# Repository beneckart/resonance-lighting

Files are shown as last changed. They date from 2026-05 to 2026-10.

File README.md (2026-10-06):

# Resonance Lighting

Power and lighting workstream for the **Resonance Tree** -- a bamboo art installation for Burning Man 2026 + 2027. This repo covers the roughly 130 solar/battery-powered, mesh-networked lighting fixtures in and around the tree -- four classes: hanging downlights, perimeter lights, trunk lights, and the central chandelier (canonical counts: the fleet table in `docs/block-diagram/SYSTEM.md`; current allocation: ADR 0032).

Sister tracks (not in this repo): bamboo structure (Bamboo Pure, Bali), structural engineering (Ed), parametric lighting design (Vishnu), project management (Elliot + Co-Work agent).

## Post-event storage and 2027 planning

Start with the [2026 postmortem and future-work index](docs/postmortem/README.md)
for the container-storage outcome, Oakland inventory, PROTECT investigation and
2027 hardware/tooling brainstorming. The
[storage and wake guide](docs/howto/FIXTURE_STORAGE_AND_WAKE.md) documents the
implemented USB/solar-wake ship mode, RESET-wake sleep, date picker and exact
retained firmware. These records supersede pre-event status where noted; the
2027 concepts remain discussion drafts.

## Who's working here

- **Ben Eckart** -- power systems, firmware, mesh networking. Owns `/firmware/` and `/hardware/`.
- **Steve Eckart** -- enclosure design, 3D printing, mechanical fit. Owns `/enclosure/`.

Both work with AI pair-programmers. Coordinate via `LOG.md`, `TODO.md`, and ADRs.
Firmware builders additionally use
[`docs/howto/FIRMWARE_ARTIFACT_HANDOFF.md`](docs/howto/FIRMWARE_ARTIFACT_HANDOFF.md)
so separate benches do not reuse revisions or silently flash each other's targets.

## What is the deliverable

Nominally 130 modular lighting fixtures in four classes -- 72 hanging downlights
in three rings of 24, 24 all-HEX perimeter lights on shepherd hooks, about 16 trunk
lights trending RGBW, and 18 mixed HEX/RGBW chandelier lights. The team intends to
build this full layout; fewer fixtures are a contingency for an unforeseen issue.
The archetype (hanging downlight) is:

- A bamboo lantern body, fabricated by Bamboo Pure in Bali.
- A solar "hat" enclosure that sits partially inside, partially over the bamboo top.
- A solar panel, rechargeable battery, controller board, LED module, sensors
  (accelerometer + downward ToF), and a 3D-printed patterned aperture / gobo.
- Firmware that supports autonomous ambient lighting, ESP-NOW state exchange, standard OTA maintenance updates, telemetry, and graceful low-power behavior.

The other classes are variants on the same electronics: perimeter lights use HEX and
face the ToF outward; trunk lights drop the gobo and are moving toward all RGBW while
a smaller lensed 3 W RGB module is tested for extra throw; chandelier lights live in
a carpenter-built box, likely on 6 Ah cells with USB-C top-ups. All share one firmware
image.

Steve's NeoHex Magic Wand is a separate one-off fleet peer, not a fifth
production class. Its PowerFeather identity is permanently `F40344` /
`68:EE:8F:F4:03:44`, its registry role is `magic_wand`, and batch OTA tooling
requires a dedicated single-target acknowledgement before it will touch that
MAC (ADR 0050). See `docs/projects/NeoHex-Magic-Wand/README.md`.

## Current architecture direction

**PowerFeather V2 (ESP32-S3) is the confirmed reference** for the controller / solar-and-battery manager / telemetry, after 5-board feasibility testing (ADR 0021): ESP-NOW mesh at scale, battery-only no-touch OTA + A/B rollback, and the solar charge path are all validated on hardware. Chemistry is **LiFePO4** (ADR 0002); batteries are two-tier since 2026-07-24 (ADR 0025): 33140 15 Ah in the large hats (downlights; qualification pending) and the fullbattery 32700 6 Ah, qualified n=2, in the small hats.

**The production path is decided: COTS PowerFeather V2, with a nominal 130-fixture
deployment (ADRs 0024 and 0032).**
158 boards are bought (68 received + 90 ordered 2026-07-09; ledger: `ops/PROCUREMENT.md`).
The custom PowerFeather-derived PCBA (ESP32-S3-WROOM module, BQ25628E-class charger,
MAX17260-class gauge, buck-boost 3.3 V rail, switchable rails, keyed connectors) is
the 2027 option, carrying the ADR 0028 bus-integrity rules.

The **LED axis is a mixed fleet by optical role** (ADR 0022): SK6812 "HEX"
direct-GPIO for close-range animation / ambient glow, and a 4 W RGBW point source for
long-throw crisp gobo projection. Both are driven **direct-GPIO off a free pin**, both
fed from the switchable 3V3 rail -- decided by instrumented A/B through
production-realistic cabling (ADR 0029 + 2026-07-11 amendment); the 4.2 V boost is
measured and shelved. The type mix by class is in the
SYSTEM.md fleet table (tentative until installation). The earlier Adafruit
IS31FL3741 13x9 STEMMA-QT matrix was **ruled out** (ADR 0018) -- it browns out the
board on battery under WiFi (shared charger/gauge I2C bus). The earlier COTS bake-off
candidates (FeatherS2 Neo, Atom Matrix, NeoHEX, DFR0559) served their purpose;
PowerFeather V2 won.

**Sensors and class identity** (ADRs 0027, 0034, 0041, 0067): every downlight
carries an MSA311 accelerometer + downward TMF8820-mini multizone ToF; perimeter
lights carry an outward VL53L5CX; trunk/uplights normally carry only MSA311;
chandelier lights carry no class sensors. Auto-classification is ordered ToF then
MSA311 at `0x62`, with a sensorless uplight fallback for the already-installed
2026 fleet. Remembered downlight/perimeter classes survive a missing ToF. Future
chandelier PowerFeathers are rostered by exact MAC and persist `class_ovr=4`
before installation. BMP581 is non-classifying environmental telemetry on the
outer 24 downlights. Fused IMUs were rejected (per-device calibration does not
scale to the fleet). The **noisemaker**
is decided (ADR 0030/0071): a solenoid mallet physically strikes an installed
finger cymbal on each canopy bamboo assembly -- daytime
solar-surplus percussion; the speaker-synth path was abandoned once the strikes
proved out.

**Production show timing is scheduled** (ADR 0031): four purchased SAM-M8Q modules
are the initial GPS/GNSS soft anchors for absolute UTC, and four purchased Adafruit
DS3231 modules are the initial battery-backed RTC holdover anchors. ESP-NOW distributes
time quality to the rest of the fleet, so all roughly 130 fixtures do not need RTCs.
Panel/lux dusk inference remains useful bench telemetry but is not the production show
clock.

**Performance audio has a dedicated optional publisher** (ADR 0035): a received
PUCA DSP Original Edition in its Eurorack expansion, paired with a RODE VideoMic
NTG, will analyze one clean audio source and publish directed show frames over
ESP-NOW. The already-proven CoreS3 + Module Audio path remains the independent
fallback. PUCA hardware is on hand; its development firmware now passes the
powered-Pod20 codec/stereo/control/radio/full-census baseline with locked
standalone HEARTBEAT startup. The performer's exact waveform, visible fixture
fidelity/fallback, and field validation remain pending. See
`hardware/puca-audio-bridge/README.md`.

**The camp network is pinned to the mesh channel** (ADR 0036). The ESP32-S3 has
one 2.4 GHz radio, so WiFi STA and ESP-NOW must share a channel, and in STA mode
the access point picks it. Every bridge so far dodges this by staying
unassociated; any device that wants the mesh and the internet at once cannot.
The camp AP (Starlink in bypass mode -> GL.iNet Beryl AX) therefore serves a
dedicated 2.4 GHz SSID fixed to channel 11, and any device that associates while
using ESP-NOW must verify the channel and drop WiFi rather than lose the mesh.
Router ordered, not yet configured; runbook in `docs/howto/CAMP_NETWORK_SETUP.md`.
Fixture maintenance images may carry two gitignored site credential profiles
and select the strongest visible known AP (ADR 0066). Ordinary fixture COMMS
never associates with either network, and no credential value enters git.
The first simultaneous mesh-plus-internet consumer is now **Resonance Bridge OS**
on the LilyGO T-Deck Plus. Hardware is on hand and M0-M4 plus the first M5 apps
are implemented and hardware-verified (ADRs 0047 and 0048). The channel guard
and WiFi/mesh coexistence passed on the house channel-11 network; Beryl field
configuration and validation remain open. The current app order is in
`firmware/tdeck_bridge/APP_ROADMAP.md`; CA Studio remains Greenberg-Hastings,
while the separate Contagion app owns Color Virus and Epidemic (ADR 0055).

The old custom-board target of ESP32-C3-MINI-1 + CN3058 + AP2112K + direct-from-battery WS2812B has been superseded by later ADRs.

## Goals

- **Fungible:** any unit replaces any other with no per-device configuration.
- **Fully wireless:** no data lines, no power lines, no fixed topology. ESP-NOW is for lightweight state/control packets, not firmware-image transfer.
- **Standard OTA only:** OTA updates use normal ESP32 OTA mechanisms in a deliberate maintenance mode. No custom mesh-gossiped firmware images.
- **Durable infrastructure:** fixtures are reused in 2026 and 2027.
- **Low per-fixture operations:** no skilled repetitive work at fleet scale. Small, deliberate soldering such as a solar pigtail can be acceptable; hand-soldering rows of headers or hand-crimping harnesses is not.
- **Telemetry:** power, solar, battery, temperature, and failure data should inform BM 2027 design decisions.
- **Beautiful:** default center-source gobo projection plus optional multi-LED chromatic/animation modes.

## Repo layout

```
.
|-- README.md
|-- LOG.md
|-- TODO.md
|-- BACKGROUND.md
|-- ROADMAP.md
|-- AGENTS.md
|-- hardware/
|   |-- atopile/
|   |-- led-adapter/       NeoHEX passive adapter Rev A (KiCad + PCBWay packet)
|   |-- puca-audio-bridge/ Received performance-audio source + bring-up record
|   `-- references/
|-- enclosure/             README only so far; CAD lives with Steve
|-- firmware/
|   |-- ARCHITECTURE.md    target production architecture
|   |-- README.md          index of the working bench sketches
|   |-- POWERFEATHER_NOTES.md
|   |-- powerfeather_solar_guard.h
|   `-- <app>/             bench sketches (net_bench, power_bench, led_studio, ...)
|-- docs/
|   |-- block-diagram/     SYSTEM.md -- canonical architecture + fleet table
|   |-- decisions/         ADRs 0001-0040
|   |-- howto/             task-oriented bench and operations guides
|   |-- research/
|   `-- tests/
`-- ops/
    |-- bom.md             fleet BOM + spares math
    |-- PROCUREMENT.md     orders ledger + timeline
    `-- bench/             bench tooling + JSONL data
```

## Read order for agents and humans

1. `README.md`
2. `LOG.md`
3. `TODO.md`
4. `BACKGROUND.md`
5. `docs/decisions/` -- especially ADRs 0010 onward
6. `docs/research/COTS_SURVEY_2026-05-10.md`
7. `docs/research/POWERFEATHER_V1_V2_SCHEMATIC_NOTES_2026-05-10.md`
8. `docs/tests/COTS_BENCH_TEST_PLAN_2026-05-10.md`

## How-to guides

- [`docs/howto/BRIDGE_OS_FIELD_MANUAL.md`](docs/howto/BRIDGE_OS_FIELD_MANUAL.md) --
  friendly illustrated field/IT manual for T-Deck Bridge OS, the CoreS3
  dashboard and audio modes, and the still-pending PUCA performance bridge.
- [`docs/howto/FIRMWARE_ARTIFACT_HANDOFF.md`](docs/howto/FIRMWARE_ARTIFACT_HANDOFF.md) --
  collision-proof firmware revision/manifest rules, explicit target handoff,
  fresh-evidence OTA completion, and USB boot-salute semantics for shared benches.
- [`docs/howto/CORES3_AUDIO_REACTIVE.md`](docs/howto/CORES3_AUDIO_REACTIVE.md) --
  connect and tune the Rode VideoMic NTG, read the CoreS3 envelope/FFT
  spectrogram and band modes, run the sound-reactive bench, and troubleshoot the
  safe fallback path.
- [`docs/howto/CAMP_NETWORK_SETUP.md`](docs/howto/CAMP_NETWORK_SETUP.md) --
  stand up Starlink + the Beryl AX travel router with the 2.4 GHz radio pinned to
  channel 11 so infrastructure WiFi and the ESP-NOW fleet can coexist on one
  radio. Home rehearsal, field checklist, and troubleshooting (ADR 0036).
## Fleet dashboard

CoreS3 Bridge OS now has a standalone touch Listener with a paged fleet-health
grid and fixture detail, so basic observation no longer needs a laptop. For the
complete host dashboard and telemetry logger, attach the same CoreS3 over USB.
The only Python dependency is `pyserial`; list the attached ports, then replace
`COM40` with the observed bridge port:

```sh
python -m pip install pyserial
python -m serial.tools.list_ports
python ops/bench/net_bench_dashboard.py --port COM40
```

The landing view is a compact grid of every ESP-NOW light. Battery fill and color,
charger-input activity, class-inferred source glyph, panel-suspect state, adaptive heartbeat freshness, and the
actual reported light output are readable without opening a table. The top bar is
the rendered LED color, independent from battery status. Callsigns from
`ops/fleet/callsigns.csv` lead in selected/detail and peer-list surfaces while
the exact short MAC remains visible and authoritative for state-changing work.
Reported fixture class
(normally from the Stemma probe, with an override available) sets the battery
glyph shape: circle for canopy/downlight, hexagon for
perimeter, triangle for trunk/uplight, and diamond for chandelier. Dense overview
tiles still use two MAC digits unless a collision needs `-1`, `-2`, and so on;
full callsigns would crowd that view. Select any light for exact
values; bench controls and the full historical telemetry console are preserved in
the collapsed `Detailed diagnostics` section. With `All` selected, `Strike all`
queues one addressed D7 pulse per fresh fixture after confirmation; disarmed boards
ignore it and the fixture's local power/mechanism gates remain authoritative. See
[`firmware/cores3_bridge/README.md`](firmware/cores3_bridge/README.md) for the
glyph contract and source-classification caveat.

Resonance Bridge OS embeds the same table in its Fleet and Health apps. Its
Claude tool surface accepts a callsign or six-hex short ID, resolves locally to
the MAC-derived target, and returns both in tool results. Fixture firmware and
the ESP-NOW packet contract do not carry callsigns.

For an explicit multi-fixture OTA, `ops/bench/fleet_dashboard_ota.py` accepts a
comma-separated short-MAC target list plus one already-built immutable binary.
It loads a job-scoped T-Deck roster, spans one selected sleep cadence, discovers
and identity-checks maintenance endpoints, positively freezes all gather traffic,
uploads in bounded parallel jobs, and requires fresh exact-revision evidence
beyond the A/B pending-verify gate. One exclusive-created ledger records every
target as verified, deferred, or failed. `--allow-partial-discovery` permits a
named sleeper cohort to proceed without missing targets; it never permits unnamed
discovery results or unsafe low-VBAT targets. See ADR 0062 and
`docs/howto/FLEET_OTA_10_MINUTE_RUNBOOK.md`.

## Status

As of 2026-08-06: **production is locked on COTS PowerFeather V2 with a current
130-fixture Nevada City layout in four classes (ADRs 0024 and 0032), and the buy is
essentially complete** -- boards, two battery
tiers, panels, LEDs, sensors, cabling, USB-C rescue ports, solarnoid hardware, and 172
Polycase enclosures are ordered or received (about $25.2k committed; ledger in
`ops/PROCUREMENT.md`). The qualified 32700 6 Ah cell remains the small-hat/chandelier
battery while 130 newly bought 33140 15 Ah cells are pending qualification for large
hats (ADR 0025). Panels are selected and outdoor-measured (ADR 0026); sensors are
allocated by class (ADR 0027); both LED roles are on the switchable 3V3 rail after
instrumented A/B (ADR 0029); the solarnoid is the selected noisemaker for large-hat
downlights (ADR 0030); and deterministic scheduled shows from sparse GPS/RTC anchors
are the production timing direction (ADR 0031).

Remaining gates during Nevada City assembly: the bottom-up nightly energy budget by
role, 33140 qualification and thresholds, trunk-light LED/power/mounting integration
(including the lensed 3 W RGB trial), hat thermal/RF proof on the Polycase boxes, the ADR 0023 state
machine in production firmware, solarnoid part/mounting details, and qualification of
the four SAM-M8Q GPS plus four DS3231 RTC timing anchors including invalid-time
behavior. Treat LFP SOC as advisory until the gauge learns; use coulomb counting and
voltage/current guardrails. See `LOG.md` and `TODO.md` for the live state.

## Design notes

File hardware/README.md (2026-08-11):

# Hardware

Electronics for the Resonance Lighting downlight fixture. Current strategy is
**PowerFeather V2 first, COTS deployable, custom-PCBA optional**, not custom-PCBA-only.

## Current Hardware Tracks

### Track A - COTS Production / Fallback

Use off-the-shelf boards, factory-soldered connector options, pre-crimped cables, screws,
standoffs, and adapter boards to validate and possibly deploy the system without waiting
on a custom PCB.

Current leading stack:

```
Solar panel -> PowerFeather V2 VDC
LiFePO4 cell -> PowerFeather battery JST
PowerFeather GPIO10/A0 -> direct-GPIO LED module
PowerFeather switchable rail / adapter -> LED power
```

Live LED modules, per ADR 0022:

- **SK6812 HEX array:** close-range animation / ambient glow role.
- **4 W RGBW point source:** long-throw crisp gobo role.

Ruled out for the V2 battery build:

- **Adafruit IS31FL3741 13x9 matrix on STEMMA-QT:** shared-bus brownout under WiFi
  (ADR 0018). Keep it only as historical bench context unless a future isolated-bus
  experiment explicitly revives it.

Small adapter-board workstream:

```
PowerFeather GPIO + switchable/boosted LED rail
        |
        v
NeoHEX passive / future boosted adapter PCB
        |
        v
HEX / NeoHEX / RGBW LED module connector
```

See `hardware/led-adapter/neohex-passive-rev-a/`.

### Track B - Custom PCBA / Assembly Optimization

If COTS supply, connector labor, cost, or packaging does not pencil out at 100+ units,
derive a custom board or custom assembly from the validated PowerFeather V2 architecture.

Current reference architecture:

```
[Solar panel / VDC connector]
        |
[Input protection + bright-sun qualification guard]
        |
[BQ25628E-class charger + power path]
        |
[LiFePO4 cell + thermistor]
        |
[MAX17260-class fuel gauge / current sense]
        |
[TPS631013-class 3.3 V buck-boost]
        |
[ESP32-S3-WROOM-class module, PCB antenna]
        |
[Switchable/default-off LED rail]
        |
[Direct-GPIO LED module connector(s)]
```

## Superseded Earlier Target

The older target architecture was:

```
CN3058 charger -> AP2112K LDO -> ESP32-C3-MINI-1 -> WS2812B direct from Vbat
```

That approach is superseded by later ADRs and the PowerFeather V2 findings. CN3058 remains
historical/fallback context only; it is not the leading production direction.

## Why PowerFeather V2 Matters

PowerFeather V2 combines several features the project otherwise would have to design and
validate separately:

- ESP32-S3-WROOM-1 module with onboard PCB antenna.
- BQ25628E charger/power-path with LiFePO4 support.
- MAX17260 fuel gauge with LiFePO4 profile support and current sensing.
- TPS631013 buck-boost 3.3 V regulator.
- Switchable `3V3` header rail and `VSQT` rail.
- Solar/DC input.
- Power telemetry useful for BM 2026 -> BM 2027 learning.

ADR 0021 validates the risky axes: ESP-NOW scale/range, battery-only OTA + rollback, and
the solar charge path. The remaining hardware work is sizing, productionization, thermal,
RF-in-hat, and connector/assembly choices.

## Interfaces

### Direct-GPIO LED

- Current production-facing LED interface.
- Bench default: GPIO10 / A0.
- Requires a switchable/default-off LED rail and local decoupling.
- Supports HEX and RGBW point-source roles with one firmware abstraction.

### STEMMA-QT / Qwiic

- 4-pin JST-SH connector carrying I2C: GND, V+, SDA, SCL.
- Useful for env sensors, ToF, IMU, INA monitors, and other low-power peripherals.
- Do not put the IS31FL3741 matrix back on the PowerFeather V2 shared charger/gauge bus.

### Grove / HY2.0

- Physical connector used by M5Stack modules.
- Can carry I2C, UART, GPIO, analog, or custom signals depending on the device.
- M5Stack NeoHEX uses HY2.0 physically but is a WS2812/GPIO LED device, not I2C.

### USB / Pogo Recovery

USB-C is available on COTS PowerFeather. Any custom board or assembly must preserve a
boring wired recovery path via USB or pogo pads even though OTA is validated.

## Custom PCB Constraints

If a custom board proceeds (2027 option -- ADR 0024):

- Use a pre-certified WROOM-class module with onboard PCB antenna by default.
- Do not use u.FL/external antenna unless final hat RF testing fails.
- **Dedicated power-management I2C bus** for charger + gauge only, run at 100 kHz;
  user peripherals on a separate bus. No power-management I2C from core-0-pinned
  tasks under WiFi. This rule closed the two-month reboot epidemic (ADR 0028).
- **Any VBAT-fed LED branch taps downstream of the gauge current-sense shunt**, with
  fat conductors and a default-off kill (the 3V3-rail shutoff no longer covers it);
  HEX rides the switchable 3V3 rail; the RGBW feed decision (rail vs VBAT) is open
  in ADR 0029.
- Include USB/pogo flashing/recovery pads regardless of factory flashing.
- Use a switchable/default-off LED/module rail.
- Include charger/fuel-gauge telemetry.
- Include battery thermistor or another explicit temperature strategy.
- Add keyed solar and battery connectors or production-safe pigtails.
- Avoid direct unstrained panel wires soldered to production board pads.
- Keep LED module/daughterboard separate until optics and placement are frozen.
- Use 4-layer PCB and external schematic/layout review for switching charger,
  buck-boost, current sensing, and RF keep-out.

## Immediate Hardware Tests

Top priorities (updated 2026-08-06):

- [x] Voltaic P105/P126 harvest tests with the OVP/HIZ guard (2026-06-29, ADR 0026;
  hungrier-cell P105 re-run still queued).
- [x] HEX 4.2 V boost test -- concluded SKIP; the production-cabling A/B selected
  the switchable 3V3 rail for RGBW (ADR 0029 amendment).
- Close bottom-up power budget by LED role.
- Compare the 4 W RGBW and lensed 3 W RGB trunk-light variants, then lock the
  about-16-fixture power, optic, and mounting path (ADR 0032).
- RF test inside a mock hat with panel/battery/wiring installed.
- Thermal test sealed hat in sun/heat with charger and LEDs operating.
- Time-trial a production-like COTS assembly with keyed connectors and strain relief.
- Integrate the already-selected USB-C panel-mount port + gasket for every class,
  plus the ToF aperture (downward on downlights, outward window on perimeter hats).

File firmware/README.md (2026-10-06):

# Firmware

ESP32 firmware for the Resonance fixtures and controllers. The deployed peer
firmware is [fixture](fixture/README.md); [tdeck_bridge](tdeck_bridge/README.md)
is the handheld controller. `net_bench` remains a bench/bridge tool. The older
layered target in `ARCHITECTURE.md` is historical context; see the fixture
README for the implemented architecture.

The [storage and wake guide](../docs/howto/FIXTURE_STORAGE_AND_WAKE.md) documents
the September 12 USB/solar-wake storage firmware, exact retained fixture and
T-Deck artifacts, rollout evidence and remaining qualification. Post-event
analysis and 2027 ideas are indexed [here](../docs/postmortem/README.md).

> **Building a new app on the PowerFeather V2 bench boards?** Read
> [`POWERFEATHER_NOTES.md`](POWERFEATHER_NOTES.md) first -- the switchable 3V3 rail
> (GPIO4), the V2 SDK board flag, native-USB reset/IP recovery, and other gotchas
> that have each cost real bench time. Working sketches: `power_bench/`,
> `led_studio/` (merged HEX + RGBW + RGB aesthetic tool),
> `net_bench/` (ESP-NOW networking feasibility bench), `smoke_test/`,
> `cores3_bridge/` (dedicated M5Stack CoreS3 fleet bridge),
> `atom_clicker/` (one-target reduced-access proof), `atom_conductor/` (Ben-only
> bounded Wake/gather plus centrally replayed canopy waves),
> `magic_wand_conductor/` (Steve's two-sensor lift-controlled fleet conductor),
> `powerfeather_demo_port/`, `presence_bench/` (I2C multi-sensor bench),
> `sway_demo/` (MSA311 tilt/sway -> RGBW color, with a web verifier),
> `speaker_demo/` (STEMMA speaker #3885 percussion synth, noisemaker candidate A).

Solar/charging baseline: any Resonance sketch that enables PowerFeather charging must
use `powerfeather_solar_guard.h` to force the BQ25628E wide input-OVP bit and to kick
input re-qualification if the panel is present but the charger is latched not-good.

Performance-audio note: the received PUCA DSP/Eurorack hardware is documented in
`../hardware/puca-audio-bridge/README.md` and selected by ADR 0035.
`puca_bridge/` now contains a native-tested development target whose powered-
Pod20 codec/stereo/control/radio/full-census baseline has run on the received
hardware. Exact waveform/light fidelity, receiver fallback, and field geometry
remain acceptance-gated. The proven CoreS3 audio-reactive implementation is
still the field fallback, not a PUCA-compatible binary.

## Planned production structure (NOT yet built -- see ARCHITECTURE.md)

```
firmware/
|-- core/             Platform-independent C++. Compiles native, has unit tests.
|   |-- ca/           Cellular automata engine.
|   |-- packet/       Mesh packet codec.
|   |-- pattern/      LED animation generators (port of TalismanPatterns).
|   `-- state/        Per-fixture state representation.
|
|-- esp32/            ESP32-specific glue. Builds against ESP-IDF or Arduino-ESP32.
|   |-- tasks/        FreeRTOS task definitions.
|   |-- drivers/      NeoPixelBus, ESP-NOW, charger/gauge, rail control.
|   `-- boards/       Pin mappings per board (powerfeather_v2, resonance_custom).
|
`-- tests/            Native unit tests. Run on host, not target.
```

## Architecture (intent -- see `BACKGROUND.md` for full reasoning)

FreeRTOS tasks, not bag-of-timers in `loop()`:

- **`led_render_task`** -- 60 Hz, high priority. Renders local state to NeoPixelBus.
- **`ca_tick_task`** -- 10 Hz. Reads neighbor states from queue, computes next local state, publishes to mesh.
- **`mesh_rx`** -- ESP-NOW callback enqueues packets.
- **`mesh_tx_task`** -- periodic state broadcasts and wand-presence handling.
- **`housekeeping_task`** -- battery check, OTA poll, sleep manager. Low priority.

## Reusable from `beneckart/future-robotics`

- `Talisman/arduino-sketches/talisman_v2rev2/TalismanPatterns.cpp` -- templated NeoPixelBus animation engine. Drop into `core/pattern/`.
- The 11-byte structured-payload packet pattern from `sendPkt()`. ESP-NOW handles framing so we drop the sentinels.
- Marquee Python OPC clients -- useful as host-side test harness once we want to stream test patterns to a single bench fixture.
- Marquee C++ effect engine (`particle_trail.cpp`, `rings.cpp`, etc.) -- reference for spatial-aware effects.

## Validated on hardware (superseding the old TTGO bench plan)

The COTS campaign ran on PowerFeather V2, not the TTGO modules. Record of record:

1. Solar charge path end-to-end incl. the bright-sun OVP/HIZ guard (ADR 0021/0026;
   `powerfeather_solar_guard.h`).
2. Direct-GPIO LED drive measured per role; boost shelved (ADR 0029; `led_studio`).
3. ESP-NOW at 5 nodes with a 100-node projection, range through house+yard+oak
   (ADR 0021; `net_bench`).
4. Battery-only standard OTA + A/B rollback + watchdog recovery; low-VBAT OTA
   brackets (ADR 0021; `net_bench`, `docs/tests/OTA_FLASH_BENCHMARKS_2026-05-15.md`).
5. Low-battery day/night lifecycle (field-cycle) with measured thresholds
   (ADR 0023); bus-integrity rules (ADR 0028; `POWERFEATHER_NOTES.md`).
6. Sensor chain: MSA311 + multizone ToF fusion on real geometry (ADR 0027;
   `sway_demo`, `presence_bench`).

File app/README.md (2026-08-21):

# Resonance Tree — Mirror Twin (`app/`) · v1.0 “Emergence”

A real-time, hardware-true 3D **digital twin + control/show system** for the Resonance
Tree: the actual bamboo tree rendered with its lanterns glowing, driven by music, playable
by a DJ/VJ, scriptable by an LLM, and ready to bridge to Ben's solar-mesh fixtures.
Built offline-first (PWA), control-plane only (params, never pixels).

## Run (fresh clone → live twin in ~2 min)
```bash
git clone --branch Lighting-Controller https://github.com/beneckart/resonance-lighting.git
cd resonance-lighting/app
npm ci             # Node 18+ required
npm run dev        # http://localhost:5173 (+ a Network URL for other devices)
```
Everything needed is in the repo — the 3-D tree geometry (`tree-context.glb`), the real
lantern + chandelier bodies, `fixtures.json` (118 fixtures from the Blender export),
gobos, photometry (`downlight.ies`), MIDI scores and test audio — so a clone runs the
exact same system and controls — including the sampled grand piano, whose soundfont is
vendored in the repo (`public/soundfont/`), so it all runs fully offline. One footnote:
layouts/cues/themes persist per-browser (localStorage), so each operator starts from
clean defaults. Other scripts: `npm run build` · `npm test`
(Vitest) · `npm run e2e` (Playwright) · `npm run check` (build + test + e2e).

## The four operator modes (pick first, top of the panel)
- 🌱 **Interactive** — the tree is reactive; you only set the rules. Tap the tree =
  a presence sensor fires; the Game of Life trickles the disturbance outward.
  Rules editor (colour/brightness/time-on/spread + never-same-as-last, ranges),
  colour THEMES (⚡ Energize · 🕯 Intimate · 💗 Love · 🌊 Ocean …), and the
  Game-of-Light lifecycle: arm → first-visitor ignition → visitors drop living
  nodes by quadrant → a chain all the way around = 🌈 Unity (organic only).
- 🎬 **Light Show** — scope first (whole tree · custom groups · single lights),
  sliders + patterns, three authored shows, the piano playing real scores.
  Groups can each run their OWN mode simultaneously (canopy interactive while
  the chandelier follows sound) — pick a group chip, assign it a mode.
- 🎵 **Sound** — beat-tracked audio engine, DJ decks (only visible here), AI-VJ.
- 🔧 **Calibrate** — commissioning (MAC↔slot) + AUTO-CALIBRATION: all lights off,
  each light solo-steps group-by-group with confirm-or-timeout against its own
  reported heartbeat (catches dead/wrong fixtures), ToF self-location histogram,
  JSON report = the photogrammetry frame-sync log.

## Play with it from another computer / iPad (LAN — no deploy)
The dev server listens on the whole network (`server.host: true`). From the machine
running it, find its address, then open that from any device on the same WiFi:
```bash
npm run dev              # prints  ➜ Network: http://192.168.x.x:5173
```
Open `http://<that-ip>:5173` on Ben's laptop / an iPad. Full-screen on iPad: share →
"Add to Home Screen" (it's a PWA; it launches chromeless and keeps working offline).

### 60-second tour (for Ben)
- **Tap the tree** (in 🌱 Interactivity with a CA rule active) — fires a simulated
  presence sensor at the nearest downlight; the disturbance propagates via each
  fixture's pre-baked k-nearest-neighbour list (your flash neighbour table).
- **🎇 Game of Light**: `Arm` → tap → ignition (off → flourish → off) → live: dark at
  rest, each visitor-tap drops a persistent node in its quadrant colour. Ring the
  whole tree with outer nodes → 🌈 Unity (rainbow + fanfare). Rules editor sets what
  a sensor firing does (colour/brightness/time-on/spread).
- **🎬 Light Shows**: three authored ~5-min timed shows + the piano (real scores).
- **🎛 Controls**: patterns, sequencer, colour, speed; **DJ** panel: crossfade/EQ/strobe;
  **AI-VJ**: audio-reactive auto-looks (mic or built-in track).
- Everything renders the fixtures' *reported* state — the mirror-twin contract; the
  ESP-NOW seam is `protocol.ts` (control params only, never pixels).

## What it is
- **Real tree**: loads `public/fixtures.json` (78 real canopy lights exported from the
  Blender model) + `public/tree-context.glb` (decimated bamboo) — renders as the tree.
- **Mirror / truth loop**: the render shows each fixture's *reported* state (a mock
  heartbeat transport stands in for ESP-NOW; swap it later, nothing else changes).
- **Visuals**: bloom + HDR-gain lanterns, volumetric beams (per fixture, beam-angle
  sized), gobo mandala projected on the ground, ACES tonemapping, hero camera, 3
  visualizers (lanterns / orbs / wire).
- **Patterns**: solid · breathe · chase · ripple · sparkle · sequence (7 modes) ·
  spectrum · tricolor, + element modes (wind / ember / rain / beacon).
- **Audio (the spine)**: mic / song / built-in test track → FFT, spectral-flux onset,
  interval BPM, asymmetric envelope followers, AGC, drop detection. BPM→sequencer tempo,
  onset→flash, drop→burst. (BeatTracker unit-tested at 124 & 90 BPM.)
- **DJ**: crossfader (A↔B look blend), 3-band EQ→tree-zone, master intensity, strobe.
- **Auto-VJ**: shuffle-bag look switching on the phrase. **Cues**: save/recall/delete looks.
- **Command console / LLM surface**: type or paste a command script (one per line). See
  `../docs/research/13-LLM-CONTROL-GRAMMAR.md` for the grammar.
- **Control plane**: ESP-NOW channel + Protocol-v1 param encoder (`protocol.ts`) — the
  seam to the real mesh (control params, not pixels).

## Command grammar (quick ref)
```
pattern <id> | hue 0.5 | bri 0.8 | speed 1.5
<target> color <#hex|name> | <target> on | <target> off
  target = all | zone low|mid|high | range a-b | every n | fixture <id|seq>
on | off | clear
```

## Expand it — where things live
The codebase is deliberately hackable; each concept is one file:
- **Add a pattern**: `src/patterns.ts` — add a `case` to `litFor` (per-fixture, pure:
  position/time in → RGB out) + register the id in `src/store.ts` `PATTERN_IDS`.
- **Add a CA rule**: `src/field.ts` — the decentralised engines (Game of Life,
  excitable media, reaction-diffusion, firefly sync) evolve per-fixture state over
  each light's `neighbors` list; export an `updateX()` + output buffer, tick it in
  `src/TreeLights.tsx`, add the id to `CA_RULES`.
- **Add a colour theme**: `src/themes.ts` — one object: hue anchors + saturation.
- **Add a light show**: `src/shows.ts` — timed cues driving base + group layers.
- **Trigger rules** (what a touch does): `src/store.ts` `TriggerRule`/`triggerAt`.
- **The mesh seam**: `src/protocol.ts` — Protocol-v1 param encoder (control-plane
  only, never pixels); `src/calibration.ts` + `src/autocal.ts` — commissioning &
  the auto-calibration sweep. Sensors story: `docs/research/` + Ben's
  `PRESENCE_SENSING_INTERACTIVITY_2026-06-12.md`.
- **Tests**: `src/*.test.ts` (Vitest) — `npm test`; the Game-of-Life invariants
  live in `src/field.test.ts`.

## Re-export the model (optional)
`scripts/blender/export_tree.py` (fixtures) + `export_context.py` (geometry) run via
headless Blender against the source `.blend`. Commit only the small `.glb` + `fixtures.json`.

## Stack
Vite · React 18 · TypeScript · React Three Fiber + drei · @react-three/postprocessing ·
zustand · Web Audio · vite-plugin-pwa. Tests: Vitest + Playwright.

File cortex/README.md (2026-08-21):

# cortex/ — Jetson hub services

Python services on the Jetson Orin Nano (trunk base): twin-server, occupancy, env, voice,
camp bridge, db (SQLite + sqlite-vec). The **PowerFeather master is the ESP-NOW radio-modem**
over framed USB serial — the cortex has no ESP-NOW radio of its own.

**Principle:** the mesh is a self-sufficient brainstem; the cortex wakes at dusk and dies
invisibly. Day / cortex-dead = master SoftAP + lite page.

**Status:** scaffold placeholder. See `../docs/research/PRD-lighting-environment.md` §4–6 and
`../docs/research/01-MASTER-DESIGN-REPORT-v1.0.md` PART 5 (Central Brain).

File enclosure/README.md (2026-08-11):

# Enclosure

Solar "hat" enclosure for the Resonance fixtures. Steve's workstream.

**STRATEGY UPDATE 2026-07-13: the enclosure bodies are BOUGHT, not printed.**
172x COTS sealed enclosures + screws ordered ~07-12/13 ($5,306.50 total; vendor/
part details TBC in `ops/PROCUREMENT.md`), split 22 to TN / 150 to CA:

- **LARGE (111):** 72 hanging downlight hats, leaving 39 units of gross inventory
  headroom (including the transparent-lid demo unit).
- **SMALL (61):** 24 perimeter-light hats plus candidate enclosures for about 16
  trunk lights. Final trunk mounting and power geometry are being settled during
  Nevada City integration.
- **Chandelier:** no hat -- a team carpenter builds a box housing the 18 lights
  (coordinate venting, access, and USB-charging reach).

Steve's workstream shifts from print-the-hat to **integrate-the-hat**: panel
mounting, bamboo clamp/set-screw attachment, gasketed USB-C rescue-port cutout
(all variants), ToF windows (downward on downlights, outward + cover on
perimeter), LED/gobo positioning, strain relief, and thermal/RF proof on the
real boxes. 3D printing remains for the gobo/filter program and custom internal
fittings. The original printed-hat architecture below is kept for reference --
its constraints (antenna keep-out, set-screw clamping, panel-over-bamboo
geometry) still apply to the bought boxes.

## Architecture

A sealed cap that mounts on top of the bamboo lantern:

- **Outer disc / ring** -- overhangs the bamboo top to host the solar panel (panel needs more area than the 76 mm bamboo cylinder affords).
- **Inner cylinder** -- extends down into the bamboo neck (~5.5 cm interior diameter, per Bamboo Pure spec). This is the "stem" of the mushroom.
- **Set screws** -- through the inner cylinder, clamping outward against the bamboo wall to absorb dimensional variability of natural bamboo lanterns. Plan: 3 set screws at 120 deg .
- **Internal cavity** -- houses the carrier PCB, LiFePO4 cell, and downward-facing LEDs. Sealed for dust ingress.
- **Hanging point** -- TBD whether on the hat (preferred) or on the bamboo. See `BACKGROUND.md` for the trade-off discussion.

## Print pipeline

(2026-07-13: the hat BODIES are now bought COTS boxes -- this pipeline serves the
gobo/filter program and custom internal fittings, not hat production.)

- **Prototyping:** Bambu Labs printer (Steve's workshop). Iterate fit and look.
- **Batch parts if needed:** MJF nylon at JLC3DP, PCBWay, or Xometry. ~$3-10 per part.

## Filter / gobo (separate consumable component)

A thin 3D-printed disc with patterned cutouts that sits at the bamboo node notch, ~15 cm down from the top. Casts mandala shadows on the ground when the LED above shines through. Friction-fit at the node -- replaceable, swappable per fixture.

A more recent iteration extrudes the 2D pattern into a translucent cone via projective geometry -- looks like a glowing cone-shaped bulb from above, casts undistorted mandala below.

MVP direction (Ben + Steve, 2026-07-08): for time and robustness, production gobos
are likely FLAT DISCS -- the cone extrusion adds print complexity and makes the
"bulb" more brittle, so cones may be reserved for a few designs (or none),
depending on the pattern.

Pattern program update (2026-07-08): community submissions were pulled for time;
the plan is in-house designs plus generative-AI-modulated bamboo-leaf patterns per
bamboo species (see `BACKGROUND.md`).

## Trunk-light variant (supersedes the uplight-boot allocation)

The Nevada City layout now targets about 16 trunk lights with no gobo (ADR 0032).
They are moving toward all 4 W RGBW, while a smaller lensed 3 W RGB module is being
tested for extra throw. Candidate hardware includes the small Polycase, standard
6 Ah cell, gasketed panel-mount USB-C charge/flash port, and available P105 panels,
but the final power arrangement, optic protection, and attachment to the trunk are
open until the comparison is complete. The previous 24-uplight hinged-solar-wing
concept is a superseded July plan, not the production baseline. The 18 chandelier
lights use the carpenter-built box instead.

## Reference

- `references/DOWN LIGHTS DRAWINGS.pdf` -- Vishnu's bamboo lantern shop drawing,
  2026-04-22. (Not committed to the repo yet -- lives with Steve/Drive; TODO to
  commit or re-point.)

## Open mechanical decisions

- Rope attachment point (hat / bamboo / hybrid). See `BACKGROUND.md`.
- Vent gap vs sealed (thermal vs IP rating trade-off).
- Set screw count and placement (currently planned 3 at 120 deg , may revise based on prototype fit).
- Trunk light: attachment to the tree, battery/panel arrangement, USB-C gasketing,
  optic protection, and 4 W RGBW vs lensed 3 W RGB mounting.
- USB-C rescue port is now UNIVERSAL (150 panel-mount extension cables bought
  2026-07-10): every hat variant needs a gasketed panel-mount USB-C cutout wired
  to the PowerFeather -- rescue/charging without opening the enclosure.
- ToF apertures: downward beside the gobo (downlights), outward window with
  protective cover (perimeter).

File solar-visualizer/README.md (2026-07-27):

# Solar Visualizer — Resonance Tree solar-light study (v5, Ben-bench-calibrated)

**v5 (2026-07-17): the model is now calibrated against YOUR bench data, Ben** —
ADR 0026 panel-side INA measurements (P105 "5W" → 3.85 W real full sun, ×0.90
charger, ≈3.2 W battery-side peak) and the July field-cycle ledger (×0.63 daily
input→cell chain). Panel roles per ADR 0026 (P105 on downlights + wings). LED
draw = your measured 1.364 W battery-side full RGBW. **The planning number is
now `wh_day_batt` (Wh into each light's own cell)**: canopy median 10.5 Wh/day
→ ≈7.7 h full-brightness vs the ~10 h dark window (dim profile covers the
night) — which independently agrees with your field-cycle margin conclusion.

Solar access study for the tree's **94 solar-powered lights** — 16 ground/trunk
panels + **78 hanging canopy lights** — measured against the real woven geometry
at Black Rock City, Aug 30 – Sep 8 2026. From Elliot / blender-architect for
lighting + charging design (Ben: built for you to revise your calcs against).

## What's here

| File | What it is |
|---|---|
| `Resonance_Solar_3D.html` | **Open this first.** Self-contained interactive 3D viewer — the tree with all 94 panels colored by live measured output, clock slider (10-min steps) + play, sun riding its path, **"canopy lights" layer toggle**, click any light for its numbers (ring, bearing, hang height, drop, recommended height). Needs internet once (three.js CDN). |
| `solar_phase2_data.json` | The full dataset: per light — position (m, tree-centered, Z-up), aimed unit normal, sky-view factor, 84 × 10-min arrays (real W, no-loss ideal W, % face lit, shading-loss %, orientation-loss %), daily Wh real+ideal. Plus per-slot sun vectors and per-lantern metadata (ring, bearing, drop, 7-ft clearance, recommended hang height). |
| `Resonance_Solar_Access_Study.xlsx` | Same data as a spreadsheet: ground tab, canopy tab (ring/bearing/drop/7ft/rec-height), per-slot output + face-lit + shading-loss + orientation-loss grids, assumptions. |
| `Resonance_Solar_Report_Phase2.pdf` | 2-page written report: method, both phases, hang-height findings + the 7-ft rule, recommendations. |
| `src/` | **The full codebase.** The SketchUp raytracer that measures sun access + the HTML viewer/report that applies the v5 power chain. See `src/README.md` — built so you can re-run the model and revise the constants against your bench. |

## ⚡ Wiring reality (v4): every light is an ISLAND
Each light = its own panel + battery + LED. **Nothing is wired together** — no pooling,
no remote panels. Per-light runtime is the governing metric:
`runtime = daily Wh × 0.85 battery round-trip ÷ draw` (4 W RGBW full / 1 W dim).
Canopy median ≈ **4.3 h of full-brightness light per night** (all night dimmed);
16 lanterns < 3 h; the six inner-south lights get 6–30 min — they must MOVE
(relocating a light relocates its power plant) or stay decorative.

## Power model v3 — physics-only, no generic trim

- **Shading (most conservative):** beam × (fraction of face lit)² × a further **0.75
  series-string mismatch penalty whenever the face is partially shaded**. Full-sun
  faces take no penalty; shaded faces still collect sky diffuse.
- **Heat (calculated per 10-min slot):** cell temp = ambient (17→35 °C daily curve)
  + irradiance self-heating; −0.4 %/°C above 25 °C.
- **Dust:** ×0.95 (occasional wipe-downs).
- Rated 5 W appears only in brief best-case windows (cool, clean, dead-on sun); practical peak **≈4.0 W**.
- `w_ideal` / "ideal" columns = pure clear-sky nameplate math, zero losses (upper bound).
- Not modeled: wiring/charge-controller losses, battery acceptance, shade sails, vehicles.

## Headlines (real Wh/day per 5 W panel)

- **System ≈ 1,733 Wh/day** — canopy 1,424 + ground 309.
- Canopy rings: outer 17.8–25.9 (median 21.5) · middle 13.3–24.8 (median 20.8) ·
  inner 0.4–23.6 (median 13.1).
- Ground: roots 18–27.5 (RT-SSW best), S/SW trunk-ring arc 18–26, N side 9–13.
- **Six inner-south low lights are effectively solar-dead** (CL-I11/12/14/16/17/18,
  0.4–2.5 Wh ⇒ 6–30 min of light) and also hang below the 7-ft head-clearance floor.
  Remote panels are NOT possible (standalone lights) — relocate them or accept them dark.
- 24 lights gain 5–20 % by lengthening cords (per-light rec heights in the sheet),
  min hang = 7 ft to panel bottom.

## Provenance

~500k rays vs the Rhino-derived woven model in SketchUp (`Resonance_Solar_Study.skp`,
SUNEAST/Resonance_BM_Ops/3D_Models). Canopy positions = lighting `fixtures.json`.
Sun verified vs almanac (solar noon 12:57 PDT, alt 56.9°, noon shadow due north).
Scripts: resonance-os-v2 `apps/tree-blender/scripts/sketchup/`. Questions → Elliot.

## Run it offline (Ben — no live site needed)

Everything runs locally with no internet: `cd solar-visualizer && ./run.sh`, then open
`http://127.0.0.1:8777/Resonance_Solar_3D.html`. three.js + Draco are vendored under
`vendor/`. Full build + how-to-modify notes in **BUILD.md**; source + geometry in `src/`.

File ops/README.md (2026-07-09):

# Ops

Logistics, vendors, BOM management, procurement. Non-engineering operational work.

## Contents

- `bom.md` -- fleet bill of materials: shared core + per-class tables, fleet totals
  vs bought, spares math, open BOM inputs. Counts mirror the canonical fleet table
  in `docs/block-diagram/SYSTEM.md`.
- `PROCUREMENT.md` -- orders ledger (dates, costs, statuses), small/sample orders,
  to-buy queue, lead-time risks backward from Aug 20, procurement timeline, vendor
  directory. Absorbs the previously planned `vendors.md` / `shipping.md` /
  `timeline.md`.
- `bench/` -- bench tooling (Python loggers, sweep/analysis scripts, dashboards) and
  measurement data under `bench/data/` (site-partitioned JSONL; see
  `bench/data/README.md`).

Container/bamboo shipping (Bali -> US) is Elliot's track with Michelle Satkin /
Mainfreight -- coordinate through Ben, not from this repo.

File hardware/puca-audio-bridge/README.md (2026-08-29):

# PUCA performance audio bridge

This is the hardware and bring-up record for the dedicated performance-audio
source for Resonance Tree. The manufacturer's name is styled with an accented
`u`; this repo uses the ASCII spelling **PUCA** so Windows shells, searches, and
agent handoffs remain reliable.

**Status (2026-08-29): the standalone powered-Pod20 `0.4.1-dev` baseline,
credentialed `0.5.0-dev` safe OTA path, `0.5.2-dev` onboard-mic four-mode proof,
`0.5.3-dev` clockwise carrier-control normalization, and `0.5.5-dev` capacitive
paw/held-boot arming pass on the received
PUCA.** The installed behavior boots SAFE-IDLE and
emits no lighting frames unless the capacitive paw arms it during the five-
second boot opportunity; an armed boot starts in DJ mode + line input. Exact
hardware now proves `bootarmed=1` and `active=1` after a held-paw Pod20 power
cycle. PUCA advertises its exact `A4EB10`
identity to Bridge OS and accepts only exact-target shared-WiFi maintenance,
never a fleet-wide request or factory-style softAP. Laptop line input through
J5/J6 is proven; real RODE gain, exact waveform/light fidelity, timed post-arm
setup gestures, stale fallback, rollback,
multi-hour stability, and intended-placement RF/PDR remain open.

The illustrated
[`Bridge field manual`](../../docs/howto/BRIDGE_OS_FIELD_MANUAL.md) explains
when to use the proven CoreS3 fallback, how PUCA fits beside Bridge OS, and the
operator-facing bring-up boundary. This file remains the detailed hardware
record and qualification checklist.

The DG1022Z ceremony-waveform path has its own no-human bench procedure and
explicit isolation boundary in
[`DG1022Z -> PUCA heartbeat input`](../../docs/howto/DG1022Z_PUCA_HEARTBEAT.md).

## What "PUCA" means in this project

PUCA means the Ohmic Limited **PUCA DSP Original Edition** mounted on its 6 HP
Eurorack expansion. It is a small original-ESP32 audio/DSP board with:

- ESP32-PICO-D4, 4 MB flash, and 8 MB PSRAM (Original Edition);
- WM8978 stereo audio codec;
- stereo 3.5 mm line input and line/headphone output on the PUCA board;
- two onboard Knowles MEMS microphones;
- USB-C programming/power and optional LiPo support;
- 8-48 kHz codec sample-rate support.

The bare-board line input is AC-coupled, 1 Mohm, and specified for no more than
3.3 V peak-to-peak before clipping. The Eurorack carrier exposes dual-mono or
stereo audio I/O plus protected control inputs. Do not confuse an AUDIO jack
with the nearby CV or TRIG jacks.

Official references:

- <https://github.com/ohmic-net/puca_dsp>
- <https://github.com/ohmic-net/puca_dsp/tree/main/puca-eurorack>
- <https://www.ohmic.net/puca-dsp>

## Hardware on hand

- PUCA DSP **Original Edition** on the Ohmic Eurorack expansion (the R110
  Original bundle).
- 4ms **Pod20 Powered** 20 HP Eurorack case.
- 4ms **45 W Power Brick**, AC mains lead, and the Eurorack ribbon supplied with
  the PUCA bundle.
- 10 HP + 4 HP blank panels around the 6 HP PUCA module.
- RODE **VideoMic NTG** directional microphone and **WS11** furry windshield.
- Multiple M5Stack CoreS3 + Module Audio stacks as an independently implemented
  fallback; see `firmware/cores3_bridge/README.md`.

The Eurorack carrier's controls are useful rather than decorative:

| Control | Hardware mapping | Current Resonance use |
|---|---|---|
| Top knob | CV2 / GPIO33 ADC | input sensitivity, 0.25x-4x; clockwise increases, counterclockwise decreases |
| Bottom knob | CV3 / GPIO34 ADC | brightness ceiling, clockwise toward maximum; clockwise hue wheel only in HUE mode |
| No paw hold at boot | capacitive TOUCH input | SAFE-IDLE: identity/maintenance only, no lighting frames |
| Paw held 1.2 s at boot | capacitive TOUCH input | arms DJ + line and opens setup; short touch cycles four live modes, long hold locks |
| Paw after locked boot | capacitive TOUCH input | status display only; cannot arm/change/stop the performance |
| CV1-3 | protected control-voltage inputs | future performer/controller input |
| TRIG1-2 | protected trigger inputs | future footswitch or beat trigger |

Normal no-laptop startup is SAFE-IDLE + line input + LOCKED. Hold the paw during
boot to arm line input + DJ and open setup. The bottom carrier
LED reports one/two long pulses for line/mic followed by one to four short
pulses for DJ/HEARTBEAT/EMBER/HUE. OFF is deliberately absent from the paw
cycle.

## Power-source boundary

USB-C or a LiPo can keep the PUCA main PCB's ESP32, codec/onboard-audio path,
radio, and recovery interface alive. It does not replace the Pod20's Eurorack
rails for the installed carrier's complete analog audio, CV, trigger, and panel
path. The Pod20 is therefore the normal operational supply; USB is the rescue
and serial path.

The optional main-board LiPo could provide a brief PUCA-only control-plane ride-
through, but it cannot keep the externally powered tree or full Eurorack signal
chain operating after their power is lost. The current installation therefore
does not require soldering the optional JST battery header. Revisit only if a
measured requirement emerges for PUCA telemetry/OTA ride-through independent of
the Pod20.

## Intended signal and control path

```text
RODE VideoMic NTG --analog audio--> PUCA audio input
                                      |
                                      v
                              WM8978 -> I2S DMA
                                      |
                                      v
                         ESP32 envelope / FFT / onset
                                      |
                                      v
                          ESP-NOW, fixed channel 11
                                      |
                                      v
                      fleet direct frames -> light output
```

The PUCA onboard microphones are the no-extra-cable fallback. The RODE is the
normal source for bowls, violin, singing, and other non-DJ performances because
its directionality and active variable output make gain staging repeatable.

For a DJ or mixer, use a documented record/booth output and keep the PUCA input
below its 3.3 Vpp clipping limit. Add isolation and attenuation when the source
can produce professional line-level peaks. Never feed a speaker output into the
PUCA.

The exact 2026-08-28 laptop/RODE candidate cable chain is electrically the
intended unbalanced stereo breakout:

- JSAUX ASIN `B07D8M5DML`: 3.5 mm TRS stereo male to red/white RCA male,
  passive and bidirectional.
- Two Bolvek ASIN `B09K3DHL82` adapters: one RCA female to 3.5 mm TS mono male
  per channel.
- Red and white TS plugs go separately to faceplate J5/J6 AUDIO IN, never J8/J9
  AUDIO OUT. The topology does not join left and right or short either signal to
  ground. The initial silent run mistakenly used J8/J9. Correct J5/J6 placement
  raised RMS from 6-12 to 37-41 at 10 percent laptop output with zero clipping
  or capture/transport errors, proving the complete line-to-fleet route.

The first implementation should **not transmit raw audio**. It should reuse the
proven `NB_DIRECT_FRAME` path at about 10 Hz and retain the fixture's existing
three-second stale-frame return to autonomous behavior. A compact, reusable
audio-feature packet (RMS, broad bands, onset, tempo/confidence) may be useful
later, but it is a separate packet-contract decision and is not required for
first light.

## RODE starting configuration

This is a bring-up baseline, not a measured final preset:

1. Charge the mic and turn it on manually. Do not assume the PUCA input provides
   the plug-in power needed for the RODE's automatic power behavior.
2. Install the WS11 outdoors.
3. Start flat: high-pass off, high-frequency boost off, pad off, and safety
   channel off.
4. Start the RODE output gain conservatively, exercise the loudest expected
   source, and raise it until peaks retain roughly 12-18 dB of digital headroom.
5. Keep codec gain fixed and automatic gain control off for the first bridge.
   Avoid two independent gain loops.
6. Once measured, mark or tape the RODE dial and record both RODE and codec gain
   here. For bowls, preserve the low end unless wind/handling proves otherwise.

The included RODE shock mount has a 3/8 inch socket. Use the folding boom stand,
strain-relieve the audio cable, weight the stand outdoors, and mark the legs so
they are visible at night.

## Software constraints and implementation notes

- This is an original dual-core ESP32, **not** an ESP32-S3. Use a distinct board
  profile and do not assume the CoreS3 pin map, USB behavior, or libraries.
- Original Edition and Strawberry Edition binaries are not interchangeable.
  This received Eurorack unit is the Original/PSRAM edition.
- The factory Eurorack image creates a `PUCA DSP` WiFi access point for firmware
  upload. Resonance runtime never creates that AP. COMMS remains unassociated on
  channel 11; only exact-target `A4EB10` maintenance may stop publishing, leave
  ESP-NOW, and join the shared maintenance WiFi for standard A/B OTA.
- Reuse platform-independent feature extraction from
  `firmware/cores3_bridge/audio_reactive.h` where practical, but keep codec,
  I2S, control-panel, and board initialization in a PUCA-specific layer.
- Reuse the canonical fleet packet definitions from
  `firmware/fixture/src/core/packet.h`; do not fork a lookalike packet struct.
- Chunk `NB_DIRECT_FRAME` output across the full sorted live census. One packet
  carries only 18 fixtures; silently limiting a publisher to that first packet
  is not a fleet implementation.
- Treat the metal Pod case and its orientation as part of the RF system. The
  first field test must include range/PDR with the module installed in the case.
- Preserve a no-audio or no-radio safe state. Silence, clipping, cable removal,
  reboot, or bridge loss must not latch the fleet in a directed show.

## Bring-up checklist

- [ ] Photograph and record the installed ribbon orientation before first power;
  the red stripe belongs at `-12 V` on the Eurorack bus.
- [x] Confirm the board label/flash size identifies the received unit as Original
  Edition and record its USB identity and WiFi/ESP-NOW MAC. DONE 2026-08-26;
  details are below.
- [ ] Run the upstream trigger/CV hardware tests and verify both knobs and the paw.
- [ ] Identify and label the exact front-panel AUDIO input/cable used by the RODE;
  record whether it reaches WM8978 LINE or AUX and the required gain.
- [ ] Log unclipped RODE input levels for bowls, violin, and singing, plus the
  onboard-microphone fallback.
- [x] Create `firmware/puca_bridge/` with a named build profile and native
  audio/control tests. The development build reports binary SHA-256; promotion
  under ADR 0040 remains gated on hardware acceptance.
- [x] Prove powered-Pod20 stereo capture, locked-paw behavior, channel-11
  census, and more-than-18-fixture sender chunking without reported errors.
  DONE 2026-08-26 with `0.4.1-dev`; receiver-side light proof remains separate.
- [x] USB-bootstrap credentialed `0.5.0-dev` and prove no-hold SAFE-IDLE,
  `A4EB10` heartbeat in Bridge OS, exact-target maintenance, shared-WiFi OTA,
  post-OTA dark reboot, and pending-verify survival. DONE 2026-08-27; exact
  evidence is below.
- [x] Service-start the onboard MEMS path, exercise DJ, HEARTBEAT, EMBER, and HUE
  across the fresh fleet with clean capture/transport counters, and visibly
  confirm audio-reactive fixture behavior. DONE 2026-08-28 on exact-target OTA-
  installed `0.5.2-dev`; the same pass hardware-proved elapsed-time calibration
  at about two seconds. Per-mode color distinction remains a separate visual
  acceptance check.
- [x] Prove paw-held DJ-first arming. DONE 2026-08-29 on `0.5.5-dev` with raw
  capacitance evidence, fresh power-on rejoin, and local `bootarmed=1` /
  `active=1` telemetry.
- [ ] Prove the remaining ADR 0063 gates: timed setup short/long gestures,
  `/resume`/10-minute timeout, fleet-wide-maintenance rejection on
  hardware, no softAP, and forced-self-test A/B rollback.
- [ ] Prove one fixture receives direct frames on channel 11 and returns to
  autonomous output within three seconds after PUCA transmission stops.
- [ ] Repeat on a mixed HEX/RGBW group, then measure packet rate, PDR, CPU load,
  audio overruns, and multi-hour stability.
- [ ] Range-test the PUCA in the closed Pod20 at the intended tree/Shiftpod
  placement and orientation.
- [ ] Record the final RODE gain, codec gain, knob functions, startup sequence,
  and known-good firmware artifact in this file.

## Powered-Pod20 acceptance (2026-08-26)

- Power: the PUCA ribbon red stripe was aligned to the PCB `-12 V` marking;
  Pod20 `+12 V`, `-12 V`, and `+5 V` LEDs were steady. USB and Eurorack power
  were present together for programming/telemetry and faceplate-rail operation.
- Target identity: Silicon Labs CP2102N
  `USB\\VID_10C4&PID_EA60\\0EC45B486617EC1183509E9D47486EB0`; ESP32-PICO-D4
  revision 1.0, 4 MB embedded flash, MAC `4C:75:25:A4:EB:10`, short ID `A4EB10`.
  Do not confuse it with the ESP32-S3 currently enumerating separately as
  `COM152`.
- Recovery image before the first Resonance flash:
  `firmware/puca_bridge/build/puca-bridge-20260826-standalone-heartbeat-v040-c1/preflash-backup/puca-com154-pre-v040-full-4mb.bin`,
  exactly 4,194,304 bytes, SHA-256
  `c4f67d01dc1c001e1e6342f7b3b604f77b5f6f701ee4962b3bb94dd5e3d0bfcf`.
- Installed development candidate:
  `firmware/puca_bridge/build/puca-bridge-20260826-standalone-heartbeat-v041-c2/puca_bridge.ino.bin`,
  964,752 bytes, SHA-256
  `e8ec74680564f96f10c2f6e87b37eb807b9d9ba3b355ccf41c72f8301c4984b6`.
  Flash writes and read-back hashes verified. This is a known recovery identity,
  not a promoted show artifact.
- Runtime: booted HEARTBEAT, line input, controls LOCKED, codec and I2S ready,
  ESP-NOW channel 11. A normal paw touch printed `paw=status only` and left the
  mode unchanged. The powered knobs produced stable nonzero readings.
- Radio soak: over 207 s the live census grew to 70+ eligible fixtures and the
  sender reached 8,318 successful callbacks with `sendfail=0`, `readfail=0`,
  `rxdrop=0`, `i2cerr=0`, and zero clipped blocks. This proves local full-census
  packet production; visible receiver application and field-distance PDR are
  still separate acceptance gates.
- Cleanup: USB service key `A` sent the final eight black chunks, changed status
  to `active=0`, and left the send counters stable. The bridge is paused for the
  bench handoff; the next power cycle restores active HEARTBEAT + line input.

## Safe-boot and OTA acceptance (2026-08-27)

- Built credentialed `0.5.0-dev` with the explicit ESP32-PICO-D4 default dual-
  app partition layout. Application identity:
  `firmware/puca_bridge/build/puca-bridge-20260827-ota-safe-v050-bootstrap-r3/puca_bridge.ino.bin`,
  1,024,128 bytes, SHA-256
  `1e90f6f1731a622b11274fa91abbc6eeebb17c35abe90bd86337c915cb99e8da`.
- The received CP2102N automatic reset did not enter the ROM downloader. There
  is no exposed BOOT button: the visible onboard button is GPIO36. With stable
  Pod20 and USB power, the proven rescue was a normal jumper from `RST` to `GND`,
  DTR/download asserted, release `RST`, then esptool `--before no_reset`. All
  four flash regions completed esptool hash verification. Never use a meter in
  ammeter mode as the jumper and never short `VIN` or `VDD`.
- Fourteen consecutive no-hold status samples reported DJ selected but
  `active=0`, `bootarmed=0`, controls locked, codec ready, and `frames=0`.
  Heartbeat callbacks alone increased, as intended.
- Primary Bridge OS `8EB508` received fresh channel-11 heartbeats for publisher
  `A4EB10`, revision `puca-bridge-0.5.0-dev`.
- The host sent only `UA4EB10`. PUCA joined shared WiFi, exposed identity-
  matching `/telemetry`, and accepted the retained 1,024,128-byte application.
  The upload was recorded in
  `ops/bench/data/ca/2026-08-27-ota-results.jsonl`.
- After OTA, the dashboard observed a fresh expected-revision heartbeat with a
  software reset and reset uptime/sequence after the 25 s survival gate. A
  separate USB status request caused another ordinary reset and again reported
  SAFE-IDLE, locked controls, healthy codec, and zero direct frames.

This accepts the routine enclosed-update path. The internal USB connector can
remain behind the faceplate, but must remain physically accessible for rescue.

## Four-mode mic proof and fault isolation (2026-08-28)

- Installed exact-target diagnostic candidate
  `firmware/puca_bridge/build/puca-bridge-20260828-paw-telemetry-v052-r1/puca_bridge.ino.bin`,
  1,024,608 bytes, SHA-256
  `3e3e8d9fa0ce3c8d60950abc027840eb345c95cf1f9438d1f0ff44cbac5a20e8`.
  The standard shared-WiFi OTA path identity-matched `A4EB10`, uploaded once,
  and verified fresh `puca-bridge-0.5.2-dev` rejoin.
- The onboard MEMS path produced RMS about 1,300-5,500 and peaks through 14,685.
  Ben visibly observed audio-reactive fixtures while serial cycled DJ,
  HEARTBEAT, EMBER, and HUE over about 75-92 fresh fixture IDs. Send, I2S-read,
  I2C, and receive-queue errors remained zero.
- Time-based calibration was false at 1,500 ms and true at 2,505 ms before DJ
  frames began. This replaces the accidental roughly five-second legacy frame-
  count behavior at PUCA's approximately 10 Hz capture cadence.
- Windows successfully played a 96 kHz, about -8 dBFS test through the exact
  `Realtek HD Audio 2nd output` endpoint. Initial 10 and 25 percent runs stayed
  at the noise floor because both TS plugs were in J8/J9 AUDIO OUT; Windows was
  restored to 10 percent. After moving the plugs to J5/J6 AUDIO IN, the same
  waveform raised RMS from 6-12 to 37-41 and rendered level to about 0.13-0.15
  with zero clipping or capture/transport errors. The cable, faceplate line
  path, WM8978 route, and line-to-fleet firmware path are proven.
- The vendor example's GPIO15 digital read was the fault, not the paw hardware
  or the earlier J8/J9 audio-output mistake. Released ESP32 touch capacitance is
  867-870; a held paw falls through 216. `0.5.5-dev` uses hysteretic capacitance
  detection and rejects near-zero/shorted readings. A real held-paw Pod20 power
  cycle produced `bootarmed=1`, `active=1`, DJ + line, and zero error counters.

## What PUCA is not

- It is not one of the roughly 130 solar fixture controllers.
- It is not the CoreS3 desk bridge, though both can publish to the same fleet.
- It is not a required coordinator: fixtures remain autonomous when it is absent.
- It is not yet production-validated merely because the hardware has arrived.

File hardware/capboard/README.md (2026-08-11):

# Solarnoid cap-bank board — v2.0

> **CRITICAL -- fabricated v2.0 receiver supply is unsafe (2026-08-09).** Do
> not populate RECVR or plug in another RX480E. U1 is a Holtek HT7550-1, whose
> SOT-89 pins are 1=GND, 2=VIN, 3=VOUT, but the ordered board assigns pin 2 to
> P5V and pin 3 to the approximately 12 V VBOOST rail. This reverse-powers the
> regulator and can expose the nominal receiver `+V` pin to approximately boost
> voltage; `+V`-to-`G` measured 11.76 V on the first board. Two receivers
> emitted smoke during first bring-up. Keep RECVR empty
> until a measured ECO is qualified; the PowerFeather USER button and ESP-NOW
> command remain the safe trigger paths.

## Deployed rev-1 boards with the external boost cable

The 24 BMP-equipped outer-ring downlights use fabricated **rev-1 capboards**, not
the unsafe rev-2 receiver circuit described above. Their retrofit cable splices
an external approximately 12 V boost into the capboard input `VDC`/`GND`, so the
rev-1 bank, driver feed, and regulator input see the boosted voltage.

Rev 1 uses an AMS1117-5.0 with the correct SOT-223 mapping: pin 1 GND, pin 2/tab
5 V output, pin 3 boosted input. It is a linear regulator, not a buck converter;
at the RX480E's small load it drops approximately 12 V to 5 V and dissipates the
voltage difference as heat. Ben reports the populated rev-1 433 MHz receiver
paths operating normally on the boosted assemblies. This is consistent with the
rev-1 circuit and does not clear rev 2: rev 2 changed to an HT7550-1 with a
different pinout but retained the old net assignment, reverse-powering U1 and
putting 11.76 V on the nominal receiver rail. Before lid closure, spot-measure a
representative rev-1 receiver rail near 5 V and confirm U1 stays cool during an
extended powered test.

Strike-drive board for the bamboo-lantern noisemakers. Sits between the solar
panel and the Adafruit 5648 MOSFET driver: takes raw panel voltage in, **boosts
it to ~12 V**, buffers it in a 3 × 22,000 µF bank, and hands that to the
solenoid driver. Force on a reluctance actuator goes as V²/R, so the boost is
worth roughly **4× the strike energy** of the original 6 V design.

100 × 40 mm, 2 layer. **Ordered 2026-08-03: 10 panels of 6×2 = 120 boards.**

## Signal chain

```
panel ──> PANEL ──> MT3608 boost (~12.07 V) ──> 3× 22,000 µF ──> DRIVER ──> 5648 ──> solenoid
                                                     │
PowerFeather D7 ────────── (passes straight through) ┘
```

- **PANEL** and **DRIVER** are *not* the same net. PANEL carries raw panel
  volts (4.6–5.9 V); DRIVER carries the boosted rail. Swapping them is not
  destructive but gives weak knocks.
- **D7** is the ESP32 gate line; it passes through untouched on the back layer.

## Ports (bottom edge, left to right)

| Ref | Connector | Pinout |
|---|---|---|
| PANEL | JST XH 4p right-angle SMT | D7 · VDC · GND · GND |
| RECVR | 1×7 0.1" SMD socket | RX480E dock — G·5V·D0·D1·D2·D3·VT (**unpopulated**, see below) |
| TELE | JST XH 2p vertical THT | VSNS → A4 · BOOST_EN → A5 |
| DRIVER | JST XH 4p right-angle SMT | D7 · VBOOST · GND · GND |

Pin 4 on PANEL/DRIVER is a **second ground** — on DRIVER that splits the ~3 A
strike return across two contacts, which matters since XH is a 3 A series.

The 2-pin TELE is physically incompatible with the 4-pin power ports, so the
two cannot be cross-plugged. Reversing the TELE cable is harmless (both lines
are ADC-capable; firmware can tell them apart).

## Subsystems

- **Boost** — MT3608, 22 µH/2.4 A shielded inductor, SS34. Feedback 130 k/6.8 k
  → 0.6 × (1 + 130/6.8) ≈ **12.07 V**. R12 (THT, DNP) parallels the lower leg to
  trim *upward*; watch the 16 V caps if you push far. **JP1** (DNP) bypasses the
  boost entirely — close it and the board reverts to v1.0 behaviour.
- **EN** — 47 k/47 k divider off VDCIN holds EN at ~VIN/2, so the boost
  **self-enables with nothing plugged in**, and a GPIO on TELE pin 2 can pull it
  low. The GPIO never sees more than ~3.0 V.
- **One-shot button (SW1)** — VDC→SW1→470R→10 µF→D7, zener-clamped. One ~40 ms
  pulse per press; the series cap blocks DC, so a stuck button *cannot* park the
  coil energised (a lit panel would otherwise sustain 2.5–4 W into the coil).
  C1B (THT, DNP) parallels C1 to lengthen the pulse. Fixture firmware
  `2026-08-09.2` and later detects the released-to-HIGH edge and takes over D7
  for its independently bounded 40 ms pulse; the hardware one-shot remains the
  initiator and DC/stuck-input bound.
- **Receiver rail (U1) -- AS-FAB UNSAFE:** the intended HT7550-1 5 V rail has
  VIN and VOUT reversed on fabricated v2.0; see the critical warning above.
  Replacing the AMS1117 was intended to remove its 5-10 mA idle draw, but the
  pinout changed with the part and was not carried into the footprint nets.
- **Telemetry** — VSNS = VBOOST × 6.8/53.8 → A4; 47 k/6.8 k with 1 nF gives
  ~27 kHz of bandwidth, enough to actually capture the 25 ms droop transient.

## Fab package (upload these three)

| File | |
|---|---|
| `build/capbank_gerbers_v2.0_4pin.zip` | gerbers + drills |
| `capbank_cpl_4pin.csv` | 23 SMT parts |
| `capbank_bom_smt_4pin.csv` | every line carries an LCSC part number |

Settings: 2-layer FR-4, 100 × 40 mm, green/white, HASL leaded, 1.6 mm, 1 oz,
tented vias, remove mark, **SMT top side only**.

**RECVR is deliberately unpopulated** — no SMD female header has stock anywhere.
The RX dock is optional per node (production triggering is the ESP-NOW clicker),
so its pads stay bare and a socket can be hand-fitted on whichever boards ever
get a 433 MHz receiver.

No verified 12 V receiver has the RX480E 1x7 drop-in footprint. If local RF is
still wanted on fabricated v2.0, use a compact wide-input 433 MHz receiver with
an isolated dry-contact output on a short five-wire harness. The leading bench
candidate is QIACHIP
[KR1201MINI2-V05B](https://qiachip.com/products/kr1201mini2-v05b-mini-relay-remote-control-dc3v-5v-9v-12v-24v-all-compatible-dry-contact-2a-load-current-rf-433mhz-remote-control-switch)
(3.7-24 V input, 31 x 14 x 7 mm,
momentary/toggle/latching modes). Wire receiver power `+` to true VBOOST and `-`
to GND at DRIVER; wire relay COM to raw VDCIN at PANEL and relay NO to the
RECVR D0/BTNP pad so the contact exactly imitates SW1 upstream of R7 and the
one-shot. Leave NC unused. Do not power it from the damaged RECVR `5V` pad,
despite the 11.76 V unloaded reading, and never route 12 V directly into D0 or
D7. Qualify current draw, remote compatibility, momentary setup, strike-rail
droop, and sleep energy before fleet use.

**Hand-soldered in Nevada City — 8 joints/board:** the 3 electrolytics and the
2-pin TELE. C1B, R12, JP1 are DNP options.

Cap voltage ratings are deliberate and annotated in the BOM: C1/C7/C8 never see
more than ~6 V so 16 V is ample, **C9 is the only part on the 12 V rail and must
stay 25 V.** Letting the picker default to 50 V parts cost $131 on the first quote.

## Workflow — placement is Ben's, routing is scripted

Positions and silkscreen are hand-placed in KiCad and are **authoritative**.
`route_capboard.py` / `route_4pin.py` load the placement file and add *only*
tracks, vias and the ground pour, so routing is reproducible after any
re-arrangement and never fights the layout.

```bash
python3 route_4pin.py                                    # 4-pin (production)
kicad-cli pcb drc --refill-zones --save-board --severity-error \
    --exit-code-violations -o build/drc.rpt build/capbank_4pin.kicad_pcb
```

**Edit `capbank_placement_4pin.kicad_pcb`, never `build/capbank_4pin.kicad_pcb`** —
the latter is regenerated and your changes would be lost. If you do edit the
build output by accident, its positions can be synced back into the placement
file (that is how the v2.0 PANEL/TELE nudges were recovered).

| File | Role |
|---|---|
| `capbank_placement_4pin.kicad_pcb` | **source of truth** — placement + silkscreen |
| `route_4pin.py` | adds copper; regenerates `build/capbank_4pin.kicad_pcb` |
| `capbank_4pin_ben.kicad_pcb` | snapshot of the hand-edited board, for reference |
| `capbank_placement_ben.kicad_pcb` + `route_capboard.py` | 3-pin variant (S3B is out of stock; kept as fallback) |
| `generate_capboard_v10.py.bak` | the v1.0 generator, the board that was actually fabbed first |

## CAD for the plate

`cad/` holds v2.0 STEP/DXF/VRML exports — see `cad/README.md`. Mounting holes
are unchanged from v1.0 at **(3.2, 3.2), (84.8, 3.2), (84.8, 36.8), (3.2, 36.8)**,
so existing plates fit; the board simply overhangs 15 mm past the right pair.
3.2 mm holes take M2.5 or M3.

## Before the next order

- Correct U1 to HT7550-1 pins 1=GND, 2=VBOOST/VIN, 3=P5V/VOUT and create a new
  board revision; do not silently regenerate this as v2.0. Before release,
  measure the receiver rail unloaded and with a current-limited dummy load.
- Verify the RX480E module pin order against physical parts if RECVR is ever
  populated (assumed GND · +V · D0 · D1 · D2 · D3 · VT).
- Cables are crimped from raw leads: press them **straight, never mirrored** —
  a mirrored cable swaps D7 and GND and puts the bank across the gate line.

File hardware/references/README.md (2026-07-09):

# References

Reference schematics, datasheets, and reference designs for the current hardware path.
Download/cite exact PDFs in design files when a custom board or adapter actually uses them.

## Current Reference Architecture

### PowerFeather V2

Primary COTS/reference design for 2026:

- ESP32-S3-WROOM-1 module with PCB antenna.
- BQ25628E charger / power path.
- MAX17260 fuel gauge.
- TPS631013 buck-boost 3.3 V regulator.
- Switchable `3V3` and `VSQT` rails.
- USB-C and VDC solar input.

Use the official PowerFeather docs, SDK, and any licensed KiCad/Gerber files if the creator
shares them. Do not blindly copy switching-regulator or RF layout without review.

### BQ25628E - Charger / Power Path

Current charger reference because it is validated on PowerFeather V2.

Design notes:

- Set `VBUS_OVP=1` for standard 6 V-class panels whose open-circuit voltage can exceed the
  default low input-OVP threshold.
- Add a supply-present-but-not-good HIZ requalification kick so bright-sun connect does not
  leave a fixture silently not charging.
- Verify LiFePO4 charge voltage/current and battery temperature behavior in firmware.

### MAX17260 - Fuel Gauge

Current gauge reference because it is validated on PowerFeather V2.

Design notes:

- Set battery capacity/profile deliberately and avoid changing it in the field.
- Treat LiFePO4 percentage SOC as advisory until the gauge learns a real cycle.
- Use voltage/current and corrected coulomb counting for production guardrails.

### TPS631013 - 3.3 V Buck-Boost

Current 3.3 V rail reference because it is validated on PowerFeather V2.

Design notes:

- LFP terminal voltage can sit near buck/boost crossover at light loads.
- Measure real efficiency at production loads; do not rely on nominal curves.

### ESP32-S3-WROOM-Class Module

Current MCU/RF reference. Use a pre-certified module with PCB antenna and generous
keep-out. Avoid custom RF and avoid u.FL unless mock-hat RF tests require it.

## LED References

### SK6812 / WS2812-Protocol LEDs

Current direct-GPIO LED family for both live roles:

- HEX SK6812 array for close-range animation / glow.
- 4 W RGBW point source for crisp gobo projection.

Design notes:

- LED rail must be switchable/default-off.
- Send explicit all-off before sleep/rail shutdown.
- Add current caps for lit-count x brightness.
- Use 4.2 V, not 5 V, for the HEX boost experiment unless a data level shifter is added.

### IS31FL3741 - Historical / Ruled Out For V2 Battery Build

The IS31FL3741 matrix was useful early bench hardware but is ruled out for the PowerFeather
V2 battery architecture because it browns out the board on the shared charger/gauge I2C bus
under WiFi. Keep references only for historical tests or a future isolated-bus experiment.

## Historical / Superseded References

### CN3058 - Historical LiFePO4 Charger Candidate

CN3058 was the early custom-board charger pick. It is now superseded by the
PowerFeather/BQ25628E reference architecture and should be treated as fallback history.

### AP2112K-3.3 - Historical LDO Candidate

AP2112K was part of the original ESP32-C3 first pass. The current reference uses a
buck-boost 3.3 V rail.

### ESP32-C3-MINI-1 - Historical MCU Candidate

ESP32-C3-MINI-1 was the original production MCU pick. Later ADRs moved the default bias to
ESP32-S3-WROOM-class modules for RF/headroom margin.

## Mechanical Reference

- Bamboo lantern: `enclosure/references/DOWN LIGHTS DRAWINGS.pdf` - Vishnu's shop drawing,
  2026-04-22. (Not committed to the repo yet -- lives with Steve/Drive; TODO to commit
  or re-point.)
- Hat dimensional constraints: see `BACKGROUND.md` and `enclosure/README.md`.

## Existing Dev Boards We Lifted Ideas From

- **TTGO T-Beam** - Ben's prior Talisman v2 platform; useful historical reference.
- **TTGO T-Ice** - discontinued ESP32 + WS2812B driver board from the Marquee workstream.
- **DFRobot DFR0559** - LiPo fallback solar manager, not the leading LFP architecture.
- **Adafruit Feather ESP32-S3** - modular ESP32-S3 reference.

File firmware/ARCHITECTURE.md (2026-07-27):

# Firmware Architecture

**Status (2026-07-08):** this is the TARGET production architecture. Current code is
standalone bench sketches under `firmware/<app>/` (see `firmware/README.md`);
`net_bench` is the closest ancestor of production firmware. Constraints learned on
the bench that bind this design: ADR 0028 (power-management bus integrity), ADR 0029
(LED drive per role), ADR 0023 (low-battery thresholds), ADR 0027 (sensors).
The non-binding candidate behavior/timing layer is explored in
`docs/research/AUTONOMOUS_DISTRIBUTED_CHOREOGRAPHY_CONCEPT_2026-07-13.md`; it broadens
CA into a generic autonomous/bridge-optional choreography runtime but is not yet an
adopted architecture decision.

Firmware runs across COTS prototypes and the eventual production target. The architecture must support multiple board definitions, standard OTA maintenance updates, ESP-NOW state exchange, LED rail fail-safes, and telemetry logging.

## Layered structure

```
firmware/
|-- core/             Platform-independent C++. Compiles native. Unit-tested.
|   |-- ca/           Cellular automata engine.
|   |-- packet/       ESP-NOW packet codec.
|   |-- pattern/      LED animation generators.
|   |-- state/        Fixture state representation.
|   `-- tests/        Native tests.
|
|-- esp32/            ESP32-specific glue.
|   |-- boards/       Board definitions: powerfeather_v2, resonance_custom.
|   |-- drivers/      ESP-NOW, OTA, LED drivers, charger/fuel gauge, rail control.
|   |-- tasks/        FreeRTOS tasks.
|   `-- main.cpp
|
`-- tools/            Host-side smoke test, log parser, telemetry tools.
```

## Board abstraction

Each board definition should specify:

- MCU type / build flags.
- LED driver type: WS2812/SK6812 via NeoPixelBus, 4 W RGBW point source, or no LED
  (direct-GPIO only -- I2C LED controllers are ruled out, ADR 0018/0028).
- LED/module rail control: `VSQT`, onboard LDO enable, external load switch, or always-on fallback.
- Charger/fuel-gauge devices available.
- Battery chemistry support.
- Standard OTA support.
- ESP-NOW radio settings.
- Sleep capabilities.

Board targets:

- `powerfeather_v2` -- ESP32-S3-WROOM, BQ25628E, MAX17260, TPS631013, switchable
  VSQT. The 2026 production board (ADR 0024).
- `resonance_custom` -- possible 2027 PowerFeather-derived custom board (dedicated
  power-management I2C bus per ADR 0028).

(The COTS bake-off boards `feathers2_neo` / `atom_matrix` are retired -- ADR 0016
annotation.)

## OTA policy

OTA must remain boring and standard.

- Use normal ESP32 OTA partition/rollback mechanisms.
- Enter OTA in a deliberate maintenance mode: an ESP-NOW metadata packet sends the
  fixture(s) onto shared WiFi (portable router), where each serves `/update`; the
  host uploads in parallel (`ops/bench/net_bench_ota.py`). This is the fleet
  default; the self-hosted-AP fallback is deprecated (AGENTS.md bench gotchas).
- USB/pogo flashing remains the recovery path.
- ESP-NOW may advertise firmware version or maintenance availability.
- ESP-NOW must **not** carry firmware image chunks.
- No mesh-gossiped OTA image distribution.

## ESP-NOW policy

ESP-NOW is for lightweight fixture state and control only:

- heartbeat / boot announcement,
- fixture state,
- battery summary,
- neighbor RSSI / last-heard,
- global mode hints,
- wand/proximity events,
- optional maintenance-mode announcement.

Implementation notes:

- Add jitter to periodic sends.
- Use sequence numbers.
- Keep packets small and fixed-format where practical.
- Treat RSSI as approximate topology signal, not exact distance.
- Keep lighting functional even with partial packet loss.

## Task decomposition

```
led_task
  - render current local state to selected LED driver
  - enforce brightness/current caps
  - never block on network or file IO

ca_tick_task
  - drain mesh_rx_queue
  - update neighbor table
  - compute local state
  - enqueue state updates

mesh_rx_callback
  - enqueue received packets only

mesh_tx_task
  - heartbeat/state broadcasts
  - wand/control events
  - low-rate telemetry summary if enabled

power_task
  - read battery/charger/fuel gauge
  - manage LED/module rails
  - low-battery state machine (ADR 0023 tiers: dim/off/sleep, hysteresis,
    coulomb-primary voltage-backstop)
  - sleep/shipping mode transitions
  - NEVER pinned to core 0 while WiFi is active, and the shared charger/gauge
    bus stays at 100 kHz (ADR 0028)

sensor_task
  - MSA311 sway/tilt + multizone ToF presence (per class -- ADR 0027)
  - short per-frame reads sized to the 100 kHz bus budget
  - feeds choreography state into ca_tick_task

telemetry_task
  - log power/solar/battery/RF/reset data
  - expose smoke-test status
  - throttle flash writes

ota_task
  - only runs in maintenance mode
  - standard OTA update / rollback
```

## LED drivers

### IS31FL3741 matrix -- RULED OUT

Rejected for the battery build (ADR 0018): it disturbs the shared charger/gauge I2C
bus and browns out the board under WiFi. Nothing optional rides the power-management
bus (ADR 0028). Kept here only so nobody re-adds it.

### WS2812 / SK6812 via NeoPixelBus (HEX role)

- SK6812 HEX on the switchable 3V3 rail (the rail is its kill switch -- ADR 0029).
- Use DMA-capable driver where supported.
- Include brightness/current caps.
- Include data-line safe state + explicit all-off before powering rails off.

### 4 W RGBW point source (gobo role)

- Fed from the switchable 3V3 rail (V+/GND/A0 via right-angle JST-XH) -- DECIDED
  by the 2026-07-11 instrumented A/B (rail beats VBAT through production-realistic
  cabling, +2.5 % mean; ADR 0029 amendment). Same feed, harness, and pinout as the
  HEX; the rail is the hard LED kill.
- Single-emitter PWM drive; supports the swept/single-pixel gobo modes.

## Power / telemetry subsystem

Power telemetry is now a core firmware feature.

For PowerFeather V2/custom PowerFeather-like boards, log:

- battery voltage,
- battery current,
- SOC / remaining capacity,
- battery temperature,
- charger state,
- solar/VDC input behavior,
- charge current,
- fault flags,
- estimated time-to-empty/full,
- LED rail state,
- reset reason / brownout count.

For simpler fallback boards, log whatever is available and measure externally during bench tests.

## LED rail fail-safe

The firmware must assume LEDs can be left on by a bad state if not actively managed.

Required behavior:

- External LED/module rails default off at boot if hardware allows.
- Firmware enables LEDs only after boot sanity checks.
- Low battery turns LED rails off before brownout loop.
- Watchdog reset reinitializes LED rails safely.
- Shipping mode turns external LED rails off.
- LED rail off-state leakage is measured for each COTS stack.

## Sleep policy

Active-show mode may use light sleep or low-duty loops. Daytime/idle/shipping modes should use deeper sleep when possible.

For each board, measure actual current rather than trusting nominal specs:

- MCU-only sleep,
- sleep with LED module attached and rail off,
- sleep with charger/fuel gauge active,
- sleep with solar input present,
- wake latency and state restoration.

## Smoke-test boot announcement

Every fixture should report at boot:

- MAC-derived fixture ID,
- board type,
- firmware version,
- reset reason,
- battery voltage/SOC if available,
- charger/fault state if available,
- LED module detected,
- LED rail state,
- mesh peer count after a short delay.

This supports production QA and field debugging.

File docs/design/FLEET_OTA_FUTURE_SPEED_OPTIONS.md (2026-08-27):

# Fleet OTA future speed options

These are deliberately deferred. ADR 0062 first makes the proven shared-WiFi
unicast path predictable. Revisit these only if a measured full-fleet pass still
justifies the additional recovery and protocol complexity.

## Multicast or mesh-distributed image

Send the approximately 1.2 MB image once, with chunk identity, integrity,
forward-error recovery, per-fixture missing-chunk repair, and final SHA-256
verification. This removes the current `image size x fixture count` AP traffic
and could make the roughly 120-second wake rendezvous the dominant cost.

The difficult parts are loss recovery, bounded memory, A/B rollback integration,
mixed-version compatibility, and proving that one damaged transfer cannot
strand a fixture. ADR 0010's shared-WiFi OTA remains the production choice.

## Pre-stage, then activate

Distribute and hash-verify the next image opportunistically before the show-time
deployment window. A later job-scoped activation changes boot partitions and
reboots the prepared cohort together. The visible deployment could approach one
reboot plus the 25-second validation gate.

This needs durable staged-image identity, expiry, power-loss behavior, an exact
activation roster, rollback semantics, and a safe rule for fixtures that did not
finish staging. It is the strongest long-term speed option because distribution
leaves the critical path rather than merely becoming faster.

## Decision trigger

Keep phase timings in the ADR 0062 job ledger. Consider a radical transport only
after several clean 130-fixture passes show that unicast upload remains an
operational problem after bridge scheduling, freeze, reconciliation, and cleanup
are fixed.

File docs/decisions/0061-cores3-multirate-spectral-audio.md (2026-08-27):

# 0061 -- CoreS3 multirate spectral audio stays inside the Audio app

**Date:** 2026-08-26

**Status:** Accepted for hardware experiment

**Owner:** Ben

## Context

CoreS3 Bridge OS already has one Audio app that owns microphone selection,
noise-floor calibration, the RAM-only program-lease handoff, direct-frame
publishing, and safe pause/exit behavior. Its first looks use only one broadband
RMS envelope. Ben wants to explore short-window frequency analysis, a fast local
spectrogram, and looks driven by bass, mid, and treble bands.

A second spectral app would duplicate the same audio-device and fleet-ownership
lifecycle. It would also create a new transition where two app surfaces could
appear to own one I2S input. The fixture fleet does not need raw audio or an FFT
wire format: it already consumes final RGBW values in `NB_DIRECT_FRAME`.

The existing implementation ties sampling, output, and screen feedback to the
fixture render cap of 10 Hz. That rate is appropriate for the fleet but too slow
for a useful spectrogram.

## Decision

1. Spectral analysis is an additional engine and view inside the existing Audio
   app, not a third Bridge OS app.
2. Capture and analysis use a 512-sample Hann-windowed radix-2 FFT at a nominal
   25 Hz. The built-in microphones are analyzed at 16 kHz. Module Audio retains
   its 44.1 kHz codec setting and its interleaved stereo input is collapsed to
   mono before analysis.
3. The screen keeps about three seconds of 24-row log-frequency history and
   refreshes at the analysis cadence while Audio is active. Bass, mid, and high
   meters remain visible beside the scrolling spectrogram.
4. Fleet `NB_DIRECT_FRAME` output remains capped at the proven 10 Hz. No audio,
   FFT bins, band values, new packet type, fixture OTA, or fixture NVS change is
   introduced.
5. The initial common bands are 60-250 Hz, 250-2000 Hz, and 2000-8000 Hz. Each
   band has an independent adaptive floor, peak memory, attack, and release.
6. Existing CLASSIC, EMBER, HUECYCLE, and PULSE looks remain. The experiment adds:
   - BANDS RGB: bass, mid, and treble drive shared red, green, and blue;
   - BANDS SPLIT: stable fixture-ID thirds follow bass, mid, or treble;
   - TIMBRE HUE: spectral centroid selects hue while energy selects brightness.
7. Start, pause, app exit, input handoff, lease release, target selection, and
   three-second fixture fallback retain their existing contracts.

## Consequences

- One Audio surface can compare envelope and FFT looks without stopping capture
  or recalibrating between modes.
- The local interface can be fluid without increasing fleet airtime.
- Frequency resolution is about 31 Hz on the built-in 16 kHz path and about
  86 Hz on the 44.1 kHz Aux path. This is sufficient for broad musical bands,
  not pitch transcription.
- A 512-point FFT, fixed work buffers, and spectrogram history add several
  kilobytes of static RAM but no heap churn in the real-time loop.
- More advanced onset, tempo, section, or drop analysis can build on the same
  spectral engine later without changing the fixture wire contract.

## Validation required

1. Confirm Ambient and Aux both show plausible quiet-room and spoken/music
   spectra without a false high-frequency rail from stereo interleaving.
2. Measure achieved analysis/display cadence and confirm the radio receive queue,
   watchdog, touch controls, and 10 Hz fleet output remain healthy.
3. Feed or play bass-, mid-, and treble-dominant material and confirm all three
   new looks separate the intended bands on a named awake cohort.
4. Confirm mode changes do not recalibrate or interrupt publishing, while Input
   changes still send black, pause capture, and recalibrate the new source.
5. Pause and leave Audio, then confirm the roughly three-second autonomous
   fallback and no persistent fixture mutation.

## References

- `firmware/cores3_bridge/audio_reactive.h`
- `firmware/cores3_bridge/cores3_bridge.ino`
- `docs/decisions/0054-cores3-wireless-two-app-bridge-os.md`
- `docs/decisions/0057-cores3-runtime-audio-input-selection.md`
- `docs/decisions/0058-cores3-audio-releases-prior-program-lease.md`

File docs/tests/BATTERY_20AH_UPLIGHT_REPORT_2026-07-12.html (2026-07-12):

Resonance Lighting · Bench Report · 2026-07-10 → 07-12

# The 20 Ah that was

One week after catching a 7.2 Ah label hiding a 5.6 Ah cell, the same rig put batteryspace’s 20 Ah cylindrical through a 27-hour discharge. This one is honest — and its knee is so tight that 95% of the label is product-usable. It gates a ~40-cell buy for the solar-free uplights.

DUT batteryspace 20 Ah LFP cylindrical ("34184"), sample 1 of 2 load HEX37 val224, ~0.75–0.8 A truth INA219 @ 10 mΩ, battery lead (ch 0x45) leads alligator clips, R = 0.263 Ω measured — cell_v compensated board 9E5AF0

Delivered

19,412 mAh

97.1% of label · 27.2 h to cell-side 2.5 V

Usable above 3.0 V

19,055 mAh

95.3% of label clears the product floor

Knee width (3.0→2.5 V)

360 mAh

1.8% — the low-IR big-cell signature

Burn-week duty

6 h × 7

RGBW uplight at ~450 mA avg, no mid-week charge

## Label honesty, three cells in

Same rig, same load class, same coulomb methodology. What a label is worth depends on who printed it.

### Claimed vs product-usable (above the 3.0 V floor)

Label claim (outline) vs INA-measured delivery above cell-side 3.0 V.

## The discharge

### Cell voltage vs energy delivered

Solid: cell-side voltage (board reading + I×0.263 Ω lead compensation). Dashed: what the board saw through the alligator clips. Hover for values.

cell (compensated)board-side

### Discharge current over 27 hours

Flat ~0.78 A for 23 hours, gentle fade, then the brownout rattle far below the product floor (181 resets; run ends when the board can no longer restart). Zero resets before the knee — the secured clips never blinked.

## The charge (a story in three throttles)

### Charge current into the cell

USB hub’s 500 mA BC1.2 cap → wall brick (~820 mA) → CV taper, throttled the whole way by the 0.26 Ω clip leads (the charger regulates 3.6 V board-side, so the cell fills through the resistance). 6.03 Ah net in from a 3.25 V resting start — the cell arrived ~⅔ full.

## Results

Metric | 20 Ah (this test) | F — 32700 6 Ah | P — "7.2 Ah"
Delivered to 2.5 V (cell-side) | 19,412 mAh (97.1%) | 5,752 (95.9%) | 5,643 (78.4%)
Above 3.0 V floor | 19,055 mAh (95.3% of label) | 5,139 (85.7%) | 4,342 (60.3%)
Knee width (3.0→2.5 V) | 360 mAh (1.8%) | 613 (10.7%) | 1,301 (23.1%)
Run duration / load | 27.2 h @ ~0.78 A | 7.1 h @ ~0.81 A | 6.4 h @ ~0.88 A
Resets before knee | 0 | 0 | 0
Gauge/INA bias | ×1.071 | ×1.093 | ×1.081

Knee-width %s are relative to each cell’s label. The 32700s’ knee mAh differ slightly from the 07-06 report because these use lead-compensated cell-side voltage for the 20 Ah and board-side for the 32700s (whose short leads made the distinction negligible).

### Verdict & what it means for the uplights

The label is honest and the cell is excellent — 97% delivered, and a knee so tight that essentially everything above the firmware floor is usable. For the 24 uplights + 16 chandelier fixtures (solar-free), one cell supports 6 h/night × 7 nights at ~450 mA average battery draw — showable RGBW brightness — with margin, no mid-week charging. White-die-heavy palettes (~150 mA) make the week trivial; saturated color is what to budget. Requirements: daytime sleep must verifiably engage (ADR 0023 watchdog rule) and night radio duty-cycle budgeted (~40 mA average ≈ 1.7 Ah/week).

Caveats, honestly: n=1 (second sample on hand — qualify it before the ~40-cell order); warm-room data (~80 °F; playa nights are cooler — a few % derate); capacity measured through compensated 0.263 Ω clip leads (R verified against a DMM at the cell caps; drift over 27 h is the main residual uncertainty, biasing the usable-above-floor split slightly, not the total). Production fixtures need a real connection method for these end-cap protrusions — alligator clips survived 27 h only because they were taped down and nobody breathed on them.

## Method notes beyond the 07-06 report

- On-board charging as instrumentation: the cell doesn't fit any charger on hand, so the BQ25628E charged it through the same INA — giving a charge-side coulomb count (6.03 Ah in), a free polarity check, and the input-limit staircase in the chart above.
- Lead compensation: path R measured live (DMM at cell caps vs board reading at known current): 0.263 Ω. All cell-side numbers use cell_v = board_v + I(t)×0.263 with I logged continuously. Cutoff was set at 2.40 V board-side to land ≈2.5 V cell-side at tail currents.
- SDK gotcha found: the PowerFeather SDK's MAX17260 driver caps DesignCap at 16,383 mAh (20 mΩ sense assumption) — Board.init(20000) fails silently into retry purgatory. Gauge configured at 16,000; SOC advisory as always, current unaffected.
- Gauge cold-POR gotcha reconfirmed twice more (post-rattle boots at ~2.4–2.8 V cell) — looks like no-cell, self-heals on precharge. POWERFEATHER_NOTES.

## Appendix — instrument plot

20Ah cycle 1: gauge vs INA coulomb plots from afk_analyze

20 Ah cycle 1. afk_analyze gauge-vs-INA view: 1,634.9 min, 19,414 mAh INA / 20,809 mAh gauge (bias ×1.071, 9th consecutive replication of the +8±1% family), n=5,525 samples.

Data: ops/bench/data/ca/2026-07-11-discharge-20ah-cycle1.jsonl · charge stream 2026-07-10-ina-20ah.log.gz · prior report BATTERY_32700_SHOOTOUT_REPORT_2026-07-06.html

Ben Eckart with Claude (Fable 5) · report generated 2026-07-12

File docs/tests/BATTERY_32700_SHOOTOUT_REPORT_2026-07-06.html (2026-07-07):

Resonance Lighting · Bench Report · 2026-07-06

# The 7,200 mAh that wasn’t

Two 32700 LFP cells, one lantern load, coulomb-counted to the knee. The $5.10 cell that claims 6 Ah delivers 96% of its label. The pricier Amazon cell that claims 7.2 Ah delivers 78% — and loses where it actually matters.

DUTs fullbattery.com 6Ah (“F”) · Palowextra 7.2Ah (“P”), both virgin load HEX37 SK6812 white val224 truth INA219 @ 10mΩ, battery lead cutoff 2.50V under load ambient 79.9°F boards PowerFeather V2 9E5B0C / 9E5AF0

F delivered

5,752 mAh

96% of label · reproduces June’s 5,726 (+0.5%)

P delivered

5,643 mAh

✕ 78% of label · 1,557 mAh short of claim

Usable above 3.0 V

−15.5%

P vs F over the lantern’s operating floor

Cost per usable Ah

$0.99 vs $1.40

F wins by 41% — and P costs ~$1 more per cell

## The money shot: where the knee sits

To a 2.5 V lab cutoff the two cells nearly tie. But the lantern firmware floors live at 2.9–3.18 V — and P’s 2.3× internal resistance drags its knee through that band 1.4 hours earlier. Everything below the shaded band is capacity the product never sees.

### Battery voltage under load vs energy delivered

Gauge battery_v (V, under ~0.8–1.0 A load) against the INA coulomb integral (mAh). Hover for values.

F — fullbattery 6 AhP — Palowextra “7.2 Ah”

### Claimed vs delivered

Label claim (outline) against INA-measured delivery to the 2.5 V cutoff and above the 3.0 V product floor.

### Battery current over the run

P’s rig drew harder throughout (constant-power load on a saggier cell) and it still died 39 minutes sooner. The end-of-run spikes are both boards brownout-cycling below ~2.6 V — far under the product floor.

FP

## Results

Metric | F — fullbattery | P — Palowextra
Label / price | 6,000 mAh · $5.10 | 7,200 mAh · ~$6.10
Delivered to 2.5 V (INA) | 5,752 mAh (95.9%) | 5,643 mAh (78.4%)
Delivered above 3.0 V floor | 5,139 mAh | 4,342 mAh
Fell through 3.0 V at | 6.19 h | 4.83 h
Run duration to cutoff | 7.09 h | 6.43 h
Internal resistance (UMS4) | 60 mΩ | 136 mΩ
Weight | 138 g | 136 g
Rested full voltage | 3.575 V | 3.581 V
Brownout resets (all below ~2.6 V) | 31 | 35
Gauge/INA current bias | +9.3% | +8.1%
$ / Ah to 2.5 V | $0.89 | $1.08
$ / usable Ah (≥3.0 V) | $0.99 | $1.40

## How P lost

The label was never plausible. At 136 g, P weighs the same as a genuine 6 Ah cell — a genuine 7.2 Ah in this format would need ~20% more energy per gram than a cell that already measures at 95% of its rating, which is not a thing LFP does. The busted label was corroborated three independent ways before the discharge even finished: weight parity, 2.3× internal resistance on the charger’s IR readout, and Off-Grid Garage’s cycler test of the same cell (5,450 mAh — within 3.4% of our 5,643 despite a completely different load profile).

The subtler finding is where it loses. Down to a 2.5 V lab cutoff, P delivers a near-tie (−1.9%). But capacity below ~2.9 V is fictional for this product — the lantern firmware floors at 2.9–3.18 V to protect the cell and the rail. P’s high internal resistance pulls its voltage-under-load through the 3.0 V floor at 4.83 h against F’s 6.19 h, surrendering 15.5% of product-usable capacity. High IR converts label mAh into heat and an early knee.

### Verdict

Buy the fullbattery 6 Ah. Skip the Palowextra. P delivers 15.5% less usable capacity at ~$1 more per cell — $1.40 per usable Ah against F’s $0.99. There is no price at parity that rescues a worse cell with a fake label from an unaccountable supplier.

The planned cycle-2 rig swap is deliberately skipped: the rig confound is worth at most ~8% on load current, the observed usable-capacity gap is 15.5% in the other cell’s favor, and three independent corroborations point the same direction. Remaining caveats, stated honestly: n=1 per cell, single temperature (79.9 °F), and P ran on the slightly hungrier rig. None of them is anywhere near large enough to flip the decision.

## What we got for free

- The production cell is now qualified at n=2. This F delivered 5,752 mAh against June 11’s 5,726 from a different cell, board, and day — a +0.5% reproduction. The 75-unit purchase stands validated at $0.89/delivered-Ah.
- The fuel-gauge current bias is a chip trait, not a board quirk. The MAX17260 read +9.3% and +8.1% high on two different boards tonight — the 7th and 8th consecutive replications of the +8±1% bias. Treat /1.08 as a universal correction.
- Both cells end in a brownout rattle below ~2.6 V (31 and 35 resets) — a state-difference artifact we initially misread as a P-only failure mode. It lives far below the product floor and is informational only.
- Gauge SOC swept 98→0% on both cells while the plateau kept it useless in between — one more confirmation that LFP state-of-charge must come from coulomb counting, not voltage.

## Method, briefly

Both boards ran identical firmware (power_bench, NeoHEX 37px white val224, charging disabled, battery floor lowered to 2.3 V) and were charged only on a Nitecore UMS4 LFP profile — no USB touched either board mid-run, the confound that invalidated a previous soak integral. Ground truth is a 4-channel INA219 monitor (10 mΩ shunts) on a standalone KB2040, one channel high-side in each battery lead and each LED line; a serial-tee (ina_logger.py) let both afk_discharge.py instances share the monitor. Runs sampled every 10 s, integrating INA current (truth) and gauge current (cross-check) to a 2.5 V under-load cutoff, two consecutive samples required.

Before the runs, a green-pulse diagnostic (ina_mapcheck.py) verified every INA channel’s rig assignment and shunt polarity against two references — it caught three reversed shunts and one crossed rig-label in the rat’s nest before they could touch the data. Re-integration by afk_analyze.py matches the live integrals within ~2 mAh; corrupt-but-parseable INA samples (the June failure mode) were filtered at ingest. One known artifact: INA bus_v reads ~0.16 V low with battery-only rigs (floating ground reference through the QT chain); all voltage decisions used the gauge’s reading.

## Appendix — instrument plots

F cycle 1: gauge vs INA power and coulomb plots from afk_analyze

F — fullbattery 6 Ah, cycle 1. afk_analyze gauge-vs-INA view: 425.5 min, 5,752 mAh INA / 6,271 mAh gauge (bias +9.3%), SOC 98→0%.

P cycle 1: gauge vs INA power and coulomb plots from afk_analyze

P — Palowextra “7.2 Ah”, cycle 1. afk_analyze gauge-vs-INA view: 385.9 min, 5,643 mAh INA / 6,084 mAh gauge (bias +8.1%), SOC 98→0%.

Data: ops/bench/data/ca/2026-07-06-discharge-{F,P}-cycle1.jsonl · raw INA stream 2026-07-06-ina.log.gz · commits 3668554 (tooling), 3932434 (data)

Protocol & running log: docs/tests/BATTERY_32700_SHOOTOUT_PLAN_2026-07.md · Ben Eckart with Claude (Fable 5) · report generated 2026-07-06

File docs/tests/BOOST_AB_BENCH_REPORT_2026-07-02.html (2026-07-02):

# Does a 4.2 V boost converter earn its place in the lantern? Bench report: LED supply-voltage A/B campaign, 2026-07-02

Ben Eckart + Claude (pair bench session), Oakland desk rig. 52 logged runs across 32 data files (ops/bench/data/boost_ab/). Figures regenerate via ops/bench/report_figs_boost_ab.py. Written for readers who did not sit through the session: terms are spelled out, and every claim carries an evidence grade (see "How to read this report").

## TL;DR

- For the 37-pixel HEX board in its gobo role (one white pixel): the boost is not worth it. It adds 60% more electrical power for a light increase we could not distinguish from zero (≤2%, inside measurement noise). Verified by four back-and-forth hardware swaps.
- For the 4 W RGBW point source, the boost genuinely works -- it roughly 2.3x's the clean white output (448→1016 lux) -- but it costs roughly a quarter to a third of the light-per-watt, and the un-boosted module was already judged bright enough by eye. Decision: ship without the boost; the option is fully characterized if the field test at height ever demands more white.
- The biggest practical discovery wasn't the boost at all: it's the wiring. Feeding the RGBW straight from the battery over decent-gauge wire beat the board's 3.3 V regulated output by +33% on full white (1746 vs 1310 lux) -- for free. Every "collapse" we chased all day traced to power delivery (a regulator limit, damaged connectors, thin wires), never to the LEDs or the boost itself.
- Two instrument gotchas were caught, diagnosed, and fenced off: a firmware gamma setting that silently re-enables itself after a reboot (contaminated exactly 2 of 32 files, verified exhaustively), and current readings that are untrustworthy at partial brightness (light readings stayed trustworthy throughout).

## 0. How to read this report

Every substantive claim is graded. The day itself demonstrated why this matters: two confident mid-session explanations (a "loose sensor cable", a "+27% boost improvement") were later overturned by our own data. Grades used:

Grade | Meaning
REPLICATED | Measured multiple times, across hardware swaps or independent runs, with agreement. As close to fact as this bench gets.
MEASURED ONCE | A clean, direct measurement, but from a single run or mount. Could shift with repetition.
STRONG EVIDENCE | Multiple independent observations point the same way, but at least one alternative explanation is not fully excluded.
HYPOTHESIS | A plausible mechanism consistent with the data; could be disproven by a test we have not run.
OPEN | Unknown; a defined test exists but has not been run.

Mini-glossary. Lux: light intensity as the human eye weighs it, measured here by a photopic sensor at a fixed position -- absolute values are specific to this rig; ratios are the portable result. Boost converter: a small circuit that raises voltage (here a TPS63802 module set to 4.2 V). VBAT: the battery's own terminal, ~3.2-3.3 V for our LiFePO4 cells. 3.3 V rail: the PowerFeather's regulated output (a buck-boost converter fed from the battery); it also powers the ESP32 processor. Starvation / dropout: addressable LEDs contain per-color constant-current drivers; if the supply voltage is too low for a color's forward voltage plus driver headroom, that color runs below its regulated current and dims -- blue and white suffer first, red last (this is the "goldening" seen in June). Brightness (0-255): the commanded dimming level; light should scale linearly with it.

## 1. The question

We can buy TPS63802 boost modules pre-jumpered to 4.2 V. 4.2 V is the sweet spot because the LEDs' data-input threshold is 0.7 x supply: at 4.2 V a 3.3 V logic signal still clears it (2.94 V threshold); at 5 V it would not (3.5 V threshold) REPLICATED -- every boosted configuration ran all day with direct 3.3 V data.

"Worth it" was defined three ways before testing: (A) worth the per-fixture installation effort, (B) a visually noticeable gain in brightness or color accuracy, (C) better efficiency in light per watt.

## 2. The rig

Desk harness: an upside-down 3D-printed lantern prototype forms a cylindrical tube; the LED under test sits beneath it, and a VEML7700 photopic light sensor is taped at the tube exit ~6 inches away. LEDs are driven by a PowerFeather V2 running the led_studio firmware (web UI at http://ledstudio.local/, battery-only). Power was measured by two INA219-based wattmeters read by a KB2040 microcontroller streaming over USB; light and power land in one timestamped log. Capture tools: boost_ab_log.py / boost_ab_suite.sh (HEX), rgbw_boost_ramp.py (RGBW brightness ladders with automatic supply-collapse aborts).

Repeatability of the rig itself REPLICATED: across careful hardware swaps, electrical readings reproduced to ~1 mA and the HEX optical readings to 1-2%. The one caveat: the RGBW point source has (at least) two quasi-stable seating positions roughly 27% apart in measured lux STRONG EVIDENCE -- absolute lux numbers carry that uncertainty across re-mountings; within-mount comparisons do not.

## 3. Part one: the HEX board (37-pixel RGB, close-range glow + gobo)

Product constraint that frames everything: more than one full-white pixel washes out the gobo projection, so the production operating point is a single white pixel (or color-separated single pixels carrying the same total load).

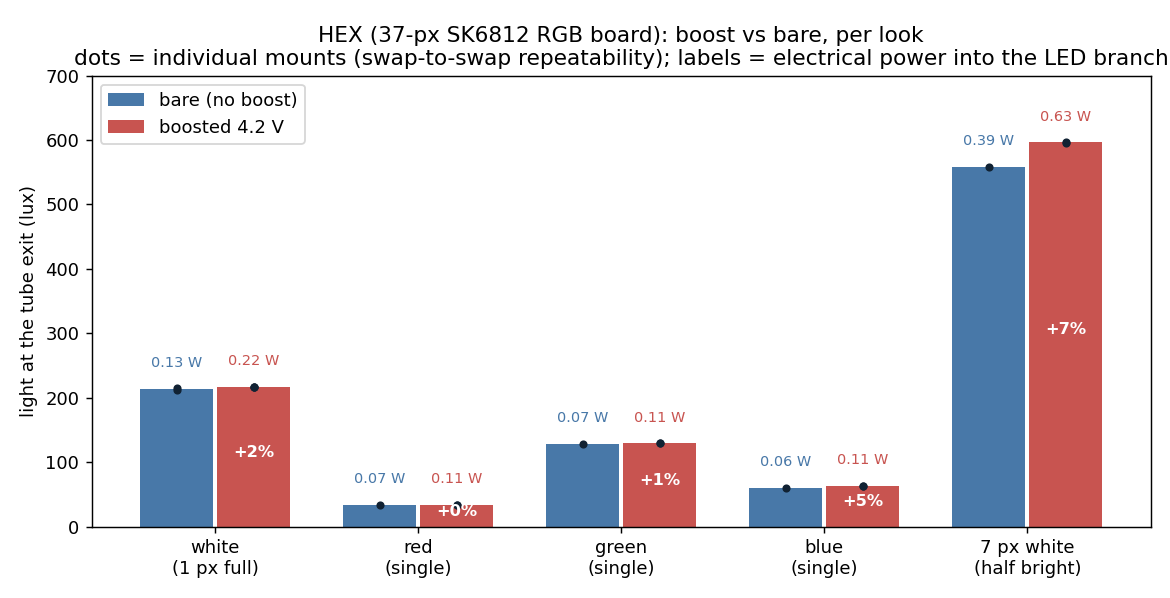
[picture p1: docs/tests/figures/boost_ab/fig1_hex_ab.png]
HEX bare vs boosted by look


Figure 1. HEX light output, bare vs boosted, per look. Dots are individual mounts from the bare/boosted/bare/boosted swap series; the red/green single-color looks act as built-in null controls (physics predicts no gain there, and none was seen -- which validates the harness). Power labels are watts into the LED branch at the measurement plane described in section 5.

Findings:

- Single white pixel: +60% electrical power, ≤2% more light (inside the ±2% seating noise), so light-per-watt is ~40% worse boosted. REPLICATED (4 mounts, null controls).
- The boost's gain grows with load: +5% on the blue single (highest forward voltage, first to starve), +7% on 7 pixels at half brightness -- both above the noise floor. REPLICATED. This is the dropout physics announcing itself: the effect is real, the production look just doesn't operate where it pays.
- Why a single pixel doesn't benefit: at a healthy battery the LED supply sits around 3.2 V and the pixel's internal current regulators are already at (or near) full current; extra voltage headroom becomes heat inside the pixel's driver transistors, not photons. STRONG EVIDENCE (the current/power/light accounting closes; not instrumented inside the pixel).
- June's "goldening" (warm, blue-starved white under heavy loads) is consistent with this: the June discharge data shows the LED supply really did sit at ~2.97 V at ~290 mA show loads -- measured at the LED, both battery and LED nodes were recorded. MEASURED ONCE (one recorded discharge).

HEX verdict: skip the boost. (A) not justified; (B) no visible difference at the production look; (C) clearly worse. One caveat keeps a small door open: all HEX tests ran at healthy charge. Because the LED feed is regulated, low state of charge should change nothing until deep discharge STRONG EVIDENCE, but a ten-minute spot check on a run-down battery OPEN would close it.

## 4. Part two: the RGBW 4 W point source (long-throw crisp gobo)

A single high-power addressable LED with four separate emitters: red, green, blue, and a phosphor white ("W"). Two white looks exist: W-only (clean, no color fringing) and R+G+B all on (much brighter, but the three colored emitters sit millimeters apart so their beams fringe at the edges of a projection).

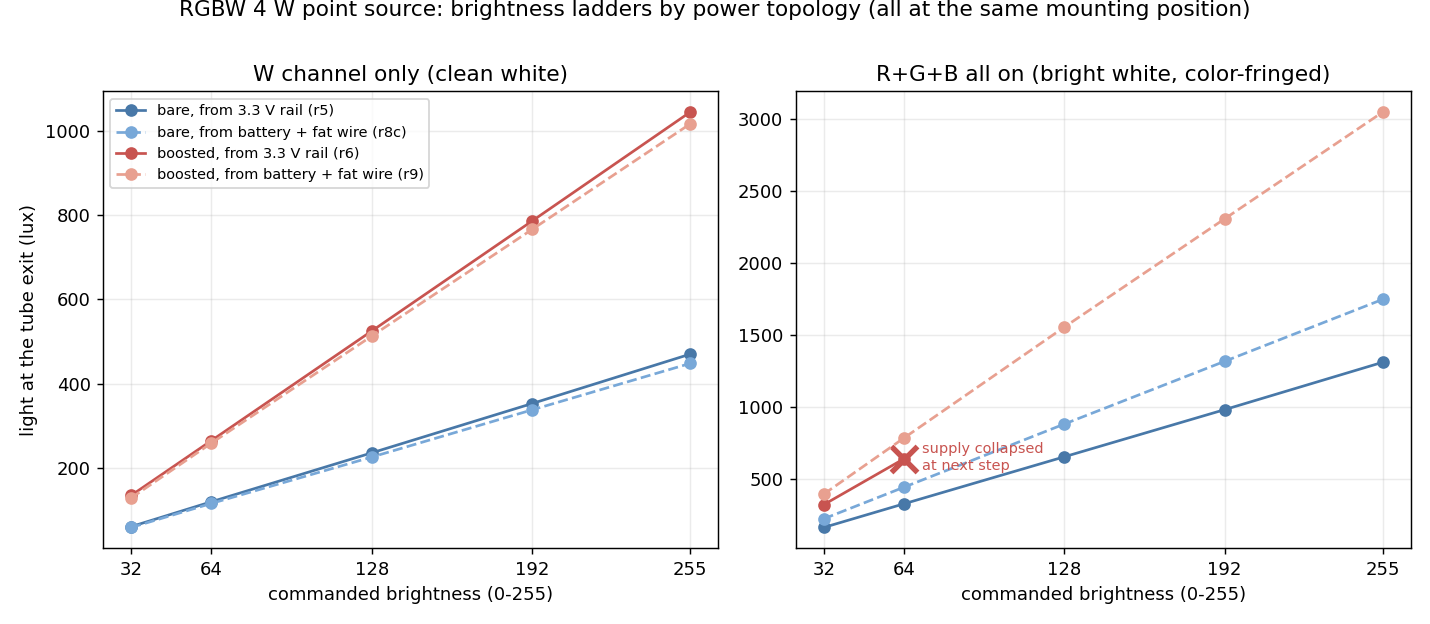
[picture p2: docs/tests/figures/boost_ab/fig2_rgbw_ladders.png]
RGBW brightness ladders


Figure 2. Light vs commanded brightness for four power topologies, all at the same mounting position. Left: the W (clean white) channel. Right: R+G+B. All ladders are linear -- dimming behaves -- and the boost roughly doubles the W channel everywhere. The X marks where the rail-fed boosted configuration collapsed its supply.

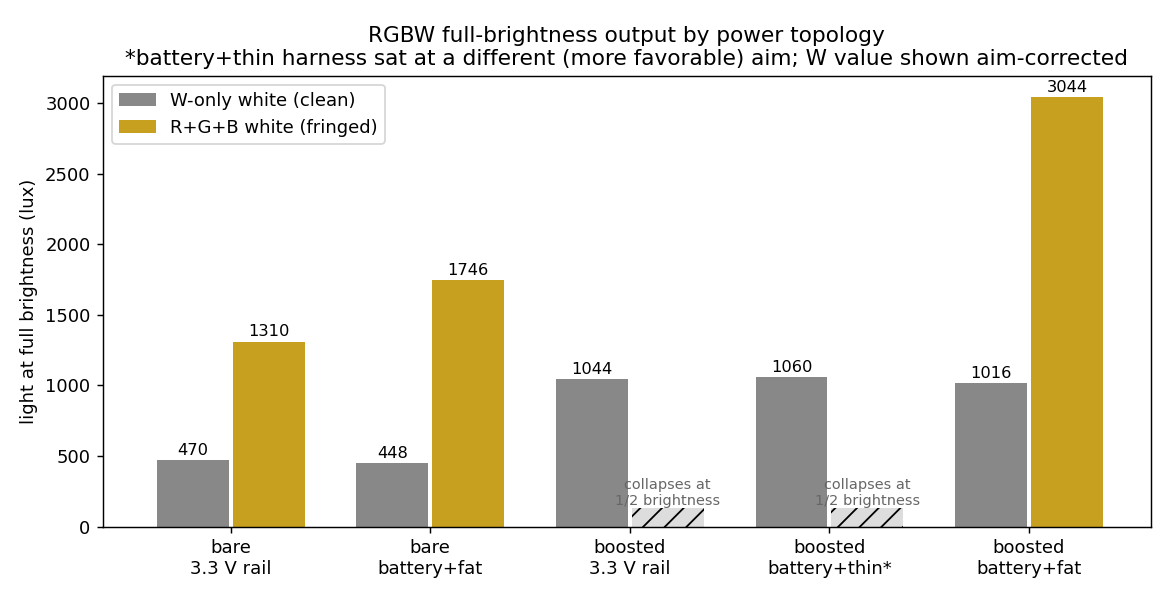
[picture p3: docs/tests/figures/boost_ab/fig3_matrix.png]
RGBW full brightness matrix


Figure 3. The completed topology matrix at full brightness. "Fat" = larger-gauge JST-XH wiring; "thin" = the original instrumented harness with small jumper wires.

Findings, in the order they matter:

- The W emitter is severely current-starved at ~3.3 V. Un-boosted it passes roughly a quarter of its boosted current; the boost takes clean white from 448-470 to 1016-1060 lux (~2.3x). REPLICATED (four un-boosted and three boosted measurements across mounts and both feed topologies, agreeing within a few percent once the known aim outlier is corrected).
- Feeding the LED straight from the battery beats the 3.3 V rail by +33% on R+G+B white (1746 vs 1310 lux at the same seating) -- the rail droops under load, the battery doesn't. W-only is unchanged (equally starved either way). MEASURED ONCE, but anchored: the W channel matched across the two runs, pinning the seating.
- Every supply collapse was a delivery problem, not an architecture problem. Rail-fed boosted R+G+B collapsed at half brightness three separate times REPLICATED (the rail is roughly 1 A limited); battery-fed boosted through the thin instrumented harness collapsed the same way (~0.3 ohm of loop resistance, measured from load-dependent sag MEASURED ONCE); battery-fed over proper wire ran everything to full with ~100 mV of battery sag at an estimated 1.3-1.4 A REPLICATED (bare and boosted runs).
- Boosted + battery + proper wire delivers the module's full capability: 3044 lux of R+G+B white, 1.74x the un-boosted maximum -- and this landed inside the prediction band written down before the run. MEASURED ONCE.
- The processor is immune to LED-side trouble when the LED feeds from the battery: during an intentional LED-branch collapse the board's own supply current never moved (a dead-constant 116-118 mA) and it kept serving its web interface. STRONG EVIDENCE (one clean collapse event, unambiguous). This retires an old worry that radio bursts plus LED load could brown out the controller -- for this topology.

RGBW verdict: ship un-boosted, feed the LED from the battery, use decent wire. The eye test judged un-boosted R+G+B white "plenty bright" (1746 lux at the bench). The boost is shelved with a complete option file: if the field test at real projection distance ever demands ~2.3x the clean white, the production shape is a battery-fed single-conversion boost on the adapter board with a proper enable pin.

## 5. Efficiency (light per watt)

One accounting subtlety, learned mid-session: watts were measured at two different places. "Rail plane" = into the LED branch after the board's 3.3 V converter (its ~10% loss not included); "battery plane" = true battery draw. Comparing across planes without correcting is how one of the day's predictions initially looked wrong.

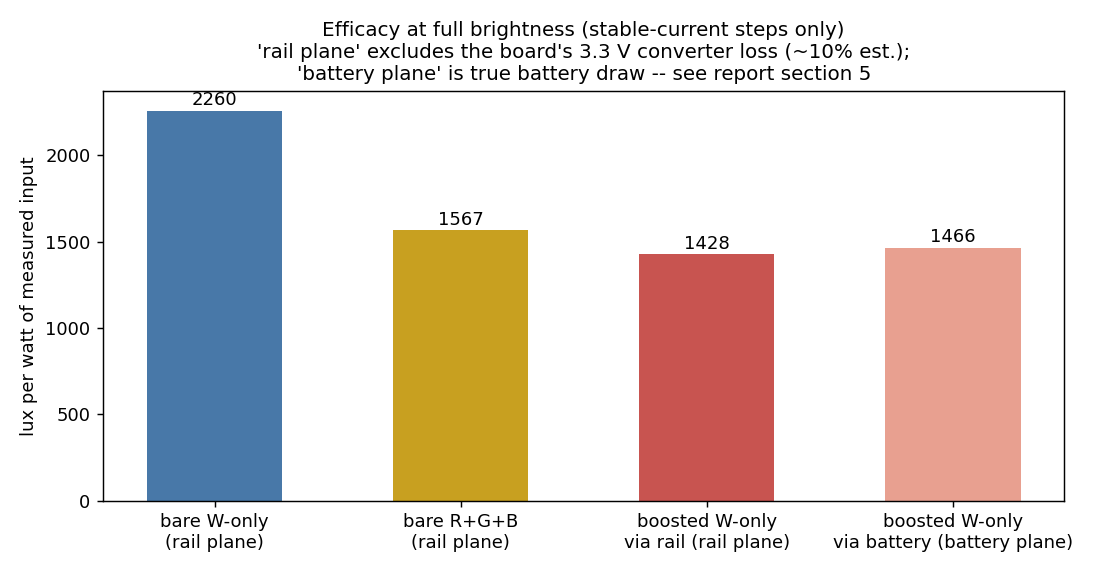
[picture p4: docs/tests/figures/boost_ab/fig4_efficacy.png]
Efficacy comparison


Figure 4. Light per watt at full brightness -- only from steps with stable current readings (see section 6). The boost consistently trades efficiency for output ceiling.

- Boost efficiency cost on clean white: ~37% via the rail (double conversion), and roughly 25-30% when fed from the battery (single conversion, ~11% battery-side saving vs the rail-fed path at matched output). MEASURED ONCE each, consistent with converter physics.
- W-only vs R+G+B white efficacy, un-boosted at full: ~2260 vs ~1570 lux/W (about 1.4x in W's favor). MEASURED ONCE. Correction to a mid-session claim: an earlier "phosphor white is 3x more efficient than RGB white" figure was computed from current readings later shown unreliable; the defensible number is the 1.4x above, and the boosted R+G+B efficacy was never cleanly measured (its only stable steps were behind the collapse).
- ESP32 + radio overhead while driving the bench: 116-118 mA, measured cleanly as the isolated board branch. MEASURED ONCE (but dead flat across ten steps).
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

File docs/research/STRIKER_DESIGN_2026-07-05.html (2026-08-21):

Lantern tree · daytime sound element

# An external mallet striker for the bamboo lanterns

Design notes on the solenoid-driven bell-crank percussion mechanism — geometry, dynamics, materials, and the reasoning behind each choice.

Ben → Dad · compiled 15 July 2026 · rev A · companion hardware: JF-0530B/0730B-class solenoid, Adafruit 5648 driver, ESP32-S3 PowerFeather

## 1 · What this thing is

The lantern tree carries roughly 150 nodes. Each node is a small solar panel sitting on top of a COTS enclosure (the “hat”), which in turn caps a length of bamboo tube about 2.5″ in outside diameter and 6″ long. At night the node is a projector: a 4 W RGBW LED shines down the tube through a 2.35″ gobo at the tube’s end, casting patterns on the playa. By day the LED show is invisible, so the day-mode identity of the tree is sound: each node becomes a percussion voice in a distributed “cricket chorus,” coordinated over an ESP-NOW mesh. The mechanism described here is that voice — a solenoid-driven
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

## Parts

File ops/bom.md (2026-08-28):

# BOM -- Fleet Bill of Materials vs Real Orders

**Status:** Updated 2026-08-08 against the Nevada City production layout. Fixture counts MIRROR the
canonical fleet table in `docs/block-diagram/SYSTEM.md` -- when counts change, update
SYSTEM.md first, then this file. Order dates, costs, and statuses live in
`ops/PROCUREMENT.md`. Current allocation: ADR 0032.

## Shared core (every fixture class)

| Item | Per fixture | Source / status | Notes |
|---|---|---|---|
| PowerFeather V2 (ESP32-S3) | 1 | Elecrow, 68 at Steve's + 90 ordered 07-09 (in transit) | ADR 0024. The controller, charger (BQ25628E), gauge (MAX17260), buck-boost, telemetry, USB-C. |
| Battery cell -- LARGE-enclosure fixtures (downlights) | 1 | **33140 LiFePO4 15 Ah, batteryhookup.com, 130 bought 07-24** (10 TN + 120 CA) | ADR 0025 annotation: new fleet standard for the large hats; QUALIFICATION PENDING (capacity/IR run + ADR 0023 threshold re-map on the new cell). |
| Battery cell -- SMALL-enclosure classes + chandelier | 1 | 32700 LiFePO4 6 Ah, fullbattery.com, 175 bought | ADR 0025. The only cell that fits the small enclosure; qualified n=2. |
| Battery lead / retention | 1 | XH cabling BOUGHT ~07-12/13 (abundance, multiple lengths) | Keyed, vibration-tolerant; no per-unit crimping (ADR 0009). Final lengths chosen at integration from the on-hand variety. |
| LED harness | 1 | XH cabling BOUGHT ~07-12/13 (same abundance; incl. 160x 5-pin Y-splitters) | RGBW feed DECIDED rail-fed (ADR 0029 amendment 2026-07-11): one harness + one pinout for both LED roles. |
| Waterproof USB-C panel-mount rescue port | 1 | Adafruit, 150 bought 07-10 | Extension cable from the PowerFeather USB-C to a gasketed panel-mount port on EVERY hat -- USB rescue/charging without opening the enclosure; solar-free classes charge through it. |
| Hat enclosure + fasteners | 1 | **BOUGHT 07-13: 172x Polycase enclosures + screws** (111 large + 61 small, incl. 2 transparent-lid demo units) | Large = **Polycase ML-70F\*15** (10x7x4 in) -> 72 downlight hats; small = **Polycase HN-57-03** (NEMA 4x, 6.7x5x3 in) -> 24 perimeter hats and candidate trunk-light enclosures. Panel flush with the lid (raised a few mm for the DC-cable bump); light + ToF flush with the bottom. Steve owns mechanical integration. Chandelier lights get a carpenter-built box (team-side). |
| Firmware | one image | this repo | Runtime/NVS config only; no per-unit builds (ADR 0009). |

## Per-class additions

### Hanging downlight x72 (7-10 ft, gobo projection)

| Item | Per fixture | Source / status |
|---|---|---|
| 4 W RGBW warm white (point source) | 1 | from the 150-RGBW pool |
| Gobo / patterned filter | 1 | Steve print program (in-house + generative bamboo-leaf patterns) |
| Voltaic P105-class 5 W panel + 3.5x11 mm pigtail | 1 + 1 | Voltaic, 110 panels + 160 pigtails bought |
| TMF8820-mini ToF, facing downward | 1 | SparkFun, 100 bought (bench-validated on same-family TMF8821) |
| MSA311 accel + STEMMA cable | 1 + 1-2 | Adafruit, 150 accels + 250 cables bought |
| BMP581 temp + barometric pressure | 1 on outermost ring; 0 on other rings | Adafruit, 30 bought 07-16: 24 outer-ring installs + 6 spares (ADR 0034) |

### Perimeter x24 (5 ft shepherd hooks; all HEX)

| Item | Per fixture | Source / status |
|---|---|---|
| SK6812 HEX | 1 | M5Stack, 90 bought (70+20; plus 20 NeoHEX fallback units) |
| Gobo / patterned filter ("dancing gobo") | 1 | Steve print program -- stepping the single lit HEX pixel around the board shifts the apparent pattern on the ground (corrected 07-27: perimeter DOES carry a gobo) |
| Grove/HY2.0 breakout (HEX connector adaptation) | 1 | 125 bought: 70x RobotShop 06-18 (at Steve's) + 55x Electromaker 07-10 |
| Voltaic P126-class 2 W panel + pigtail | 1 + 1 | Voltaic, 50 panels bought |
| VL53L5CX ToF, facing outward + protective cover | 1 + 1 | Mouser 48 + Gilisymo 60 covers bought |
| MSA311 accel + STEMMA cable (likely) | 1 + 1 | from the 150-accel pool |
| Shepherd hook | 1 | project-side sourcing, outside this electronics BOM |

### Trunk light x20 manufactured (about 16 target installed; no gobo)

| Item | Per fixture | Source / status |
|---|---|---|
| LED | 1 | Production direction is 4 W RGBW from the 150-unit pool; a smaller lensed 3 W RGB variant is under test for extra throw (ADR 0032). |
| Power source | 1 | Final trunk arrangement is being integrated in Nevada City. The 32700 6 Ah cell, small enclosures, P105 panels, and USB-C ports are available; lock the combination after the LED/throw test. |
| Gasketed panel-mount USB-C port | 1 | from the 150-port pool (bought 07-10; now a shared-core item) |
| Enclosure + mount | 1 | Candidate small Polycase from the 61-unit pool; final trunk mounting and optic protection are open. |

### Chandelier x18 (central cluster; scope still loose)

| Item | Per fixture | Source / status |
|---|---|---|
| HEX or RGBW (mix TBD) | 1 | from the HEX/RGBW pools (RGBW spares cover any mix) |
| Power source | 1 | likely 6 Ah + USB-C top-ups, low-brightness budget (20 Ah option closed 07-15) |
| Housing | shared | carpenter-built box for the 18-light cluster (team carpenter; not this BOM) |
| Sensors | none (tentative) | |

## Fleet totals + spares math (needed at nominally 130 vs bought)

| Part | Needed | Bought | Margin | Flag |
|---|---|---|---|---|
| PowerFeather V2 | 130 | 158 (68 + 90 ordered 07-09) (+~8 bench: 5 Ben, 3 Steve) | +28 production | healthy -- contingency and field spares |
| 32700 6 Ah | about 58 (perimeter + trunk + chandelier, if all use it) | 175 | about +117 | huge margin -- downlights moved to the 33140 |
| 33140 15 Ah | 72 downlights | 130 | +58 | qualification pending: capacity/IR + ADR 0023 threshold re-map |
| 4 W RGBW | 88-106 (72 downlights + up to 16 trunk + 0-18 chandelier) | 150 (100 + 50 ordered 07-10) | +44..+62 | healthy; the 3 W trunk trial may reduce need further |
| SK6812 HEX | 24-42 (24 perimeter + 0-18 chandelier) | 90 (+20 NeoHEX fallback) | +48..+66 | healthy |
| P105 5 W panel | 72-88 (72 downlights + up to 16 trunk, pending integration) | 110 | +22..+38 | healthy; trunk power choice open |
| P126 2 W panel | 24 | 50 | +26 | healthy |
| DC pigtails | 96-112 deployed panels (depending on trunk power) | 160 | +48..+64 | healthy |
| MSA311 | 96-112 (downlight + perimeter; trunk allocation TBD) | 150 | +38..+54 | healthy |
| TMF8820-mini | 72 | 100 | +28 | healthy |
| VL53L5CX | 24 | 48 | +24 | healthy |
| ToF protective covers | 24 | 60 | +36 | healthy |
| STEMMA cables | ~150-250 uses | 250 | ok | |
| USB-C panel-mount rescue ports | 130 (one per fixture) | 150 ordered 07-10 | +20 | universal rescue/charge port |
| Grove/HY2.0 breakouts | 24-42 (HEX fixtures incl. chandelier share) | 125 (70 + 55) | +83..+101 | healthy |
| Pre-crimped XH cables | ~2-4 per fixture | ~2,100+ pieces + 160 Y-splitters across lengths/colors | abundant | deliberate lead-time hedge; lengths chosen at integration |
| Enclosure, LARGE | 72 downlights | 111 (incl. 1 transparent-lid demo) | +39 | healthy |
| Enclosure, SMALL | about 40 (24 perimeter + about 16 trunk, if all trunk lights use it) | 61 (incl. 1 transparent-lid demo) | about +21 | healthy; final trunk enclosure choice open |
| ~~20 Ah LFP~~ | 0 | 2 samples (verified honest: 19,412 mAh) | -- | CANCELLED 07-15 on sourcing/timeline; Alibaba ~$4.50/cell = 2027 lead |
| MOSFET drivers (solarnoid) | downlights only, <=110 (large hats -- the solarnoid needs the space; scope settled ~07-24) | 160 (110 + 50) | +50 and likely more at 72 planned | surplus acknowledged |
| Solenoids (push-pull) | downlights only, <=110 | 150 in transit (75x 3 V + 75x 5 V) -- MAY BE RETURNED | -- | bake-off trending STRONGER (0730B 6 V/1 A primary); "solarnoid" design finalized ~07-24, mallet and all |
| Solarnoid mallets | <=110 (downlights) | craft store, bulk, very cheap (order details TBC) | -- | part of the finalized solarnoid design |
| GPS (SAM-M8Q) / RTC (DS3231) timing modules | experiment | 4 + 4 bought 07-20 | -- | dusk/dawn + sleep scheduling experiments; GPS doubles as a position anchor candidate |
| Strike caps (22,000 uF 16 V) | 1 per noisemaker fixture | 210 ordered 07-16 | abundant | VDC-tap strike storage; 22k uF = headroom for stronger solenoids; transients benign (VDC droop, reads like a passing cloud) |
| ~~Other noisemaker parts~~ | -- | 1x #3885 (damaged pot) + bench relays | -- | DECIDED 2026-07-15 (ADR 0030): solenoid bamboo-strike wins; speaker path abandoned (spares cancelled); relays/beeps not pursued |
| BMP581 env sensor | 24 outer-ring downlights | 30 ordered 07-16 | +6 | complete outer hanging ring + field spares (ADR 0034) |

Depth-sensor bookkeeping: the current allocation is 24x VL53L5CX + 72x
TMF8820-mini = 96 deployed sensors against production orders of 48 + 100. Bench
and sample units are additional.

## To-buy (summary -- live queue in ops/PROCUREMENT.md)

Remaining: trunk-light LED/optic, power, enclosure, and mounting hardware after
the lensed 3 W RGB comparison; solenoid driver control cables + mallet mounting
(strike caps ORDERED 07-16: 210x
22,000 uF 16 V; 5-pin XH Y-splitters already on hand for the VDC tap). CANCELLED 07-15:
the 20 Ah cells + end-caps (sourcing/timeline) and the spare #3885 speakers
(speaker path abandoned -- ADR 0030). DONE
since 07-08: 90 PowerFeathers (07-09), 100 MOSFET drivers + 150 solenoids
(07-10), 150 USB-C rescue ports + 50 RGBW (07-10), 125 Grove breakouts (06-18 +
07-10), XH cabling abundance + 172 Polycase enclosures (07-13).

## Open BOM inputs

- Trunk-light integration: compare 4 W RGBW with the smaller lensed 3 W RGB module,
  then lock power, mounting, enclosure, brightness, and sensor allocation.
- Small-enclosure allocation: 24 perimeter + about 16 trunk lights fits comfortably
  within the 61-unit pool if all trunk lights use the small box.
- Chandelier HEX/RGBW mix (RGBW spares now cover any split).
- Sensor allocation confirmation per class (ADR 0027 marks it tentative).
- USB-C port gasket/cutout approach per hat variant (part selected + bought 07-10;
  mechanical integration is Steve's).
- ~~RGBW feed decision~~ -- DECIDED rail-fed 2026-07-11 (ADR 0029 amendment); one
  harness + one pinout for both LED roles; the rail is the fail-safe kill.
- Harness/connector part numbers (JST-XH family).
- Solenoid strike-power source (VDC-tap + storage cap vs battery/VS pin) and
  noisemaker (solenoid, ADR 0030) scope per class -- drives the residual wiring buy.
- Spares policy for inventory beyond the nominal 130 deployed fixtures: build
  recovery, field replacement, and optional off-tree/camp use.
- Enclosure vendor/part details to record in the ledger (TBC); mechanical
  integration design (Steve): panel mount, bamboo clamp, USB-C gasket, ToF windows.
- Chandelier carpenter box: specs to coordinate (venting, access, USB charging
  reach for 18 fixtures).
- Shepherd-hook sourcing (project-side).

## Superseded

The 2026-06-17 "working procurement skeleton" version of this file (pre-purchase
Track A/B tables, costing guidance) is preserved in git history. Its two tracks
resolved to COTS production (ADR 0024); its open procurement inputs are either
executed (see `ops/PROCUREMENT.md`) or carried in the lists above. The still-useful
costing rule survives here:

```
total_cost = parts + shipping + spares + assembly labor + QA/rework allowance
ops_risk = solder joints + crimps + one-off configs + fragile connectors + field access
```

The winning BOM is the one that closes energy and reliability while keeping fleet
assembly boring.

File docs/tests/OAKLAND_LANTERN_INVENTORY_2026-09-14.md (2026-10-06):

# Oakland lantern inventory follow-up, 2026-09-14

Ben found a separate bin, physically far from the shipping container, and
brought it to Oakland: five canopy lanterns and one batteryless uplight with
its panel connected. Two older prototypes are also in the backyard; Ben thinks
the perimeter prototype is disconnected or batteryless. This gives eight
physical units, but enclosure-to-MAC mapping is not complete.

## Comparison with September 12

None of the five reported identities was in the 106 OTA/storage targets.
Kairi and Wooper were two of the eight unobserved members of the September 1
114-ID comparison roster. They are now accounted for by the Oakland sighting.
Groot, Kiki and prototype 9F26F8 were outside that 114-ID baseline.
Their present radio activity is not evidence that September 12 ship mode failed.
The other physical lanterns have not been identified, so they may overlap the
stored 106. The Nevada City radio census did not establish container location.

The six still-unlocated IDs from the September 12 missing list are Gambit
F2BCF4, Gengar F2BDD4, Magmar F2BDFC, Donkey F2BE10, Milotic F2BE94 and Skitty
F3FD28. This updates present whereabouts; it does not rewrite the original
106 receipts or the eight-ID historical absence record.

## Passive controller snapshot

Exact connected USB identity was TSwift 979604 / 44:1B:F6:97:96:04 on COM157.
A 22-second serial read at approximately 09:18 PDT sent no commands and closed
the port afterwards. No dashboard, logger or maintenance campaign was left
running. TSwift reports channel 11 and tdeck-dev-local, matching its older
controller lineage. The September 12 storage4 flash was on primary 8EB508,
not TSwift; do not assume the new Store/calendar UI is on this handheld.

| Callsign | ID | Last reported battery | Report age at snapshot | Reported firmware |
|---|---|---:|---:|---|
| Groot | 9F2724 | 2.880 V | 11.1 min | fx-260829-b0ff5db-b |
| Kairi | 9F26B4 | 3.303 V | 1.6 min | fx-260829-af1d4ec-p |
| Kiki | F2BF5C | 3.277 V | 13.6 min | fx-260828-658b7d2-p |
| Wooper | 9F0E30 | 3.321 V | 18 s | fx-260830-7ae6502-p |
| P105 prototype | 9F26F8 | 2.992 V | 10.0 min | net-bench-2026-07-14.1 |

These are retained last-listen reports, not five simultaneous fresh heartbeats
or cell-terminal measurements. All ages are shorter than the current TSwift
uptime. Groot, Kairi and Kiki report FIELD/PROTECT with a last 900-second sleep;
Wooper reports FIELD/NORMAL and 120 seconds. All four fixture LED rails report
off. Prototype 9F26F8 uses the older net-bench field-cycle schema.
Groot's low voltage despite a 99% SOC report reinforces that SOC is not a
standalone remaining-capacity diagnosis. Current hardware/cell condition and
charging paths have not been physically checked in this session.

The July outdoor bench record identifies 9F26F8 as the P105/4 W RGBW prototype,
and 9F2690 as the replacement P126/HEX prototype. 9F2690 is a historical lead
for the other backyard unit, not a confirmed present physical identity.

Evidence: `ops/bench/data/ca/20260914-091805-oakland-passive/`, including raw
serial records, snapshot, reconciliation and SHA-256 manifest. No firmware,
sleep, ship, reboot, NVS or charging-setting changes were made.

## Next service items

- Map the six newly found lantern enclosures and both prototypes to exact IDs.
- Check Groot's actual cell and charge path first given its 2.880 V report;
  inspect the old P105 prototype's 2.992 V report and present power setup.
- Treat Kairi/Wooper's older maintenance-discovery issues as service history,
  not evidence of dead cells; both now have radio reports above 3.3 V.
- Ben plans to leave these units out; no deliberate storage is requested.
  For any later firmware work, prepare exact targets and artifact identity.
  Batteryless solar-only uplight power is not a proven OTA/reboot supply.

## Operating intent and post-mortem plan, September 14 follow-up

Ben plans to keep the Oakland lanterns out and does not want deliberate sleep
or ship mode for this group. Leave the existing automatic power behavior in
place; this is not an instruction to force a continuously awake radio hold.
He may bring selected units inside for post-mortem analysis. No new device
command or firmware change was made for this discussion.

The approximately 3.3 V readings are consistent with preserved capacity but
cannot establish remaining Ah. LFP has a broad, flat voltage plateau; the
project's measured load/voltage dependence is in ADR 0023, and the chemistry's
SOC/OCV shape is illustrated in TI's LiFePO4 Design Considerations, section 2:
https://www.ti.com/lit/pdf/sluaar1 (checked 2026-09-14).

Kairi and Kiki report PROTECT, rails off and roughly 9-second boots between
900-second sleeps. With the measured-range planning assumption of 130 mA
awake, the radio component is 130 * 9 / (900 + 9) * 168 = 216.2 mAh/week.
That is 3.6% of a nominal 6 Ah cell or 1.44% of a nominal 15 Ah cell, before
sleep leakage and any other loads. Wooper's present 12/120-second cadence
would instead cost about 1,985.5 mAh/week in radio duty alone. Neither snapshot
reconstructs the full dark interval. Starting capacity, prior load history,
actual cell capacity and any sunlight since removal remain unknown. Do not
call 3.3 V 'full' or infer measured storage drain from this calculation.

Recommended first comparison: Groot (2.880 V) versus Kairi or Kiki (above
3.27 V but still PROTECT). Wooper is also useful for the old shared-WiFi
maintenance-discovery failure. The old 9F26F8 prototype should be analyzed
separately because its harness/firmware differ from production fixtures.

Before changing firmware, resetting guards or swapping batteries, retain
available revision, configuration, reset/sleep audit and charger/gauge state;
identify the actual cell/enclosure and measure terminal voltage. Then compare
loaded/relaxed voltage, actual sleep/listen current and charge-path behavior.
Preserve a flash/NVS backup where practical. Existing passive evidence already
captures the present radio-visible baseline; do not delay needed servicing
merely to obtain an untouched long-duration trace. Determine whether PROTECT
persisted appropriately without qualifying charging or whether an old firmware
path stranded capacity. A high rebound reading alone does not prove a bad latch.

## Twelve-hour radio sleep versus PROTECT; morning-sun correction

Ben clarified that it was about 09:23 and doubted meaningful solar recovery.
No retained measurement establishes meaningful post-storage solar charging.
Do not use morning sunlight as the explanation for the high-voltage units.
In the available listen samples, Kairi/Kiki/Wooper report negative battery
current and supply-good false; those instants do not reconstruct prior input.

Code trace: the existing T-Deck Rest deep-sleep choice invokes meshSleepAll
with 43200 seconds, emits NB_SLEEP_FOR, and the fixture calls
enterTimedDeepSleep with SLEEP_CAUSE_RADIO_ALL. It records the command, cuts
loads/rails and starts the timer. It does not write STAGE_PROTECT. An ordinary
ESP_RST_DEEPSLEEP wake is expected by boot_guard and preserves the existing
stage. This existing 12-hour UI is distinct from the multi-day transport packet
and the September 12 untimed USB-storage operation. A prior PROTECT latch
survives timed sleep; the command does not clear it either.

PROTECT is durable event history rather than a label recomputed from current
voltage. Default voltage entry is below 3.05 V after load compensation; reset
escalation and persistence fail-safe paths can also park a healthy-voltage
unit. The ordinary release requires 60 continuous seconds of qualified
charging at >=20 mA and compensated voltage >=3.25 V, with good supply and
enabled/no-fault charger state. The newer full/taper alternative uses >=3.45 V
plus additional evidence. Neither is a simple 'voltage now exceeds 3.25' rule.
Known older release-timing bugs also belong in the post-mortem, not a blanket
assumption that every retained latch is erroneous.

Concrete September 14 evidence:

- Wooper: 12-hour radio sleep retained from TSwift 979604, sequence 1759;
  now NORMAL at 3.321 V. No valid PROTECT-entry record was reported.
- Kairi: low-VBAT origin 1, entry reading 2.993 V, predecessor FULL,
  no load armed and no reset-origin event at that entry. Now PROTECT at
  3.303 V. No operator sleep command is present in its retained command slot.
- Kiki: PROTECT-entry reading 2.978 V, now PROTECT at 3.277 V; the older
  heartbeat lacks the detailed origin. It also retains a distinct 8-hour
  operator sleep from TSwift, sequence 40. This does not establish causality.
- Groot: low-VBAT origin 1, entry 2.976 V from DIM with load armed;
  now PROTECT at 2.880 V.

These records establish what firmware observed. They do not independently
prove the cell-terminal voltage or the cause of the dip. Voltage relaxation,
a load/transient/connection problem, or a faulty reading remain mechanisms to
separate; Kairi's unarmed entry does not support asserting an LED-load sag.
Capture exact state before guard resets and compare cell-terminal and reported
voltage under controlled conditions. No commands were sent for this analysis.

## Fleet recovery investigation

Ben clarified that unexpectedly reduced chiming occurred during the last days
at Burning Man. The broader cohort, source-fix comparison, offline recovery
reproduction and separate inspection-firmware chime veto are documented in
`PROTECT_RECOVERY_INVESTIGATION_2026-09-14.md`. This is the priority bench
follow-up; Oakland devices remain unchanged.

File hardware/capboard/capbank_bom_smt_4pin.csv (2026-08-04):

Comment | Designator | Footprint | JLCPCB Part #
470R 0805 1% | R1 | R0805 | C17710
330k 0805 1% | R2 | R0805 | C17629
10k 0805 1% | R3 | R0805 | C17414
47k 0805 1% | R4,R10,R11 | R0805 | C17713
6.8k 0805 1% | R5,R9 | R0805 | C17772
1k 0805 1% | R7 | R0805 | C17513
130k 0805 1% | R8 | R0805 | C2933305
10uF 16V X7R 1206 | C1,C7 | C1206 | C342827
1nF 50V 0805 | C5 | C0805 | C46653
22uF 16V X7R 1206 | C8 | C1206 | C5252682
10uF 25V X7R 1206 | C9 | C1206 | C6119987
BZX84C3V3 zener | D1 | SOT-23 | C19077467
SS34 schottky | D2 | SMA/DO-214AC | C8678
HT7550-1 LDO | U1 | SOT-89 | C16106
MT3608 boost | U2 | SOT-23-6 | C84817
22uH 2.4A shielded | L1 | SRN6045 6x6mm | C2849539
6x6 SMD tactile 2-pin | SW1 | 1TS009 6x6mm | C319428
JST S4B-XH-SM4-TB right-angle SMT 4p (pin4=GND) | PANEL,DRIVER | JST_XH_SM4_1x04_RA | C161861

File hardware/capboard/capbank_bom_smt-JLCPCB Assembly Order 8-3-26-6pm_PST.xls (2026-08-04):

JLCPCB BOM Tool - BOM Matching
BOM name：capbank_bom_smt-JLCPCB Assembly Order.xlsx |  |  | Download Time：2026-08-04 08:59:11 |  |  |  | * Our matching results are updated in real-time, but stock and prices may change. If it's been over 24 hours, please re-match before placing your order.
PCB Assembled Qty：10 |  |  | Est. Total Price：146.7956
Your BOM |  |  |  |  | Matched Parts |  |  |  |  |  |  | Order Information
Top Designator | Bottom Designator | Comment | Footprint | JLCPCB Part # | Matches | Part # | Manufacturer | Footprint | Description | Category | Warning | JLCPCB Part # | Product link | Lib Type | Qty | Source | Total Price ($)
C1,C7 |  | 10uF16VX7R(16Vample-sees6Vmax;doNOTaccept50V) | C1206 |  | Select by Customer | C3216X7R1C106KT000N | TDK | 1206 | 10uF 16V X7R ±10% 1206 Multilayer Ceramic Capacitors MLCC - SMD/SMT ROHS | Multilayer Ceramic Capacitors MLCC - SMD/SMT |  | C342827 | https://jlcpcb.com/partdetail/TDK-C3216X7R1C106KT000N/C342827 | Extended | 244 | 244 JLCPCB | 44.896
C5 |  | 1nF50V | C0805 |  | Select by System | CL21B102KBCNNNC | Samsung Electro-Mechanics | 0805 | 1nF 50V X7R ±10% 0805 Multilayer Ceramic Capacitors MLCC - SMD/SMT ROHS | Multilayer Ceramic Capacitors MLCC - SMD/SMT |  | C46653 | https://jlcpcb.com/partdetail/47657-CL21B102KBCNNNC/C46653 | Basic | 130 | 130 JLCPCB | 3.432
C8 |  | 22uF16VX7R(16Vample-sees6Vmax;doNOTaccept25V+) | C1206 |  | Select by Customer | CS3216X7R226K160NRI | Samwha Capacitor | 1206 | 16V 22uF X7R ±10% 1206 Multilayer Ceramic Capacitors MLCC - SMD/SMT ROHS | Multilayer Ceramic Capacitors MLCC - SMD/SMT |  | C5252682 | https://jlcpcb.com/partdetail/5970301-CS3216X7R226K160NRI/C5252682 | Extended | 124 | 124 JLCPCB | 21.9356
C9 |  | 10uF25VX7R(KEEP25V-thisonesitsonthe12Vboostrail) | C1206 |  | Select by Customer | CGA1206X7R106K250NT | HRE | 1206 | 10uF 25V X7R ±10% 1206 Multilayer Ceramic Capacitors MLCC - SMD/SMT ROHS | Multilayer Ceramic Capacitors MLCC - SMD/SMT |  | C6119987 | https://jlcpcb.com/partdetail/HRE-CGA1206X7R106K250NT/C6119987 | Extended | 124 | 124 JLCPCB | 11.7676
D1 |  | BZX84C3V3 | SOT-23 |  | Select by System | BZX84C3V3 | hongjiacheng | SOT-23 | -55℃~+150℃ 1 Independent 3.1V~3.5V 3.3V 300mW 5uA@1V 600Ω 95Ω SOT-23 Zener Diodes ROHS | Zener Diodes |  | C19077467 | https://jlcpcb.com/partdetail/hongjiacheng-BZX84C3V3/C19077467 | Extended | 124 | 124 JLCPCB | 1.6492
D2 |  | SS34 | SMA/DO-214AC |  | Select by System | SS34 | MDD(Microdiode Semiconductor) | SMA(DO-214AC) | -55℃~+125℃ 3A 40V 500uA@40V 550mV@3A Independent SMA(DO-214AC) Schottky Diodes ROHS | Schottky Diodes |  | C8678 | https://jlcpcb.com/partdetail/MDD_Microdiode_Semiconductor-SS34/C8678 | Basic | 128 | 128 JLCPCB | 4.4672
L1 |  | 22uH2.4Ashielded | SRN60456x6mm |  | Select by System | PNLS6045-220M 22UH | DMBJ | SMD,6x6mm | 125mΩ 22uH 3A 3A Magnetic Shielded Inductor ±20% SMD,6x6mm Power Inductors ROHS | Power Inductors |  | C2849539 | https://jlcpcb.com/partdetail/DMBJ-PNLS6045_220M22UH/C2849539 | Extended | 121 | 121 JLCPCB | 6.3767
R1 |  | 470R | R0805 |  | Unconfirmed | 0805W8F4700T5E | UNI-ROYAL(Uniroyal Elec) | 0805 | -55℃~+155℃ 125mW 150V 470Ω Thick Film Resistor ±1% ±100ppm/℃ 0805 Chip Resistor - Surface Mount ROHS | Chip Resistor - Surface Mount | 1.The comment (0805W8F4700T5E) of this part does not match the one (470R) provided in your BOM. Please confirm; | C17710 | https://jlcpcb.com/partdetail/18398-0805W8F4700T5E/C17710 | Basic | 130 | 130 JLCPCB | 1.17
R2 |  | 330k | R0805 |  | Unconfirmed | 0805W8F3303T5E | UNI-ROYAL(Uniroyal Elec) | 0805 | -55℃~+155℃ 125mW 150V 330kΩ Thick Film Resistor ±1% ±100ppm/℃ 0805 Chip Resistor - Surface Mount ROHS | Chip Resistor - Surface Mount | 1.The comment (0805W8F3303T5E) of this part does not match the one (330k) provided in your BOM. Please confirm; | C17629 | https://jlcpcb.com/partdetail/18317-0805W8F3303T5E/C17629 | Extended | 130 | 130 JLCPCB | 0.715
R3 |  | 10k | R0805 |  | Unconfirmed | 0805W8F1002T5E | UNI-ROYAL(Uniroyal Elec) | 0805 | -55℃~+155℃ 10kΩ 125mW 150V Thick Film Resistor ±1% ±100ppm/℃ 0805 Chip Resistor - Surface Mount ROHS | Chip Resistor - Surface Mount | 1.The comment (0805W8F1002T5E) of this part does not match the one (10k) provided in your BOM. Please confirm; | C17414 | https://jlcpcb.com/partdetail/18102-0805W8F1002T5E/C17414 | Basic | 130 | 130 JLCPCB | 1.573
R4,R10,R11 |  | 47k | R0805 |  | Unconfirmed | 0805W8F4702T5E | UNI-ROYAL(Uniroyal Elec) | 0805 | -55℃~+155℃ 125mW 150V 47kΩ Thick Film Resistor ±1% ±100ppm/℃ 0805 Chip Resistor - Surface Mount ROHS | Chip Resistor - Surface Mount | 1.The comment (0805W8F4702T5E) of this part does not match the one (47k) provided in your BOM. Please confirm; | C17713 | https://jlcpcb.com/partdetail/18401-0805W8F4702T5E/C17713 | Basic | 370 | 370 JLCPCB | 4.847
R5 |  | 6.8k | R0805 |  | Unconfirmed | 0805W8F6801T5E | UNI-ROYAL(Uniroyal Elec) | 0805 | -55℃~+155℃ 125mW 150V 6.8kΩ Thick Film Resistor ±1% ±100ppm/℃ 0805 Chip Resistor - Surface Mount ROHS | Chip Resistor - Surface Mount | 1.The comment (0805W8F6801T5E) of this part does not match the one (6.8k) provided in your BOM. Please confirm; | C17772 | https://jlcpcb.com/partdetail/18460-0805W8F6801T5E/C17772 | Basic | 250 | 250 JLCPCB | 3.55
R9 |  | 6.8k | R0805 |  | Unconfirmed | 0805W8F6801T5E | UNI-ROYAL(Uniroyal Elec) | 0805 | -55℃~+155℃ 125mW 150V 6.8kΩ Thick Film Resistor ±1% ±100ppm/℃ 0805 Chip Resistor - Surface Mount ROHS | Chip Resistor - Surface Mount | 1.The comment (0805W8F6801T5E) of this part does not match the one (6.8k) provided in your BOM. Please confirm; | C17772 | https://jlcpcb.com/partdetail/18460-0805W8F6801T5E/C17772 | Basic | 250 | 250 JLCPCB | 3.55
R7 |  | 1k | R0805 |  | Unconfirmed | 0805W8F1001T5E | UNI-ROYAL(Uniroyal Elec) | 0805 | -55℃~+155℃ 125mW 150V 1kΩ Thick Film Resistor ±1% ±100ppm/℃ 0805 Chip Resistor - Surface Mount ROHS | Chip Resistor - Surface Mount | 1.The comment (0805W8F1001T5E) of this part does not match the one (1k) provided in your BOM. Please confirm; | C17513 | https://jlcpcb.com/partdetail/18201-0805W8F1001T5E/C17513 | Basic | 130 | 130 JLCPCB | 2.119
R8 |  | 130k | R0805 |  | Unconfirmed | FRC0805F1303TS | FOJAN | 0805 | -55℃~+155℃ 125mW 130kΩ 150V Thick Film Resistor ±1% ±100ppm/℃ 0805 Chip Resistor - Surface Mount ROHS | Chip Resistor - Surface Mount | 1.The comment (FRC0805F1303TS) of this part does not match the one (130k) provided in your BOM. Please confirm; | C2933305 | https://jlcpcb.com/partdetail/FOJAN-FRC0805F1303TS/C2933305 | Extended | 130 | 130 JLCPCB | 0.455
SW1 |  | 6x6SMDtactile2-pin | 1TS0096x6mm |  | Select by System | 1TS009C-2700-5000-CT | HYP (Hongyuan Precision) | SMD,6x6mm | -40℃~+90℃ 100,000 cycles 12V 2.7N 50mA 5mm 6mm 6mm Black No Round Button SMD(SMT) Tab SPST Surface Mount,Vertical Without Bracket SMD,6x6mm Tactile Switches ROHS | Tactile Switches |  | C319428 | https://jlcpcb.com/partdetail/300427-1TS009C_2700_5000CT/C319428 | Extended | 121 | 121 JLCPCB | 8.7483
U1 |  | HT7550-1 | SOT-89 |  | Select by System | HT7550-1 | Holtek Semicon | SOT-89-3 | -40℃~+85℃@(Ta) 1 150mA 2.5uA 25mV@(1mA) 30V 5V Fixed Positive SOT-89-3 Voltage Regulators - Linear, Low Drop Out (LDO) Regulators ROHS | Voltage Regulators - Linear, Low Drop Out (LDO) Regulators |  | C16106 | https://jlcpcb.com/partdetail/HoltekSemicon-HT75501/C16106 | Extended | 122 | 122 JLCPCB | 13.3956
U2 |  | MT3608 | SOT-23-6 |  | Select by System | MT3608 | XI'AN Aerosemi Tech | SOT-23-6 | -40℃~+85℃ 1 1.2MHz 100uA、1.6mA 2A 2V~24V Adjustable Boost Boost Built-in No SOT-23-6 DC-DC Converters ROHS | DC-DC Converters |  | C84817 | https://jlcpcb.com/partdetail/XI_AN_AerosemiTech-MT3608/C84817 | Extended | 121 | 121 JLCPCB | 12.1484
PANEL,DRIVER |  | JSTS3B-XH-SM4-TB(right-angleSMTXH3p-verifyJLCstock) | JST_XH_SM4_1x03_RA |  | No matches | No Part Selected
RECVR |  | 1x072.54mmSMDfemalesocket(RXdock-verifyJLCstock) | PinSocket_1x07_SMD |  | No matches | No Part Selected

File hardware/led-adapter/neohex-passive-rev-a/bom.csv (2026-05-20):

Ref | Qty | Value | Package | Description | Assembly Notes
J1 | 1 |  | M5Stack A118 HY2.0-4P SMD candidate | HEX/NeoHEX output connector | Verify local footprint and cable pin order before ordering
J2 | 1 |  | JST_PH_S2B-PH-SM4-TB_1x02-1MP_P2.00mm_Horizontal | External LED power input | SMT JST-PH candidate; verify against chosen pre-crimped leads
J3 | 1 |  | JST_SH_BM04B-SRSS-TB_1x04-1MP_P1.00mm_Vertical | STEMMA/QT data input | Optional for STEMMA data variant
J4 | 1 |  | JST_SH_BM03B-SRSS-TB_1x03-1MP_P1.00mm_Vertical | Generic GPIO data input | Optional for generic GPIO variant
J5 | 1 |  | JST_SH_BM04B-SRSS-TB_1x04-1MP_P1.00mm_Vertical | HEX/NeoHEX fallback output | For Adafruit 4528-style Grove-to-STEMMA-QT cable; J5.4 is DATA
R1 | 1 | 330 ohm | R_0805_2012Metric | LED data series resistor | Place near J1
C1 | 1 | 0.1 uF | C_0805_2012Metric | VLED decoupling | Place near J1 VLED/GND
C2 | 1 | 100-470 uF >=6.3 V | CP_Elec_6.3x5.4 | Optional VLED bulk capacitor | DNP if module/power path already has adequate bulk capacitance
SJ1 | 1 |  | 2-pad solder jumper | Select STEMMA SDA as data | Close one of SJ1/SJ2/SJ3 only
SJ2 | 1 |  | 2-pad solder jumper | Select STEMMA SCL as data | Close one of SJ1/SJ2/SJ3 only
SJ3 | 1 |  | 2-pad solder jumper | Select generic GPIO as data | Close one of SJ1/SJ2/SJ3 only
SJ4 | 1 |  | 2-pad solder jumper | Optional STEMMA V+ to VLED | Default open; silkscreen NO NEOHEX
TP1 | 1 | VLED | 1.5mm test pad | VLED test point
TP2 | 1 | GND | 1.5mm test pad | GND test point
TP3 | 1 | DATA_RAW | 1.5mm test pad | Pre-resistor data test point
TP4 | 1 | DATA_OUT | 1.5mm test pad | Post-resistor data test point
TP5 | 1 | NC | 1.5mm test pad | Grove white/NC test point

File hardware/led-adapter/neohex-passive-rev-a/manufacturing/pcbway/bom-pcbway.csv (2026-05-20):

Designator | Quantity | Value | Footprint | Manufacturer | Manufacturer Part Number | Supplier Part Number | Populate | Notes
J2 | 1 | JST-PH-2 SMT | Connector_JST JST_PH_S2B-PH-SM4-TB_1x02-1MP_P2.00mm_Horizontal | JST | S2B-PH-SM4-TB(LF)(SN) |  | Yes | External VLED power input
J3 | 1 | JST-SH-4 SMT | Connector_JST JST_SH_BM04B-SRSS-TB_1x04-1MP_P1.00mm_Vertical | JST | BM04B-SRSS-TB(LF)(SN) |  | Yes | STEMMA/QT data input
J4 | 1 | JST-SH-3 SMT | Connector_JST JST_SH_BM03B-SRSS-TB_1x03-1MP_P1.00mm_Vertical | JST | BM03B-SRSS-TB(LF)(SN) |  | Yes | Generic GPIO data input
J5 | 1 | JST-SH-4 SMT | Connector_JST JST_SH_BM04B-SRSS-TB_1x04-1MP_P1.00mm_Vertical | JST | BM04B-SRSS-TB(LF)(SN) |  | Yes | Fallback output for Adafruit 4528-style Grove-to-STEMMA-QT cable; J5.4 is DATA
R1 | 1 | 330 ohm | Resistor_SMD R_0805_2012Metric | Yageo | RC0805FR-07330RL |  | Yes | LED data series resistor
C1 | 1 | 0.1 uF 50 V X7R | Capacitor_SMD C_0805_2012Metric | Murata | GRM21BR71H104KA01L |  | Yes | VLED local decoupling

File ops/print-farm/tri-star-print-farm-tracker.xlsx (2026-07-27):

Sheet: Print Tracker
Priority | Part Name | Part Qty | Material Type | Material Color | Material Qty (mg) | Print Time Est (Hr) | Total Print Time Estimate | Name of person printing | Qty Printed | Time Left | Complete
High | Hat enclosure top | 12 | PETG | Black | 78000 | 5.5 | 66.0 | Steve | 2 | 55.0 | No
High | Battery cradle | 12 | PETG | Black | 24000 | 1.8 | 21.6 | Jimmy | 0 | 21.6 | No
Medium | Gobo test disc | 20 | PLA | Matte White | 9500 | 0.8 | 15.0 | Adam | 6 | 10.5 | No
Low | Cable strain relief | 30 | TPU | Black | 4200 | 0.4 | 12.0 | Steve | 30 | 0.0 | Yes

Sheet: Summary
Tri Star Print Farm | Tri Star Print Farm | Tri Star Print Farm | Tri Star Print Farm | Tri Star Print Farm | Tri Star Print Farm
Metric | Value |  | Printer | Assigned Qty | Hours Left
Total part quantity | 74 |  | Steve | 42 | 55.0
Total qty printed | 38 |  | Jimmy | 12 | 21.6
Remaining quantity | 36 |  | Adam | 20 | 10.5
Total print hours | 114.6 |  | Unassigned | 0 | 0.0
Hours left | 87.1
Completion % | 51.4%
Material Type | Total mg | Total g | Total kg |  | Material Color | Total mg | Total g
PLA | 9500 | 9.5 | 0.009 |  | Black | 106200 | 106.2
PETG | 102000 | 102.0 | 0.102 |  | White | 0 | 0.0
ABS | 0 | 0.0 | 0.000 |  | Matte White | 9500 | 9.5
ASA | 0 | 0.0 | 0.000 |  | Natural | 0 | 0.0
TPU | 4200 | 4.2 | 0.004 |  | Clear | 0 | 0.0
Nylon | 0 | 0.0 | 0.000 |  | Red | 0 | 0.0
Other | 0 | 0.0 | 0.000 |  | Blue | 0 | 0.0
 |  |  |  |  | Other | 0 | 0.0
Grand total | 115700 | 115.7 | 0.116 |  | Grand total | 115700 | 115.7

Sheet: Lists
Material Type | Priority | Printer
PLA | High | Steve
PETG | Medium | Jimmy
ABS | Low | Adam
ASA
TPU
Nylon
Other

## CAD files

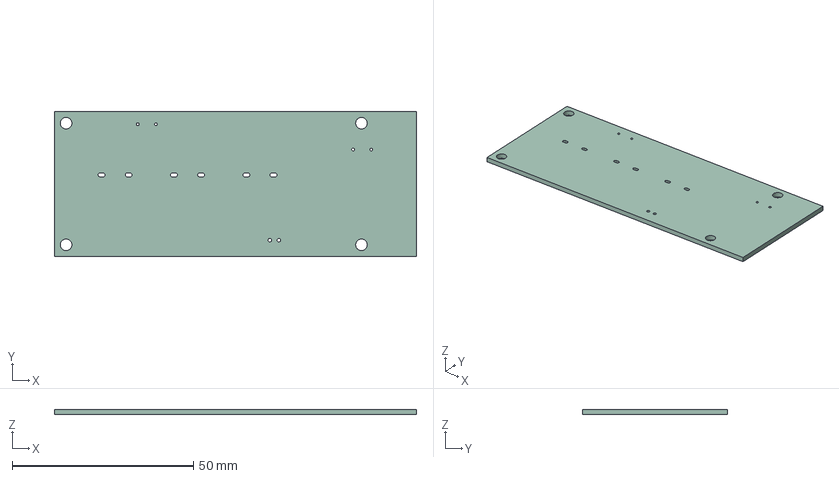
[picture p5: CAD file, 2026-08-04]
hardware/capboard/cad/capbank-v2.0-board-only.step
100.0 x 40.0 x 1.51 mm

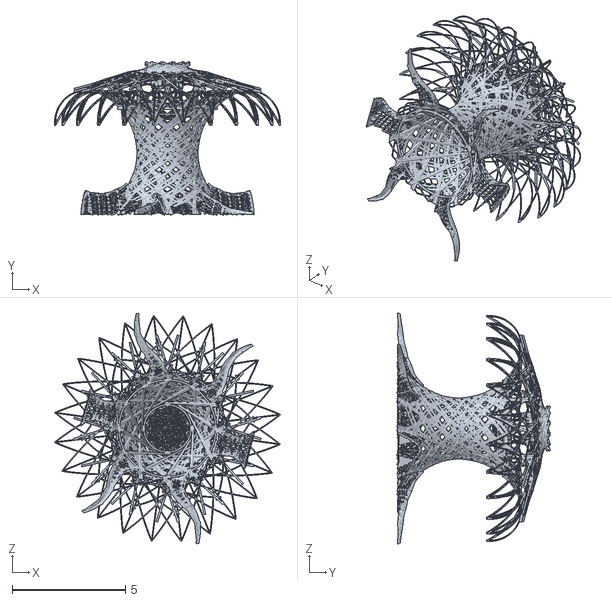
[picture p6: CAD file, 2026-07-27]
ops/solarsim/data/tree_mesh.ply
9.97 x 6.78 x 10.2

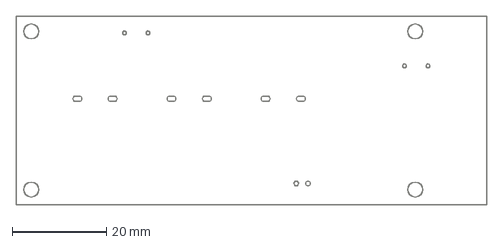
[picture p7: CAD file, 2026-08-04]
hardware/capboard/cad/capbank_4pin-Edge_Cuts.dxf
100.0 x 40.0 mm

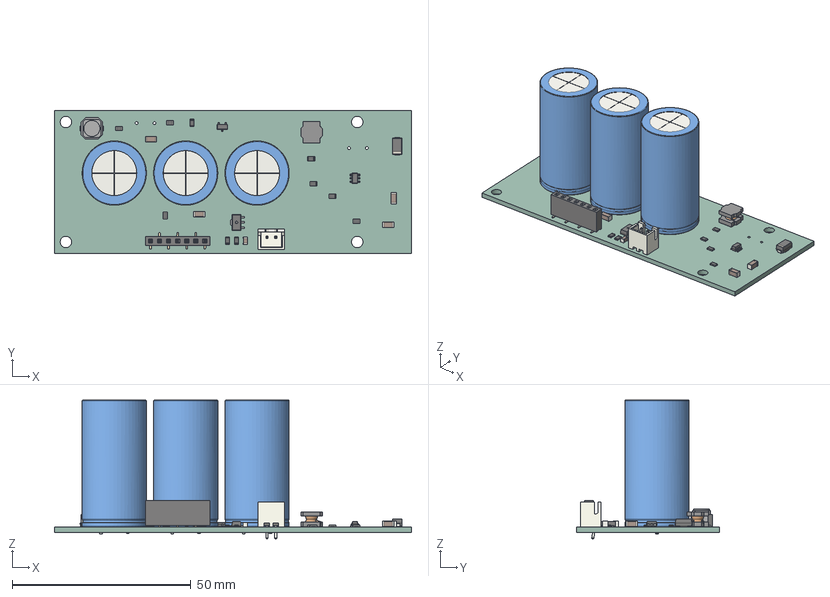
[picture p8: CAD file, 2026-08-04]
hardware/capboard/cad/capbank-v2.0.step
100.0 x 40.0 x 38.9 mm
C_1206_3216Metric x 4
R_0805_2012Metric x 10
D_SMA
JST_B2B_XH_A
SOT-23
adbeea57-9c39-11ed-93f0-dde97e994e83_part
adbeea58-9c39-11ed-93f0-dde97e994e83_part
adbeea59-9c39-11ed-93f0-dde97e994e83_part
C_Radial_D180mm_H355mm_P750mm x 3
C_0805_2012Metric
SOT-23-6
PinSocket_1x07_P2.54mm_Vertical_SMD_Pin1Left
L_Bourns_SRN6045TA
pin_1
pin_2
capbank_4pin_PCB

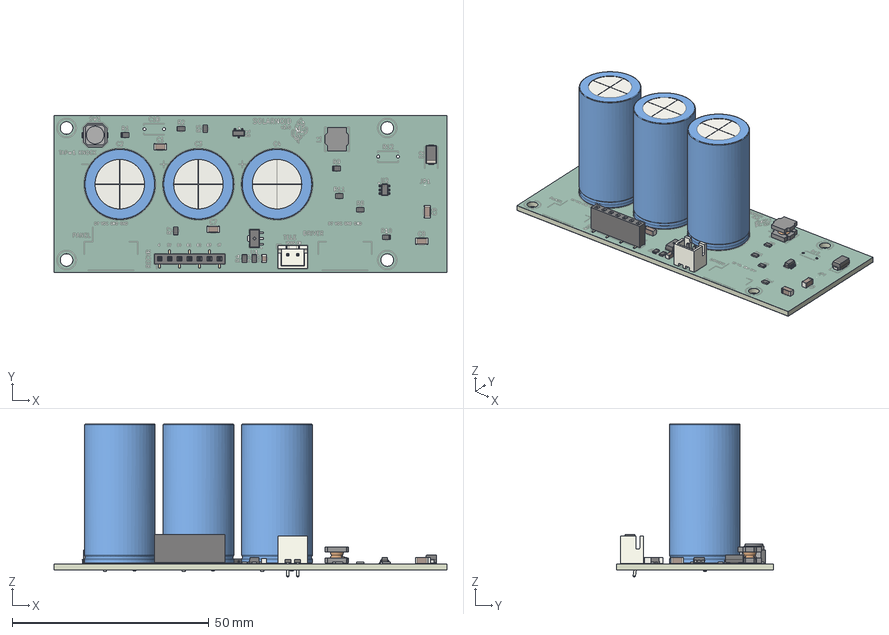
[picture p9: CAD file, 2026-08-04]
hardware/capboard/cad/capbank-v2.0-silkscreen.step
100.0 x 40.0 x 38.9 mm
C_1206_3216Metric x 4
R_0805_2012Metric x 10
D_SMA
JST_B2B_XH_A
SOT-23
adbeea57-9c39-11ed-93f0-dde97e994e83_part
adbeea58-9c39-11ed-93f0-dde97e994e83_part
adbeea59-9c39-11ed-93f0-dde97e994e83_part
C_Radial_D180mm_H355mm_P750mm x 3
C_0805_2012Metric
SOT-23-6
PinSocket_1x07_P2.54mm_Vertical_SMD_Pin1Left
L_Bourns_SRN6045TA
pin_1
pin_2
capbank_4pin_silkscreen x 2
capbank_4pin_soldermask x 2
capbank_4pin_PCB

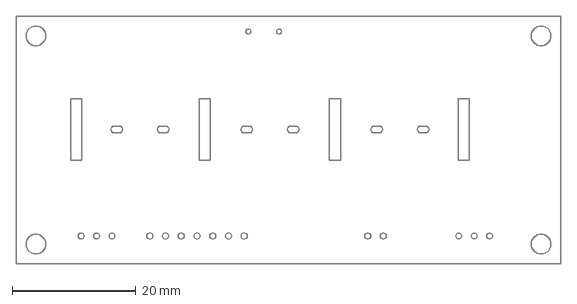
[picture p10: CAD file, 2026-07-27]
hardware/capboard/cad/capbank-Edge_Cuts.dxf
88.0 x 40.0 mm

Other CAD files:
solar-visualizer/src/model/Resonance_Solar_Study.skp

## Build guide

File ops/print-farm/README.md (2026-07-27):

# Tri Star Print Farm Tracker

This directory preserves Steve's local Resonance print-farm work product.

- `tri-star-print-farm-tracker.xlsx` is the local workbook snapshot created before the
  tracker was imported into Google Sheets.
- `previews/` contains rendered views of the workbook tabs.
- `archive/build_tristar_print_farm_initial.mjs` is the original generator retained for
  provenance. It represents the initial workbook, not the later edits made in the live
  Google Sheet.

The live Google Sheet is the operational tracker. Later changes described in `LOG.md`,
including the Part File rollup and revised material units, may not be present in this local
snapshot.

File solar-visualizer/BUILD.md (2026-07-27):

# How this was built + how to run and modify it locally

Everything here runs **fully offline** — no internet, no live site, no build step.
three.js and the Draco decoder are vendored under `vendor/`, and the tree geometry
is embedded in the viewer. This is the complete, self-contained package: open it,
read it, change it, re-run it.

---

## Run it locally (30 seconds)

The viewer is an ES-module page, so browsers won't load it over `file://` (module
CORS). Serve the folder over a trivial local server instead:

```bash
cd solar-visualizer
./run.sh                 # = python3 -m http.server 8777
# then open http://127.0.0.1:8777/Resonance_Solar_3D.html
```

Any static server works (`python3 -m http.server`, `npx serve`, VS Code Live
Server). No network needed once the folder is on disk. Verified offline with the
vendored deps — the sun animates, panels color by live watts, the tree renders.

The spreadsheet (`Resonance_Solar_Access_Study.xlsx`) and the PDF report open
directly with no server.

---

## What each file is

```
solar-visualizer/
├─ Resonance_Solar_3D.html        the interactive viewer (geometry + data inline; vendored three.js)
├─ Resonance_Solar_Access_Study.xlsx   full dataset as a spreadsheet
├─ Resonance_Solar_Report_Phase2.pdf   2-page written report
├─ solar_phase2_data.json         THE dataset: 94 panels × 84 slots, real+ideal W, losses, Wh/day
├─ run.sh                         one-line local server
├─ vendor/                        three.js 0.160 + addons + Draco 1.5.7 decoder (offline deps)
└─ src/                           the source that generates everything
   ├─ solar_lights_setup.rb       SketchUp: places the movable fixtures on the tree
   ├─ solar_access_analysis.rb    SketchUp: the raytracer — measures sun access → data
   ├─ solar_3d_template.html      viewer template (DATA is injected here at bake time)
   ├─ Resonance_Solar_Report.html HTML report source
   ├─ model/Resonance_Solar_Study.skp   the geometry the raytracer runs against (1.3 MB)
   └─ README.md                   pipeline + the v5 power-chain formula + gotchas
```

---

## How it was created (provenance)

**1 · Geometry.** The tree + build-site geometry originates in Blender
(`tree_split.blend`, the master woven model — available from Elliot; not in git
because it's a large binary). It was scaled **0.0985 m/unit** and brought into
SketchUp as `src/model/Resonance_Solar_Study.skp` — that `.skp` is the exact
geometry the raytracer sees, so it's included in full. Canopy lantern positions
come from the lighting `fixtures.json` in this repo. The tree shown in the 3D
viewer is a Draco-compressed GLB of that same model, embedded in the HTML.

**2 · Measurement (the raytracer).** `src/solar_access_analysis.rb` runs inside
SketchUp against that model. It geolocates the sun to Black Rock City, steps it in
10-minute slots Aug 30 – Sep 8 2026, and `raytest`s each panel against the real
woven strut geometry (gaps and all). Output per panel per slot: fraction of the
panel face lit + full-sun minutes. Fixtures are live component instances — drag
one and re-run, the numbers update. Sun-timezone and raytest gotchas are documented
in the script header and `src/README.md` (they will bite you otherwise).

**3 · Power model (v5, calibrated on Ben's bench).** The raytested access is turned
into watts and Wh/day by the chain that lives in the viewer/report JS:

```
panel_DC   = POA × 5W_nameplate × 0.77 tolerance/controller
                 × playa_excess_heat(/0.93 ref, capped 1) × 0.95 dust
wh_day_batt = Σ(panel_DC over day) × 0.63     # ADR-0026 + July field-cycle chain, energy into the cell
runtime_h   = wh_day_batt ÷ 1.364             # measured full-RGBW battery-side draw
```

Constants are Ben's bench (ADR 0026 panel-side INA + `SOLAR_FIELD_CYCLE_P105_P126_2026-07`).

---

## How to modify it

- **Change a power assumption** (panel nameplate, dust, the ×0.63 chain, LED draw):
  edit the constants block in `Resonance_Solar_3D.html` (and `src/solar_3d_template.html`
  / `src/Resonance_Solar_Report.html` to keep source + report in sync). The viewer
  re-derives every panel's watts on reload. One place, whole model updates.
- **Move a light / change the tree:** open `src/model/Resonance_Solar_Study.skp` in
  SketchUp, drag fixtures or edit geometry, re-run `src/solar_access_analysis.rb`.
  It writes a fresh access dataset.
- **Rebuild the viewer from new data:** drop the new dataset into
  `src/solar_3d_template.html`'s `DATA` blob (replace the `__DATA__` token) and save
  as `Resonance_Solar_3D.html`.

Questions → Elliot.

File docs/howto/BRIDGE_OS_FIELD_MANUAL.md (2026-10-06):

# Resonance Bridge Field Manual

## Bridge OS, CoreS3, and PUCA without the archaeology

**Living document:** 2026-08-27

**Audience:** field operators, lighting crew, IT support, and developers on call
**Scope:** the LilyGO T-Deck Plus Bridge OS, the M5Stack CoreS3 bridge, and the
PUCA performance-audio bridge

This is the friendly manual. It explains what to pick up, what the screens mean,
which button to press, what can go wrong, and when to stop and call Ben. It is not
the wire protocol, build record, or architecture decision log. Those remain linked
at the end.

The most important idea is simple:

> The lights are autonomous. A bridge can observe them or temporarily direct them,
> but no bridge is the brain of the tree. Local battery, lifecycle, and actuator
> safety always win.

T-Deck, CoreS3, and PUCA roles

*Figure 1. The three bridge roles. PUCA's powered-Pod20 development baseline
passes, but show acceptance remains open. Run one artistic frame publisher at
a time.*

## Read this first

These six rules prevent most field mistakes:

1. **The fleet is on ESP-NOW channel 11.** A T-Deck may use WiFi and the mesh at
   the same time only when the 2.4 GHz access point is also on channel 11.
2. **A callsign is friendly; the six-hex short MAC is identity.** Say and record
   both for any state-changing work: `Ponyta [F2B7DC]`, for example.
3. **Check the live count before a fleet action.** A sleeping or silent fixture
   cannot hear a best-effort broadcast. `seen` is history; `live` is reachable
   now.
4. **Dark and sleep are different.** Dark keeps the radio awake and draws much
   more power. Sleep turns off the rails and radio and cannot be cancelled over
   the air until the timer wakes the fixture.
5. **Leaving LEDs or Patterns does not stop the look.** Use the app's **Stop**
   button. A lost direct stream falls back to autonomous output in about three
   seconds.
6. **Use one live artistic publisher at a time.** T-Deck LEDs, T-Deck Patterns,
   CoreS3 audio, and PUCA audio all use directed frames. Two publishers
   can visibly fight because artistic control is intentionally last-writer-wins.

> **Security note:** fleet commands are not yet authenticated on the radio. Keep
> the T-Deck in trusted hands. Physical possession is an operating mitigation,
> not a cryptographic security property.

For OTA, USB flashing, reboot, profile/channel persistence, or any other NVS
mutation, use one declared operator across all bridges and laptops. Follow
[Firmware artifact identity and shared-bench handoff](FIRMWARE_ARTIFACT_HANDOFF.md).

## Which bridge should I use?

| Need | Use | Why |
|---|---|---|
| Walk the site, check health, identify a light, or set a temporary look | **T-Deck Bridge OS** | Handheld, mesh-native, works without a laptop; Claude is optional |
| Check nearby fleet health without a laptop | **CoreS3 Listener** | Touch-first, paged wireless health view with fixture detail |
| See the complete host dashboard or record serial telemetry | **CoreS3 Bridge OS + laptop** | The same image retains the proven USB dashboard and logger protocol |
| Run audio-reactive lights today | **CoreS3 + Module Audio + RODE** | Broadband response is hardware-validated; FFT/band modes are the current experiment |
| Use Cambium's binary serial transport | **CoreS3 Cambium build** | Separate firmware mode; not compatible with the text dashboard |
| Run the dedicated performance audio box | **PUCA, after show acceptance** | `0.5` safe boot/exact-target OTA passes; exact waveform, visible fixture response/fallback, rollback, and field geometry remain open |
| Run the ordinary autonomous show | **No bridge required** | The fixture fleet is designed to keep working without infrastructure |
| Update fixture firmware | **Laptop + shared-WiFi OTA tools** | A bridge can request exact-target maintenance, but it is not the OTA uploader |

## Status at a glance

The words below are deliberately conservative:

- **Working** means hardware evidence exists for the main path.
- **Canary** means the feature is in the flashed image, but its explicit field
  acceptance matrix is still open.
- **Planned** means do not expect a working feature.

| Device or feature | Status on 2026-08-27 | Practical meaning |
|---|---|---|
| T-Deck mesh, launcher, touch, trackball, keyboard, GPS, channel guard | Working | Hardware-probed on T-Deck `8EB508` |
| T-Deck Claude, Fleet, LED Studio, Blackout / Sleep, single Knock, CA Studio | Working with limits | Broad hardware or field smoke tests passed; read the app notes below |
| Contagion | Source-built, not field accepted | Color Virus/Epidemic; keep knock output off until named-canary qualification |
| T-Deck Health and Schedule | Canary | Broad physical smoke passed; full color/off-air/override matrices remain open |
| T-Deck callsigns, Patterns v1, RF Diagnostics, full-fleet Knock roll | Canary | Current image is flashed; deliberate named-canary checks remain open |
| T-Deck Default selector and RGB white mapping | Source-built | Native and embedded builds pass; not flashed or hardware-validated |
| T-Deck Locate, detailed sensor samples, microphone Patterns, voice | Planned | Locate is a visible placeholder; the others have no finished operator path |
| CoreS3 Listener + Audio Bridge OS | Working baseline; spectral canary | Standalone speech/envelope response is fleet-proven; 25 Hz spectrogram and band modes need hardware acceptance |
| PUCA Resonance bridge | `0.5` safe boot/OTA passed; show acceptance pending | Codec/stereo capture, radio census, no-hold safe boot, Bridge identity, and exact-target OTA are proven; armed controls, waveform/light, rollback, and field gates remain open |

The primary T-Deck is short ID `8EB508`, full MAC
`44:1B:F6:8E:B5:08`. The second unit is physically labelled `TSwift`, short ID
`979604`, full MAC `44:1B:F6:97:96:04`. The callsign-aware primary binary
recorded on 2026-08-24 is
1,550,224 bytes with SHA-256
`3026593615bd58304c2a6b8893bf4f92cd8f9f92211f9222a5a28517fedf6e32`.
A COM port is an observation, not identity; `COM152` was observed for the
primary and `COM157` for TSwift, not assigned as permanent names.

# Part I: T-Deck Bridge OS

## The one-minute startup

1. Power the T-Deck and wait for the launcher.
2. Read the top line. Confirm `ch11`, confirm the mesh live/seen count is
   plausible, and note whether the center ticker says `WiFi`, `mesh-only`,
   `WiFi joining`, or `GUARD`.
3. Open **Health**. A mostly grey screen immediately after boot can be normal;
   give sleeping fixtures time to report.
4. If you will command a fixture, name the intended callsign and short ID before
   touching the control.
5. If you need Claude, confirm WiFi is online. Every mesh app still works if
   internet is down.

If the launcher says `GUARD`, do not change the fleet channel. Fix the 2.4 GHz
access point so it is on channel 11, then use serial `wifi retry`.

## Screen and controls

The T-Deck has three useful input methods:

- **Touch:** fastest with bare hands.
- **Trackball:** the reliable playa choice with gloves, dust, or a fussy touch
  screen. Left/right changes focus, up/down uses the current screen's navigation,
  and click opens or activates the focused item.
- **Keyboard:** primarily for Claude chat. Enter submits.

On the launcher, left/right moves one tile and up/down jumps one four-tile row.
The blue tile is focused. Most app screens put **Back** at the bottom.

The top 26-pixel shell bar is always present: the current app has a blue accent
at left and normal app/network status uses the main ticker color in the center.
The clock is cyan. While a local color stream or program lease
is active, the center becomes a colored scrolling ribbon. A permanent stream
says `LOCAL`, its mode and target count, and `until STOP`. A separate clock cell
counts up for permanent streams or down for expiring leases, without restarting
the scrolling ribbon. A fixed `STOP` button appears at the right and ends
the local stream plus the tracked program without leaving the current app.
Fresh commands from another T-Deck, PUCA, CoreS3, or unknown publisher appear
as a blue informational ribbon with no Stop. Red means local and foreign
control activity overlap. App content starts below the bar, so none of these
states cover controls.

Bridge OS launcher map

*Figure 2. Source-derived launcher map at three times the device's 320 x 240
resolution. It is a faithful screen guide, not a camera photograph.*

In direct sun, remove the shipped protective film and tilt the screen so sunlight
does not hit it square-on. The panel was judged fairly clear that way. Use the
trackball if touch becomes unreliable. T-Deck battery runtime with the census and
screen active is still unmeasured, so begin critical work charged and carry USB-C
power.

## Reading the top status line

When no control activity is present, the shell compresses four facts into its
center cell:

```text
network      mesh channel   live/seen fixtures   T-Deck battery
WiFi             ch11              74/86               83%
```

| Display | Meaning | What to do |
|---|---|---|
| `WiFi` | WiFi is associated on the correct channel; mesh and internet can coexist | Claude should work after time sync |
| `mesh-only` | No infrastructure WiFi, but ESP-NOW is active | Normal for field control without Claude |
| `WiFi joining` | WiFi association is in progress while ESP-NOW stays active | Wait up to about 15 seconds; the bridge returns to mesh-only on timeout |
| `GUARD` | The AP channel does not match the stored mesh channel | Fix the AP to channel 11, then retry WiFi |
| `ch11` | The stored mesh channel | This is the production value |
| `74/86` | 74 live now, 86 seen since boot | Only the 74 live fixtures are plausible immediate recipients |

## Safe control hierarchy

When two instructions disagree, the fixture follows this order:

```text
local safety and battery veto
  -> transport-dark or active dark lease
    -> active direct color or program lease
      -> temporary Wake Fleet / Night Show baseline
        -> UTC civil-twilight schedule
          -> panel-current fallback
```

This explains several apparently surprising results:

- **Night Show** cannot defeat low-battery shutdown.
- **LED Studio** can deliberately light a healthy fixture during scheduled day.
- **Blackout** can suppress a scheduled night show.
- A deliberate operator strike request is attempted without time, solar, or
  battery-tier qualification, but can still produce no motion when the fixture
  is asleep, disarmed, in maintenance, inside rest time, lacks hardware, or the
  hard mechanism gate refuses it.

## Health: start here

Use **Health** for the fastest whole-fleet triage. It fits the production-health
registry on one screen and appends unexpected live IDs. The bottom mode button
switches the stable tiles between raw battery-voltage (`VBAT`) and charger-phase
(`CHG`) colors.

| Tile | Meaning |
|---|---|
| Green | fresh raw VBAT is above 3.20 V |
| Yellow | fresh raw VBAT is above 3.10 V and at or below 3.20 V |
| Red | fresh raw VBAT is at or below 3.10 V |
| Grey | rostered fixture is not fresh/on-air |
| Blue | fixture is live, but its battery value is not plausible |
| Cyan border | live ID is outside the normal production-health roster |

In CHG mode, green means `CHARGING_CC`, cyan `CHARGING_CV`, purple `TOP-OFF`,
amber `DONE/OFF`, red `FAULT`, blue
unknown, and grey off air. These phases come from the BQ25628E status/fault
registers. They are not guesses from a small signed-current number.

These colors are triage bands, not the fixture's complete ADR 0023 power-state
machine. Do not force a red fixture to perform merely because it still answers.

Tap or focus-and-click a square to see callsign and short ID, VBAT, validated
signed IBAT, human charger phase, input voltage/current, age, RSSI/PDR, advisory
SOC, class, program, lifecycle, tier, sensor signature, firmware, registry
status, battery capacity, and role.

Grey means **not fresh**, not automatically broken. After bridge boot, wait at
least one normal sleep cadence before calling a field fixture missing. Older or
PROTECT firmware can require a 16-minute census before absence becomes strong
evidence.

## Fleet: filter, sort, inspect, and identify fixtures

**Fleet** is the detailed scrollable roster. It shows:

- a chip of the fixture's reported rendered color;
- callsign when known, otherwise short ID;
- class letter: `D` downlight, `P` perimeter, `U` uplight, `C` chandelier;
- age, raw battery voltage, signed battery current (`+` charge, `-` draw), and
  active program.

Signed current is shown only when the fixture explicitly certifies a settled
post-guard MAX17260 sample. `-` or `-- (unverified)` means the value cannot be
trusted, which is expected for old firmware and the first heartbeat after wake.

`inf` means this bridge has never observed the registry fixture. `idle` is a
real reported program; `?` means program state has not been observed. Sparse
full-heartbeat program state is retained across short heartbeats and discarded
on peer reboot until the new boot supplies fresh full-heartbeat state. Detail
keeps RSSI/PDR and advisory SOC, and spells out state names such as
`DAY_CHARGE`, `DIRECT`, `PROTECT`, and `CHARGING_CC` instead of showing only
numeric codes.

Open a row for details and **Identify**, which requests a ten-second green blink.
The default view includes the complete production registry plus unexpected live
peers and sorts by callsign. Registry fixtures keep grey off-air rows, so ordinary
two-second refreshes do not move the list underneath a scroll. The selected
fixture and scroll context survive refresh and a visit to detail.

Press **View** to combine:

- `roster + live`, `seen since boot`, or `live now` rows;
- all light types, downlights, perimeter, uplights, chandelier, or unknown;
- all battery states, good, near low, low, off air, or no valid VBAT;
- all programs or one of IDLE, CA, BRIDGE, DIRECT, DARK, VIRUS, and unknown;
- all/known/unknown firmware, an exact observed reference revision, or the
  complementary non-match/unknown cohort for OTA rollout audits; and
- stable callsign, stable short ID, voltage low/high, most recent, or strongest
  signal sorting.

The raw-voltage bands match Health: good is above 3.20 V, near low is above
3.10 V through 3.20 V, and low is at or below 3.10 V. `off air` is separate
from `no valid VBAT`; silence is not displayed as a zero-voltage battery.
Bridge OS defaults to full-brightness `DAY` mode for sunlight. Fleet uses light
cells with dark text in that mode. Press the top-right `DAY`/`NITE` button to
switch immediately; night mode restores the saved lower backlight and explicit
dark-table colors. The same persistent switch is available in Settings.

Press **Blink** to identify every **fresh** fixture in the current filtered view.
The device first confirms the exact count with cancel focused, then walks that
captured cohort with paced exact-target 30-second green blinks. Hidden and
off-air fixtures are not targeted or claimed as reached. **Power** opens
Blackout / Sleep; End Blackout remains available there.

These Fleet view controls are flashed on primary T-Deck `8EB508` as of
2026-08-27. Esptool write verification, an exact full application-region
readback, and post-reset channel-11 mesh/peripheral checks passed. Physical
screen layout, dropdown, stable-scroll, detail/back, 192-row memory, and named
filtered-identify canary acceptance remain open in `TODO.md`.

The compact signed-current row, IDLE-versus-unknown fix, readable detail states,
and program/firmware rollout filters documented above are now in the combined
image flashed on exact `8EB508`. Its 1,581,168-byte `tdeck-dev-local` binary has
SHA-256
`c87b2805feb8bd95c0d6c9ae3022baaa40079483bca652de6c33f738c0e69e7e`.
Upload and an independent whole-application `verify-flash` digest comparison
passed; physical layout/filter acceptance remains open in `TODO.md`.

The ADR 0064 power-truth UI is now flashed on the same exact T-Deck as a
1,583,344-byte `tdeck-dev-local` binary, SHA-256
`3bc13ca8a8bfeb60aaa31d349721b3760522dc1600f3913dd145400fe1ef905c`.
It adds validated-IBAT rendering, human charger phases, the Health VBAT/CHG
toggle, and the Wake/Blackout/Deep-sleep names. Esptool verified every written
region and post-reset serial reported live `8EB508` channel-11 traffic. Fixture
canary validation remains open.

Callsigns are display and command-entry aliases. Short MAC remains authoritative
for flashing, OTA, manifests, persistence, and incident records. Unknown peers
fall back to short ID. The special Magic Wand appears as `Thor [F40344]`; its
firmware is protected from ordinary fleet OTA by ADR 0050.

## LEDs: simple colors and blinking

Use **LEDs** to run LED Studio:

1. Select `all`, `downlights`, `perimeter`, `uplights`, or `chandelier`.
2. Touch a labeled swatch: red, amber, green, cyan, blue, purple, white, or pink.
3. Set **dim**.
4. Choose **solid** or **blink 1Hz**.
5. Watch the line saying how many fresh fixtures are receiving the stream.
6. Use **Stop** when finished.

Changing a swatch starts or updates the stream immediately. Class data arrives
in full heartbeats and can take about 60 seconds to fill after bridge boot. If a
class filter finds unexpectedly few fixtures, wait and check Fleet/Health before
assuming those lights are missing.

The **white** swatch means visible white, not blindly writing the fourth RGBW
byte. Known downlights use their dedicated white die. Perimeter, uplight, and
chandelier classes receive full red + green + blue with the white byte clear,
so three-channel RGB modules work and mixed chandelier hardware remains safe.
This mapping is source-built as of 2026-08-25 and still needs a named RGB/RGBW
physical recheck before show use.

The stream continues when you press **Back**. It stops only when you press
**Stop**, start a competing stream such as Patterns, or start a Blackout/Sleep
action.
If the stream disappears, fixtures return to autonomous behavior in about three
seconds.

## Patterns: deterministic handheld shows

Use **Patterns** for a manual, microphone-independent look:

- modes: Wash, Chase, Wave, Twinkle;
- palettes: Ember, Forest, Ocean, Aurora, Moon;
- filters: fixture class and stable cohort A-D;
- controls: speed 1-8 and intensity 8-255.

Set the controls, press **Start**, and confirm the target count. **Back** leaves
the pattern running; **Stop** ends it. Starting Patterns replaces LED Studio, and
starting LED Studio replaces Patterns. They are two faces of one stream owner.

Patterns v1 is in the current T-Deck image and its model is heavily native-tested,
but the named HEX/RGBW physical acceptance matrix remains open. Use explicit
canaries before an important show. Microphone reactivity is not part of T-Deck
Patterns yet.

## Blackout / Sleep: know the difference

For indefinite storage or a calendar wake, use **Home -> Rest -> Store** on
`tdeck-0.3.0-storage4`. The [storage and wake guide](FIXTURE_STORAGE_AND_WAKE.md)
documents the exact firmware, reviewed roster/confirmation, and remaining
physical qualification. USB-wake ship also wakes from good solar input or QON;
RESET/BOOT cannot wake its unpowered ESP. These modes differ from the timed
radio sleep described below.

The screen defaults to **Blackout** for **10 minutes**, the reversible choice.
Read the selection before applying it; deep sleep still cannot be cancelled.

| Action | LEDs | Radio | Can cancel remotely? | Best use |
|---|---|---|---|---|
| Blackout | rail off | awake | Yes, with End Blackout or lease expiry | Short reversible blackout and diagnostics |
| Deep sleep | rails off | off | No; timer wake or physical reset/power cycle | Overnight energy saving |

Available durations are 10 minutes and every whole hour from 1 through 12.
Both actions show live/seen counts and require an on-device confirmation with
cancel focused by default.

Before RF, Bridge OS durably records the action, duration, exact mesh sequence,
bridge uptime, and fresh GPS UTC when available. The newest four actions survive
a T-Deck reboot and appear under serial `show`; the newest also appears in the
host dashboard's Master panel. If that write fails, Deep sleep or Blackout is
not sent.

For Blackout, use **End Blackout** to return reachable fixtures to autonomous
behavior. That button cannot wake a sleeping fixture. For Deep sleep, watch the
live count fall after the command; only fixtures that were awake to hear it can
leave the census. At timer wake they resume normal behavior automatically.

Blackout-but-awake draw has measured roughly 126-144 mA per fixture. Rails-off
sleep is sub-mA. Blackout is not a power-saving substitute for an overnight
sleep.

## Wake: Auto, Wake Fleet, and Night Show

The **Wake** app shows the T-Deck GPS summary and whether a valid UTC fix is
available. It offers three field baselines:

- **Auto:** use UTC civil twilight at Black Rock City, with the fixture's
  bounded solar/power fallback if trustworthy time expires.
- **Wake Fleet:** repeat for six minutes so sleeping fixtures receive it on
  timer wake. On the emergency inspection image, this preserves Auto/static
  fallback and opens a bounded LED/audio direct-control session. Campaign
  copies refresh the ten-minute arm during the six-minute gather, leaving about
  ten minutes of control for eligible fixtures afterward (about sixteen minutes maximum
  from the button press). Older images use the dark daytime baseline.
- **Night Show:** temporarily force the nighttime baseline.

The choice is RAM-only and clears on fixture reboot. In the inspection image,
only direct colors are admitted during the armed window; show/program modes
remain disabled. Direct frames do not extend the deadline, static inspection
white returns within three seconds after a stream stops, and battery safety
remains above all control. Wake Fleet is not an energy-saving command: its
purpose is to make the fleet reachable. Use Blackout for an already-awake
reversible blackout and Deep sleep for deliberate radio-off energy saving.

PROTECT exception: Wake Fleet and Performance Hold do not override the power
policy's sleep decision or clear its durable latch. A protected fixture normally
listens for about 8-9 seconds between 900-second sleeps; receiving Wake refreshes
ordinary lifecycle/control state, but not the independent PROTECT sleep grace.
The six-minute Wake campaign cannot guarantee catching a 15-minute PROTECT
cycle. Performance Hold repeats long enough to catch that cycle, but does not
keep a still-protected fixture continuously reachable. Qualified recovery or
OTA/maintenance can separately change its awake behavior. Continuous radio
claims apply only while the fixture's power policy permits them.

Schedule is a production-direction feature with native coverage and first-canary
firmware evidence, but the full multi-fixture sleep-cycle acceptance matrix is
still open. Verify on named canaries before relying on it fleet-wide.

## Knock: request a bamboo strike

The target list contains one row per fresh fixture plus
`ROLL ALL (targeted)`. Set a pulse from 5 to 300 ms; 40 ms is the ordinary
starting point.

- A single target sends one addressed request.
- Roll All sorts every fresh ID and sends one addressed request every 80 ms.
- Roll All is **not synchronized**. The display reports sent requests, not
  guaranteed mechanical impacts.

Updated fixtures accept the Knocker broadcast event; older images ignore it.
Under ADR 0065, received Knocker targeted and multicast requests bypass night,
solar, and battery-tier qualification. Arm, rest, maintenance, pulse, durable
load-marker, deadline, and mechanism gates remain, so the UI reports attempts
rather than guaranteed impacts. The current full-fleet roll fixes an older
32-fixture limit but still awaits its explicit hardware recheck. Use a named
single fixture before using the roll.

## CA: cellular-automaton studio

**CA Studio** leases the Greenberg-Hastings wildfire to the fleet. Choose the
output that the CA excitation drives:

| UI name | Meaning |
|---|---|
| lights | excitation renders the existing light wildfire |
| knocks | excitation requests one sound-only solarnoid strike |

For CA, the sliders mean:

- `K neighbors`: excitation threshold;
- `spark /256`: spontaneous activation probability;
- `refractory`: refractory ticks;
- `tick (ds)`: tick period in tenths of a second;
- `light hue`: base hue, 0-255; ignored by knock output; and
- `ToF seed`: optionally let a detected visitor excite local CA.

Choose a 120 s, 300 s, 600 s, or 1 h lease and press **Apply**. Fleet-wide apply
requires confirmation. **Release** returns to autonomous behavior.

Knock mode keeps the LED rail off. Every excitation edge requests one 40 ms
mallet pulse, but each fixture still enforces daytime, solar-surplus, battery,
arm, rest, maintenance, and mechanism safety. A fixture without a solarnoid
still relays CA state and simply cannot make a physical knock.

With **ToF seed** off, the wildfire is seeded by spontaneous sparks and excited
neighbors. With it on, sensor-equipped downlights can also originate it from a
hardened local presence edge; non-sensor fixtures still participate through
neighbor state. The detector first learns about 25-30 seconds of per-zone
background, then requires one confident zone to move at least 300 mm closer for
three reports. Four clear reports re-arm it. This is intentionally less eager
than the old direct bench reactions. Set `spark /256` to zero if the test should
wait for presence or an already-excited neighbor.

The separate ToF color-wipe interaction remains suppressed during the CA lease,
so a visitor does not launch two propagation systems. Direct sun, close ground,
and neighboring ToF emitters can still make optical evidence unavailable or
noisy; ToF-off remains the reliable fallback for daytime knock wildfire.
Same-program knob changes apply without the old release/re-lease light blip.

## Contagion: color infection and epidemic

**Contagion** is deliberately separate from CA Studio. Choose **Color Virus**
for a hue that spreads and persists, or **Epidemic** for infected -> immune ->
susceptible cycles. Choose lights, knocks, or lights + knocks; slow, medium, or
fast; and a fixed or random seed color.

Press **Start** to place all awake updated fixtures into a susceptible 10-minute
lease. Fixtures are alphabetical by callsign. Touch **find name / ID** and type
part of a callsign or short ID on the physical keyboard to narrow the synced
dropdown, then select one fresh fixture and press **Seed** to begin. **Stop**
returns the fleet to its autonomous behavior. Old fixture images reject program
5, so a mixed-version fleet produces gaps rather than silently approximating
the effect.

In Color Virus, a successfully infected fixture keeps its hue until a new
strain arrives. After the palm gate clears and re-arms, another hover on an
infected source launches a newer strain across the already-infected graph.
Random mode guarantees a visibly different hue at the source; fixed palette
choices deliberately keep their selected color. One updated fixture among
old-image neighbors will change color but cannot visibly spread until at least
one neighbor also understands program 5.

Knock and both modes request one 40 ms strike when a downlight becomes infected.
Perimeter fixtures remain silent sensor/relay nodes, so a visitor-facing palm
seed can spread into nearby mallet downlights. A strike request can be refused
locally without suppressing the infection state. Do not begin physical
validation fleet-wide: first use one named, explicitly armed daylight canary
and retain the normal power/mechanism safety checks.

For the current pre-program-5 fleet, choose **legacy fleet roll** instead of
native knocks. Select the exact sensor source (for example Magmar `F2BDFC`) and
confirm the 10-minute adapter. The source's first infected edge starts the same
40 ms exact-target roll already used by Knocker, filtered to fresh downlights;
repeated state frames do not repeat it. Stop disables both the lease and the
adapter. This mode requires the T-Deck to remain awake and listening. Do not use
it after those downlights run native Contagion, because native and compatibility
paths represent the same artistic strike intent.

The off-by-default **ToF** option uses the established learned approach gate on
downlights and a deliberate palm easter egg on perimeter fixtures. Hover a flat
palm about 5-10 cm above the perimeter sensor; touching it can be too close to
range. The first named canary separated clear 0/16 zones from a sustained
15-16/16-zone palm in cloudy daylight. The gate requires two broad near reports
and four clear reports to re-arm. Treat this as provisional until direct-sun
and final-geometry checks pass. The legacy listener color wipe remains
downlight-only.

## Default: commissioned no-command behavior

The **Default** app changes what an updated fixture does in commission profile
when no direct stream or program lease is active:

| Choice | No-command behavior |
|---|---|
| ready beacon | Existing class-aware commission listener; the normal default |
| wildfire CA | Autonomous light-only GH wildfire; no bridge must remain on |
| rails dark | Strict electrically dark diagnostic fallback |

Select one named short ID or `ALL: targeted fresh`, then choose **until reboot**
or **persist after reboot**. The all action is not an anonymous broadcast: the
T-Deck sorts the fresh census and sends one exact-target command per fixture.
Persistence is an NVS mutation, so declare the T-Deck as the sole operator and
do not run another profile/configuration writer at the same time.

The setting is ignored in field profile. Active LED Studio, Patterns, Dark, or
CA leases still win; changing the default during a lease changes where the
fixture returns after release or expiry. Wildfire here is always light-only --
daytime knock CA remains an explicit bounded CA Studio lease. This feature is
in the current combined `8EB508` image but has not yet been hardware-validated.

## RF: read-only radio diagnostics

**RF Diagnostics** does not send a mesh command. Its links page shows:

- live, seen, stale, roster-unobserved, and foreign-live counts;
- observation coverage;
- strongest and weakest fresh peers by RSSI/PDR/age;
- mesh RX, invalid, and ring-drop counts;
- TX success/failure counts; and
- mesh channel, WiFi state, AP channel, and channel-guard state.

Use the **frames** button for the newest-first valid-frame tail. `PDR -` is an
honest unavailable value, especially during the first minute; it is not zero.
The app is safe for passive diagnosis while another operator owns show control.
Its physical two-page acceptance check remains open in the current image.

## Claude: ask the bridge in plain language

Claude needs WiFi, valid time, and a provisioned API key. Mesh functions do not.
When the WAN is down, a typed message queues in RAM and the app shows that state
instead of pretending the mesh failed.

Useful requests include:

```text
Which fixtures have been quiet for more than five minutes?
Show me the status of Ponyta.
Identify Ponyta in green for ten seconds.
What are the last ten mesh frames?
Lease CA to the whole fleet for five minutes.
```

The tool surface is intentionally limited to:

- mesh census;
- one-node status;
- identify;
- one-fixture strike;
- temporary program lease; and
- recent frame tail.

Claude cannot represent OTA, reboot, profile changes, lifecycle sleep, battery
capacity, or other persistent maintenance operations. A fleet-wide program
lease opens the same physical confirmation rail used by local apps. If it times
out or is denied, the command is not sent.

Claude's census examines all 192 tracked slots and returns explicit 24-row
pages. A partial response includes `truncated: true` and `next_offset`; Claude
can pass that value back as `offset` to continue. Use Health or the host
dashboard when one-screen fleet accounting is preferable.

## Settings, SunTest, and Locate

### Settings

Settings selects persistent day or night display mode, changes the saved night
backlight, and changes the stored mesh channel. Day mode always runs the
backlight at 255 for sunlight; night mode restores the saved level. Production
is channel 11. A channel change persists, and reboot applies it cleanly. Do not
change it in the field without an explicit migration or lab plan.

WiFi credentials, API key, and model are displayed only as provisioning status;
secrets are entered over USB serial. The current `show` command prints an API-key
prefix, so do not run it on a projected or public terminal.

### SunTest

SunTest forces full backlight and displays contrast bars, text, and color patches.
Use it to check readability, stuck display areas, or a questionable backlight.
Back returns to the active display mode: full brightness for day or the saved
night level for night.

### Locate

Locate is a placeholder. Active RSSI survey packets exist elsewhere in the
system, but Bridge OS does not yet retain and model neighbor reports for this UI.
Do not expect a map or survey workflow from this tile.

# Part II: T-Deck IT and troubleshooting

## Network layout

The T-Deck has one 2.4 GHz radio. WiFi and ESP-NOW can coexist only on one
channel. The correct field layout is:

```text
Starlink in bypass mode
        |
        v
Beryl AX travel router
  2.4 GHz: fixed channel 11, HT20, WPA2-PSK -> T-Deck + ESP-NOW coexistence
  5 GHz: separate SSID                         -> laptops and phones
        |
        v
Internet / Claude

Fixture fleet ---------------------------------> ESP-NOW channel 11
```

Do not use the router configuration page as proof of channel. Verify over the
air. The complete procedure is
[Camp network setup](CAMP_NETWORK_SETUP.md).

## Serial provisioning

Connect USB serial at 115200 baud. The stored settings live in NVS; no secret is
compiled into or committed with Bridge OS.

```text
set wifi <ssid> <psk>
set key <anthropic-key>
set model claude-sonnet-5
set channel 11
set display day
set bl 200                 # saves the night level; day remains at 255
wifi retry
show
```

> **Current limitation:** the serial parser requires the SSID and password to be
> one token each. It does not support quotes or spaces. Do not type
> `set wifi Party In The Woods ...`; it would parse the wrong fields. Use an
> approved one-token bridge SSID for now, or stop and have the firmware corrected.
> The fixture maintenance SSID and the T-Deck's simultaneous mesh/internet SSID
> do not have to be the same network.

Useful read-only service commands:

```text
probe       # onboard peripheral report
mem         # heap and PSRAM current/minimum values
peers       # serial census table
t           # one-line JSON bridge telemetry
show        # settings and network state; API-key prefix is visible
emit on     # 1 Hz nb-master/nb-peer lines for host tools
emit off
```

Expected hardware probe evidence on the current T-Deck is 8 MB PSRAM, keyboard,
touch, ES7210 at `0x40`, and GPS NMEA at 38400 baud.

The serial CLI also has state-changing quick commands. Prefer the physical UI
for ordinary operation. If IT work requires serial control, name the exact short
ID and follow the same operator discipline:

```text
iF2B7DC:10   # identify one fixture
I            # identify all for 8 s
KF2B7DC:40   # one addressed 40 ms strike request
UF2B7DC      # exact-target maintenance request for 35 s; no broadcast form
FF2B7DC:1:1  # exact-target field profile, persisted; first F is the command
B600         # fleet dark lease for 600 s
b            # release the fleet dark lease
```

`U<ID>` only asks the named fixture to enter shared-WiFi maintenance. A laptop
must still discover, identity-check, upload, and verify the immutable OTA artifact.
Full-fleet work uses `ops/bench/fleet_dashboard_ota.py`, not a hand-entered list
of `U<ID>` commands. Its job-scoped `uB/uA/uF/uS` protocol keeps the complete
roster active and proves FREEZE before uploading; see
`docs/howto/FLEET_OTA_10_MINUTE_RUNBOOK.md`.

`F<ID>:<0|1>:<0|1>` is an NVS mutation. The first value is commission/field and
the second is the persist bit. It refuses `000000`; use it only after an exact
post-OTA profile audit and under the same single-writer declaration as OTA.

## T-Deck symptom guide

| Symptom | First check | Likely action |
|---|---|---|
| Launcher says `GUARD` | AP channel versus `ch11` | Pin the AP's 2.4 GHz radio to channel 11, verify by scan, then `wifi retry` |
| WiFi join times out | SSID, password, range, WPA2 | Mesh should recover automatically; fix WiFi without changing the mesh channel |
| Claude queues or stays unavailable | `ONLINE`, SNTP/time, API key | Run `show`; restore internet/time/key. Continue with local mesh apps |
| Mesh live count is zero | channel, RF screen, fixture sleep state | Confirm ch11; wait for a full sleep cadence; move closer; do not assume all fixtures failed |
| Health is mostly grey after boot | observation time | Wait at least 5 minutes; use 16 minutes for older/PROTECT field firmware |
| A Health tile is red | raw VBAT at or below 3.10 V | Treat it as a low-power lead; inspect details and charging before asking it to perform |
| LED Studio says targets, but lights do not change | lifecycle, class data, another publisher | Check Fleet program/output, wait for class heartbeats, stop CoreS3 audio or other frame sources |
| Look stops when another app starts | stream ownership | LEDs and Patterns replace one another by design; start the desired one again |
| Look continues after Back | app semantics | Return to LEDs/Patterns and press Stop |
| Sleeping fixtures ignore End Blackout | radio is off | Wait for timer wake or physically reset/power-cycle an explicitly identified fixture |
| Knock request produces no sound | asleep/missed packet, empty cap, absent hardware, or hard mechanism gate | Check freshness, exact target, solenoid arm, maintenance/rest state, capboard, and mechanism; operator knocks do not prefilter day/surplus/tier |
| Touch is unreliable | dust, gloves, glare | Use the trackball; remove protective film and tilt the display |
| Wrong mesh channel was saved | Settings or serial configuration | Restore 11 and reboot cleanly; coordinate before touching any lab channel |
| UI behaves strangely after long use | memory/peripheral state | Record `mem` and `probe`, then reboot the T-Deck; do not mutate fixtures during diagnosis |

## When a light is missing

Use this order so a sleeping fixture is not misdiagnosed as dead:

1. **Health:** is its registry tile grey, or is it completely absent/unexpected?
2. **Fleet:** was it seen, and how old is the last frame?
3. **RF:** is the mesh up, and are other fixtures arriving normally?
4. **Wait:** at least one 300-second field cadence; up to 16 minutes for legacy
   or PROTECT behavior.
5. **Check provenance on current firmware:** the selected dashboard detail names
   the last timer-sleep cause, retained operator-sleep source/sequence, and last
   PROTECT-entry voltage. Compare a command receipt with the Master panel's last
   retained action. A bridge action is an attempted send; fixture receipts prove
   which peers actually heard it.
6. **Compare peers:** if nearby fixtures are also absent, suspect bridge position,
   antenna obstruction, channel, or a local power event.
7. **Physical inspection:** panel, cable, enclosure, charge state, and antenna
   keep-out.
8. **USB rescue:** only after exact identity and the recovery procedure are ready.

Do not infer that `online=true` from an old dashboard entry proves a fresh rejoin.

# Part III: CoreS3 desk bridge

## What it is

The CoreS3 is a standalone two-app bridge and the current audio-reactive
fallback. It stays unassociated from infrastructure WiFi, pins ESP-NOW to
channel 11, tracks up to 192 peers, and keeps sending the serial lines understood
by the host dashboard and JSONL logger when USB is attached.

The ordinary image boots to a launcher:

| App | Purpose | Laptop required? |
|---|---|---|
| Listener | 24-fixture-per-page health grid plus exact fixture detail | No |
| Audio | built-in mic or Module Audio/RODE envelope/FFT publisher | No |

Cambium remains a separate binary COBS/CRC artifact; never run the text dashboard
against it. Module Audio is a hardware build variant of the ordinary two-app
image, not a separate operator mode.

## Listener quick start

1. Power the CoreS3 from its battery or USB-C.
2. Confirm the launcher says `WIRELESS ch11 radio UP`.
3. Tap **Listener**. The grid is sorted by short MAC and shows 24 observed
   fixtures per page.
4. Read the shape as fixture class, the body color as raw-VBAT health, the thin
   top bar as reported rendered color, and a grey body as off-air.
5. Tap a tile for exact age, RSSI/PDR, battery/input, class/profile/program,
   sensor/recovery, LED-output, and firmware values.

The local Listener is read-only. USB remains optional unless the complete host
dashboard, logging, or serial controls are needed.

## Complete host dashboard quick start

1. Connect the CoreS3 by its own USB-C port.
2. Confirm the screen shows the Bridge OS launcher, not the Cambium screen.
3. Confirm the boot identity reports channel 11 and Bridge OS mode.
4. On the laptop, identify the actual port; never assume yesterday's COM number.
5. Launch:

```sh
python ops/bench/net_bench_dashboard.py --port COM40
```

Replace `COM40` with the observed port. The hardware-validated Bridge OS CoreS3
is full MAC `80:45:6B:4D:5D:B0`, short ID `4D5DB0`. The second historical
Nevada City CoreS3 is full MAC `44:1B:F6:E3:9F:1C`, short ID `E39F1C`. Those
identities are more authoritative than their port numbers.

The dashboard's overview glyph combines:

- center shape: fixture class;
- center fill: battery health;
- top sun/plug: inferred source convention plus charger-input evidence;
- thin top bar: actual reported light color;
- fading tile: late or silent heartbeat;
- persistent checkbox: renewable green location tag.

Source icons are an honest inference, not universal panel-versus-USB detection.
Use selected/detail values for exact electrical evidence.

## CoreS3 audio quick start

Use the full
[CoreS3 audio-reactive how-to](CORES3_AUDIO_REACTIVE.md) for RODE button details
and tuning. The short version is:

1. Power the entire stack off.
2. Set Module Audio's physical A/B I2S switch to **B**.
3. Connect the RODE analog cable to **LINE/MIC**, not the TRRS headset jack.
4. Start the RODE around gain 10, 75 Hz high-pass, boost off, pad off, safety
   channel off.
5. Power on, tap **Audio**, and confirm `AUX INPUT PUBLISHING`. Tap **Input** if
   the app is currently using `AMBIENT MIC`. Starting Audio releases any active
   fleet program lease in RAM, so an earlier CA or Contagion session cannot
   block the direct stream. This does not flash fixtures or change saved state.
6. Leave two seconds of ordinary ambient sound after entering Audio for calibration.
7. Confirm intended fixtures appear live, then play the source.
8. Read the fast spectrogram with bass at the bottom and high frequencies at the
   top. Use **Mode** to cycle Classic, Ember, Huecycle, Pulse, Bands RGB, Bands
   Split, and Timbre Hue. Use **Input** to cycle Ambient Mic <-> Aux Input and
   **Pause/Start** to control the stream; USB `M`, `N`, and `A` remain optional
   aliases.
9. Pause or leave Audio before starting T-Deck LEDs or Patterns.

The bridge analyzes and refreshes the Audio display at a nominal 25 Hz but still
sends only about 10 direct frames per second. If the bridge pauses, unplugs, or
fails, fixtures return to autonomous output after about three seconds. The
accepted baseline covers standalone speech/envelope response; deliberate
bass/mid/high separation and display-cadence checks remain open.

## CoreS3 troubleshooting

| Symptom | Likely cause | Fix |
|---|---|---|
| Dashboard prints garbage or cannot parse | Cambium binary image is installed | Stop the text dashboard and flash/use the ordinary Bridge OS artifact |
| CoreS3 lacks the Listener/Audio launcher | old normal/audio artifact is installed | Install one inspected Bridge OS artifact; do not guess from COM number |
| Display says `MODULE TRS`, but RMS is exactly 0 | Module Audio selector is A | Power the stack fully off, move the selector to B, restart |
| Display says `AMBIENT MIC` when Aux is wanted | Ambient is selected or Module Audio was late at boot | Tap Input once; if Aux remains unavailable, fully power-cycle, reseat the stack, confirm selector B, and confirm the Module Audio artifact |
| RMS moves, level is weak | low mic output, wrong jack, distance, pad | Charge/power RODE, use LINE/MIC, raise gain gradually, aim and move closer |
| Level stays near 100% or RODE peak LED is red | analog overload | Lower gain, move back, then use the -20 dB pad if required |
| Bridge reacts, fixtures stay in CA | old CoreS3 image did not release the explicit lease or omitted current `fx-*` fixture identities from Audio frames | In CA Studio tap Release, then restart Audio; install `cores3-os-0.1.2-dev` or later on the CoreS3 for automatic takeover and current-fleet selection |
| Bridge reacts, fixtures do not | fixtures not live, channel mismatch, lifecycle, old fixture firmware | Check live IDs, channel 11, direct-frame support, and authorized daylight override |
| Unwanted rumble drives the lights | wind, handling, generator, solarnoid | Use directionality and windshield first; then 75 Hz or 150 Hz filtering |
| Spectrogram has a permanent bright top rail | old image treated Module Audio stereo as one mono timeline | Install `cores3-os-0.2.0-dev` or later; it collapses complete L/R frames before FFT analysis |
| CoreS3 screen flickers or stays black | wrong/old image or display initialization issue | Confirm the current PSRAM-framebuffer artifact and boot serial; preserve logs before reflash |

For daylight audio tests, an authorized technician may temporarily set each
named fixture to forced night in RAM with its own serial `N1`, then must restore
automatic lifecycle with `N2`. This is a bench procedure, not a casual field
shortcut.

# Part IV: PUCA performance-audio bridge

## Honest status

PUCA is the intended primary performance-audio instrument. Its powered-Pod20
codec/stereo/radio/full-census baseline passes on the received board. Installed
`0.5.5-dev` boots SAFE-IDLE: it advertises identity and can hear maintenance,
but emits no lighting frames unless the paw is held for 1.2 s during boot. A
no-hold USB boot, exact `A4EB10` Bridge OS heartbeat, exact-target shared-WiFi
OTA, post-OTA dark rejoin, and pending-verify survival passed on 2026-08-27.
Exact-unit raw-capacitance handling and the paw-held DJ-first power-on gesture
passed on 2026-08-29 with `bootarmed=1` and `active=1`. Laptop line input and a
visible paired HEARTBEAT look also pass. Timed setup gestures, forced rollback,
the real RODE/performer waveform, named-fixture fallback, final field geometry,
and a multi-hour run remain acceptance gates. The factory Eurorack
oscillator/effect image is not tree
firmware, and a CoreS3 binary is not PUCA-compatible.

The hardware on hand is:

- PUCA DSP Original Edition with 8 MB PSRAM;
- 6 HP Eurorack expansion;
- 4ms Pod20 Powered case and 45 W brick;
- two knobs, capacitive paw, protected CV and trigger inputs;
- onboard microphones plus WM8978 stereo line input; and
- RODE VideoMic NTG with WS11 windshield.

The intended path is:

```text
RODE or mixer -> PUCA audio input -> WM8978 -> local envelope/FFT/onset
              -> ESP-NOW channel 11 -> directed fixture frames
              -> automatic fixture fallback if the stream stops
```

PUCA will be an optional publisher, not a required coordinator.

## PUCA startup and OTA

- Ordinary power or an OTA/software reboot -> SAFE-IDLE. This must not seize or
  darken the tree.
- To perform: hold the paw continuously while powering/rebooting until the
  1.2 s arm gesture completes. The first mode is DJ; short setup touches then
  cycle DJ, HEARTBEAT, EMBER, and HUE.
- For maintenance: select live peer `A4EB10` in Health and request exact-target
  maintenance, or send serial `UA4EB10`. PUCA ignores all-zero/fleet-wide
  maintenance commands.
- Bridge OS requests maintenance; the laptop still discovers the identity-
  matching shared-WiFi endpoint and uploads the PUCA Original Edition image.
  Use the `firmware/puca_bridge/README.md` command so the 35 s command tail is
  gone before reboot and the 25 s pending-verify gate is observed.
- Maintenance and `/resume` always return to dark COMMS. A later deliberate
  paw-held boot is required to publish. USB remains emergency recovery.

The installed module normally needs Pod20 power for its complete Eurorack panel
audio/CV/trigger path. USB-C or an optional main-board LiPo can keep the PUCA
PCB, codec/onboard audio, radio, and recovery path alive, but neither replaces
the rack rails or powers the tree. There is currently no operational reason to
add the optional JST battery header unless PUCA-only telemetry/OTA ride-through
becomes a measured requirement.

The received unit has no exposed BOOT button; the visible onboard button is
GPIO36. If automatic USB flashing fails with normal boot mode `0x13`, follow the
exact RST/DTR rescue procedure in `firmware/puca_bridge/README.md`. Use a normal
jumper between `RST` and `GND`, never a meter in ammeter mode, and never short
`VIN` or `VDD`. This should be emergency access only; ordinary updates use OTA.

## Safe hardware handling now

Before first Eurorack power:

1. Photograph the ribbon orientation.
2. Confirm the red stripe is at `-12 V` on the Eurorack bus.
3. Confirm the board is the Original Edition, not Strawberry Edition.
4. Label the exact AUDIO input. Do not confuse it with CV or TRIG.
5. Never feed a speaker output into PUCA.
6. Keep bare-board input below 3.3 V peak-to-peak; attenuate and isolate a hot
   professional line source.

For the RODE, power it manually; PUCA's line input does not provide the plug-in
power that the microphone may use for automatic power sensing. Start flat and
conservative, exercise the loudest expected source, and preserve roughly 12-18 dB
of digital headroom. Do not run two independent automatic gain loops.

## What must pass before field use

- Original-edition identity, USB ID, and MAC recorded;
- ribbon, knobs, paw, CV, and trigger hardware checked;
- exact RODE jack and codec route identified;
- unclipped levels recorded for bowls, violin, singing, and onboard microphones;
- [x] a native-tested, SHA-reporting `firmware/puca_bridge/` development build
  created (promotion still requires the remaining acceptance evidence);
- [x] no-hold SAFE-IDLE, exact Bridge identity/maintenance, retained-binary OTA,
  post-OTA dark rejoin, and pending-verify survival on `A4EB10`;
- one-fixture direct-frame and three-second fallback proof;
- mixed HEX/RGBW proof;
- packet rate, PDR, CPU load, audio overrun, reset, and multi-hour soak evidence;
- RF/range test in the closed metal Pod20 at intended placement; and
- final RODE/codec gain plus knob/paw functions marked on the field unit.

Until those boxes close, use the CoreS3 audio path.

## Future PUCA troubleshooting map

This is a bring-up map for the development firmware, not a claim of field
acceptance:

| Symptom | Check first |
|---|---|
| Unit does not power in Pod20 | ribbon orientation, `-12 V` stripe, case power |
| Factory WiFi AP appears | still running upstream firmware; Resonance runtime must remove the AP |
| `A4EB10` never appears in Health | PUCA `0.5.0-dev` not installed, channel mismatch, or heartbeat/radio failure |
| Exact-target maintenance refuses | USB bootstrap lacked gitignored shared-WiFi credentials; rebuild once with `--wifi-source` |
| OTA reboot is dark | expected SAFE-IDLE; validate the new revision, then paw-hold a later deliberate boot to perform |
| Knobs/paw do nothing | upstream hardware tests and the final documented firmware assignments |
| RODE is silent | manual mic power, battery, exact AUDIO input, cable, codec LINE/AUX route |
| Audio clips | RODE output, codec gain, input attenuation, 3.3 Vpp limit |
| Audio works but mesh does not | Resonance firmware, unassociated radio, fixed channel 11, canonical packet header |
| Mesh works outside the case but not installed | Pod20 RF shadowing, orientation, placement |
| Lights remain directed after PUCA stops | stop the test and fix stale-frame/failure behavior before any field use |

The detailed bring-up record is
[PUCA performance audio bridge](../../hardware/puca-audio-bridge/README.md).

# Part V: Common field recipes

## Make the whole reachable fleet dark now

Use T-Deck **Rest -> blackout (LED off, radio on)**, select a duration, compare
live/seen, and confirm. This is reversible with **End Blackout**, but it is not
low power.

If energy saving matters more than immediate reachability, use Deep sleep
instead and accept that it cannot be cancelled over the radio.

## Save power overnight

Use T-Deck **Rest -> deep sleep (radio off)**, choose the intended duration, read the
confirmation carefully, and record the pre-command live/seen count. Watch live
fixtures disappear. Record any already-silent units separately; the command did
not prove they slept.

## Find one physical lantern

Open Fleet, select the callsign/ID, and use **Identify**. If the row is absent,
use Health and wait through the sleep cadence before walking to the fixture.

## Check whether the network or one fixture is bad

Open RF. If mesh RX and many peers advance, investigate the one fixture. If the
whole fleet stops at the same time, check T-Deck channel, guard state, bridge
position, and the AP before touching fixtures.

## Start a simple handheld look

Open LEDs, select a class or all, choose color and dim, and confirm the target
count. Stop CoreS3 audio first. Use Stop when finished.

## Start audio-reactive lights

Use the CoreS3 Module Audio recipe. Confirm the T-Deck is not streaming LEDs or
Patterns. Confirm the correct CoreS3 artifact, selector B, `MODULE TRS ON`, live
fixture IDs, and a sane level before program audio begins.

## Ask Claude which lights need attention

From the T-Deck Claude app:

```text
List fixtures quiet for more than 300 seconds, with callsign, short ID,
battery, and last RSSI. Say clearly if the result is truncated.
```

Then verify the result in Health. Claude is a convenient interface to the same
bounded local census, not a separate source of truth.

## Prepare an exact-target OTA

1. Declare the operator, source commit, immutable artifact revision/SHA, exact
   target short MAC, and operation.
2. Ensure the fixture has its production LFP or another proven stable supply for
   reboot ride-through.
3. Use an exact-target maintenance request, never a fleet broadcast by habit.
4. Let the host tool identity-check and upload the already-built binary.
5. Require a fresh post-job heartbeat, exact revision, survival past the
   20-second pending-verify window, and another fresh heartbeat.

An upload acknowledgement is not completion. A cached online flag is not rejoin
proof. Never select an artifact by newest timestamp or `latest`.

# Part VI: Shift cards

## Field operator handoff

- [ ] T-Deck charged; USB-C power available
- [ ] T-Deck identity `8EB508` confirmed
- [ ] launcher shows channel 11
- [ ] live/seen count recorded
- [ ] Health red/yellow/grey exceptions recorded by callsign and short ID
- [ ] active artistic publisher named: none / T-Deck LEDs / T-Deck Patterns / CoreS3 audio
- [ ] any active Dark, Sleep, Schedule, CA, or program lease recorded with expiry
- [ ] no unplanned fixture remains in forced-night bench state
- [ ] T-Deck returned to trusted storage after shift

## IT handoff

- [ ] 2.4 GHz AP verified over the air on channel 11, HT20, WPA2-PSK
- [ ] laptops/phones moved to the separate 5 GHz SSID
- [ ] Starlink/Beryl power and WAN state recorded
- [ ] T-Deck `show`, `probe`, and `mem` captured if diagnosing
- [ ] bridge and fixture identities recorded by MAC, not COM port or IP
- [ ] one operator declared for OTA/USB/NVS work
- [ ] exact artifact revision and SHA recorded before any flash
- [ ] fresh post-pending-verify evidence recorded after OTA
- [ ] logs written to a new path, or intentionally appended to the same logical run

## Audio handoff

- [ ] active audio bridge: CoreS3 / PUCA test bench
- [ ] Bridge OS image and active Audio app confirmed from screen/boot banner
- [ ] RODE charged, gain/filter/pad recorded
- [ ] Module Audio selector B confirmed with power off
- [ ] input says `MODULE TRS ON`; RMS and level are sane
- [ ] one artistic publisher only
- [ ] test fixtures restored to automatic lifecycle
- [ ] stream paused/stopped and three-second fallback observed at end

# Glossary

| Term | Plain-language meaning |
|---|---|
| Bridge | A device that observes or temporarily directs the fleet |
| Callsign | Friendly permanent name used in displays and command entry |
| Short MAC / short ID | Last three MAC bytes, shown as six hex digits; machine identity |
| Census | What the bridge has heard since boot, with freshness and radio evidence |
| Live | Fresh enough to be a plausible immediate command recipient |
| Seen | Heard at some point since bridge boot; may now be asleep or gone |
| ESP-NOW | The local 2.4 GHz fleet radio link |
| Lease | Temporary command that expires without a persistent configuration write |
| Direct frame | Per-fixture RGBW instruction refreshed several times per second |
| Stale fallback | Return to autonomous output about three seconds after direct frames stop |
| Dark | LED rail off while radio remains awake |
| Sleep | Rails and radio off until timer wake |
| Guard | T-Deck protection that drops wrong-channel WiFi and preserves the mesh |
| PDR | Packet delivery ratio; meaningful only with enough observation history |
| NVS | Persistent settings stored on the device |
| Canary | An explicitly named test fixture used before a broader action |

# Maintaining this manual

Update this manual when an app label, safety boundary, field workflow, device
status, or troubleshooting conclusion changes. Keep historical build hashes in
the log rather than turning this guide into another artifact ledger.

The two SVG figures are intentionally repo-native, diffable screen/role maps.
Replace or supplement the launcher map with real device photographs when a clean
camera capture is available. A useful photo set is: launcher, Health with mixed
bands, Fleet detail with callsign/ID, LED Studio, Sleep confirmation, Schedule
GPS status, RF links, RF frames, CoreS3 launcher, Listener, Audio, and
the labeled PUCA front/ribbon/audio connections.

## Sources of truth

- [Bridge OS README](../../firmware/tdeck_bridge/README.md)
- [Bridge OS app roadmap](../../firmware/tdeck_bridge/APP_ROADMAP.md)
- [Bridge OS platform decision](../decisions/0047-bridge-os-tdeck-app-platform.md)
- [LED Studio and Sleep / Dark decision](../decisions/0048-tdeck-led-studio-and-night-rest.md)
- [UTC and schedule decision](../decisions/0049-utc-consensus-civil-twilight-and-operator-overrides.md)
- [CoreS3 bridge README](../../firmware/cores3_bridge/README.md)
- [CoreS3 audio-reactive how-to](CORES3_AUDIO_REACTIVE.md)
- [PUCA hardware and bring-up record](../../hardware/puca-audio-bridge/README.md)
- [Camp network setup](CAMP_NETWORK_SETUP.md)
- [Firmware artifact handoff](FIRMWARE_ARTIFACT_HANDOFF.md)
- [Canonical fixture callsigns](../../ops/fleet/callsigns.csv)
- [Project log](../../LOG.md)
- [Open work](../../TODO.md)

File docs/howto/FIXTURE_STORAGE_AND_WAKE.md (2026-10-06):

# Fixture storage and wake

Updated: 2026-10-06. This is the operator summary for the implemented September
12 storage firmware. It does not authorize a new device operation.

## Choose the wake contract

| T-Deck Rest -> Store option | What happens | How it wakes |
|---|---|---|
| Until USB power (ship) | Untimed BQ25628E ship mode; ESP and output rails off; fuel gauge stays enabled. | Good USB **or solar** input, or QON. RESET/BOOT alone cannot wake an unpowered ESP. |
| Until physical RESET | Untimed ESP deep sleep, output rails off, no timer/GPIO wake. | Physical RESET. USB alone is not its wake trigger. |
| Wake on date | Timed transport sleep to a selected Pacific date/time, 30 minutes to seven days ahead. | ESP timer; radio resumes with outputs latched dark. Requires fresh handheld GPS time; clock drift limits accuracy. |

The date picker rejects ambiguous/repeated or nonexistent DST times. Neither
indefinite mode can be recalled over ESP-NOW. The controller, laptop and Wi-Fi
are unnecessary after storage entry. "USB wake" is the UI shorthand, not a
promise to ignore a connected solar panel.

Storage and PROTECT are separate. Storage does not set or clear the durable
PROTECT latch. RESET, ordinary OTA and ship wake do not themselves clear it;
normal recovery policy still applies. A 12-hour radio sleep is also not a
command to enter PROTECT. See the
[recovery investigation](../tests/PROTECT_RECOVERY_INVESTIGATION_2026-09-14.md).

## Review and operate

1. Obtain a fresh census over a complete 15-minute PROTECT cadence. Name the
   exact intended fixtures; silence does not establish their battery state.
2. Verify compatible fixture firmware/capability and stable power for any
   needed OTA. Installing firmware alone never requests storage. Follow the
   [artifact handoff contract](FIRMWARE_ARTIFACT_HANDOFF.md).
3. On the T-Deck, open Home -> Rest -> Store, select the wake method and exact
   target(s), then review and explicitly confirm. Review freezes the roster,
   method and date; Cancel is initially focused. Keep the handheld and screen
   active through the bounded 16-minute catch-up campaign.
4. Review receipts and failures. Stop/Back prevents further sends but does not
   recall fixtures already asleep. Restarting the handheld never resumes a job.

The fixture refuses storage during maintenance, with good external supply,
without a working battery/power manager, or before OTA verification completes.
It verifies output rails are off and persists the request before acknowledging
PREPARED and attempting entry. PREPARED plus subsequent silence is useful
command evidence, not a measurement of electrical shutdown. Never silently
substitute another wake method after a refusal/failure.

For an explicitly authorized laptop campaign, storage4 also exposes the bounded
USB host flow in the [T-Deck guide](../../firmware/tdeck_bridge/README.md#explicit-usb-host-storage-adr-0081)
and [ADR 0081](../decisions/0081-explicit-host-usb-storage.md).
`ops/bench/fleet_storage_usb.py` requires explicit confirmation, the expected
bridge/revision/channel, exact targets and a new exclusive ledger. It matches
receipt source and sequence, checks late failures and stops the job. A queued
USB write is not proof of fixture storage. Do not replay historical job plans
as a current roster.

## Retained firmware and completed rollout

These are the exact historical artifacts, not a claim that a rebuild of current
main has identical bytes. Preserve their revision, recipe and binary identity.

| Target | Revision | Application bytes | Source commit | Manifest |
|---|---|---:|---|---|
| Fixture | `fx-260912-f951ae9-b` | 1,218,752 | `fcc5ef07ccf65f0f1d034bfe523e9f1d7f68bf10` | [Fixture manifest](../../firmware/fixture/build/fx-260912-f951ae9-b/manifest.json) |
| T-Deck Plus | `tdeck-0.3.0-storage4` | 1,578,224 | `556c2f6cdbefd152a1f79437b9e7f859b7b7fd44` | [Controller manifest](../../firmware/tdeck_bridge/build/storage-host-20260912-r4/manifest.json) |

Fixture application SHA-256:
`ec03b074c6feae7ffc3f6bb2e178ec213ea5d241b56b3e24c95bfbb24d315001`.
T-Deck application SHA-256:
`11b98b33ca46babf21ad27cb1f2edd7cccdf6319a5e130df3e5442fd6260c1b1`.

The fixture image uses FIELD, channel 11, LFP, 300 mA precharge, a basic
listener, 120-second ordinary day sleep and 12-second listening grace. Its
existing `b` suffix is preserved: Ben explicitly approved this exact artifact
for the September storage operation; this is not a general new fleet release.
The controller was flashed to `8EB508` / `44:1B:F6:8E:B5:08`. The September
14 Oakland snapshot found the other controller, `979604`, on older firmware.

On September 12, all 106 observed fixtures passed fresh exact-revision OTA
verification beyond the pending window, then returned matching storage receipts
and durable audits. The final live check recorded at least 38m37s of quiet,
continuous capture and stopped jobs. Eight unobserved baseline fixtures were
not commanded; Kairi and Wooper were later heard in Oakland, leaving six
unlocated as of September 14. Radio reach did not prove container location.
See the [census and rollout](../tests/CONTAINER_STORAGE_CENSUS_2026-09-12.md)
and [retained evidence](../../ops/bench/data/ca/20260912-155847-container/README.md).

## Qualification still open

At service, measure assembled gauge-enabled ship and timerless deep-sleep
current, physically test USB/solar/QON and RESET wake, and inspect the T-Deck
storage/calendar screens. The shipped command path has evidence; these
electrical and physical checks do not yet. Do not apply the vendor's
gauge-disabled 1 uA ship number to this gauge-enabled implementation.

Most modeled savings come from removing recurring radio windows; choosing
ship over uninterrupted deep sleep buys the practical external-power wake.
Cell-terminal measurements are needed to interpret historical very-low
telemetry. Remove external power before battery swaps. Preserve reset,
protection, charger and sleep history before changing a diagnostic specimen.

Implementation contracts: [ADR 0080](../decisions/0080-explicit-container-storage.md)
and [ADR 0081](../decisions/0081-explicit-host-usb-storage.md).

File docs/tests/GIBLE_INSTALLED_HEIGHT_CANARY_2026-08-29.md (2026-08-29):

# Gible installed-height canopy canary -- 2026-08-29

## Purpose

Close ADR 0070's remaining named installed-height range gate on exact hanging
downlight Gible `9E5B34`. Sakura proved the new sensor-to-latch-to-white path
while physically in a bin; this test must prove useful person range on a real
hanging canopy fixture.

## Ownership and scope

- Owner: Ben/Codex laptop bench.
- Bridge: exact T-Deck `8EB508`, channel 11.
- OTA target: Gible `9E5B34` only.
- Artifact class: normal fleetable `p`, immutable ADR 0040 identity.
- Source behavior: ADR 0069 plus ADR 0070 through `ab71b89`, with this test
  contract as the unique clean artifact commit.
- No profile, channel, capacity, class override, NVS, or unrelated fixture
  mutation is authorized.

## Pre-update evidence

At 2026-08-29 03:31 PDT, the fresh dashboard identified Gible as a field-profile
downlight on `fx-260828-658b7d2-p`, automatic class 1, TMF sensor bit `1`, no
class mismatch, NIGHT_SHOW, FULL tier, GH CA, 3.302 V battery, and normal
low-white output. Ben used Fleet Identify and confirmed Gible is hanging in the
installed canopy rather than sitting in a bin.

## OTA acceptance

1. Use one declared OTA writer and exact target `9E5B34`.
2. Require a fresh identity-matching maintenance endpoint and fresh safe power
   evidence before upload.
3. Upload the exact retained binary once; never retry an acknowledged or
   ambiguous upload automatically.
4. Require a heartbeat newer than the job start, the exact expected revision,
   survival through the pending-verify window, field profile, downlight class,
   healthy TMF, recovery state 0, and later fresh presence.

## Installed-height interaction acceptance

With ordinary autonomous CA visible and no direct bridge lease:

1. Record a quiet empty scene first. It must not hold full white continuously.
2. Have one person walk and then stand directly beneath Gible.
3. Require a confident ordinary-height TMF return or debounced presence evidence
   and a visible full dedicated-white response.
4. After the person leaves, require clean release back to ordinary CA.
5. Watch a second empty interval for spontaneous full-white triggers while
   retaining healthy TMF read/error/recovery telemetry.

Wind-driven scanning may cause intermittent or multi-fixture discovery and is
artistically acceptable. The gate is useful named-person range plus clean
release, not continuous lock on a stationary target. If Gible cannot see a
person, do not widen; capture raw range/aim evidence before changing thresholds.

## Artifact and OTA result

The normal canary is immutable revision `fx-260829-7906e6f-p`, 1,212,736
bytes, binary SHA-256
`95df1a6b18f21c0f0643949e70474a4d2af019e85efbb86f21877af350dadb7d`.
Its clean artifact source/test commit is `fe6619f`. Exact one-target OTA job
`A04CDF37` found Gible at `192.168.1.107`, accepted fresh battery evidence,
uploaded once, observed a fresh exact-revision software-reset heartbeat, and
verified the image past the pending-verify gate at 25,122 ms uptime. Gible
reported field profile, downlight class, healthy TMF/MSA sensor bits, no class
mismatch, and recovery state 0.

The first empty and nominal person TMF maintenance censuses both recorded zero
valid depths. Their operator choreography was not controlled tightly enough to
accept or reject the interaction gate, so they are retained as diagnostic
evidence only. Likewise, the first timed four-phase motion trace and the later
condensed trace are not acceptance evidence: the internal-RAM rolling buffer
overwrote part of the timed run, and the condensed choreography forced the
person to move faster than was comfortable.

## Exact-target rolling trace

To remove the stopwatch from the physical experiment, an exact-target-only
trace variant continuously recorded Gible before a human-triggered drain:

- Revision: `fx-260829-1170f20-t`
- Target lock: compile-time short MAC `9E5B34`
- Binary: 1,222,176 bytes
- Binary SHA-256:
  `944abc2ca63ef85e486f6afc12e9672e38a561db265b3ac465903f8c1e5920db`
- Recipe SHA-256:
  `1170f2092de77b59ba93b83a97132e485bbb361045b327e06f177d31666c90ee`

The board has physical PSRAM, but this firmware reported `psram_bytes=0`.
The recorder therefore used its explicit 1,024-sample internal-RAM fallback.
Nominal capacity is about 41 seconds at 25 Hz; cooperative sensor scheduling
made both accepted captures span about 70 seconds of fixture uptime. OTA jobs
`0D400326` and `DA9A38BD` each proved the exact trace revision through the
pending-verify gate. The trace was never widened beyond Gible.

The accepted procedure was deliberately untimed from the person's perspective:
stand or walk naturally, stop when comfortable, then say `capture`. Only then
did the operator start exact-target maintenance and drain the already-recorded
rolling window. This preserves the preceding interaction instead of asking the
person to race a capture deadline.

## Triggered results

The two diagnostic 1,024-sample windows were:

| Condition | Retained span | Positive depth frames | Depth range | Person-range frames | Presence active/rising | Full dedicated W=255 |
| --- | ---: | ---: | ---: | ---: | ---: | ---: |
| Standing beneath Gible | 70.045 s | 48 | 168-363 mm | 0 | 0 / 0 | 0 |
| Natural walk, then stop and capture | 69.366 s | 23 | 166-362 mm | 0 | 0 / 0 | 0 |

Every positive return remained a fixed near-field obstruction. The standing
capture used zones 4 and 7: 12 returns at 357-363 mm and 36 at 168-172 mm. The
walking capture used the same zones: seven returns at 358-362 mm and 16 at
166-172 mm. Neither capture contained a return near the expected roughly
2,700-3,500 mm person range, a debounced presence edge, a held presence latch,
or the required full dedicated-white response.

Ben visually observed Gible turn warm white repeatedly during the natural
walk. The trace agrees: it contains seven separate `W=25` intervals before the
capture trigger. This is not a missed person response. GH CA intentionally
renders a one-pixel point source's quiescent state as dim dedicated warm white
at 25/255; the ADR 0070 interaction clears the frame and drives dedicated white
at 255/255 while the presence latch is active. The trace therefore provides an
important alignment control: the ordinary warm-white states Ben saw are in the
record, while the required full-white state and its owning presence latch are
absent.

## Foolproof sentinel retest

Ben did not accept the earlier visual distinction or trigger timing as
foolproof, so the final retest used an exact-target diagnostic that left the
production presence detector unchanged and made its state visually binary:

- Revision: `fx-260829-e98247b-t`
- Source commit: `ce785c571cc6adc2ddd03145ded11444cd933297`
- Target lock: compile-time short MAC `9E5B34`
- Binary: 1,222,416 bytes
- Binary SHA-256:
  `f19c8e2f597e0baa3145c0c2c450becf07b83a398685da4a21140a6e118d2bdc`
- Recipe SHA-256:
  `e98247b9ddff406e8e16769073792e839b14a9751200aa55853cfa166c15bbb5`
- Promotion state: target-test-only, never fleetable
- No latch: `R=255,G=0,B=0,W=0`
- Presence latch: `R=255,G=255,B=255,W=0`

The sentinel applies only after ordinary program arbitration and only while the
frame is already visible; identify, smoke, blackout, battery, and rail authority
remain unchanged. Native tests passed, including the complete 558-check
presence suite. The 300 ms trace interval gives the internal 1,024-sample
fallback just over five minutes of retained history. Job `C2DFDDB2` updated
only Gible and verified the exact trace revision through pending verify at
23,972 ms uptime. Ben physically confirmed the red baseline.

The T-Deck's exact Gible Identify action supplied two approximately 10-second
green markers. The first occupied sequences 1031-1060 at 369.415-379.119 s
fixture uptime; the second occupied sequences 1501-1530 at 526.360-536.044 s.
The complete retained window was frozen only after the second marker, so the
person was not racing a host-side capture timer. Exact maintenance campaign
`29CC104A` selected only Gible, froze before the drain, and made no NVS or
profile mutation.

Ben reported that he had to trigger with a split held high. The raw record
between the markers contained 46 positive depth frames above 1 m. It asserted
five separate presence edges:

| Rising sequence | Fixture uptime | Trigger depth | Confidence |
| ---: | ---: | ---: | ---: |
| 1395 | 490.974 s | 4,497 mm | 30 |
| 1415 | 497.614 s | 2,508 mm | 47 |
| 1442 | 506.664 s | 2,860 mm | 38 |
| 1459 | 512.330 s | 3,829 mm | 38 |
| 1472 | 516.689 s | 2,504 mm | 59 |

The maximum retained post-parser individual zone was 4,982 mm at confidence 32
(sequence 1471). The maximum closest-target/frame-summary depth was 4,781 mm at
confidence 32 (sequence 1440). Those values prove that the old 2,500 mm parser
cap is absent and that far TMF reports reach the presence gate. They do not, by
themselves, prove accurate or useful physical ranging at 5 m; the raw retest
below rejects that stronger interpretation.
They did not initiate presence because `PRESENCE_MAX_MM` intentionally limits a
previously empty zone to 4,500 mm, separate from the 5,000 mm sensor/parser
limit. A 4,763 mm sample occurred while an earlier latch was still held; it was
not a rising-edge trigger. Most new assertions began at 2,504-2,860 mm, matching
Ben's visual estimate, while the 3,829 and 4,497 mm edges independently prove
operation beyond the old cap.

The five active runs covered sequences 1395-1404, 1415-1430, 1442-1451,
1459-1465, and 1472-1477: 49 samples total. All 49 active samples rendered exact
full RGB white, no inactive sample rendered white, and no active sample remained
red. After the first green marker ended, the recorder retained 111.855 seconds
of red baseline before the first presence edge. After the last white sample it
returned to red for 8.030 seconds before the second green marker.

This is conclusive end-to-end evidence for the installed Gible sensor, full-
range parser, unchanged production debounce/latch, and visible output
arbitration. It also confirms that the remaining failure is not host capture
timing. It is not a useful-person-range pass: ordinary standing/walking did not
trigger, and the successful interaction required the high-held gesture.

## Raw distant-range height/aim retest

Ben pointed out that Gible is less than 5 m high, yet ordinary people did not
trigger it and the bamboo split had to be held much higher, roughly 2 m from the
sensor. To distinguish a software threshold failure from installed physical
range/aim, a final exact-target diagnostic removed every production
discriminator except validity:

- Revision: `fx-260829-4192016-t`
- Source commit: `d9cb77528e646bfb06bf5882202181f8790bca64`
- Target lock: compile-time short MAC `9E5B34`
- Binary: 1,221,136 bytes
- Binary SHA-256:
  `27b9d412d4fe51c44fc37d4adc75a7c2b0481ab2750c13b08f020482773b7fc2`
- Recipe SHA-256:
  `419201645ff0321b58030837faac989ebb8648e108e5429131e0ad696907f113`
- Promotion state: target-test-only, never fleetable
- Active predicate: any confidence >=20 zone with `1,000 <= mm < 5,000`
- Background learning, hit debounce, and hold hysteresis: disabled
- Mesh presence-wave origin/relay: disabled
- No active range: `R=255,G=0,B=0,W=0`
- Active range: `R=255,G=255,B=255,W=0`

The 1 m lower bound deliberately excludes Gible's already-known 166-363 mm
bamboo/sensor self-splay. All native tests passed, including 565 presence
checks and the build-wrapper isolation contract. The fresh embedded build used
1,220,833 bytes program and 68,788 bytes globals. Exact job `AB8F3FA6` updated
only Gible and verified the image through pending verify at 32,289 ms uptime.

Exact campaign `29D15A90` froze the rolling trace after Ben's test. The drain
retained 860 samples spanning 300.500 seconds with zero overwrite and zero
sequence gap. The scene was red for 123.895 seconds before and 142.250 seconds
after the sole 34.355-second interaction window. Neither empty interval
contained a sampled 1-5 m return or white output. The interaction window
contained 45 white samples across 23 raw rising edges. Every sampled 1-5 m
return was white and every sample without one was not white.

The range distribution contradicts the physical target distance:

| Zone-return band | Returns | Confidence range |
| --- | ---: | ---: |
| Known self-splay, 166-358 mm | 3 | 255 |
| 1-<3 m | 0 | -- |
| 3-<4 m | 8 | 22-79 |
| 4-<5 m | 65 | 20-75 |
| Exactly 5,000 mm, raw but excluded | 1 | 49 |

The distant reports covered zones 0-4. Maximum closest-target/frame summary was
4,988 mm; maximum individual zone was exactly 5,000 mm. Yet Ben estimates that
the bamboo split was roughly 2 m from the sensor when it finally triggered.
These far returns are not independent empty-scene noise: they occur only while
the nearby raised target changes the scene. Plausible causes are sensor aim,
partial aperture/splay occlusion, edge/background ranging, or multipath. The
trace cannot distinguish those optical causes, but it does show that the 4-5 m
numbers are not calibrated evidence of a target physically 4-5 m away.

Most importantly, an ordinary person did not trigger even this raw predicate.
The current installation therefore fails before background learning, delta,
debounce, or hold policy matter. Lower or re-aim Gible and inspect/clear the TMF
aperture and field of view before another software threshold change.

## Astro lower-height control

Astro `9E5B44`, reported by Ben as roughly 12 ft high, provided the lower-hung
control using the identical raw 1-5 m predicate. The only recipe change from
Gible was the compile-time target lock:

- Revision: `fx-260829-066846f-t`
- Source commit: `d9cb77528e646bfb06bf5882202181f8790bca64`
- Target lock: compile-time short MAC `9E5B44`
- Binary: 1,221,136 bytes
- Binary SHA-256:
  `b9dba40884967fd182093d1e9ab370a7d40fd89b74f5ccc3ec6588d967636877`
- Recipe SHA-256:
  `066846f139e79f02aaa1ef6709e8618563d544e28bebada4e7db3ecf2cfeba09`
- Promotion state: target-test-only, never fleetable

Exact OTA job `861C9C57` updated only Astro and verified the diagnostic through
pending verify at 31,899 ms uptime. Dawn then put the field fleet into its
scheduled dark posture. Astro accepted a nonpersistent exact-target commission
profile, but a pre-existing RAM-only fleet dark lease still suppressed its
rail. Releasing that lease left field/day fixtures dark and made Astro alone
render the intended full-red baseline. No persistent profile mutation was
made.

Ben's visual result was unambiguous despite increasing dawn light: ordinary
walking beneath Astro produced at most a split-second flicker; raising a hand
above his head made the response substantially denser and appear to stick.
Astro was estimated near 12 ft and Ben is 6 ft 3 in, leaving about 5 ft 9 in
(1.75 m) from sensor to head before a raised-hand gesture.

The rolling drain retained 913 samples spanning 304.3 seconds with zero
sequence gaps. It recorded 35 white samples across 18 sampled runs and 28 raw
rising indications. Individual sampled runs were 0.3-1.62 seconds; grouping
runs separated by at most two seconds produced two principal eight-second
interaction clusters plus shorter clusters. This diagnostic intentionally had
no debounce or hold, so the denser raised-hand response should not be described
as a continuously held production latch.

Every qualifying zone return was 1,003-1,561 mm at confidence 20-41, distributed
across zones 1, 2, 3, and 5. There were no sampled returns from 1.562 m through
5 m. The trace was red for 49.676 seconds before the first white sample and
212.752 seconds after the last, with no sampled 1-5 m false positive in either
empty interval. Fixed self-splay remained visible separately at roughly
171-315 mm with high confidence and was excluded by the diagnostic lower bound.

Dawn is a real negative confound, not a reason to discard the control. It made
the red/white output harder to judge and may have reduced optical ToF range and
confidence. The accepted returns were only confidence 20-41 against a threshold
of 20, so a modest ambient-light penalty could plausibly turn a marginal
roughly-1.75 m head return into intermittent flicker while preserving the closer
raised-hand response. Do not treat 1.561 m as a hard nighttime range limit.
Conversely, the run provides no basis for expecting darkness to turn this into
reliable 3-5 m ranging. Repeat after dark before locking height, and require
margin for shorter people, clothing, dust, sway, and unit variation.

This lower-height control resolves the central Gible ambiguity. A real nearby
target produces physically plausible 1.0-1.56 m ranges on Astro, whereas
Gible reported a roughly 2 m raised bamboo target as 3.24-5.00 m. Astro also
shows that a 12 ft mounting remains marginal for passive walk-under detection:
Ben's roughly 1.75 m head gap was outside the captured reliable band, while a
raised hand moved into it. If ordinary adult walk-under interaction is a goal,
test a roughly 10 ft mounting or equivalent re-aim next; do not infer fleet
acceptance from the raised-hand response alone.

## Verdict

**FAIL -- current Gible sensor geometry; MARGINAL -- Astro at roughly 12 ft;
PASS -- parser and end-to-end software path.** OTA safety, exact artifact
identity, field posture, sensor health,
full-range report acceptance, production debounce/latch, raw predicate, and
output arbitration all passed. The raw retest shows that empty-scene false
positives are not the immediate problem. Gible fails to detect an ordinary
person even without software discrimination, and it reports a nearby raised
bamboo target at physically implausible 3.24-5.00 m distances. Do not
fleet-promote or threshold-tune around this installation. Lower or re-aim it,
clear/inspect the TMF field of view, then repeat the named-person gate. Astro's
plausible 1.0-1.56 m returns prove that lowering helps, but its walk-under
flicker/raised-hand requirement shows that 12 ft is not yet a passive-person
acceptance height.

## Cleanup

Final exact restore job `105DD74F` replaced the raw distant-range trace image
with the normal `fx-260829-7906e6f-p` binary and verified it through the
pending-verify gate at 26,599 ms uptime. A fresh dashboard heartbeat showed field
profile, NIGHT_SHOW, FULL tier, GH CA, downlight class, sensor bits `9`, no class
mismatch, recovery state 0, ordinary mesh mode, and no active maintenance
campaign. No temporary visible lease or trace image remains on Gible.

Astro final restore job `AFF7F2E7` replaced the target-only trace image with
its exact pre-test `fx-260828-658b7d2-p` binary, SHA-256
`95de59286831bcbb9d8f610f84b09e3ac761be558f106b10b9aee8dfb01bd8cc`.
It passed fresh exact-revision rejoin and pending verify at 32,039 ms uptime with
downlight class, field profile, and recovery state 0. The nonpersistent
commission posture cleared on reboot; Astro did not retain a test profile or
trace image.

Retained evidence is under `ops/bench/data/ca/`:

- `20260829-gible-9E5B34-adr0070-canary-job.jsonl`
- `20260829-gible-9E5B34-empty-tmf-census.jsonl`
- `20260829-gible-9E5B34-person-tmf-census.jsonl`
- `20260829-gible-9E5B34-triggered-trace-ota-job.jsonl`
- `20260829-gible-9E5B34-trigger-under-motion.jsonl`
- `20260829-gible-9E5B34-trigger-walk-motion.jsonl`
- `20260829-gible-9E5B34-triggered-trace-final-restore-job.jsonl`
- `20260829-gible-9E5B34-presence-sentinel-trace-ota-job.jsonl`
- `20260829-121148-C2DFDDB2-fleet-ota-results.jsonl`
- `20260829-gible-9E5B34-presence-sentinel-bracketed-split-high.jsonl`
- `20260829-gible-9E5B34-presence-sentinel-final-restore-job.jsonl`
- `20260829-122316-F02313D7-fleet-ota-results.jsonl`
- `20260829-gible-9E5B34-distant-range-height-trace-ota-job.jsonl`
- `20260829-124637-AB8F3FA6-fleet-ota-results.jsonl`
- `20260829-gible-9E5B34-distant-range-bamboo-split-height.jsonl`
- `20260829-gible-9E5B34-distant-range-final-restore-job.jsonl`
- `20260829-125308-105DD74F-fleet-ota-results.jsonl`
- `20260829-astro-9E5B44-distant-range-height-trace-ota-job.jsonl`
- `20260829-astro-9E5B44-lower-height-walk-flicker-raised-hand-stick.jsonl`
- `20260829-astro-9E5B44-lower-height-final-restore-job.jsonl`

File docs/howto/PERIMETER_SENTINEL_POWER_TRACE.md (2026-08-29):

# Perimeter sentinel radio-off + ToF power trace

Use this runbook before implementing any persistent daytime sentinel. The test
image is a short-lived exact-target instrument for one physically confirmed
perimeter fixture. It is never a fleet artifact.

## What the campaign does

After reboot and the 20-second OTA pending-verify window, the fixture runs this
automatic sequence:

1. 10 minutes: ESP-NOW off, VSQT sensor rail off (baseline A).
2. 30 seconds: ESP-NOW off, perimeter MSA311 + VL53L5CX initialize and settle.
3. 10 minutes: ESP-NOW off, MSA311 + VL53L5CX active at the production cadence.
4. 10 minutes: ESP-NOW off, VSQT sensor rail off (baseline B).
5. The fixture starts maintenance WiFi and serves the retained trace.

One-second records include corrected/raw battery current, battery and supply
voltage/current, advisory SOC, power validity, charging and BQ state, explicit
radio and sensor-rail state, VL53 read count/health/closest/near-zone fields,
and the production palm-cover rising edge. A 4,096-sample PSRAM ring holds the
whole run; a reported 1,024-sample internal-RAM fallback cannot hold all 30.5
minutes and is not acceptable for the primary campaign.

## Safety and identity contract

1. Use Fleet Identify and physically confirm one healthy perimeter fixture.
   Confirm its outward VL53L5CX window is unobstructed and reachable for a palm
   test. Do not infer its physical location from telemetry alone.
2. Record exact short MAC, callsign/location, current firmware revision,
   profile, class, sensor state, battery tier, voltage/current, and the exact
   prior artifact path plus SHA-256.
3. Use one OTA writer. Build with `--sentinel-trace-target <SHORT_MAC>` and an
   immutable `-t` revision. The wrapper refuses another special target mode in
   the same image.
4. Target exactly that MAC. Require a production battery, exact endpoint
   identity, fresh exact-revision reboot, and pending-verify survival.
5. Do not send `/resume` during the campaign. The fixture intentionally leaves
   mesh and returns only as maintenance WiFi after the bounded run.
6. Never select test or restore binaries by newest mtime or `latest`.
7. After capture, OTA the exact prior fleet binary and prove fresh mesh rejoin,
   exact revision, pending-verify survival, field profile, perimeter class,
   power state, and MSA311/VL53L5CX health.

## Build shape

Replace every placeholder with the exact named target and a fresh ADR 0040
artifact directory/revision:

```text
firmware/fixture/build.sh \
  --profile field \
  --channel 11 \
  --day-sleep-s 120 \
  --wake-listen-ms 12000 \
  --sentinel-trace-target ABCDEF \
  --fw-rev fx-260829-1234567-t \
  --artifact-dir firmware/fixture/build/fx-260829-1234567-t
```

Build once, inspect the manifest/build options/revision/SHA, and OTA those exact
binary bytes. Do not let an upload command trigger another compile.

## Physical scene

For the cleanest load delta, first run battery-isolated or with the panel
shaded consistently. Do not change cables, fixture orientation, or battery
during A/B/A.

During `tof-active`, perform at least 20 deliberate palm approaches in direct
daylight:

- start from a clearly released sensor;
- bring one hand within the proven close-cover range;
- hold for about one second;
- fully clear for long enough to re-arm;
- note missed responses and rough latency on the field sheet.

Do not trigger the cymbal or LEDs during the power campaign. Repeat later in
full sun to establish net battery current and sunlight detection reliability;
the A/B/A shape helps reject a changing solar or battery trend but does not
make a rapidly moving cloud field controlled evidence.

## Download

Once the fixture automatically appears on maintenance WiFi, recover the entire
campaign. The tool refuses identity, revision, role, target, phase, radio-off,
sensor-rail, and VL53-progress failures and exclusive-creates its output.

```text
python ops/bench/capture_sentinel_trace.py \
  --host 192.168.1.123 \
  --target ABCDEF \
  --expect-fw fx-260829-1234567-t \
  --label battery-isolated-radio-off-vl53-aba \
  --out "ops/bench/data/Black Rock City/2026-08-29-abcdef-sentinel-power.jsonl"
```

The footer reports per-phase mean/median corrected battery current, mean supply
current, palm edges, and VL53 frame delta. Preserve the raw rows; summary values
alone are not the evidence.

## Analysis and promotion gate

- Compare `tof-active` against the mean of baseline A and B. Plot phase time,
  corrected battery current, supply current, VBAT, and charger phase before
  interpreting a single delta.
- Confirm `radio_on=0` throughout all three measurement phases and
  `sensor_rail_on=1` only during `tof-active`.
- Confirm VL53 reads advance steadily, no reset/fault interrupts the run, and
  the palm test has acceptable misses and latency in full sun.
- Convert the measured incremental current into the intended daily sentinel
  duty cycle and subtract it from the 6 Ah perimeter/night budget. Also check
  the full-sun run remains net positive with realistic panel orientation.
- Do not implement fleet wake propagation until Ben accepts the measured
  energy and interaction result. Any later session must have a non-extendable
  deadline and cooldown so visitor popularity cannot make the fleet perpetual.

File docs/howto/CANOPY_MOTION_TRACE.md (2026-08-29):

# Canopy motion trace field run

Use this runbook to measure a hanging downlight's wind-driven two-axis motion
against TMF presence and visible output. The test image is a short-lived,
exact-target instrument. It is never a fleet artifact.

## What the recorder captures

At the fixture's existing 25 Hz cooperative MSA311 cadence:

- raw X/Y/Z acceleration and the low-pass gravity vector, in mg;
- tilt from boot rest, in centidegrees, and the current sway envelope, in mg;
- TMF report sequence, closest depth/confidence, and all nine zone depths and
  confidences;
- the production presence latch and rising edge;
- lifecycle, program, power tier, and the rendered LED rail/color/pixel count.

The recorder stores 8,192 samples in PSRAM, about 5.5 minutes. If PSRAM
allocation fails, it explicitly reports a 1,024-sample, roughly 41-second
internal-RAM fallback. Recording occurs during ordinary mesh/show behavior.
Maintenance mode is used only afterward to drain the retained history, and it
keeps the LED rail off.

## Safety contract

1. Use Fleet Identify and physically confirm the named fixture is hanging and
   free to swing. Do not infer location from telemetry.
2. Record its exact six-digit short MAC, current firmware revision, profile,
   class, power state, and the exact prior artifact/SHA before any write.
3. Declare one OTA writer. The trace build must use
   `--msa-trace-target <SHORT_MAC>` and an immutable `-t` revision. The firmware
   disables recording if the physical short MAC differs from the compiled one.
4. Target that one MAC only. Require a production battery or another proven
   stable supply, exact endpoint identity, fresh post-reboot heartbeat, exact
   test revision, and survival through pending verify.
5. Never select either test or restore binaries by newest mtime or `latest`.
6. After downloading, restore the exact pre-trace fleet artifact unless Ben
   explicitly promotes a different named fleet artifact. Prove fresh rejoin,
   exact revision, pending-verify survival, profile, class, and sensor health.

## Suggested five-minute scene

After the test image has rebooted and TMF has had at least 30 seconds to learn
the hanging background, call out the wall-clock time at each transition:

1. 60 seconds: wind only; nobody under or near the chosen cone.
2. 60 seconds: one person stands still under the nominal fixture position.
3. 60 seconds: that person walks slowly across and back through the swept cone.
4. 60 seconds: person leaves; observe white hold and release.
5. Up to 60 seconds: a second person or a deliberately started gentle swing,
   only if physically safe and useful.

Keep the scene under five minutes so the PSRAM ring retains the whole run.
Write the transition times into the field note immediately; the trace itself
uses monotonic fixture uptime, while the OTA and capture ledgers provide UTC
bookends.

## Download

Enter exact-target maintenance only after the scene. Discover and freeze the
one target, then download the history with `ops/bench/capture_motion_trace.py`.
The tool requires the maintenance IP, exact short MAC, and exact `-t` revision;
it refuses identity/revision/role/MSA/target mismatches and exclusive-creates
the JSONL output.

Example shape (replace every value with the current named run):

```text
python ops/bench/capture_motion_trace.py \
  --host 192.168.1.123 \
  --target ABCDEF \
  --expect-fw fx-260829-1234567-t \
  --history-s 300 \
  --label wind-still-walk-leave \
  --out "ops/bench/data/Black Rock City/2026-08-29-abcdef-canopy-motion.jsonl"
```

Do not use `--live-s` for the primary artistic trace: behavior is paused in
maintenance, so live samples describe a dark maintenance fixture. It exists
only for sensor/readout diagnostics.

## First analysis questions

- What are the two dominant swing periods and how stable are they?
- Does raw/gravity-vector direction predict which TMF zones see a person?
- How often does empty wind create a 300 mm per-zone approach signature?
- How long is a stationary person visible during each cone sweep?
- Does visible white chatter, or does the current latch bridge adjacent sweeps?
- Can sway drive color/phase without attenuating brightness or vetoing the
  desirable wind-assisted scanner behavior?

Prefer modulation from swing phase, direction, hue, or temporal accents. Do not
make MSA motion a blanket brightness reduction or ToF veto.

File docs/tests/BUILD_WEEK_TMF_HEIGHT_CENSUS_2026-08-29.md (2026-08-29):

# Build-week TMF installed-height census -- 2026-08-29 UTC

## Purpose

Determine whether live canopy TMF8820 sensors could distinguish close fixtures
still in shipping bins from fixtures already installed high in the tree, and
use the field geometry to tune canopy presence.

## Method

- Declared one operator on T-Deck bridge `979604`, mesh channel 11.
- Selected all 61 dashboard peers reporting downlight class plus TMF sensor bit.
- Began exact maintenance campaign `207B660F`; no OTA, reboot, persistence, NVS,
  profile, or firmware write was requested.
- Discovered shared-WiFi endpoints for 150 seconds across `192.168.1.0/24` and
  fallback `192.168.4.0/24`.
- Froze the campaign before sampling.
- Recorded six `/telemetry` reads per discovered fixture and then requested
  `/resume` on every endpoint.
- Confirmed all sampled fixtures later returned to mesh with fresh heartbeats.

The immutable JSONL evidence is
`ops/bench/data/Black Rock City/2026-08-29-tmf-installed-height-census-0218UTC.jsonl`.

## Results

- Selected: 61 exact downlights.
- Discovered and sampled: 46.
- Not discovered in the bounded window: 15; these are unsampled, not sensor
  failures.
- Healthy close-return group: 42 fixtures, raw median depth 145-575 mm. Most
  were highly stable across six reads; Robin and Midna had intermittent empty
  frames.
- Clear/no-return group: Panther `9E5A84`, Gible `9E5B34`, Sakura `F2BE0C`, and
  Leia `F40384`, each with raw depth `0,0,0,0,0,0`, TMF read OK, zero read
  errors, zero recoveries, and zero sensor-domain resets.
- No sampled fixture reported a multi-metre value because deployed firmware
  discarded all returns above 2,500 mm before telemetry.
- The census tool initially printed its retained filtered value even when the
  current raw sample was zero. Evidence analysis used `tof_depth_mm` as the
  validity authority; the tool is corrected for future runs.

## Interpretation

The four all-zero nodes are the strongest installed-height candidates, but the
census alone cannot prove physical location. A zero means no confident target
inside the deployed firmware's accepted 80-2,500 mm range, not a literal zero
distance. At the reported roughly 15 ft mounting height, ground is about
4,570 mm away and a standing head is commonly about 2,700-3,200 mm away. Both
were outside the deployed software window even though the TMF8820 hardware is
specified through 5,000 mm.

ADR 0070 records the resulting role-specific change. Perimeter keeps its close
chest-height distance mapping. Canopy accepts the full 5 m sensor range and uses
learned per-zone background delta plus a persistent presence latch.

## Sakura post-update canary

Clean artifact `fx-260829-8790f6d-p` was exact-OTA canaried only on Sakura
`F2BE0C`. Job `C804CF1F` passed fresh maintenance power, exact endpoint
identity, upload acknowledgement, fresh exact-revision rejoin, and the pending-
verify survival gate. A post-update six-sample read still reported zero raw
depth with healthy TMF status and no errors/recoveries/resets, confirming a
stable empty high scene under the full-range parser.

An exact CA lease made the fixture visibly baseline-white at `W=25`. Eight
minutes of fresh heartbeat monitoring saw no spontaneous `W=255` transition.
The lease was explicitly released and Sakura remained on mesh. A human was not
confirmed beneath the fixture, so this passes empty-scene stability but does
not yet pass installed human detection. The exact OTA, uploader, post-update
TMF, and interaction-watch JSONL ledgers are retained beside the census.

## Windy-night physical follow-up

Ben used Fleet Identify and found Sakura in a bin. This corrects the earlier
physical inference: Sakura's all-zero samples represented an open/clear view
from the bin, not an installed-height ground measurement. When aimed at Ben,
Sakura changed to full white, visually passing the updated artifact's complete
sensor-to-output path. People walking beneath the installed tree also caused
canopy lights to turn white as intended.

The night was windy. Installed lanterns were visibly swinging in a chaotic
two-axis pendulum motion, so their sensor cones swept across the interaction
area. A stationary person could trigger several nearby lights at different
times as those fixtures happened to swing toward them. Future analysis must
model this as a moving sensor encountering a moving or stationary person, not a
fixed sensor tracking only a moving object. The next evidence run should align
TMF per-zone/depth/confidence, MSA311 sway, and rendered white state for empty
wind, stationary-person, walking, and departure periods. No threshold was
changed from this qualitative observation.

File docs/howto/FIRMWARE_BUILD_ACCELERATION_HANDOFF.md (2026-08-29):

# Firmware Build Acceleration — 80/20 Codex Handoff

**Status:** Adoption complete on `codex/build-acceleration-plan` as an opt-in
local path; job-count and one-device hardware follow-ups are deferred. See
`docs/tests/FIRMWARE_BUILD_ACCELERATION_SMOKE_2026-08-22.md`.
**Date:** 2026-08-22  
**Repository:** `beneckart/resonance-lighting`  
**Working branch:** `codex/build-acceleration-plan`  
**Base at handoff:** `main` at `dfb4c95`  
**Primary target:** `firmware/fixture/build.sh` on the Windows + Git Bash PowerFeather bench

**2026-08-29 artifact-path update:** this document preserves the original
cache experiment, including historical `--artifact-dir`/`--fw-rev` commands.
Those manual release options are now disabled. Current immutable builds use
`--artifact-variant` plus an explicit `--wifi-profile-label`; see
`FIRMWARE_ARTIFACT_HANDOFF.md`. The development-cache design is unchanged.

## Objective

Reduce the normal edit → compile → flash iteration time without reintroducing the cache corruption and agent churn that previously occurred when multiple Arduino builds wrote the same cache concurrently.

The 80/20 hypothesis is:

> The largest avoidable cost is not the absence of `-j8`; it is that the normal wrapper intentionally creates and deletes a unique `--build-path` on every run, forcing a cold ESP32/Arduino build each time.

The proposed order of operations is therefore:

1. Prove that retaining one build directory produces a meaningful warm-build speedup, using the current wrapper and no code changes.
2. Only if the speedup is substantial, add one opt-in persistent development cache with exactly one writer.
3. Stress the lock, recipe invalidation, and interrupted-build recovery.
4. Adopt the new local build rule only if both performance and safety gates pass.
5. Keep release and fleet artifacts on the existing fresh, immutable artifact path.

This is deliberately not a build-system migration. Do not start with PlatformIO, ESP-IDF, CMake, Ninja, `ccache`, distributed compilation, or a repo-wide build rewrite.

---

## Repository facts and constraints

The current fixture wrapper does the safe but expensive thing for ordinary builds:

```bash
BUILD_PATH="$(mktemp -d /tmp/fixture-build.XXXXXX)"
trap 'rm -rf "$BUILD_PATH"' EXIT
arduino-cli compile --build-path "$BUILD_PATH" ...
```

When `--artifact-dir` is supplied, the wrapper instead reuses the requested path. That existing option gives us a low-risk way to measure incremental behavior before adding any new cache logic.

`AGENTS.md` records the reason for the present design:

- Concurrent Arduino compiles against the same cache can collide with errors such as `unlinkat ... directory is not empty` and can produce mixed/corrupt artifacts.
- A killed build directory may contain a partial `core/core.a` and later produce misleading linker failures such as `bad reloc symbol index`.
- An uncached PowerFeather/ESP32-S3 build on the Windows bench has historically taken roughly 2–3 minutes.

The artifact-handoff contract must remain intact:

- Shared/fleetable builds have an immutable `fw_rev` and exact binary SHA-256.
- One `fw_rev` maps to one binary.
- Fleet tooling uploads an inspected artifact rather than rebuilding it.
- A killed build directory is never resumed.

## Non-negotiable invariants

Any implementation must preserve all of the following:

1. **One writer per build directory.** Two compiler processes must never write the same build path concurrently.
2. **Interrupted means untrusted.** A development cache active during a hard kill, timeout, or abandoned compiler process is quarantined or deleted before reuse.
3. **Development is not release.** A cached local binary must report an unmistakably non-fleet identity such as `dev-local` and must not be offered to fleet OTA tooling.
4. **Release artifacts stay fresh and immutable.** `--artifact-dir build/<fw_rev> --fw-rev <fw_rev>` remains a separate path.
5. **Current behavior remains the rollback.** A normal invocation without the new option still receives a fresh temporary build path.
6. **No hardware during cache stress.** Concurrency, recipe-change, stale-lock, and interrupted-build tests are compile-only. At most one explicitly selected sacrificial USB fixture is flashed after host-side gates pass.

---

# Phase 0 — Prove the opportunity without changing code

Run this phase on the actual slow Windows/Git Bash bench. The point is to answer one question cheaply:

> Does reusing the existing Arduino build directory save enough time to justify lock and recovery machinery?

## Preconditions

From a clean checkout of the intended source:

```bash
cd firmware/fixture

git status --short
git rev-parse HEAD
arduino-cli version
arduino-cli core list

# Confirm another agent/operator is not compiling firmware.
ps -W | grep -Ei 'arduino-cli|xtensa|esptool' || true

./tests/run_tests.sh
```

Stop if native tests fail or another compiler is active.

Phase 0 is **compile-only**:

- Do not pass `--port`.
- Do not pass `--ota`.
- Do not pass `--fw-rev`.
- Use exactly the same profile, channel, chemistry, precharge setting, and other compile flags in every timed run.
- Only one process may touch `build/cache-proof`.

Avoiding `--fw-rev` matters because the current wrapper force-includes a generated identity header. Changing that header can invalidate a large fraction of translation units and would make the warm-path experiment pessimistic for reasons unrelated to ordinary source iteration.

## Timing helper

```bash
mkdir -p build/build-accel-smoke
rm -f build/build-accel-smoke/times.csv
printf 'label,seconds,rc\n' > build/build-accel-smoke/times.csv

run_timed() {
  local label="$1"
  shift
  local log="build/build-accel-smoke/${label}.log"
  local start=$SECONDS

  set +e
  "$@" 2>&1 | tee "$log"
  local rc=${PIPESTATUS[0]}
  set -e

  local elapsed=$((SECONDS - start))
  printf '%s,%s,%s\n' "$label" "$elapsed" "$rc" \
    | tee -a build/build-accel-smoke/times.csv
  return "$rc"
}
```

If the interactive shell is not already using `set -e`, the helper still records return codes; inspect them before continuing.

## A. Establish the current cold baseline

Run at least two ordinary builds. Each should receive and discard a fresh temporary build path.

```bash
run_timed cold-default-1 \
  ./build.sh --profile commission --channel 11

run_timed cold-default-2 \
  ./build.sh --profile commission --channel 11
```

Three trials are preferable if the machine is noisy.

## B. Measure retained-build behavior using the existing wrapper

```bash
rm -rf build/cache-proof

run_timed retained-cold \
  ./build.sh \
    --artifact-dir build/cache-proof \
    --profile commission \
    --channel 11

sha256sum build/cache-proof/fixture.ino.bin \
  | tee build/build-accel-smoke/sha-retained-cold.txt

run_timed retained-noop-1 \
  ./build.sh \
    --artifact-dir build/cache-proof \
    --profile commission \
    --channel 11

run_timed retained-noop-2 \
  ./build.sh \
    --artifact-dir build/cache-proof \
    --profile commission \
    --channel 11

sha256sum build/cache-proof/fixture.ino.bin \
  | tee build/build-accel-smoke/sha-retained-noop.txt

test -s build/cache-proof/fixture.ino.bin
test -s build/cache-proof/build.options.json
```

Record whether the second and third calls compile anything, relink only, or return almost immediately.

A no-op SHA difference is worth recording, but it is not automatically a cache failure: toolchains are not always reproducible across relinks. The correctness rule is still that a shared immutable revision is built once and never overwritten. This proof directory is not a shared artifact.

## C. Measure a representative leaf-source edit

A timestamp-only touch asks the dependency graph to rebuild one translation unit without changing tracked content:

```bash
touch src/core/choreo/prog_idle.cpp

run_timed retained-leaf-touch \
  ./build.sh \
    --artifact-dir build/cache-proof \
    --profile commission \
    --channel 11

sha256sum build/cache-proof/fixture.ino.bin \
  | tee build/build-accel-smoke/sha-retained-leaf.txt
```

This approximates the common case: edit one `.cpp`, compile the changed unit, then link.

## D. Optional high-fanout probe

This is context, not a success criterion. Touching a common protocol header should trigger a broad rebuild:

```bash
touch src/core/packet.h

run_timed retained-common-header \
  ./build.sh \
    --artifact-dir build/cache-proof \
    --profile commission \
    --channel 11
```

A common-header build near cold speed does not disprove the optimization. Incremental builds cannot avoid recompiling consumers of a changed header.

## E. Summarize the result

```bash
python - <<'PY'
import csv
from pathlib import Path
from statistics import median

rows = list(csv.DictReader(Path('build/build-accel-smoke/times.csv').open()))
values = {r['label']: int(r['seconds']) for r in rows if r['rc'] == '0'}

cold = median([values['cold-default-1'], values['cold-default-2']])
noop = median([values['retained-noop-1'], values['retained-noop-2']])
leaf = values['retained-leaf-touch']

print(f'cold median:       {cold:.1f}s')
print(f'warm no-op median: {noop:.1f}s  ({cold/noop:.2f}x faster; {noop/cold:.1%} of cold)')
print(f'leaf touch:        {leaf:.1f}s  ({cold/leaf:.2f}x faster; {leaf/cold:.1%} of cold)')
PY
```

## Phase 0 go/no-go gate

Proceed to implementation only if all of these are true:

- Every timed build returns zero.
- `fixture.ino.bin` and `build.options.json` exist and are non-empty.
- Warm no-op median is **≤ 50% of cold median** and saves **at least 45 seconds**.
- Leaf-touch time is **≤ 75% of cold median** and saves **at least 30 seconds**.
- Logs contain no `unlinkat`, `directory is not empty`, `bad reloc`, corrupt archive, missing object, or mixed-artifact symptom.
- The retained build’s compile output is consistent with dependency reuse rather than an unexplained skipped build.

If the gate fails, document the numbers and stop. Do not add cache coordination complexity for a marginal gain. The next low-cost investigation would be explicit `--jobs` benchmarking and verbose compile tracing.

After preserving the logs, delete the unsafe proof cache:

```bash
rm -rf build/cache-proof
```

---

# Phase 1 — Minimal implementation, only after Phase 0 passes

Limit the first implementation to `firmware/fixture/build.sh`, a small helper only if needed, one smoke script, and the development identity branch in `src/core/version.h`.

## Proposed command surface

Add:

```text
--dev-cache             use the persistent, locked local development build path
--jobs N                pass N to arduino-cli compile --jobs
--clean-dev-cache       safely remove a healthy, unlocked cache
--recover-dev-cache     quarantine a stale/interrupted cache after process checks
```

Examples:

```bash
# Fast compile-only local iteration
./build.sh --dev-cache --jobs 0 --profile commission --channel 11

# Fast compile + one explicitly selected USB bench fixture
./build.sh --dev-cache --jobs 0 --profile commission --channel 11 --port COM42

# Shared/fleet artifact: unchanged, fresh, named, immutable
./build.sh \
  --artifact-dir build/<fw_rev> \
  --fw-rev <fw_rev> \
  --profile commission \
  --channel 11
```

Hard incompatibilities for the first version:

- Reject `--dev-cache` with `--artifact-dir`.
- Reject `--dev-cache` with `--fw-rev`.
- Reject `--dev-cache` with `--ota`.
- Continue requiring a fresh test-class artifact for targeted safety bypasses.

The initial scope allows `--port` because local USB flashing is explicit and fast. OTA stays outside the development-cache path until the fleet boundary is proven in practice.

## One persistent cache, one lock

Use one ignored local cache:

```text
firmware/fixture/build/dev-cache/
```

Use a sibling lock acquired with atomic directory creation:

```text
firmware/fixture/build/dev-cache.lock.d/
```

The lock directory should contain:

```text
pid
hostname
started_epoch
command.txt
```

Required behavior:

1. Successful `mkdir` means the caller owns the cache.
2. If the lock exists and its same-host PID is alive, print a clear wait message and wait for bounded time rather than starting another compiler.
3. If the lock exists but the PID is dead or cannot be trusted, fail closed with instructions to use `--recover-dev-cache`.
4. `--recover-dev-cache` must first check for lingering `arduino-cli`, Xtensa compiler, linker, `esptool`, and child processes. If process state is uncertain, abort rather than deleting under a live compiler.
5. Recovery renames the cache and lock into a timestamped quarantine rather than resuming them.
6. Normal exits release the lock through a trap.

Emit grep-friendly state lines:

```text
DEV_CACHE_WAIT
DEV_CACHE_ACQUIRED
DEV_CACHE_HIT
DEV_CACHE_RESET
DEV_CACHE_INTERRUPTED
DEV_CACHE_QUARANTINED
DEV_CACHE_RELEASED
```

A single global cache intentionally serializes cached fixture recipes. This is the 80/20 choice: simple, inspectable, and safe. Do not begin with multiple cache shards.

## Interrupted-build marker

Create this immediately before launching Arduino CLI:

```text
build/dev-cache/.build-in-progress
```

The marker should include PID, hostname, start time, and recipe fingerprint.

Behavior:

- Remove it after Arduino CLI returns, including after an ordinary compiler error.
- If the wrapper is hard-killed before Arduino CLI returns, the marker remains.
- A future `--dev-cache` invocation that sees the marker fails closed and requires recovery.
- Recovery quarantines the entire cache; it never resumes a possibly partial `core/core.a`.

A successful cached compile still requires:

- Arduino CLI exit code zero.
- Non-empty `fixture.ino.bin`.
- Non-empty `build.options.json`.
- Printed binary SHA-256.

## Recipe fingerprint

Store a deterministic recipe fingerprint beside the cache. At minimum include:

- Cache schema version.
- Absolute sketch path.
- FQBN.
- Canonicalized compiler flags and selected compile posture.
- Arduino CLI version.
- Installed ESP32 platform version.
- PowerFeather SDK version.
- Firmware-affecting Arduino library versions.

Do **not** include:

- Git commit.
- Source file hashes.
- Source modification times.
- `--jobs`.
- Serial port.
- Log paths.

Source changes are what Arduino dependency files are meant to detect incrementally. Putting the commit or source hash in the cache key would make every commit cold again.

When the recipe fingerprint changes, reset the cache while holding the lock and log the reason. Never reuse objects across different FQBNs, flags, platform versions, or library versions.

## Development firmware identity

Cached local builds must not report the current fallback `fx-*` identity or a supplied immutable revision.

Add a build flag such as:

```text
-DRES_DEV_BUILD=1
```

and make `src/core/version.h` resolve it to:

```text
dev-local
```

Preserve explicit immutable identity precedence. Conceptually:

```cpp
#ifndef RES_FIXTURE_VERSION
  #ifdef RES_DEV_BUILD
    #define RES_FIXTURE_VERSION "dev-local"
  #else
    #define RES_FIXTURE_VERSION "<existing fallback>"
  #endif
#endif
```

This is a safety boundary, not cosmetic labeling. `dev-local` explicitly means that the same reported string can correspond to changing local bytes and therefore cannot be promoted as a fleet artifact.

## Compiler job control

Pass a validated value to Arduino CLI:

```bash
arduino-cli compile --jobs "$JOBS" ...
```

Support `ARDUINO_JOBS` as an environment default and `--jobs` as the command-line override.

Measure rather than assume:

- `--jobs 1`: serial reference.
- `--jobs 4`: conservative parallelism.
- `--jobs 0`: use available CPU cores.

Job parallelism is secondary to cache reuse. Do not launch several outer builds that each request all cores.

---

# Phase 2 — Smoke and adversarial safety checks

Add a host-only script such as:

```text
firmware/fixture/tests/smoke_build_cache.sh
```

It must not flash or OTA by default.

## 1. Static and native checks

```bash
bash -n firmware/fixture/build.sh
firmware/fixture/tests/run_tests.sh

cd firmware/fixture
rm -rf build/dev-cache build/dev-cache.lock.d build/dev-cache.quarantine.*

./build.sh --dev-cache --jobs 2 --profile commission --channel 11
./build.sh --dev-cache --jobs 2 --profile commission --channel 11
```

The second build must announce a matching recipe and warm-cache reuse.

## 2. Same-recipe concurrency simulation

Start two compile-only callers against the same cache. The second must wait; it must never enter Arduino CLI while the first owns the lock.

```bash
cd firmware/fixture
rm -rf build/dev-cache build/dev-cache.lock.d
rm -f /tmp/res-build-a.log /tmp/res-build-b.log \
      /tmp/res-build-a.rc /tmp/res-build-b.rc

(
  ./build.sh --dev-cache --jobs 2 --profile commission --channel 11 \
    > /tmp/res-build-a.log 2>&1
  printf '%s\n' "$?" > /tmp/res-build-a.rc
) &
a_pid=$!

sleep 2

(
  ./build.sh --dev-cache --jobs 2 --profile commission --channel 11 \
    > /tmp/res-build-b.log 2>&1
  printf '%s\n' "$?" > /tmp/res-build-b.rc
) &
b_pid=$!

wait "$a_pid"
wait "$b_pid"

cat /tmp/res-build-a.rc /tmp/res-build-b.rc
grep -H -E 'DEV_CACHE_(WAIT|ACQUIRED|HIT|RELEASED)' \
  /tmp/res-build-a.log /tmp/res-build-b.log

grep -H -Ei 'unlinkat|directory is not empty|bad reloc|corrupt|core\.a' \
  /tmp/res-build-a.log /tmp/res-build-b.log && exit 1 || true

test -s build/dev-cache/fixture.ino.bin
test -s build/dev-cache/build.options.json
```

Pass conditions:

- Both invocations return zero.
- Only one process owns the cache at a time.
- Caller B logs `DEV_CACHE_WAIT`, or acquires only after A logs release.
- B completes as a warm/no-op build rather than starting a second cold compiler.
- No corruption signature appears.

Repeat this pair **five times** before adoption.

## 3. Different-recipe serialization and invalidation

Launch commission and field recipes nearly together:

```bash
(
  ./build.sh --dev-cache --jobs 2 --profile commission --channel 11 \
    > /tmp/res-recipe-a.log 2>&1
) &
a_pid=$!

sleep 2

(
  ./build.sh --dev-cache --jobs 2 --profile field --channel 11 \
    > /tmp/res-recipe-b.log 2>&1
) &
b_pid=$!

wait "$a_pid"
wait "$b_pid"

grep -H -E 'DEV_CACHE_(WAIT|ACQUIRED|RESET|RELEASED)' \
  /tmp/res-recipe-a.log /tmp/res-recipe-b.log
```

Pass conditions:

- The recipes serialize.
- The second caller detects a recipe mismatch after acquiring the lock.
- It resets the cache before compiling.
- Both builds succeed without mixed objects.

## 4. Hard-interruption and recovery simulation

Do not kill a real compiler merely to test recovery. Add a test-only hook that pauses after acquiring the lock and writing `.build-in-progress`, but before spawning Arduino CLI:

```text
RES_BUILD_TEST_PAUSE_AFTER_MARKER=<seconds>
```

The hook must be inert unless explicitly set.

Test:

```bash
rm -rf build/dev-cache build/dev-cache.lock.d build/dev-cache.quarantine.*

RES_BUILD_TEST_PAUSE_AFTER_MARKER=30 \
  ./build.sh --dev-cache --jobs 1 --profile commission --channel 11 \
  > /tmp/res-interrupt.log 2>&1 &
interrupted_pid=$!

sleep 3
kill -9 "$interrupted_pid"
wait "$interrupted_pid" || true

# Ordinary reuse must fail closed.
if ./build.sh --dev-cache --jobs 1 --profile commission --channel 11 \
     > /tmp/res-after-kill.log 2>&1; then
  echo 'ERROR: interrupted cache was reused' >&2
  exit 1
fi

grep -E 'DEV_CACHE_INTERRUPTED|recover-dev-cache' /tmp/res-after-kill.log

# Explicit recovery quarantines it after process checks.
./build.sh --recover-dev-cache

./build.sh --dev-cache --jobs 1 --profile commission --channel 11 \
  > /tmp/res-recovered.log 2>&1

grep -E 'DEV_CACHE_(QUARANTINED|ACQUIRED|RELEASED)' \
  /tmp/res-recovered.log build/dev-cache.quarantine.*/recovery.log 2>/dev/null || true

test -s build/dev-cache/fixture.ino.bin
```

Pass condition: the interrupted directory is never resumed; recovery produces a new cold build.

## 5. Stale-lock simulation

Create a fake same-host dead-PID lock:

```bash
rm -rf build/dev-cache.lock.d
mkdir -p build/dev-cache.lock.d
printf '99999999\n' > build/dev-cache.lock.d/pid
hostname > build/dev-cache.lock.d/hostname
printf '0\n' > build/dev-cache.lock.d/started_epoch

if ./build.sh --dev-cache --jobs 1 --profile commission --channel 11 \
     > /tmp/res-stale-lock.log 2>&1; then
  echo 'ERROR: stale lock was silently bypassed' >&2
  exit 1
fi

grep -E 'stale|recover-dev-cache|DEV_CACHE_INTERRUPTED' \
  /tmp/res-stale-lock.log
```

Pass condition: the wrapper fails closed and requires explicit recovery. It must not infer that a dead wrapper implies a trustworthy cache.

## 6. Ordinary compiler-error behavior

Introduce a temporary, unmistakable syntax error in a leaf source, run the cached build, then restore the file with Git. Do this only in a disposable worktree.

Expected behavior:

- Compiler returns nonzero.
- The wrapper releases the lock.
- `.build-in-progress` is removed because Arduino CLI returned normally.
- The next corrected build may reuse valid prior objects.
- A compile error must not be confused with a hard interruption.

## 7. Development identity and fleet boundary

Before touching hardware:

- Confirm cached build options contain `RES_DEV_BUILD=1`.
- Confirm a normal fresh build does not contain it.
- Confirm these combinations fail before compilation/upload:

```bash
./build.sh --dev-cache --ota 10.0.0.200
./build.sh --dev-cache --artifact-dir build/nope
./build.sh --dev-cache --fw-rev fx-260822-0000000-t
```

After every host-only gate passes, flash at most one explicitly selected USB bench fixture:

```bash
./build.sh \
  --dev-cache \
  --jobs 0 \
  --profile commission \
  --channel 11 \
  --port <ONE_EXPLICIT_PORT>
```

Verify fresh serial/heartbeat evidence reports exactly:

```text
dev-local
```

Do not use the dev cache binary with fleet USB bring-up or OTA tooling.

## 8. Fresh/release-path regression

Verify the existing path still works unchanged:

```bash
./build.sh --profile commission --channel 11
```

It should announce a new temporary build path and remove it afterward.

Separately, if a release-path test is warranted, create a brand-new test-class revision according to `docs/howto/FIRMWARE_ARTIFACT_HANDOFF.md`. Never reuse an existing `fw_rev`. Verify its directory, identity header, options, binary, and SHA are independent of `build/dev-cache`.

---

# Phase 3 — Before/after performance report

Use the same machine, source, recipe, and idle conditions as Phase 0.

Collect at least:

- 3 fresh builds using the normal temporary path.
- 3 warm no-op `--dev-cache` builds.
- 3 leaf-touch `--dev-cache` builds, touching the same leaf `.cpp` before each run.
- 1 common-header touch for context.
- Cold builds with `--jobs 1`, `--jobs 4`, and `--jobs 0`; repeat any close comparison.
- Five same-recipe concurrency pairs.

Write the evidence to:

```text
docs/tests/FIRMWARE_BUILD_ACCELERATION_SMOKE_2026-08-22.md
```

Include:

- Git commit and dirty state.
- Machine/CPU/RAM summary.
- Arduino CLI, ESP32 platform, PowerFeather SDK, and library versions.
- Exact commands.
- Raw elapsed times and medians.
- Relevant compiler output.
- Cache-state transitions.
- Binary SHA observations.
- Concurrency, interruption, stale-lock, and recipe-change results.
- Any quarantine directories created.

Use this table:

| Case | Trials | Median seconds | % of fresh median | Speedup | Gate |
|---|---:|---:|---:|---:|---|
| Fresh current path | 3 |  | 100% | 1.00× | reference |
| Dev cache no-op | 3 |  |  |  |  |
| Dev cache leaf touch | 3 |  |  |  |  |
| Dev cache common header | 1 |  |  |  | context |
| Fresh `jobs=1` | 2+ |  |  |  | context |
| Fresh `jobs=4` | 2+ |  |  |  | context |
| Fresh `jobs=0` | 2+ |  |  |  | context |

---

# Adoption gates

Adopt the new local rule only when **every safety gate** and **both performance gates** pass.

## Performance gates

- Warm no-op median is **≤ 40% of fresh median** and saves **at least 45 seconds**.
- Leaf-touch median is **≤ 65% of fresh median** and saves **at least 30 seconds**.
- The recommended job count is based on measured repeatable improvement and does not cause memory pressure or machine-wide oversubscription.

Cache reuse may be adopted even if `--jobs 0` adds little. Avoiding work is the primary win.

## Safety gates

- Five same-recipe concurrent pairs pass with one writer at a time.
- Different recipes serialize and invalidate incompatible state.
- A hard-interrupted cache is refused and quarantined before reuse.
- A stale lock fails closed.
- An ordinary compiler error releases the lock correctly.
- Native fixture tests pass.
- A normal fresh build still works unchanged.
- The immutable artifact path remains independent.
- Cached binaries report `dev-local`.
- `--dev-cache` cannot use OTA, `--fw-rev`, or `--artifact-dir`.
- No cache-corruption signature appears.

## No-go conditions

Do not adopt if any of these occurs:

- Warm no-op improvement is less than 2× or saves less than 45 seconds.
- Two ordinary shell invocations can both enter the cache.
- Recipe changes reuse incompatible objects.
- An interrupted cache can be resumed.
- A cached binary can be mistaken for a fleetable `fx-*` artifact.
- Release/fleet safety has to be weakened to make local caching work.

---

# Adoption action

If the gates pass:

1. Keep `--dev-cache` as the documented/recommended command for interactive local compile and one-device USB iteration.
2. Keep ordinary fresh builds available and keep all named fleet artifacts separate.
3. Update `AGENTS.md` to state:
   - use `--dev-cache` for iterative fixture work;
   - rely on its lock rather than starting another compile;
   - never point direct parallel Arduino CLI calls at the cache;
   - interrupted caches require explicit recovery;
   - shared/fleet artifacts remain fresh and immutable.
4. Update `firmware/fixture/README.md` with local-development versus release commands and the meaning of `dev-local`.
5. Commit the smoke script and dated evidence report.
6. Add a dated `LOG.md` entry with the measured before/after result and safety evidence.
7. Merge the implementation only with the evidence report and rollback path in the same branch.

Adoption does **not** mean promoting the development directory. A release is still a fresh named build from reviewed source.

# Rollback

Operational rollback is immediate:

```bash
cd firmware/fixture
./build.sh --clean-dev-cache || true
./build.sh --profile commission --channel 11
```

If the cache is interrupted:

```bash
./build.sh --recover-dev-cache
./build.sh --profile commission --channel 11
```

Code rollback removes the `--dev-cache`/lock/recovery plumbing and the `RES_DEV_BUILD` version branch. The current temporary-build behavior remains the known-safe fallback throughout the experiment.

---

# Codex execution checklist

- [x] Base `codex/build-acceleration-plan` on the latest intended `main` before implementation.
- [x] Read `AGENTS.md`, ADR 0040, and `docs/howto/FIRMWARE_ARTIFACT_HANDOFF.md`.
- [x] Run Phase 0 with the unmodified wrapper and record raw results.
- [x] Confirm the Phase 0 performance gate passes before continuing.
- [x] Implement only the narrow Phase 1 surface.
- [x] Add the host-only smoke script.
- [x] Run static and native tests.
- [x] Run five same-recipe concurrency pairs.
- [x] Run different-recipe, hard-interruption, stale-lock, and ordinary-error tests.
- [x] Verify development identity and fleet boundaries.
- [ ] Flash only one explicitly named USB bench fixture (optional follow-up; not required for host adoption).
- [x] Run the Phase 3 before/after comparison.
- [x] Write `docs/tests/FIRMWARE_BUILD_ACCELERATION_SMOKE_2026-08-22.md`.
- [x] Update build rules and documentation after adoption gates passed.
- [x] Keep implementation, evidence, and rollback together on this branch; merge remains a review action.

# Deferred follow-up

Only after the fixture cache is measured and stable, consider the next low-risk bottleneck: `firmware/fixture/tests/run_tests.sh` currently recompiles all core `.cpp` files for each `test_*.cpp` executable. Compiling core objects once and linking each test against them could materially shorten native tests.

Keep that as a separate change. Also defer `ccache`, other sketch wrappers, multiple cache shards, and build-system migration until measurements show they are worth the complexity.

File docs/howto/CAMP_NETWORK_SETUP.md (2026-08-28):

# Camp network setup: Starlink + Beryl AX on channel 11

Runbook for standing up the camp/art-site network so it can coexist with the
ESP-NOW fleet. Decision and rationale: `docs/decisions/0036-camp-network-channel-11-ap.md`.

**Do the home rehearsal (section 2) before the event.** The Starlink bypass-mode
switch is not field-improvisable: leaving bypass mode requires a factory reset.

---

## 1. Why the channel matters

The ESP32-S3 has one 2.4 GHz radio. WiFi STA and ESP-NOW share it, and in STA
mode **the access point picks the channel**. The fleet is pinned to channel 11.

An AP on automatic channel selection lands on 1 or 6 most of the time. Any
device that associates to it drags its radio off 11 and goes deaf to the entire
fleet -- silently. No error, no log line, the mesh just stops arriving.

This affects any device that is on the mesh and the network at the same time:
a Claude handheld (ADR 0037), or a laptop-plus-bridge session while the fleet is
live. It does **not** affect fixtures doing normal shows (no infrastructure
needed at all) or fixtures in OTA maintenance mode (they have already left
ESP-NOW by design).

---

## 2. Home rehearsal (do this before the playa)

### 2.1 Starlink generation -- resolved

The project has **Gen 3 and Gen 4** dishes (possibly all Gen 4), confirmed
2026-08-15. Ethernet is built in on both, so **no Starlink Ethernet Adapter is
needed**. Nothing to order.

Still do two things by hand: confirm the Ethernet port physically on the specific
unit that travels, and confirm bypass mode is present in that unit's app
settings before relying on it.

(For reference, if a Gen 2 dish ever turns up in the pile: it needs the Starlink
Ethernet Adapter, there is no substitute, and there is no field workaround.)

### 2.2 Rehearse bypass mode

Bypass mode turns off the Starlink router's own WiFi and DHCP so the Beryl is the
only router on the link.

1. Starlink app -> Settings -> **Bypass Mode** -> enable.
2. Confirm the Starlink SSID disappears.
3. Confirm the Beryl gets a WAN address and reaches the internet.
4. **Rehearse the undo**: leaving bypass mode requires a factory reset of the
   Starlink router. Do it once at home so the recovery is known, not discovered.

Record which physical cable goes where. In dust, at night, this matters more
than it sounds.

### 2.3 Configure the Beryl AX (GL-MT3000)

Web UI, typically `http://192.168.8.1`.

| Setting | Value | Why |
|---|---|---|
| 2.4 GHz channel | **11 (fixed)** | Must match the fleet. Never "auto". |
| 2.4 GHz width | **20 MHz (HT20)** | Narrow and robust; avoids 40 MHz bonding onto adjacent channels |
| 2.4 GHz security | WPA2-PSK | WPA3/mixed mode has caused ESP32 association trouble |
| 2.4 GHz SSID | dedicated, e.g. `Resonance24` | Must be separate from the 5 GHz SSID |
| 5 GHz SSID | separate name | Where laptops and phones belong |
| Power | USB-C, about 5 W | Budget against camp batteries |

**Do not** give the two bands the same SSID. Band steering will hand a client
5 GHz and the fleet-facing device will never see channel 11.

Push every laptop and phone onto the 5 GHz SSID. About 130 fixtures share
channel 11; ESP-NOW frames are short and duty cycle is low, but there is no
reason to put video calls in the same 20 MHz.

### 2.4 Verify the channel

Do not trust the config page alone -- verify over the air:

- Phone WiFi analyzer, or
- The bridge's own scan path (`NB_SCANAP` / `--scan-report`), which reports
  `bssid`, `ap_rssi`, `ch`, `enc`, and `ssid` per AP.

Expect `ch=11`. If it reports anything else, fix it before going further.

### 2.5 Coexistence test

With a fixture beaconing on the bench:

1. Associate one device to the pinned 2.4 GHz SSID.
2. Confirm ESP-NOW RX continues, both directions, for at least an hour.
3. Deliberately set the AP to channel 1. Confirm the channel guard fires: WiFi
   dropped, mesh retained, mismatch surfaced.
4. Set it back to 11.

### 2.6 OTA over the camp router

Run one parallel shared-WiFi OTA over the Beryl, not just the house network:

```bash
python ops/bench/net_bench_ota.py --help
```

Follow the normal fleet OTA path (targeted `U<id>` maintenance, then
`field_cycle_ota.py` or `net_bench_ota.py --reboot comms`). Do **not** use or
build the deprecated per-board maintenance-AP path.

Maintenance-mode fixtures may associate on any channel -- the guard does not
apply to them, because they have already left ESP-NOW. This step is about
proving the camp router serves the OTA path at all, not about channel behavior.

### 2.7 Power

Measure the Beryl's actual draw powered the way it will actually be powered
(USB-C off the camp battery, not a wall wart). Record it against the camp energy
budget. Nominal is about 5 W; confirm rather than assume.

---

## 3. Field bring-up checklist

- [ ] Starlink sited, powered, dish clear
- [ ] Ethernet adapter installed (Gen 2 only)
- [ ] Starlink in bypass mode; Starlink SSID gone
- [ ] Beryl powered from camp battery, WAN address acquired
- [ ] 2.4 GHz on channel 11, HT20, WPA2-PSK, dedicated SSID -- **verified by scan**
- [ ] 5 GHz SSID up and separate; laptops and phones on it
- [ ] One device associated + mesh RX confirmed simultaneously
- [ ] Fleet still running autonomous shows with the router off (it must)

---
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

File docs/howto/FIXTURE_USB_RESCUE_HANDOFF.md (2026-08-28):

# Fixture USB bootstrap and PROTECT rescue handoff

Use this runbook when USB-flashing production PowerFeather V2 fixtures that may
be either factory-fresh or parked by the earlier durable-PROTECT bug. This is the
handoff for Elliot's bench. It deliberately installs the simple supervised
basic-listener image, not the `Lighting-Controller` boot-salute/presence image.
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

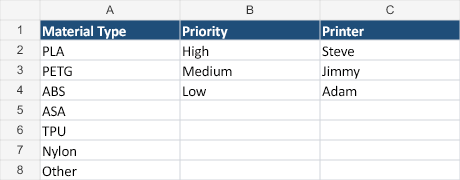
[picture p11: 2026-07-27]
ops/print-farm/previews/lists.png

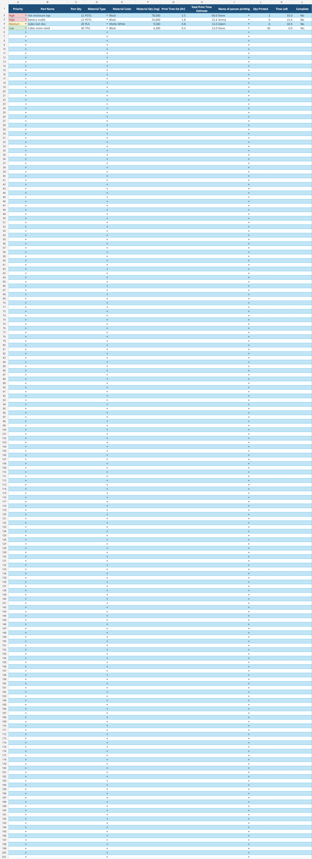
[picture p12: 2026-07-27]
ops/print-farm/previews/print-tracker.png

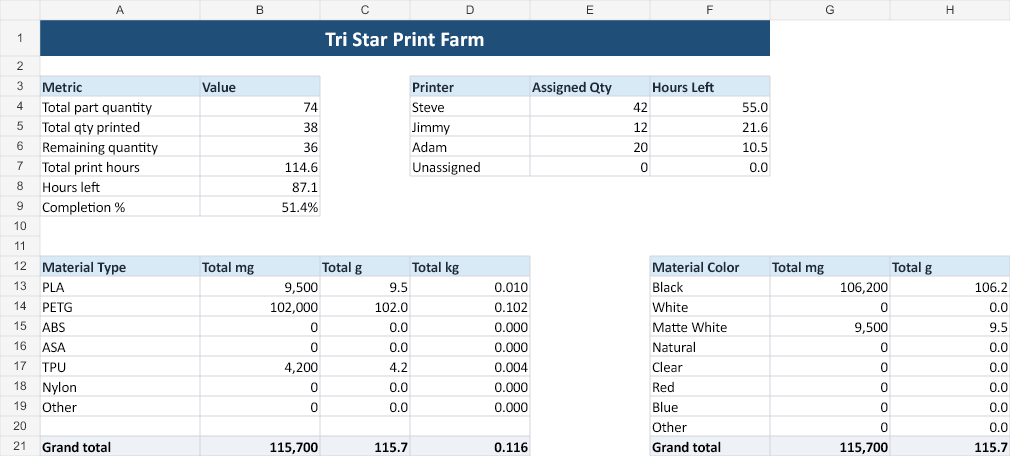
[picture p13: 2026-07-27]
ops/print-farm/previews/summary.png

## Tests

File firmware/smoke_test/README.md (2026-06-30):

# COTS Smoke Test

Minimal Arduino smoke firmware for first-arrival COTS boards.

Targets:

- Adafruit Feather ESP32-C6 + Adafruit IS31FL3741 13x9 matrix over STEMMA-QT.
- UnexpectedMaker FeatherS2 Neo built-in 5x5 LED matrix.
- M5Stack Atom Matrix built-in 5x5 LED matrix.
- M5Stack Atom Matrix + M5Stack Unit NeoHEX 37-LED board over Grove.

The sketch prints a boot report over serial, scans I2C, enters a conservative
LED measurement mode, and can start either a home-WiFi or temporary AP-hosted
web OTA updater from the serial console.

## WiFi Secrets

For station-mode OTA, create `wifi_secrets.h` next to the sketch. That file is
ignored by git.

```cpp
#pragma once

#define RES_WIFI_SSID "your-network"
#define RES_WIFI_PASSWORD "your-password"
#define RES_WIFI_AUTO_CONNECT 0
```

Set `RES_WIFI_AUTO_CONNECT` to `1` only for bench sessions where every boot
should enter WiFi OTA maintenance mode automatically.

## Build

Use Arduino CLI with the ESP32 core.

```sh
arduino-cli compile --fqbn esp32:esp32:adafruit_feather_esp32c6:CDCOnBoot=cdc,PartitionScheme=min_spiffs firmware/smoke_test
arduino-cli compile --fqbn esp32:esp32:um_feathers2neo:PartitionScheme=min_spiffs firmware/smoke_test
arduino-cli compile --fqbn esp32:esp32:m5stack_atom:PartitionScheme=min_spiffs firmware/smoke_test
arduino-cli compile --fqbn esp32:esp32:m5stack_atom:PartitionScheme=min_spiffs --build-property compiler.cpp.extra_flags=-DRES_ATOM_GROVE_NEOHEX=1 firmware/smoke_test
```

## Flash

Current bench serial mapping:

```sh
arduino-cli upload -p /dev/ttyACM1 --fqbn esp32:esp32:adafruit_feather_esp32c6:CDCOnBoot=cdc,PartitionScheme=min_spiffs firmware/smoke_test
arduino-cli upload -p /dev/ttyACM0 --fqbn esp32:esp32:um_feathers2neo:PartitionScheme=min_spiffs firmware/smoke_test
arduino-cli upload -p /dev/ttyUSB0 --fqbn esp32:esp32:m5stack_atom:PartitionScheme=min_spiffs firmware/smoke_test
```

For Atom + NeoHEX, build with `RES_ATOM_GROVE_NEOHEX=1`. This drives the
Grove yellow LED signal on GPIO26, uses 37 pixels, and leaves GPIO32 unused.

## Serial Commands

- `h` or `?` -- print help.
- `r` -- print boot/status report again.
- `i` -- run I2C scan.
- `l` -- run conservative LED test.
- `c` or `0` -- clear LEDs, keeping the current WiFi/OTA state.
- `q` -- quiet current baseline: stop OTA/WiFi and clear LEDs.
- `1` -- center max-white LED.
- `2` -- 3-pixel RGB/fringing pattern.
- `3` -- center 3x3 dim warm-white crop.
- `4` -- full-array very-low white.
- `5` -- full-array capped white, brief measurements only.
- `w` -- connect to configured WiFi and start web OTA updater.
- `o` -- start temporary AP web OTA updater.

When AP OTA mode is started, connect to the printed `resonance-smoke-*` WiFi AP
and open `http://192.168.4.1/` in a browser. When station OTA mode is started,
open the printed `http://<board-ip>/` URL.

While the OTA web server is active, LED measurement modes can also be selected
from the status page or by HTTP:

```sh
curl 'http://<board-ip>/mode?m=1'
curl 'http://<board-ip>/mode?m=4'
```

If an Atom + NeoHEX OTA upload fails over marginal WiFi, retry with a throttled
multipart upload:

```sh
curl -H 'Expect:' --limit-rate 40k -F 'firmware=@/tmp/res-atom-neohex/smoke_test.ino.bin' 'http://<board-ip>/update'
```

Mode `q` turns WiFi off after replying, so use serial to continue controlling
the board after entering quiet mode.

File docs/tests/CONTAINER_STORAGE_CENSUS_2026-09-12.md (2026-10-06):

# Nevada City container census and USB storage, 2026-09-12

Ben requested a census after roughly a week in a dark shipping container and
storage until physical service. At 17:08 PDT he explicitly authorized fleet
USB-wake storage, then direct laptop operation without a T-Deck tap. His later
dinner plan put the expected return at roughly 18:30-19:00 PDT.

## Completed operation, 19:18 PDT

- 106 of the 114 previously installed fixtures were heard. All 106 passed
  exact-revision OTA verification beyond the pending-verification window on
  `fx-260912-f951ae9-b`; no failed, deferred or commission target remained.
- All 106 acknowledged untimed USB-wake storage, with matching source/sequence
  receipts and durable cause-8, zero-duration audits. No refusal, entry failure
  or later radio rejoin was observed.
- The final five acknowledged by 18:39:20 PDT. The last job stopped sending at
  18:39:37. The full 960-second quiet interval elapsed at 18:55:20; the final
  live check at 19:17:57 established 38 minutes 37 seconds of quiet after the
  last receipt, uninterrupted capture, and no controller restart.
- A fresh controller status confirmed job 3718EB1B inactive, 17/17 prepared,
  zero refused. Dashboard/logger processes were stopped at 19:18 and the
  temporary Windows awake hold was released. Laptop, T-Deck and network are
  ready to pack; none is needed to maintain storage.
- Eight installed fixtures never responded and were not commanded. Their
  condition remains unknown; exact names and IDs appear below.

Ponyta F2B7DC and Chunli 9F2714 both acknowledged storage. Ponyta's last report
at storage entry was 2.562 V; an earlier 2.547 V sample was late in a protected
listening window. These readings do not diagnose a ruined cell.

Final evidence is `storage-final.json` and CSV, `pack-up-controller-status.json`,
all eight storage job ledgers, and the SHA-256 evidence manifest under
`ops/bench/data/ca/20260912-155847-container/`. The read-only reconciler required
all 106 receipts, durable audits, stopped jobs, at least 960 seconds of quiet,
live capture and no bridge restart. Its final capture contained 48,755 rows;
maximum controller-report gap was 10.024 seconds. Radio evidence is not an
assembled-current measurement or a physical USB-wake test; both remain open.
The compact evidence and storage branch history are now integrated in this
repository. Large raw captures and private device backups remain local.
See the [storage and wake guide](../howto/FIXTURE_STORAGE_AND_WAKE.md) for the
operator summary and canonical artifact links.

## Wake and controller handoff

The selected mode is untimed USB-wake ship mode. Good USB or solar input wakes
it; QON is an alternative. RESET/BOOT alone cannot wake an unpowered ESP32.
The laptop, network and T-Deck are not needed to maintain this storage state.

T-Deck Home -> Rest -> Store now offers USB storage, RESET-wake deep sleep,
and a Pacific date/time wake picker using fresh GPS time. The timer option is
limited to 30 minutes through seven days. Pure-core calendar/campaign/receipt
and parser tests, the full native suite and the embedded build passed. Actual
LCD layout, physical wake behavior and assembled storage current still need
service-time qualification.

Retained T-Deck artifact: `tdeck-0.3.0-storage4`, 1,578,224 bytes, SHA-256
`11b98b33ca46babf21ad27cb1f2edd7cccdf6319a5e130df3e5442fd6260c1b1`.
Firmware source: `556c2f6cdbefd152a1f79437b9e7f859b7b7fd44`; artifact commit
`a53181a`, now integrated with the storage branch history. Exact application,
bootloader, partitions, build options and manifest are retained in
[`firmware/tdeck_bridge/build/storage-host-20260912-r4/`](../../firmware/tdeck_bridge/build/storage-host-20260912-r4/).
The private pre-flash NVS/apps backup is retained locally and is not committed.
The storage3 build was not flashed; no firmware source changed during the
storage4 build. Its post-build test-only CRLF comparison fix passed the suite.

## Census

Read-only capture through T-Deck `8EB508`, channel 11, COM152, while the laptop
was on the known Party In The Woods network. Compare against the 114 installed
fixtures in the 2026-09-01 rollout report, not the larger inventory registry.

The first host capture stopped after 399 seconds without an error. The same
logical run was resumed with a recorded segment boundary; capture gaps are not
counted as continuous observation. The second segment completed 1,020 seconds
uninterrupted, ending about 16:27:57 PDT. The whole run spans 15:58:47 through
16:27:57 PDT with the gap explicitly retained.

Final result: **106 of 114 heard**, all FIELD profile. No latest report between
0 and 0.6 V. Lowest latest readings are Ponyta `F2B7DC`, **2.582 V**, and Chunli
`9F2714`, **2.618 V**. Median is 3.244 V; maximum 3.323 V. These are radio/gauge observations, not cell-terminal
measurements or a determination that a battery is ruined. Their current
firmware reports PROTECT, 900-second sleeps and LED rails off. All 106 latest
retained LED reports are off and all supply-good reports are false. Latest
tiers: 74 PROTECT, 5 DIM, 27 NORMAL. Last sleep records: 75 at 900 seconds and
31 at 120 seconds; sleep history and current tier are not necessarily sampled
at the same moment.

Revisions: 69 `fx-260831-f121868-b`, 23 `fx-260831-dc82da7-b`, and 14
`fx-260831-b3e2738-b`. Ten fixtures report below 3.05 V: Ralts `9E5AE0`,
Torchic `9E5B04`, Tauros `9F26AC`, Chunli `9F2714`, Ponyta `F2B7DC`, Toad
`F2BEE4`, Spock `F3FD60`, Pacman `F40174`, Raven `F402B8`, and Guile `F40350`.

The full 12,484-row JSONL, final summary JSON, CSV with field ages, and exact
observed/missing rosters are retained under
`ops/bench/data/ca/20260912-155847-container/`. The read-only
`ops/bench/storage_census.py` rejects pre-run bridge cache as fresh evidence
and distinguishes capture gaps. Seven focused tests pass. It does not open a
serial port or transmit commands.

Not heard in the completed observation:

| ID | Callsign | Context |
|---|---|---|
| 9F0E30 | Wooper | Already failed maintenance discovery on September 1 |
| 9F26B4 | Kairi | Already failed maintenance discovery on September 1 |
| F2BCF4 | Gambit | Earlier sub-1 V cell was removed; a healthy replacement was later recorded |
| F2BDD4 | Gengar | Unobserved |
| F2BDFC | Magmar | Unobserved |
| F2BE10 | Donkey | Unobserved |
| F2BE94 | Milotic | Unobserved |
| F3FD28 | Skitty | Unobserved |

Silence does not distinguish RF obstruction, disconnected power, an old sleep
command, or depleted cells. The previously reported 0-0.6 V fixtures cannot be
declared recovered from this census. Do not infer remaining capacity from LFP
plateau voltage or the fuel gauge's low SOC percentage alone (ADR 0023).

Historical very-low reports need a separate service check. The August 27
recovery report recorded Tidus `F40424` near 0.01 V with recovery refused;
Tidus is outside the 114-ID installed baseline used here and was not heard.
That report also recorded Clank `F2BF60` at 0.86 V; today's Clank report is
3.267 V in FIELD on the August 31 image, so the old cell reading must not be
assigned to its current cell without checking its service history. Gambit's
old sub-1 V cell was explicitly removed. None of those historical cases is
proved resolved merely by today's absence of 0-0.6 V telemetry.

## Battery tradeoff

These are planning calculations, not measured storage current in the assembled
fixtures. Radio examples assume 130 mA while awake, based on the bench range
in ADR 0045. They exclude LEDs and sleep current; boot/listen variation changes
the estimate. A week is 168 hours.

The manufacturer's board-current measurements use a 3.7 V source; they are
references, not measurements of these assembled LFP fixtures.

| Posture | Assumption | Per-fixture draw in 7 days |
|---|---|---:|
| Continuously awake, LEDs dark | 130 mA | 21,840 mAh |
| Ordinary radio duty cycle | 12 s awake / 120 s asleep | 1,985 mAh, radio only |
| PROTECT duty cycle | 9 s awake / 900 s asleep | 216 mAh, radio only |
| Uninterrupted deep sleep | Vendor V2 board, gauge on, 24 uA | 4.032 mAh |
| Conservative assembled sleep budget | ADR 0045 placeholder, 1 mA | 168 mAh |
| Ship mode reference | Vendor V2 board, gauge off, 1 uA | 0.168 mAh |

Applying those radio assumptions to the observed 31 short-cycle and 75
PROTECT-cycle fixtures gives about **77.77 Ah per week across 106 fixtures**
(about 249 Wh at 3.2 V). That projects the observed posture forward; it is not
an energy measurement or an estimate of remaining capacity. Uninterrupted
sleep removes this periodic-radio component. Attached-hardware leakage still
needs measurement and continues in addition to any board-current figure.

Eliminating periodic wakeups is worthwhile. The illustrative 24-to-1 uA
difference is only 3.864 mAh per fixture per week, or 0.440 Ah across 114
fixtures (about 1.4 Wh at 3.2 V). That alone does not justify cumbersome QON
access. The prepared ship implementation keeps the gauge enabled; its actual
current must be measured and is not the vendor's 1 uA gauge-disabled number.

Ship mode is attractive because good USB or solar input wakes it. QON is an
alternative, not required if USB can be applied. RESET/bootloader buttons do
not wake ship mode because the ESP32 has no power. Indefinite deep sleep uses
physical RESET; USB alone is not a wake source in the prepared implementation.
Neither mode can be recalled by radio. Battery replacement at service should
be done with external power removed; PowerFeather does not support live battery
swaps. Check the actual cell voltage separately from an isolated/protected
board node before deciding the condition of a previously very-low report.

Primary references checked 2026-09-12:

- [PowerFeather V2 current specifications](https://docs.powerfeather.dev/#current-consumption)
- [PowerFeather power and battery handling](https://docs.powerfeather.dev/sdk/usage-notes/)
- [PowerFeather power modes](https://docs.powerfeather.dev/guides/reduce_power_usage/)

## Prepared controls and deployment boundary

Source was developed on `codex/container-storage-20260912` and continued on
`codex/container-storage-host-20260912`; both histories and the concurrent
conductor work are now integrated in main. ADR 0080 defines exact-target USB/RESET
storage modes, capability advertisement, pre-entry receipts and durable audit.
Firmware installation does not select storage or bypass battery protection.

T-Deck Rest -> Store also offers a Pacific date/time picker using the existing
timed-transport command, with fresh GPS time, a seven-day limit, and a
16-minute exact-roster catch-up campaign. The controller cannot recall asleep
fixtures, and the ESP32's timer may drift. A PREPARED receipt is not measured
electrical power-off proof. Physical wake/current qualification remains open.

The OTA permission alone did not authorize storage. Ben separately approved
fleet USB-wake storage at 17:08 PDT and then direct laptop operation; those
permissions are satisfied and remain in force for this rollout.

## Validation and live canary

Fixture source commit `fcc5ef07ccf65f0f1d034bfe523e9f1d7f68bf10` passed the full
fixture native suite and embedded PowerFeather build. The full T-Deck native
suite also passed, including capability revocation, calendar, campaign and
receipt-ordering checks. Logger output-safety tests: 5 passed; storage-event
decoding: 4 passed; census: 7 passed.

Immutable fixture artifact:

- Revision: `fx-260912-f951ae9-b` (same exact artifact used in the authorized storage rollout).
- Bytes: 1,218,752.
- SHA-256: `ec03b074c6feae7ffc3f6bb2e178ec213ea5d241b56b3e24c95bfbb24d315001`.
- FIELD, channel 11, LFP, 300 mA precharge, 120-second day sleep,
  12,000 ms listen grace, basic listener; same flags as `fx-260831-f121868-b`.
- Retained artifact directory:
  [`firmware/fixture/build/fx-260912-f951ae9-b/`](../../firmware/fixture/build/fx-260912-f951ae9-b/).

Ben + Codex declared the single operator for exact target Hellboy `9F26C4`.
Preflight reported 3.312 V; shared-WiFi discovery found it at 3.316 V.
Job `84DEEB42` uploaded this exact image at 16:39 PDT and verified a fresh
matching-revision heartbeat at 25,953 ms uptime at 16:40:08 PDT. Reset reason
was software, class 1, recovery state 0, and FIELD profile persisted. This is
successful OTA evidence, not a storage or USB-wake test.

At approximately 16:52 PDT it also reported a deep-sleep reset and a short
12.6-second awake boot, consistent with returning to the existing 120-second
day cycle after the normal ten-minute cold-boot listen window. The old
controller initially showed an unset automatic sleep-audit tail. After its
receiver/cache restart, a fresh 17:04 PDT report confirmed cause 2, 120 seconds,
3.308 V at entry and a deep-sleep reset at 3.313 V. Ordinary RTC sleep-audit
retention was therefore confirmed. At that checkpoint, indefinite storage and
physical wake were still untested; the final storage result is recorded above.
Evidence: `hellboy-rtc-confirmed.json` in the census data directory.

Job ledger: `ops/bench/data/ca/20260912-155847-container/hellboy-canary-ota.jsonl`.
At this initial canary checkpoint, only Hellboy had been updated and no
deliberate storage command had been sent. Later rollout updates above
supersede that initial deployment count. The successful job froze its maintenance gather before
upload and completed without deferred or failed targets.

Completed census JSONL SHA-256:
`d0bd4f235cfe52e66c338ca59d57da29b4aa46fd0325d712955e1b77ec28bd5f`.

## 2026-09-14 location follow-up

Ben found a separate lantern bin and brought it to Oakland. Kairi 9F26B4 and
Wooper 9F0E30 are now heard there, accounting for two of the historical eight
unobserved fixtures. Groot 9F2724, Kiki F2BF5C and backyard prototype 9F26F8
are also heard, but were outside the 114-ID baseline. None of these five was
in the stored 106; their present radio activity does not demonstrate a storage
failure. Other bin lanterns are not yet mapped and may overlap the stored
cohort. Radio reach on September 12 did not prove physical container location.
The exact 106 storage receipts and eight-ID absence record above stay intact.
Current inventory and remaining six unknowns are recorded in
`OAKLAND_LANTERN_INVENTORY_2026-09-14.md`.

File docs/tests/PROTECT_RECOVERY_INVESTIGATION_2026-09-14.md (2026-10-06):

# PROTECT recovery investigation, 2026-09-14

Ben identified persistent high-VBAT PROTECT as a possible explanation for much
less chiming during the last days at Burning Man. Treat this as a priority
recovery/reliability investigation. High voltage alone does not prove a healthy
cell or an erroneous guard, and the available September 12 dark-storage census
does not establish whether a particular unit failed to recover under sunshine.
The Oakland units stay on their existing operating policy, with no new storage,
OTA, guard clear, or other device change during this investigation.

## Fleet evidence

The retained September 12 census contains 106 fixtures, 74 in PROTECT:

- 40 PROTECT fixtures were at or above 3.25 V; seven were at or above 3.30 V.
- All 40 reported supply-good false. This snapshot contains no qualifying
  charging window with which to prove an automatic release failure.
- Their retained entry origins are 35 low-VBAT, four load-armed reset, and
  one legacy/unknown. These are firmware-observed histories, not independent
  cell-terminal measurements or proof that every current latch was erroneous.
- The high-voltage group contains 18 f121868 inspection fixtures, 15 dc82da7
  visibility fixtures and seven b3e2738 final-burn fixtures. Exact IDs/callsigns,
  voltage ages, entry records and manifest source ancestry are retained in
  `ops/bench/data/ca/20260914-protect-recovery-analysis/fleet-cohort.json`.

## Known recovery bugs versus current code

Two older failures were already reproduced on hardware:

1. Rikku: a near-full battery accepted only 0-2 mA, so the old +20 mA release
   proof never completed. ADR 0068 / commit 5865282 added the qualified
   full/tapered-battery alternative.
2. Toad: independent 12-second DAY_CHARGE sleep repeatedly erased the RAM-only
   60-second proof even with valid input and about +506 mA charging. Commit
   3e44ad8 gave power_policy sole ownership of PROTECT sleep. Logan subsequently
   proved recovery through a genuine timer wake on the repaired image.

The immutable manifests and git ancestry establish that all three September 12
fleet revisions already included BOTH fixes before that day's storage OTA.
Groot's b0ff5db service image also contains both. Kiki's older 658b7d2 image,
from documented source 91663fd, contains neither. Kairi/Wooper's exact source
mapping was not established in this analysis; do not classify their fixes from
the date-looking revision alone.

## Remaining policy limitation reproduced offline

Compiled a small injected-sample harness against the unchanged current
`power_policy.cpp`. The test touches no device. Result and exact compiled source
hash are in `reproduction-result.json`; executable was temporary and not retained.

| Synthetic input | Observed policy result |
|---|---|
| 3.30 V, valid good input, no fault, +50 mA steady charging | Releases at 61 s in the one-second tick harness |
| 3.55 V, same gates, CV phase, +2 mA | Full-battery path releases at 61 s |
| 3.30 V, valid good input, -80 mA during listening | No release over 600 simulated awake seconds |
| 3.30 V, +50 mA interrupted by 5 s at zero every 50 s | No release over 600 simulated awake seconds |

A separate 20-cycle run resets RAM on each simulated 9-second wake followed by
900 seconds asleep. With an illustrative source charging at +50 mA during sleep,
and 130 mA additional awake draw giving -80 mA during listening, mean battery
current is still +48.713 mA. Nevertheless, the actual policy never starts its
positive-current proof during those wake samples at 3.30 V. The >=3.45 V full
battery path does not apply. Sleep charge is an external model assumption;
this harness is not a simulated charger/cell or physical evidence of this fault.

This is a reproducible recovery limitation to assess against field requirements:
a battery can gain usable charge while asleep without satisfying the continuous
awake recovery proof. Input flicker, failed status reads or proof-type changes
can also repeatedly reset the timer. This does not justify simply clearing
PROTECT above 3.25 V; legitimate load/path collapse remains possible.

## Chiming has a separate deployment explanation

The Aug 31 final-burn b3e2738 and later dc82da7 source permit ordinary wake chimes
and hourly rituals in FULL/DIM, with the normal class, time and authority gates.
OFF/PROTECT veto those autonomous chimes. By contrast, f121868 enables static
inspection mode, explicitly disabling both autonomous wake chimes and hourly
rituals independent of battery tier. The September 1 rollout verified this
inspection image on 70 of 114 fixtures. Not all 70 are chime-equipped canopies.
This is a concrete additional contributor to quiet during the last Burning Man
days; reduced sound is not an independent proof of a recovery failure.

References: `docs/tests/ADR_0074_PARTIAL_FLEET_ROLLOUT_2026-09-01.md`, ADR 0074,
ADR 0068, and the August 29 Toad/Logan/Groot entries in LOG.md.

## Bench work needed before a repair

- Preserve Oakland revision/configuration/NVS and entry/sleep/charger evidence
  before resetting guards or updating. Map the physical battery/harness first.
- Compare Kiki (known older release bugs), Kairi (3.303 V with a recorded
  2.993 V low-VBAT/unarmed entry), and Groot (both fixes, now 2.880 V).
- On an installed known-good cell and stable supply, log every recovery gate
  over at least one complete proof window and verify return through FULL/DIM
  and actual chime eligibility. Isolate cell/path failure from software state.
- Then test weak/variable input while measuring current across sleep and wake,
  rather than treating awake gauge current as whole-cycle charge history.
- If a new recovery policy is warranted, keep rail-off checks, qualified battery
  evidence, bounded retry and collapse-loop protection. Reproduce its positive
  and negative cases before any fleet deployment.
- Expose why recovery is waiting and why autonomous chiming is ineligible in
  future diagnostics; a voltage plus PROTECT badge conceals the needed evidence.

## Wake-app interaction

PROTECT exception: Wake Fleet and Performance Hold do not override the power
policy's sleep decision or clear its durable latch. A protected fixture normally
listens for about 8-9 seconds between 900-second sleeps; receiving Wake refreshes
ordinary lifecycle/control state, but not the independent PROTECT sleep grace.
The six-minute Wake campaign cannot guarantee catching a 15-minute PROTECT
cycle. Performance Hold repeats long enough to catch that cycle, but does not
keep a still-protected fixture continuously reachable. Qualified recovery or
OTA/maintenance can separately change its awake behavior. Continuous radio
claims apply only while the fixture's power policy permits them.

## Explicit PROTECT clear availability

The current T-Deck and ESP-NOW protocol have no un-PROTECT command. Wake,
reboot and ordinary OTA do not clear the durable guard. Physical RESET and
power cycling also preserve the NVS latch.

The fixture USB serial CLI has an explicit `X` recovery command, but only for
the historical battery-absent commissioning edge. It requires PowerFeather
ready, battery absent, charging disabled, good external input of at least
4.5 V, and no reported charger fault. It then persists IDLE and reboots. It is
not an installed-battery override and is not exposed over ESP-NOW.

A remote controlled recovery/retry could be implemented in fixture firmware
and the T-Deck; physical intervention is not inherently required by the latch.
That capability does not exist today. Preserve entry evidence before any such
service change. No device command or firmware change was made for this check.

Source: `firmware/fixture/src/esp32/serial_cli.cpp` (`case 'X'`),
`firmware/fixture/src/core/boot_guard.cpp`, `firmware/fixture/src/core/packet.h`,
and `docs/howto/FIXTURE_USB_RESCUE_HANDOFF.md`.

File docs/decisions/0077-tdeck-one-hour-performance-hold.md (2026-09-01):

# 0077 -- T-Deck one-hour inspection performance hold

**Date:** 2026-08-31

**Status:** Accepted and USB-flashed on T-Deck `8EB508`.

**Owner:** Ben

**Extends:** ADR 0075 and ADR 0076. It does not change fixture authority or the
retained fixture artifact.

## Context

ADR 0076 gives one Wake Fleet press a maximum inspection-control session of
about sixteen minutes: six minutes of repeated Wake commands followed by the
fixture's ten-minute tail. That is useful for manual checks but too short for a
DJ set, and requiring an operator to re-arm every ten minutes is fragile.

The inspection fixture image already treats lifecycle mode 0 as a RAM-only
direct-control arm while preserving Auto/static white and all battery safety.
The T-Deck can therefore extend a deliberate performance without a new packet
or another fleet flash.

## Decision

1. The T-Deck Wake app has a separate confirmed **Performance Hold** action.
2. Performance Hold sends the existing lifecycle mode-0 command every two
   seconds for one hour. This is the already-proven sleep-catch cadence, not a
   new wire command or fixture behavior.
3. Each accepted copy refreshes the fixture's non-extendable ten-minute direct
   arm. The last campaign copy therefore leaves up to roughly ten minutes of
   safe tail after the T-Deck's one-hour countdown reaches zero.
4. Direct LED/audio frames still cannot extend the deadline. Auto or Night
   Show replaces the active campaign immediately and closes manual control on
   every fixture that hears it.
5. The Wake screen reports the active campaign type and remaining controller
   time. The original 16-minute Wake Fleet option remains available.
6. Fixture FULL/DIM/OFF/PROTECT, recovery gates, static-white fallback, and
   perimeter center-pixel restriction remain higher authority. The existing
   immutable fixture artifact `fx-260831-f121868-b` consumes this command
   without modification.

## Consequences

- A DJ gets at least one hour of deliberate audio control from one confirmed
  T-Deck action, plus the bounded fixture tail.
- The T-Deck must remain powered and running for the one-hour refresh campaign.
- At 0.5 small packets per second, the extra controller traffic is negligible
  beside direct audio frames and does not change fixture LED energy authority.
- Mixed older fixture images still interpret mode 0 using their older Day
  behavior. Performance Hold is intended for the ADR 0075 inspection image.

## References

- `firmware/tdeck_bridge/src/net/mesh_tx.cpp`
- `firmware/tdeck_bridge/src/ui/app_schedule.cpp`
- `docs/decisions/0075-bounded-inspection-direct-control-and-audio-gain.md`
- `docs/decisions/0076-wake-campaign-owns-inspection-control-deadline.md`

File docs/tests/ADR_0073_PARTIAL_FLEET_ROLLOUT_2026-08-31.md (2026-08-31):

# ADR 0073 partial fleet rollout -- 2026-08-31

## Outcome

The operator ended the field session after the ordinary fleet and a small
PROTECT cohort were complete. The OTA campaign was frozen before the bridge was
left unattended.

- Fleet census: 112 fixtures.
- Exact ADR 0073 artifact: 96 fixtures.
- Rollback ADR 0072 artifact: 16 fixtures.
- The 91 fixtures that were non-PROTECT at rollout start all passed.
- Five explicitly targeted PROTECT fixtures passed.
- No OTA campaign remained active at handoff.

Success means a fresh mesh heartbeat reported the exact new revision after the
job start and after the 25-second pending-verify window. Upload ACK alone was
not accepted.

## Artifact identity

- Revision: `fx-260831-dc82da7-b`
- Source commit: `49e06b7c9d5c9c16838f49b3b1f32213383cdbb9`
- Binary: `firmware/fixture/build/fx-260831-dc82da7-b/fixture.ino.bin`
- Size: 1,220,192 bytes
- SHA-256: `7230f81ff1737fa51ebdd357b9249748e5712657469de82a4b5b75799ac83299`
- Recipe: field profile, channel 11, basic-listener, 300 mA precharge,
  120-second day sleep, 12-second wake listen, WiFi profile label
  `party-in-the-woods-v1`, artifact variant `b`.
- Rollback revision: `fx-260831-b3e2738-b`.

Because this laptop is being retired before the 16-fixture resume pass, the five
canonical immutable artifact files listed by ADR 0040 are retained at that
normally gitignored build path and explicitly included in this handoff commit.
This allows the next bench to upload the exact bytes instead of rebuilding.

## Updated fixtures

The following 96 fixtures reported the exact new revision:

```text
9D7884, 9E5954, 9E5A58, 9E5A5C, 9E5A74, 9E5A84, 9E5A88, 9E5A94
9E5AB0, 9E5AC8, 9E5AD4, 9E5AE0, 9E5AE4, 9E5B04, 9E5B10, 9E5B14
9E5B18, 9E5B34, 9E5B44, 9E5B48, 9E5B68, 9E5B8C, 9E668C, 9F0E4C
9F0E5C, 9F0E7C, 9F2638, 9F2664, 9F266C, 9F2680, 9F268C, 9F2694
9F26AC, 9F26B0, 9F26BC, 9F26C0, 9F26C4, 9F26D4, 9F26D8, 9F26E4
9F26E8, 9F2718, 9F2720, 9F2738, 9F275C, F2B7DC, F2BCF4, F2BD00
F2BDB0, F2BDC4, F2BDD4, F2BE08, F2BE0C, F2BE10, F2BE1C, F2BE20
F2BE38, F2BE3C, F2BE60, F2BE6C, F2BE70, F2BE94, F2BEA4, F2BEB4
F2BEE4, F2BEF4, F2BF54, F2BF60, F2BF7C, F2BF8C, F2BF90, F2BFE0
F3FC8C, F3FC90, F3FC9C, F3FCAC, F3FD50, F3FD60, F40174, F4019C
F401A8, F401CC, F401DC, F40254, F40268, F402B8, F402C4, F40308
F40310, F40314, F40348, F40350, F40364, F403DC, F403F0, F4042C
```

The five passes from the explicitly targeted PROTECT cohort were:

| Short MAC | Callsign |
|---|---|
| `F2B7DC` | Ponyta |
| `F2BDC4` | Batman |
| `F2BDD4` | Gengar |
| `F2BE08` | Yoshi |
| `F2BE10` | Donkey |

Eight updated fixtures reported tier 3 in the final snapshot. Three of those
(`9E5AD4`, `9F268C`, and `F40308`) had entered PROTECT after being updated as
part of the original non-PROTECT cohort. This is changing power state, not a
revision discrepancy.

## Resume roster

These 16 fixtures still reported the exact rollback revision and field profile
in the post-stop snapshot. All reported power tier 3. Battery values are stale
mesh snapshot values, not a present-time safety measurement.

| Short MAC | Callsign | Last battery | Note |
|---|---|---:|---|
| `9E5B5C` | Mipha | 3.196 V | No upload |
| `9F0E54` | Eevee | 3.201 V | No upload |
| `9F2648` | Cubone | 3.197 V | No upload |
| `9F2714` | Chunli | 3.048 V | No upload |
| `F2B900` | Cammy | 3.044 V | No upload |
| `F2BCF0` | Spyro | 3.177 V | No upload |
| `F2BDB4` | Abra | 3.286 V | HTTP connection closed; no new-revision proof |
| `F2BDFC` | Magmar | 3.065 V | No upload |
| `F2BE48` | Lando | 3.196 V | No upload |
| `F2BF74` | Qbert | 3.151 V | No upload |
| `F3FD28` | Skitty | 3.006 V | No upload |
| `F3FD88` | Torkoal | 3.142 V | No upload |
| `F402A8` | Unassigned | 3.201 V | No upload |
| `F4035C` | Dratini | 3.268 V | No upload |
| `F40384` | Leia | 3.218 V | No upload |
| `F4043C` | Joltik | 3.134 V | No upload |

The final dashboard snapshot was 2026-08-31 06:39:22 UTC. Its maintenance
campaign record for job `98A408F1` reported phase 2 and `active=false`.

## Job evidence

| Job | Scope | Result |
|---|---|---|
| `93D3A477` | 91 ordinary fixtures | 74 passed; 17 deferred without upload |
| `5EF38540` | 17 ordinary retry | 14 passed; 3 deferred without upload |
| `DAE7326C` | 3 direct ordinary stragglers | 3 passed |
| `609E75B2` | 21 PROTECT attempt | Safe preflight stop; no upload |
| `FFC67D91` | 8 PROTECT gather | Manually frozen after endpoint capture; no upload |
| `B606B487` | 6 captured PROTECT fixtures | 5 passed; `F2BDB4` unproven/failed |
| `98A408F1` | 6 next-phase PROTECT fixtures | No endpoints, no upload; manually frozen |

Tracked job ledgers are under `ops/bench/data/Black Rock City/`. Local
`*-ota-results.jsonl` files are intentionally gitignored by repository policy;
their result counts and the final exact-revision census are preserved here.

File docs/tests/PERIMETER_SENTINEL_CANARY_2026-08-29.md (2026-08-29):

# Perimeter sentinel canary -- Spyro F2BCF0 -- 2026-08-29

## Result

Three exact-target radio-off + perimeter-ToF A/B/A field campaigns completed
their interaction sequences, but none produced an acceptable power trace.
Rapid sunrise changed solar input across the first run. The first two completed
PSRAM buffers were then erased by task-watchdog resets while maintenance WiFi
was trying to start. The second and third runs held the panel consistently
covered and therefore fixed the environmental control, but independently
reproduced the retrieval/checkpoint failure.

Treat these as useful interaction/retrieval-path evidence, not as a measured
sentinel current delta and not as a promotion gate pass. Every canary was
restored without opening the enclosure. The final exact-prior restore was
armed while the canary was stuck in an unintended reset/rerun loop, intercepted
the next brief mesh window, and completed without operator involvement.

## Declared operation

```text
OWNER: Ben + Codex, T-Deck 8EB508 / dashboard COM7
SOURCE: bb860980697aee93aca8fd37280f08ab249c4aca
ARTIFACT: fx-260829-f13e090-t
SHA-256: 249c500e3a9bf12ab4902ec1db1c18680605d3a1a35bf7933e2c162dc1061cb1
TARGET: F2BCF0 (Spyro)
OPERATION: single-target OTA, bounded sentinel A/B/A, exact-prior restore
```

The canary was a clean, immutable 1,225,488-byte `-t` artifact with recipe
SHA-256 `f13e0903eda26d75fcc2d95a1d8b288c7c72d03c7cf4c5c54cf10a52426cdb10`.
Its compile defaults matched the current field shape: LFP, channel 11, 300 mA
precharge, 120-second day sleep, 12-second wake listen, field profile, listener
commission posture, two maintenance WiFi profiles, and exact target lock
`F2BCF0`.

The retained restore artifact was:

```text
fw_rev: fx-260827-1254f04-p
bytes: 1207376
sha256: 2f9a93344e172b023ee8df473b7c747b26f38dc0ec5353f6efd00d50ec45f4af
```

## Preflight and OTA

Physical identity was confirmed by Ben. Fresh dashboard state matched callsign
Spyro and short MAC `F2BCF0`, with field profile, perimeter class, no class
mismatch, no BQ fault, LED rail off, and ordinary 120-second sleep cadence.
VBAT was about 3.16 V and the power policy still reported FULL. Sunrise moved
the input from below `supply_good` to valid input before upload.

The prior image reported `sensor_bits=2` (VL53L5CX only). The historical
commissioning failure did include the old MSA301-address class-probe bug, but
the corrected `0x62`/PART_ID probe in the canary also reported only bit 2 at
boot. Spyro's MSA311 therefore remained absent or unresponsive in this run;
the VL53 experiment was still correctly classified and allowed to proceed.

Job `736C52A6` used the exact canary bytes but timed out in discovery; it made
no upload. Retry job `B325E6FE` found exact Spyro at `192.168.1.99`, rechecked
fresh maintenance power at 3.186 V / 4.665 V input, uploaded the exact canary,
received a fresh software-reset heartbeat, and verified the revision beyond
the pending-verify gate at 31,199 ms uptime. Profile remained field, class
remained perimeter, and recovery state remained zero.

## Physical interaction

The automatic sequence ran approximately:

```text
06:50:44-07:00:44 local  baseline A, radio off, sensor rail off
07:00:44-07:01:14 local  sensor warmup, radio off
07:01:14-07:11:14 local  MSA311/VL53 runtime requested, radio off
07:11:14-07:21:14 local  baseline B, radio off, sensor rail off
```

Ben performed about 10 or more close palm holds near the middle of the active
phase and another 5-6 near its end, approximately 15-16 total. Each set used
roughly one-second holds with clears between them. This is useful field input,
but the trace was not recovered, so firmware presence-edge counts, misses, and
latency cannot be compared with the human count.

The sun rose rapidly during the campaign. The A/B/A shape can reject a modest
linear trend, but it cannot make nonlinear sunrise input controlled evidence.
No battery-current delta or daily energy projection is accepted from this run.

## Trace loss and recovery

At the expected retrieval time Spyro did not expose HTTP on either known
subnet. It retried maintenance while retaining the buffer, but the dashboard
later showed a new canary heartbeat with reset reason `task_watchdog` and about
30 seconds uptime. PSRAM does not survive that reset, so the completed trace
was lost.

The fixture task watchdog is eight seconds. Maintenance previously called the
synchronous `WiFi.scanNetworks()` and serviced the watchdog only before and
after that unbounded scan. This is the only unserviced blocking operation in
the observed retrieval/join path and is consistent with a crowded-field scan
exceeding eight seconds. Source now uses an asynchronous scan, polls it while
servicing the watchdog, and falls back to configured credential order after a
15-second bound.

Spyro recovered without opening the enclosure. A targeted restore gather found
the rebooted canary at `192.168.1.99`; exact restore job `DCE67738` uploaded the
retained prior binary and verified a fresh software-reset heartbeat beyond the
pending-verify gate at 42,123 ms uptime. Final evidence was exact prior revision,
field profile, perimeter class, FULL tier, no BQ fault, about 3.20 V VBAT, and
valid external input. No fleet or profile broadcast was used.
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

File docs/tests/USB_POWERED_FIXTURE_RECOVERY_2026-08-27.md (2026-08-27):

# USB-powered fixture recovery - 2026-08-27

## Scope and artifact

Ben connected an expected 24 depleted/old fixtures to USB power. The mesh
census first found 23, later 24, and finally 25 USB-powered fixtures as sleeping
units woke. T-Deck `8EB508` on channel 11 was the only command/OTA writer.

All fixture uploads used the existing immutable production artifact:

- revision: `fx-260826-51d1fe1-p`
- source commit: `64264b2c60cbff9a9423642cb6cfee93e4272636`
- binary bytes: `1,206,784`
- SHA-256: `57306019dbf93a1d0cf950f25b9f557d9a0a68663621a7ce4579aba01dea1261`
- field profile default, channel 11, 300 mA BQ precharge, 120 s day sleep,
  3 s listen window

Every successful target had a fresh identity/power preflight, exact-target
maintenance entry, upload acknowledgement, fresh exact-revision heartbeat, and
fresh survival evidence beyond the 25 s host pending-verify gate.

## Result

Twenty fixtures were uploaded and verified:

```text
F40348 F2BCF4
F2BFE0 F2BDC4 F2BF7C F2BDD4 F402A8 F40314
F2B900 F4043C F3FD88 F3FD28
F403DC F2BCF0 F3FCAC F2BF74
9D7884 F40308 F4035C
F401DC
```

Three already carried the target revision and were not reflashed: Tidus
`F40424`, Magmar `F2BDFC`, and Swablu `F2BE70`. Thor `F40344` retained its
protected `net-bench-2026-08-19.1` magic-wand image. Clank `F2BF60` retained
`fx-260817-ec7f28d-b` because its reported 0.86 V battery is below ADR 0042's
2.20 V automatic-recovery floor.

Thus the final USB-powered census was:
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

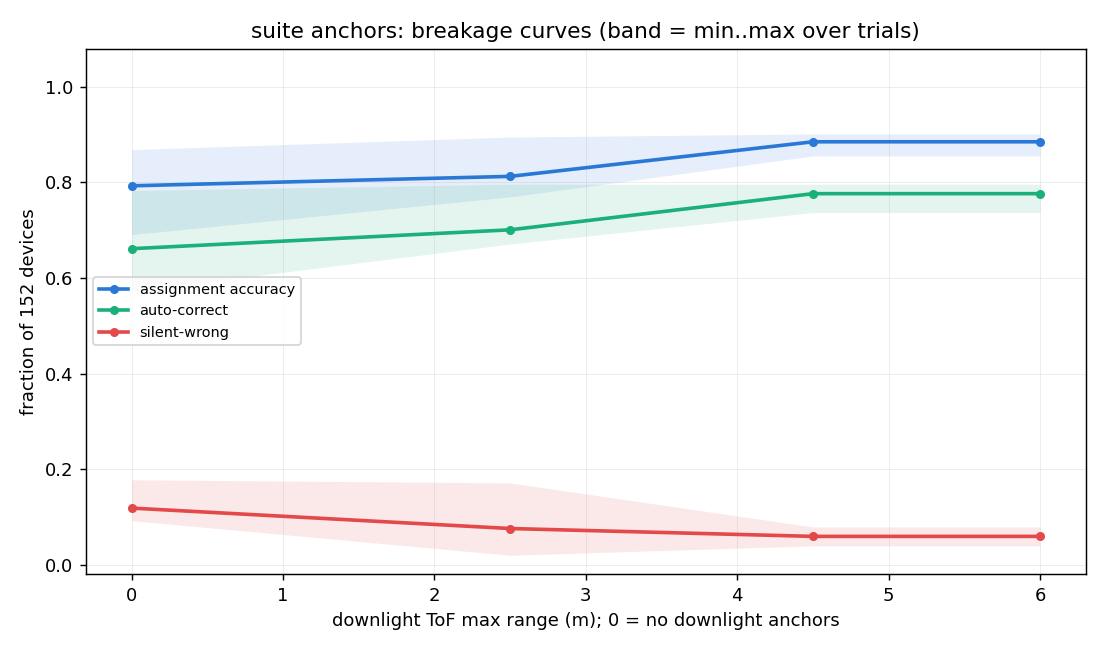
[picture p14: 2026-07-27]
docs/tests/figures/AUTOLOCATE_SWEEP_ANCHORS_2026-07-12.png

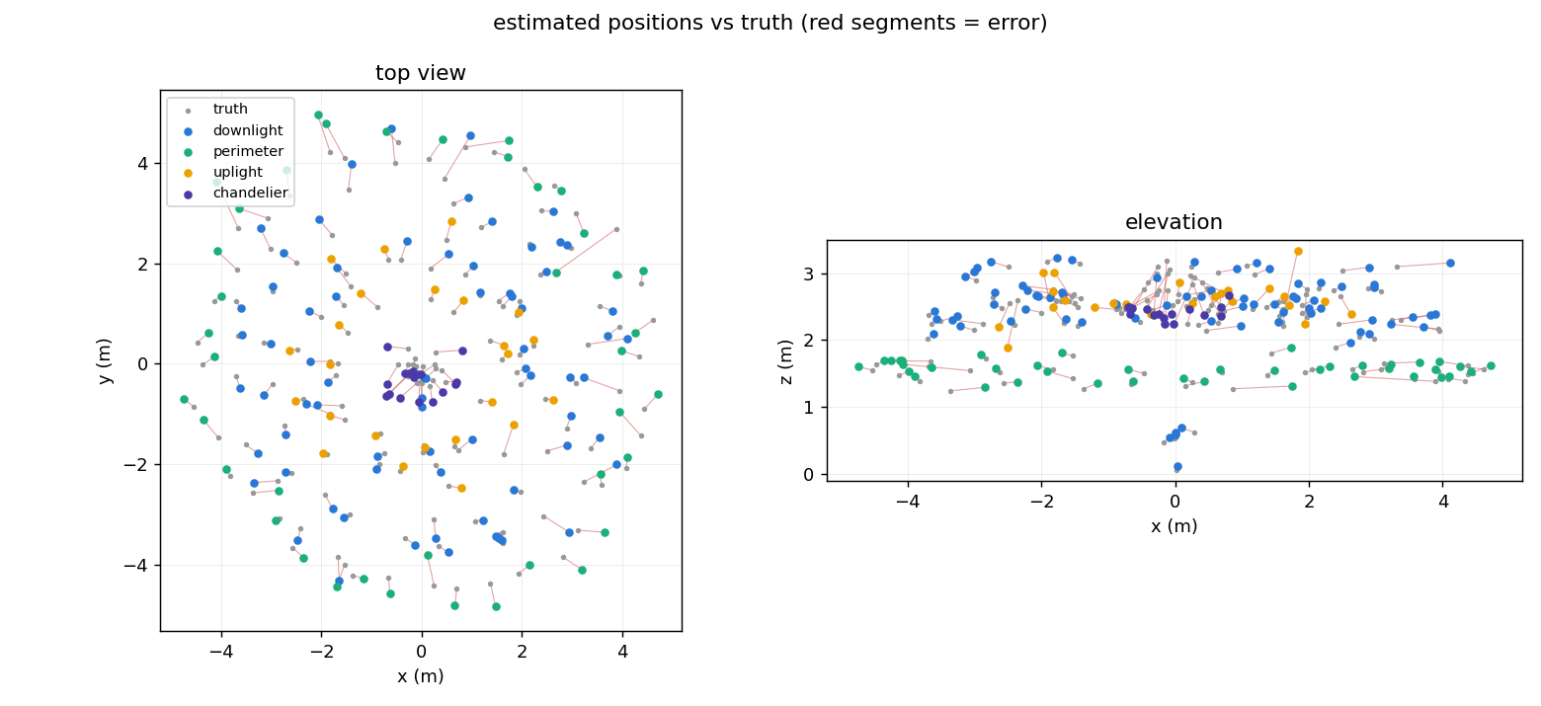
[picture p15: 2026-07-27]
docs/tests/figures/AUTOLOCATE_POSITIONS_SL4_2026-07-12.png

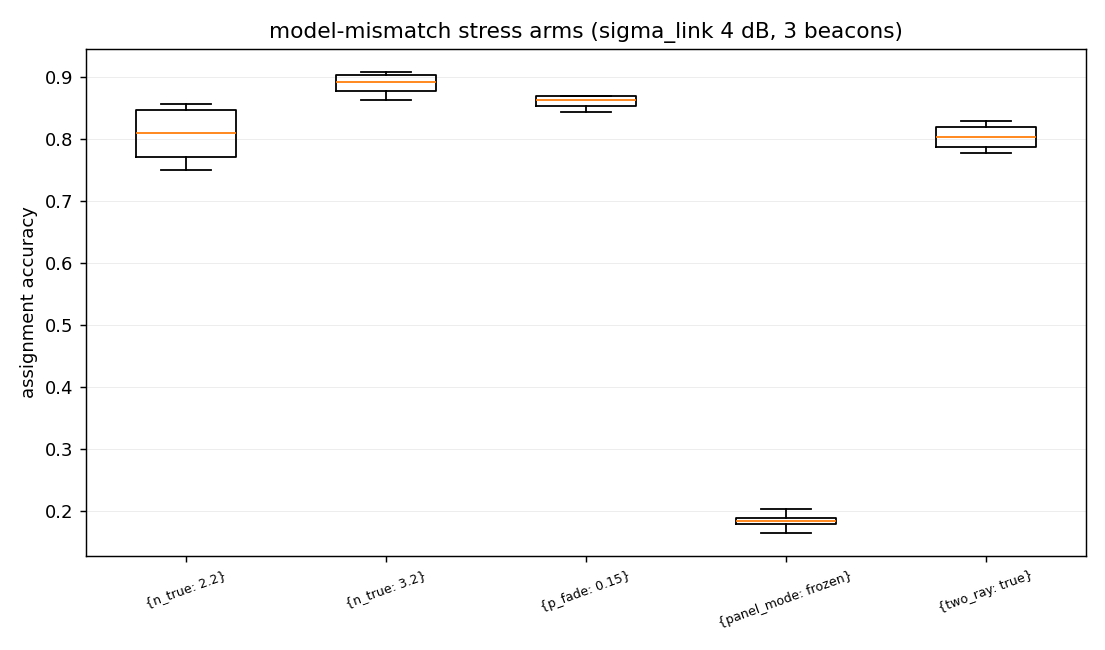
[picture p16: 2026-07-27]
docs/tests/figures/AUTOLOCATE_SWEEP_MISMATCH_2026-07-12.png

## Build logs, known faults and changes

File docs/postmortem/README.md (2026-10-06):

# 2026 postmortem and 2027 future work

Updated: 2026-10-06. Start here for the post-event storage, power/recovery and
service-tooling work. This index gathers the records already in this repository;
it is not a claim that every 2026 installation issue has been investigated.
Open work remains in [TODO](../../TODO.md); dated history is in [LOG](../../LOG.md).

## Evidence and operating state

| Record | What it establishes | What remains unresolved |
|---|---|---|
| [September 12 container census and storage](../tests/CONTAINER_STORAGE_CENSUS_2026-09-12.md) | 106 observed fixtures received the exact storage image and acknowledged indefinite ship requests; final radio-quiet check passed. | Assembled storage current and physical wake; eight originally unobserved fixtures were not commanded. |
| [Storage and wake operator guide](../howto/FIXTURE_STORAGE_AND_WAKE.md) | Mode distinctions, T-Deck/host workflow, deployed artifact identities and evidence links. | USB/solar/QON wake and RESET-wake qualification, plus physical UI inspection. |
| [September 14 Oakland inventory](../tests/OAKLAND_LANTERN_INVENTORY_2026-09-14.md) | Five identified sightings, none in the stored 106; Kairi/Wooper account for two original census absences. | Map the remaining bin fixtures, inspect cells and locate the six remaining unknowns. Ben wants the Oakland units operational, without deliberate storage. |
| [High-voltage PROTECT investigation](../tests/PROTECT_RECOVERY_INVESTIGATION_2026-09-14.md) | 40 of 74 PROTECT reports were >=3.25 V; offline reproduction exposes an awake-only recovery-proof limitation. | This does not prove 40 healthy cells or 40 false latches. Preserve specimens and measure full sleep/wake charge cycles. |
| [August 26 fleet OTA postmortem](../tests/FLEET_OTA_120X3_ROLLOUT_POSTMORTEM_2026-08-26.md) | Earlier rollout evidence and lessons. | Use alongside later firmware/field records, not as the current deployment state. |

The curated [storage evidence](../../ops/bench/data/ca/20260912-155847-container/README.md)
includes exact rosters, OTA verification, matched storage receipts, final
reconciliation and SHA-256 identities. Large raw captures remain local, as do
private device backups. Field observations and synthetic reproductions are
explicitly distinguished from measured electrical behavior.

## Lessons to carry into planning

- Chimes were a strong part of the installation in Ben's field experience.
  Both capboard revisions already support optional divider sensing; weak/null
  underfilled-cap strikes are an acceptable outcome. Preserve the working
  strike path and prioritize command reception, lighting and presence sensing.
- A high resting LFP voltage is not a capacity measurement. Recovery evidence
  must cover sleep and listening energy, charger state and durable entry cause.
- Wake Fleet/Performance Hold do not clear PROTECT or make its radios listen
  continuously. Reduced chimes during the last Burning Man days also have a
  known firmware confounder: September 1 inspection images disabled autonomous
  chimes. The relative contributions remain unresolved.
- Service wake should get a fixture into a useful, bounded maintenance session.
  A hardware reset alone can preserve PROTECT and promptly return to sleep.
  Instant wake could remove OTA gathering delays, especially at a 15-minute
  PROTECT cadence; upload time and verified reboot remain separate costs.

## Brainstorming and proposed experiments

These are discussion drafts, not approved hardware, a BOM or a fleet rollout:

- [2027 power-platform exploration](../projects/2027-power-platform/EXPLORATION.md):
  autonomous LFP charging/recovery, private power bus, solar energy measurement,
  gauge/SOC qualification, monitoring overhead, independent cutoff, sleep/wake
  contracts and a broad feature keep/improve/consolidate/retire review.
- [RFID service access and instant maintenance wake](../projects/2027-power-platform/RFID_SERVICE_ACCESS.md):
  battery-free identification, independent targeted reset/ship wake, RTC
  coin-cell sharing, passive versus powered actuation range, retained service
  intent, and fleet OTA latency/coverage. No part or reader has been selected.
- [Future OTA speed options](../design/FLEET_OTA_FUTURE_SPEED_OPTIONS.md):
  additional transport and activation improvements, with separate proof needs.

Keep the optional chime-cap divider as a diagnostic option, rather than adding
another strike gate. Keep useful gauge/current measurements while testing the
SOC model on both cell sizes. Compare complete standby and receive energy, not
just individual component headline currents.

## Next useful work

1. Preserve Oakland specimen state; characterize actual cells, input power and
   recovery across a complete sleep/wake cycle before selecting a PROTECT fix.
2. Qualify the existing storage/wake implementation during physical service.
3. Review the complete operator workflow and prioritize a small number of
   measured improvements before selecting a custom board or retiring features.
4. Prove one addressed independent wake/reset candidate on an assembled lantern,
   including power-off operation, range, leakage and repeated-request behavior.

The T-Deck controlled un-PROTECT command remains explicitly deferred at Ben's
request. No new architecture was adopted by this planning session; accepted
contracts remain in [the ADRs](../decisions/).

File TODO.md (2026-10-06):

# TODO

Active punch list. Status: `[ ]` open, `[~]` in progress, `[x]` done. Owner in parens.

## 2027 planning -- exploration, no implementation yet

Entry point: [2026 postmortem and future work](docs/postmortem/README.md).
Operational reference: [storage and wake](docs/howto/FIXTURE_STORAGE_AND_WAKE.md).

- [ ] **Review the firmware/tooling feature set with the post-event evidence.**
  Inventory commissioning, diagnosis, show, maintenance, storage and repair
  workflows; mark keep/improve/consolidate/retire and the replacement evidence.
  T-Deck per-fixture controlled PROTECT recovery is explicitly deferred at
  Ben's request on 2026-09-14; preserve specimens/history before any repair.
- [ ] **Evaluate a dedicated LFP/solar power platform against the current fleet.**
  Start with requirements and measured bench/outdoor comparisons, not a fleet
  BOM. Assess autonomous LFP charging, private power bus, solar-only energy
  sensing, gauge characterization for both cell types, command reception
  energy/latency, low-power recovery and date/service wake contracts. Keep
  the existing chime-cap divider optional for diagnostics; weak/null strikes
  remain acceptable and cap sensing is not a required operator-strike gate.
  Quantify monitoring overhead and hardware cutoff leakage.
  Assess RFID identity plus independent targeted hardware wake/reset from
  ground level, including shared RTC coin-cell power and passive fallback.
  Include bounded wake-directly-to-maintenance for faster OTA, fleet coverage
  and duplicate-wake behavior that cannot interrupt an active upload;
  see `docs/projects/2027-power-platform/RFID_SERVICE_ACCESS.md`. Discussion draft:
  `docs/projects/2027-power-platform/EXPLORATION.md` (Ben/Codex).

## Immediate documentation / repo hygiene

- [x] **Authorized USB-wake container-storage rollout completed 2026-09-12.**
  All 106 observed fixtures passed exact f951ae9 OTA verification, acknowledged
  USB storage with matching durable audits, and stayed quiet for at least
  38m37s after the final receipt. All campaigns stopped; laptop capture and
  temporary awake hold released at 19:18 PDT. Eight never-heard fixtures were
  not commanded. See `docs/tests/CONTAINER_STORAGE_CENSUS_2026-09-12.md` and
  `storage-final.json` in the retained container evidence directory. Source
  and exact artifacts are integrated in this repository; see
  [storage and wake](docs/howto/FIXTURE_STORAGE_AND_WAKE.md).
- [ ] **Qualify storage on an accessible assembled fixture during servicing.**
  Measure gauge-enabled ship current and timerless deep-sleep current; test
  USB/solar/QON wake from ship and RESET wake from timerless deep sleep; inspect
  T-Deck Rest -> Store layout and calendar behavior on the physical screen.
  Today's PREPARED/audit/quiet result does not measure electrical current or
  prove a physical wake cycle. RESET/BOOT alone does not wake ship mode.
- [ ] **Priority: investigate high-VBAT PROTECT recovery and chime eligibility.**
  Wake/Performance Hold do not keep PROTECT radios continuously awake; surface
  this exclusion in Wake eligibility/status instead of implying full-fleet reach.
  September 12 census: 40/74 PROTECT at >=3.25 V, but no good-input recovery
  trace. Both known release fixes were already in those fleet revisions.
  Current-policy offline reproduction shows net-positive sleep-cycle charging
  can fail the awake +20 mA/60 s proof; intermittent evidence also restarts it.
  Preserve Kiki/Kairi/Groot state; compare stable and weak/variable input with
  actual sleep/wake current, then distinguish battery/path faults from a policy
  limitation before changing thresholds or deploying. Track the separate
  intentional inspection-firmware chime veto. Add recovery/chime waiting reasons
  to diagnostics. See `docs/tests/PROTECT_RECOVERY_INVESTIGATION_2026-09-14.md`.
- [ ] **Map and service the Oakland lantern bin and two backyard prototypes.**
  Ben intends to keep them out, with no deliberate sleep/ship command.
  Preserve revision/configuration/reset/sleep/charger state before changing
  firmware or clearing guards; compare Groot against Kairi/Kiki for the
  post-mortem, and investigate Wooper's older maintenance-discovery failure.
  September 14 read-only TSwift snapshot: Groot 9F2724 (2.880 V), Kairi
  9F26B4 (3.303 V), Kiki F2BF5C (3.277 V), Wooper 9F0E30 (3.321 V), and
  P105 prototype 9F26F8 (2.992 V). These are last-listen readings, not cell
  measurements. None was in the stored 106. Map all five canopy lanterns,
  the batteryless panel-connected uplight and both prototypes to exact IDs;
  check Groot's cell/charge path and the prototype power setup. TSwift 979604
  still runs older firmware; storage4 is on primary 8EB508. See
  `docs/tests/OAKLAND_LANTERN_INVENTORY_2026-09-14.md`.
- [ ] **Locate/check the six remaining unobserved September 12 fixtures.**
  Gambit `F2BCF4`, Gengar `F2BDD4`, Magmar `F2BDFC`, Donkey `F2BE10`,
  Milotic `F2BE94`, Skitty `F3FD28`. Kairi and Wooper were subsequently heard
  in Oakland on September 14, accounting for two of the original eight.
  Absence does not diagnose a dead/recovered cell or prove container location.
  Identify historical 0-0.6 V reports by exact fixture/cell and measure actual
  cell-terminal voltage at service; remove external power before battery swaps.

- [ ] **Explicitly deploy the prepared ADR 0074 emergency inspection image.**
  PARTIAL 2026-09-01: 70 of the 114-fixture installed census have fresh exact
  revision proof; 44 remain, including 39 currently reporting PROTECT and five
  confirmed physical canopy/downlights. Resume only the exact roster in
  `docs/tests/ADR_0074_PARTIAL_FLEET_ROLLOUT_2026-09-01.md`. The two older
  `-p` images `9F0E30` and `9F26B4` require explicit rescue handling because
  they report mesh heartbeats but did not open shared-WiFi maintenance.
  Source now makes every point-source/unknown role static linear
  `R=G=B=255,W=0`, keeps perimeters to one full-RGB center pixel, disables
  autonomous/presence art and chimes, starts one hour before civil dusk,
  and duty-cycles only the radio at 12 s on / 120 s off without blinking the
  LED rail. ADR 0075/0076 add a campaign-owned bounded direct-control session:
  Wake Fleet gathers for six minutes and its final copies leave roughly ten
  minutes of full-fleet control. LED/audio frames cannot extend it. LED Studio
  and CoreS3 Audio may temporarily override,
  perimeters stay center-pixel-only, and static white self-restores. CoreS3
  Audio adds 1X/1.5X/2X/3X output gain with a 2X default. Native and embedded
  fixture/T-Deck/CoreS3 builds pass; battery DIM/OFF/PROTECT remains
  authoritative. The prior `fx-260831-32dcb76-b` artifact predates this control
  seam and is superseded before deployment. Clean replacement field/channel-11
  artifact `fx-260831-f121868-b`, SHA-256
  `569fa5a584019e5b4d1dedcfbea832c2b72339246f12badb6042ee5adcd29c2e`,
  is built from source commit `7c1f71d`, retained, and independently checked.
  T-Deck `8EB508` is USB-flashed with ADR 0077's separate one-hour Performance
  Hold, which uses the existing Wake packet and needs no fixture rebuild. Its
  final refresh leaves up to a ten-minute bounded fixture tail. Field-smoke the
  new button, countdown, Auto/Night cancellation, and one sustained CoreS3
  Audio stream.
  Deploy it with exact named rosters plus fresh exact-revision heartbeats beyond
  pending verify. The first field
  observation must confirm full RGB point output, one-pixel perimeter output,
  continuous light through a radio-off boundary, radio rejoin/heartbeat, and
  the advanced dusk boundary. Then tap Wake Fleet, wait one complete radio-off
  phase, verify fleet-wide LED/audio control, stop the stream and confirm static
  fallback, and confirm control expiry restores duty cycling. Retain ADR 0074,
  ADR 0073, and ADR 0072 artifacts as rollback (Ben/Codex; ADR 0074/0075/0076).
- [x] **ADR 0073 partial rollout recorded -- SUPERSEDED FOR INSPECTION
  2026-08-31.** Source/
  native and fixture/T-Deck development builds pass: scheduled-
  night uplights use the 128/255 RGB-white visibility floor; perimeters use one
  full RGB-white center pixel with local/origin VL53 art disabled; canopy
  presence blinks the already-rendered color; and the T-Deck adds an explicit
  `R=G=B=255,W=0` swatch. Immutable artifact `fx-260831-dc82da7-b`, SHA-256
  `7230f81ff1737fa51ebdd357b9249748e5712657469de82a4b5b75799ac83299`,
  is verified on 96 of 112 fixtures: all 91 that were non-PROTECT at rollout
  start plus five explicitly targeted PROTECT fixtures. Resume later against
  only the 16 rollback-revision fixtures in
  `docs/tests/ADR_0073_PARTIAL_FLEET_ROLLOUT_2026-08-31.md`; continue requiring
  fresh exact-revision heartbeats beyond pending verify and retain
  `fx-260831-b3e2738-b` as rollback. ADR 0074 now owns the next fleet rollout;
  preserve this 96/112 census as exact rollback evidence rather than completing
  the superseded artistic widening (Ben/Codex; ADR 0073/0074).
- [ ] **Assign known physical callsigns to newly preserved fixtures `9F268C`
  and `F402A8`.** Their commissioned registry rows are valid, but the T-Deck
  production-health generator correctly refuses active fixtures without an
  entry in `ops/fleet/callsigns.csv`. Use the names actually attached in the
  field; do not consume arbitrary spares merely to make the test green (Ben).
- [x] **Deploy and observe the ADR 0072 final-burn bundle -- DONE 2026-08-31.** Source combines
  two battery-safe ordinary-wake canopy chimes, the hourly ritual, perimeter
  too-close center hold, propagation-only 300 s/30 s re-arm, and autonomous
  10-minute CA/Color Virus/Epidemic/presence-CA rotation. Fixture native and
  T-Deck embedded build gates pass. Immutable field/channel-11 artifact
  `fx-260831-b3e2738-b`, SHA-256
  `1c31b265a1dba8544a7b02670e42382314d20fc0820cb67ed312ad43b25c349d`,
  was built from clean commit `316470a`. Exact named fleet and direct-target
  OTA paths now leave all 112 visible PowerFeathers reporting that revision in
  field profile, with zero old revisions or commission-profile fixtures. Every
  accepted target produced a fresh exact-revision heartbeat beyond the pending-
  verify gate; no failure required physical access. Ben reports the ordinary-
  wake two-chime behavior is "incredibly delightful" and working very well.
  Preserve the prior artifact as the artistic rollback (Ben/Codex; ADR 0072).
- [ ] **Triage the changing PROTECT cohort from the 2026-08-31 field census.**
  Prioritize physical perimeters because of their 6 Ah batteries/P126 panels,
  including Gengar `F2BDD4` and Skitty `F3FD28`, then uplight Donkey `F2BE10`
  and canopy Ponyta `F2B7DC`. Record installed positions for PROTECT uplights Mipha
  `9E5B5C`, Cubone `9F2648`, and Donkey so the suspected north-side panel issue
  can be tested instead of inferred. Resolve roles for Chunli `9F2714`, Abra
  `F2BDB4`, Yoshi `F2BE08`, and Dratini `F4035C`; preserve Skitty's physical
  perimeter identity while separately diagnosing its missing live sensor/class
  report. Power state changed during the OTA session: 96 fixtures now run ADR
  0073 while the exact 16-fixture rollback/resume roster remains in
  `docs/tests/ADR_0073_PARTIAL_FLEET_ROLLOUT_2026-08-31.md`. Treat recorded
  voltages as stale snapshots, not live safety evidence (Ben/Codex).

- [x] **Prevent field day sleep from resetting a qualified PROTECT release --
  DONE 2026-08-29.** Exact outer downlight Toad `F2BEE4` proved the defect on
  `fx-260827-1254f04-p`: healthy +506 mA charging in durable PROTECT was cut
  short by the independent 12-second `day-charge` sleep, making a continuous
  60-second release proof impossible. Lifecycle now makes power policy the
  sole owner of sleep at `LedTier::PROTECT`; native coverage pins PROTECT awake
  while FULL/DIM/OFF day behavior remains unchanged. The full integrated native
  suite and ESP32-S3 build pass. Exact-target USB canary
  `fx-260829-b0ff5db-b`, SHA-256
  `276d6558116a40da15f32eccf6bc7a940ef6d827ba965ddb81a8a8f5b0e27ae0`,
  passed on Toad with field/channel 11, healthy charging/no-fault BQ, correct
  downlight class, MSA/TMF/BMP samples, ESP-NOW, and a later clean 120-second
  timer wake. Toad's retained stage was already DIM after the USB flash, so
  this exact run did not replay a live PROTECT -> OFF release; the pure
  regression is the direct branch proof. Groot `9F2724` subsequently arrived
  in genuine low-voltage PROTECT, released on the old image during the longer
  physical-reset window, and passed the same exact canary plus USB/WiFi gate;
  this confirms a second repaired fixture. Logan `9E5A88` then supplied the
  missing live branch proof: the exact canary remained awake at 21.6 s after a
  deliberate one-second deep sleep (past the old 12 s cutoff), completed the
  sustained full-battery PROTECT release, persisted OFF, clean-rebooted, and
  advanced to DIM with healthy MSA/TMF and WiFi. This closes the timer-wake
  hardware acceptance. Eevee `9F0E54` then arrived in genuine low-voltage
  PROTECT with a retained 3.030 V entry. Physical RESET gave the old image's
  long service window; healthy roughly 1.1 A charging released it cleanly to
  OFF. The same exact canary passed USB/WiFi commissioning with its physical
  15 Ah capacity restored and healthy MSA/TMF/BMP telemetry (Ben/Codex).
- [ ] **Repair quarantined downlight Shuckle `F4031C`.** Its old commission
  image repeatedly failed all four PowerFeather init attempts with charger,
  gauge, rails, and sensors inaccessible. Disconnecting the sensor chain made
  the board healthy; TMF8820-only and MSA311-only each passed, while the suspect
  inter-sensor cable also failed when connected directly to the known-good MSA.
  Ben then accidentally connected solar without the battery and the USB app
  stopped enumerating. Recover USB-only without erasing, discard/mark the bad
  cable, validate a different cable directly, rebuild the full chain, reconnect
  the confirmed 15 Ah cell, and complete exact USB/WiFi commissioning before
  removing quarantine (Ben/Codex).
- [~] **P0: hardware-validate ADR 0071's hourly 72-cymbal daytime ritual.**
  Source now decouples energy readiness from all-day radio reception, carries
  readiness across only one freshly requalified timer wake, aligns the final
  sleep to T-20 seconds, and implements the fixed unison -> deterministic roll
  -> sparse after-ring through T+47 seconds. Native and exact-target embedded
  compile gates pass; nothing was flashed. On one physically identified,
  battery-installed cymbal downlight, prove high-quality UTC wake alignment,
  T+5 unison attempt, stable hash slot, optional after-ring, hard end, return to
  sleep, and no duplicate after an in-window reset. Then prove unison abstention
  with >500 ms uncertainty and all schedule/energy/lease/class/mechanism vetoes.
  Widen only through immutable named artifacts and explicit target cohorts
  (Ben/Codex; ADR 0071).
- [ ] **P0: run the exact-target radio-off + perimeter-ToF sentinel power
  campaign before implementing sentinel wake behavior.** Physically identify
  one healthy perimeter fixture, record its exact current artifact/SHA/state,
  build one immutable `--sentinel-trace-target <MAC>` `-t` image, and run the
  automatic 10-minute off / 30-second warm-up / 10-minute ToF / 10-minute off
  A/B/A. First use battery-isolated or consistently shaded input for load
  delta; repeat in full sun for net energy and at least 20 deliberate close-palm
  approaches. Download with `capture_sentinel_trace.py`, reject any radio leak,
  rail mismatch, stalled VL53 reads, reset/fault, poor sunlight detection, or
  unacceptable 6 Ah/night-budget cost, then restore and verify the exact prior
  fleet binary. Do not implement visitor-triggered fleet wake until Ben accepts
  this evidence; any eventual session needs a non-extendable deadline and
  cooldown (Ben/Codex; ADR 0071).
  **2026-08-29 partial field run:** physically confirmed Spyro `F2BCF0` passed
  exact canary OTA and pending verify; Ben performed about 15-16 close hand
  holds during the active phase. Do not accept a power delta: rapid sunrise
  contaminated the A/B/A trend, and an 8-second task-watchdog reset during the
  synchronous maintenance WiFi scan erased the completed PSRAM trace. Exact
  prior artifact `fx-260827-1254f04-p` was restored and fully verified without
  opening the lid. Source now uses bounded asynchronous WiFi scanning with
  watchdog service; native, Python, and embedded compile gates pass. Before the
  next full campaign, hardware-prove retrieval with this fix, then repeat under
  stable shade/battery-only and stable full sun. Also resolve Spyro's corrected
  boot probe still reporting only VL53 bit 2 rather than MSA+VL53 bits 10.
  **Controlled-shade rerun:** exact canary `fx-260829-9f140c3-t` held input
  below `supply_good`, and Ben made about 14-15 close approaches, but retrieval
  independently reset with `task_watchdog` again and erased PSRAM. Do not accept
  a power delta or edge count. Async WiFi scan alone is therefore insufficient.
  Source now checkpoints the completed trace to the unused SPIFFS partition
  with exact-artifact/header/sample CRC and sequence validation, then reloads it
  into retrieval after any reset. Native, 20 focused Python, and embedded build
  gates pass; hardware persistence/retrieval proof remains required. Exact-prior
  no-lid restore job `612D848D` completed and formally verified Spyro back on
  `fx-260827-1254f04-p` at 27,720 ms uptime, field/perimeter, no recovery or BQ
  fault. A later exact `fx-260829-96862d8-t` persistence attempt passed OTA but
  did not yield an accepted trace. It silently reran after a task-watchdog reset,
  then reset again at the VL53 transition because the synchronous 100 kHz
  firmware upload lacked internal watchdog service. Job `E1428FE2` restored the
  exact prior image and verified it at 30,316 ms uptime. Source now writes a
  CRC-protected run marker before acquisition, read-validates a separately
  committed checkpoint before advertising it, enters rail-off recovery-only
  maintenance after an interrupted/corrupt run, exposes the named persistence
  state, and makes the host refuse recovery-only evidence. VL53 I2C chunks and
  waits service the armed watchdog. Before any full or human-assisted rerun,
  pass the new 40-second `--sentinel-trace-smoke` gate, OTA the same exact
  artifact again to prove reboot survival and identical count/sequence, retrieve
  it, and restore the exact prior. Smoke evidence is not power evidence and the
  downloader rejects it. Fresh `sensor_bits=10` proves MSA311 at corrected
  `0x62` plus VL53 on that boot; investigate why earlier boots were intermittently
  bit 2 before describing the chain as consistently healthy.
  **2026-08-31 field posture:** ADR 0073 disables perimeter ToF art and program
  origins in the production image while keeping VL53 sampling/telemetry. This
  campaign remains the post-burn evidence gate before restoring either use.
  Evidence: `docs/tests/PERIMETER_SENTINEL_CANARY_2026-08-29.md`.
- [~] **P0: canary ADR 0069/0070 synchronized palette, count-aware HEX power,
  and role-correct ToF interaction.** Source and native tests now provide a
  20-minute UTC-synchronized GH hue cadence; a 765-RGB-channel-unit physical
  HEX budget that leaves sparse gobos full-bright and scales dense washes; and
  a local ToF renderer that maps 150-1,800 mm to color while peeling perimeter
  output 37 -> 19 -> 7 -> 1 pixels. The art-site TMF census sampled 46/61 exact
  downlights: 42 close returns at 145-575 mm and four healthy all-zero/open-view
  nodes (Panther `9E5A84`, Gible `9E5B34`, Sakura `F2BE0C`, Leia `F40384`).
  Fleet Identify later proved Sakura was in a bin, so zero depth is not evidence
  of installation height. The reported roughly 15 ft canopy height exposed an
  artificial 2.5 m parser/presence cap; hardware supports 5 m and a standing
  head should be about 2.7-3.2 m away. ADR 0070 now accepts the full range,
  re-baselines after a close-bin -> far-tree move or sustained empty scene, and
  drove a persistent full-W downlight gobo from learned per-zone presence;
  ADR 0073 now blinks the already-rendered program/direct color instead.
  Interaction applies after every visible program, including direct bridge
  frames, but cannot awaken blackout or bypass battery/rail policy. Complete
  native tests and an ESP32-S3 development compile pass. The perimeter canary
  passed on Dixie and the base downlight/full-output canary passed on Froakie
  under ADR 0069, but the close downlight response was not exercised and is now
  superseded. **2026-08-29 partial installed canary:** exact Sakura `F2BE0C`
  passed immutable artifact `fx-260829-8790f6d-p`, SHA-256
  `5bd65970990a34e511b44cb9a9ef1a7dc4e93a7b3cd3746df08abafb3e0ab6bf`,
  fresh exact-revision rejoin, pending verify, field/downlight/recovery checks,
  post-update healthy zero-depth TMF telemetry, visible low-white lease, no
  empty-scene false trigger across eight minutes, exact release, and mesh
  cleanup. Ben then used Fleet Identify, pointed the bin-resident Sakura at
  himself, and visually confirmed the intended full-white response. People
  walking under the installed tree also reliably turn nearby canopy lights
  white. The interaction therefore passes artistically and Sakura's new path
  passes functionally. Before fleet promotion, still quantify one named
  installed fixture's raw range/margin at the roughly 15 ft height; if it cannot
  see a standing person, height/aim/sunlight remains a P0 installation gate.
  The MSA311 accent
  seam is implemented but fleet-disabled pending
  quiet/wind/touch/swing/climb traces; barometric modulation and aggregate
  ring/all-perimeter presence remain open. Perimeter local/origin ToF art is
  field-disabled pending the sentinel evidence above (Ben/Codex; ADR
  0069/0070/0073).
- [~] **P1: characterize the canopy as a swinging scanner before tuning ToF or
  MSA thresholds.** Windy-night field observation shows each downlight swings
  chaotically over two pendulum axes. A stationary person can be discovered by
  multiple nearby fixtures as their ToF cones sweep past, producing a lively
  multi-light white response that Ben likes. Record one named installed fixture
  through empty wind, a stationary person, walking, and leaving with TMF scalar/
  per-zone range and confidence, MSA311 sway envelope, and visible presence
  state on one clock. Exact-target source instrumentation now compiles and
  records about 5.5 minutes at 25 Hz during real show behavior: raw XYZ,
  low-pass gravity, tilt/sway, all nine TMF zones/confidences, production
  presence edge/latch, lifecycle/program/power, and rendered output. Its
  maintenance downloader refuses identity/revision/target/sensor mismatches and
  exclusive-creates evidence. Native tests and an embedded ESP32-S3 test build
  pass. Next: physically identify one actually hanging downlight, build its
  immutable `-t` artifact, run the wind/still/walk/leave scene, download, and
  restore its exact pre-trace fleet artifact. Measure empty-scene false triggers and response durations,
  then tune minimum white hold, clear hysteresis, and retrigger cooldown. Do not
  use MSA311 as a blanket swing veto: that would erase the desired scanning
  behavior. Keep the currently proven thresholds until this trace exists
  (Ben/Codex; follows ADR 0070).
  superseded. **2026-08-29 Gible installed-height canary: OTA safety passed but
  useful-height interaction remains on hold.** Exact target Gible `9E5B34`
  accepted immutable normal
  artifact `fx-260829-7906e6f-p`, SHA-256
  `95df1a6b18f21c0f0643949e70474a4d2af019e85efbb86f21877af350dadb7d`,
  and passed fresh exact-revision rejoin/pending verify. Two valid exact-target
  rolling traces retained about 70 seconds each while Ben stood and walked
  naturally beneath the installed fixture. They saw only fixed 166-363 mm
  near-field returns, no person-range return, no presence edge/latch, and no
  required `W=255` response. Seven pre-trigger `W=25` intervals match Ben's
  visual observation and ordinary GH CA quiescence. A later foolproof,
  five-minute exact-target sentinel removed the remaining capture ambiguity:
  red meant no latch and full RGB white meant the unchanged production
  presence latch was active, with two green Identify markers bracketing the
  experiment. Ben had to hold a split high to trigger it. The trace then
  recorded 46 >1 m frames, five presence rises, and 49 active samples; every
  active sample rendered full RGB white and no inactive sample did. This proves
  the sensor/parser/debounce/render path, but not useful ordinary standing or
  walking interaction. A final raw 1-5 m target-only image removed background,
  debounce, and hysteresis while excluding the known <400 mm self-splay. It
  recorded no sampled false positives across 266.145 seconds of empty scene,
  but a bamboo split held roughly 2 m away produced no 1-3 m return: instead,
  the same 34.355-second interaction produced 3.24-5.00 m reports across five
  zones. This rejects the far reports as proof of usable physical range and
  points to aim, occlusion, edge/background ranging, or multipath. A lower-hung
  Astro `9E5B44` control then used the identical raw predicate. At roughly 12 ft,
  walking beneath it produced only a split-second flicker while Ben's raised
  hand produced a denser visible response. Its 304.3-second trace contained 35
  white samples, all from physically plausible 1.003-1.561 m zone returns, and
  no 1.562-5 m return or empty-scene false positive. Since Ben is 6 ft 3 in,
  the roughly 1.75 m sensor-to-head gap was just outside the demonstrated band.
  Lowering helps, but 12 ft remains marginal for passive walk-under behavior.
  Exact jobs restored both fixtures and verified field posture. Next: test a
  roughly 10 ft mounting or equivalent re-aim, inspect/clear Gible's TMF
  aperture and field of view, then repeat a normal-person test before any
  threshold tuning or ADR 0070
  promotion. The MSA311 accent seam is implemented but fleet-disabled
  pending quiet/wind/touch/swing/climb traces; barometric modulation and
  aggregate ring/all-perimeter presence remain open (Ben/Codex; ADR 0069/0070).
- [~] **P0: canary ADR 0068 high-VBAT PROTECT recovery and provenance.**
  Exact outer downlight Rikku `9F26B0` is dark on
  `fx-260827-1254f04-p` with durable guard stage 4 / power tier 3 and an entry
  audit of 3.596 V in field profile at 2.809 s uptime. This is not a low-voltage
  transition. Fleet history proves the latch predates that artifact: OTA at
  3.582 V preserved it, and a later gather still found the 900 s PROTECT cadence
  at 3.536 V. The leading entry mechanism is an unexpected reset with the
  durable load marker armed, but current audit fields do not retain the
  predecessor stage/reset reason. ADR 0068 source now preserves origin,
  predecessor, reset reason, prior `load_arm`, and reset streak in the same-size
  durable audit record and append-only heartbeat. Good USB/no-fault telemetry at
  3.56-3.58 V / 99 percent accepted only about 0-2 mA, so the policy now adds a
  separate sustained full-battery proof: corroborated real cell, >=3.45 V,
  valid/good input, valid enabled/no-fault BQ, and CV/top-off/not-charging state
  for 60 seconds. Missing data or a proof change resets the clock; CC with low
  current is rejected. Fixture, T-Deck, parser, and embedded compile gates pass.
  **2026-08-28 positive hardware canary passed:** clean combined artifact
  `fx-260828-abd893c-p` from commit `5865282`, SHA-256
  `6a0126f205be2cb6be034a71de5c5caa75f0af0acd00e1684ddc27377fb175f5`,
  OTA-verified on exact Rikku through pending verify. The retained false PROTECT
  satisfied the sustained full-battery proof, persisted stage 3, clean-rebooted,
  and advanced OFF -> DIM -> FULL with the daytime rail off, downlight class,
  healthy TMF/MSA, no mismatch, and no NVS erase or bypass. Next: negative-gate
  fault injection, then fleet audit for other high-VBAT PROTECT entries
  (Ben/Codex).
- [x] **Finish ADR 0067 canary acceptance on exact uplight Togepi `9E5AB0` --
  DONE 2026-08-28.** Before its exact USB update, registry-rostered 6 Ah uplight
  Togepi reproduced the original defect on `fx-260828-658b7d2-p`: chandelier
  class, `sensor_bits=0`, and no MSA311. Combined artifact
  `fx-260828-abd893c-p` fixed class/MSA detection but exposed a second source
  defect: the RGB uplight was incorrectly driven with four-byte `NEO_RGBW`, so
  logical smoke/rail-on telemetry produced no physical light. Commit `0f08904`
  pins uplight to one three-byte `NEO_GRB` pixel and uses RGB white for its smoke
  frame. Complete native tests and embedded compile pass. Clean replacement
  artifact `fx-260828-d8f62c3-p`, SHA-256
  `57f40023e1e599d60cf2a309e6a7af2f94bf45716421309b2b3a15048b239097`,
  passed exact USB write verification, uplight/MSA/class/power checks, visible
  white breathing with about 119 mA real load delta, `L0`, reset, rail-off, and
  ESP-NOW recovery. Donkey `F2BE10` was later found by exact cohort job
  `444537E1` and passed upload, fresh exact-revision rejoin, pending verify, and
  field-profile checks on the same artifact (Ben/Codex).
- [x] **Promote ADR 0067 plus the RGB uplight format fix to every manufactured
  uplight -- DONE 2026-08-28.** Exact jobs `45208DD7` and `444537E1` verified
  19 OTA targets through fresh exact-revision rejoin and pending verify;
  together with USB canary Togepi, all 20 physically manufactured uplights run
  immutable artifact `fx-260828-d8f62c3-p`. A direct settled check on Psyduck
  confirmed uplight class, `sensor_bits=8`, no mismatch, and field profile. Ben
  confirmed the physical cohort is 20, not the 24 rows previously rostered from
  planning allocations. Ken `F2B8DC`, Pikachu `F2BCE0`, Kirby `F2BE64`, and
  Haunter `F40438` are not manufactured uplights and are role-unassigned; they
  require no uplight rollout action (Ben/Codex).
- [~] **Finish dual-site maintenance WiFi deployment and the split-fleet tail
  (ADR 0066).** Source commit `91663fd` and immutable artifact
  `fx-260828-658b7d2-p` implement two bounded gitignored credential profiles;
  native tests, production build, exact Swablu canary, and 98/110 intended
  fixture promotion contracts passed. No secret is tracked. Hardware-prove the
  second profile at the art site with one exact fixture before relying on it for
  USB-tail avoidance. Exact Rikku `9F26B0` subsequently passed combined artifact
  `fx-260828-abd893c-p`; 13 intended fixtures still lack the current dual-site
  fleet image. The set is `9E5A88`, `9F0E54`, `9F2724`, `F2B7DC`, `F2B900`,
  `F2BCF0`, `F2BCF4`, `F2BDC4`, `F2BDD4`, `F2BEE4`, `F40308`, `F4035C`, and
  `F403DC`. The working
  11-unit perimeter USB queue is Cammy `F2B900`, Spyro `F2BCF0`, Gambit
  `F2BCF4`, Batman `F2BDC4`, Gengar `F2BDD4`, uncalled `F2BE80`, Clank
  `F2BF60`, uncalled `F2BFEC`, Thor `F40344`, Dratini `F4035C`, and Sneasel
  `F403DC`. Read exact USB identity before flashing because the physical
  slot-to-MAC map is still incomplete. Clank needs supervised low-voltage/
  commission recovery (Ben/Codex).
- [ ] **Close the ADR 0062 fleet-OTA control-plane gaps exposed by the dual-site
  rollout.** A 101-target job received only 93 roster acknowledgements; a
  53-target partial-discovery job failed the whole wave when eight found
  endpoints vanished before fresh maintenance preflight; and a PROTECT cleanup
  saw a transient dashboard HTTP 500 during freeze, then rejected a later safe
  bridge phase-3 stopped/expired status. Make roster loading acknowledged and
  retry-bounded, demote vanished endpoints to deferred before UPLOAD, retry
  transport-only freeze failures without weakening exact job/target evidence,
  and accept a fresh matching stopped phase as cleanup proof. Preserve no retry
  after upload ACK or ambiguous upload (Ben/Codex).
- [~] **Canary and promote trustworthy short-wake solar telemetry (ADR 0064).**
  The 120 s / 3 s artifact exposed a real defect: boot disabled charging, sent
  a full heartbeat before the 6 s battery guard, and could return to sleep
  before either charge enable or a fresh MAX17260 Current conversion. Source
  now appends explicit power-sample validity, withholds IBAT trust until 12 s,
  sends a corrected full heartbeat on the validity transition, and blocks
  ordinary day sleep until that sample or a bounded 15 s gauge-fault fail-open.
  Native fixture/T-Deck/host tests and both embedded builds pass; exact T-Deck
  `8EB508` is flashed with the new UI. Clean immutable credentialed candidate
  `fx-260827-db0cb73-p` is retained from source `8c0e577`, 1,207,408 bytes,
  SHA-256 `e30c42802f34966ca5c959539d20bf9c737786c935dc81c3934a3ff638386b5c`.
  **2026-08-27 canary:** sole writer `8EB508` OTA-flashed only field-profile
  Hawkeye `9F2664`; job `192D6A8B` proved exact-revision mesh rejoin past the
  pending-verify gate with no commission fixture or mutation. Read-only
  post-reboot evidence showed +312 to +323 mA at 3.567-3.573 V, strong input,
  `CHARGING_CV`, and DAY_ACTIVE after the 60 s solar-surplus confirmation. The
  exact job/upload ledgers are retained under `ops/bench/data/Nevada City/`.
  This strong-solar run could not exercise ordinary sleep. Before widening,
  reduce/remove Hawkeye's input and prove early IBAT unverified -> charge enable
  -> validated signed current at about 12 s -> 120 s sleep -> later timer wake.
  Also prove negative current, check a terminating/full battery, Health VBAT/CHG
  colors and detail, the 15 s no-gauge fail-open, Wake Fleet capture, and long
  Blackout lease. Include a deliberately persisted commission canary with
  `--fix-commission-profile` and preserve exact-target detection, NVS correction,
  and fresh field-profile confirmation in its OTA ledger (Ben/Codex).
  **2026-08-27 fleet promotion:** the prior candidate was superseded by current
  clean source `d6c9234`, including ADR 0065, in immutable production artifact
  `fx-260827-1254f04-p` (1,207,376 bytes; SHA-256
  `2f9a93344e172b023ee8df473b7c747b26f38dc0ec5353f6efd00d50ec45f4af`).
  Hawkeye passed the exact canary and all 109 post-canary targets accepted that
  same binary. The roster reports all 110 intended targets on the exact revision
  and FIELD profile; 107 have full fresh pending-verify proof. Record later fresh
  exact-revision wakes for `F2BCF4`, `F2BEE4`, and `F2B7DC`, which report the new
  image but missed the host freshness/verification deadline. The deployed fleet
  can now supply broad signed-IBAT solar-health evidence, but the explicit
  no-gauge fail-open and terminating/full-battery checks remain open (Ben/Codex).
- [ ] **Close LED Studio semantic-white behavior during class-census gaps.**
  The planner correctly sends dedicated W to a known downlight, but maps class
  `unknown` to RGB white and currently consumes only the raw T-Deck census. It
  does not use the embedded registry-role fallback already used by Fleet, so a
  known registered downlight can briefly receive RGB white when its full
  class-bearing heartbeat was missed but a short heartbeat made it fresh.
  Choose and test a fail-safe rule: use the registry role for class 0, or refuse
  semantic white until class telemetry is known. Validate on named downlight
  and RGB-uplight canaries without weakening live sensor class authority
  (Ben/Codex). **2026-08-27 hardware evidence:** Leia `F40384`, which had shown
  RGB white in LED Studio the prior night, now directly reports class downlight,
  no mismatch, sensor bits 5, and healthy MSA/TMF/BMP; TMF has 85,330 reads with
  zero errors/recoveries. This rules out a current fixture sensor failure and
  makes the raw-census unknown window the supported failure mechanism.
- [ ] **Prototype the T-Deck WiFi camera viewer after the Windows UVC viewer is
  accepted.** Keep the USB camera on a laptop or Raspberry Pi host and serve a
  bounded 320x240 JPEG/MJPEG view to Bridge OS over the channel-11 WiFi network.
  Measure latency, decode/render cost, heap/PSRAM watermark, and coexistence with
  ESP-NOW before making it an app. The stock T-Deck Plus USB-C is wired as a
  device/power sink and does not source camera VBUS; do not treat a passive OTG
  adapter as a host solution (Ben/Codex).
- [~] **Hardware-validate the permanent Bridge OS shell bar.** Source,
  pure-model tests, the full native suite, and the embedded build pass. Hardware
  rejected the initial full-width bottom overlay because it covered LED
  Studio's Solid/Stop/Back row; the compact top-left pill avoided the buttons
  but still covered titles. The current design reserves y=0..25 on every screen:
  app identity at left, scrolling activity/idle status in the center, and fixed
  clock/Stop cells at right only for local direct streams or tracked leases.
  The clock updates separately so it cannot restart the ribbon animation.
  Streams count up as `LOCAL ... until STOP`; leases count down; fresh competing
  T-Deck, PUCA, CoreS3, or unknown publishers are passive warnings by exact ID.
  All app content now starts at y>=26. Physical polish gives app identity, ticker,
  and clock distinct colors, expands Stop to avoid clipping, and labels the idle
  fields `WiFi joining`/`mesh-only`, `ch11`, `live N/M`, and `bat N%`. The exact
  image is 1,565,280 bytes and is
  flashed and boot/mesh-checked on camp-labelled TSwift `979604`; SHA-256 is
  `3267a1b237a2a4708e5c999cf1730f497ecbc30bd80e299a8b76374764931d4c`.
  On TSwift and named fixture canaries: start Solid, Blink, Patterns, CA,
  Blackout, and Contagion;
  navigate the launcher, every major app, and a confirmation modal; confirm the
  shell ribbon and touch Stop remain available without covering app controls;
  verify
  direct frames go stale within
  three seconds and program Release clears the lease. Check countdown expiry,
  foreign-only status without a misleading Stop, local-plus-foreign conflict
  color, self-frame suppression, known publisher labels, unknown-source ID,
  and no false persistence after the three-second freshness window. Exercise a
  second T-Deck plus PUCA/CoreS3 only after declaring one command operator and
  naming every target under ADR 0040 (Ben/Codex).
- [ ] **P0: detect and recover a live T-Deck transmit-path stall.** On
  2026-08-29 exact bridge `8EB508` continued receiving the channel-11 fleet and
  emitting a healthy census while both LED Studio and Fleet/Blink stopped
  affecting fixtures. `sendok` stayed exactly 9,058 across attempted sends and
  `sendfail` stayed zero; fixtures remained in CA. A T-Deck reboot restored the
  path immediately, and Ben confirmed a new all-fleet green stream while TX
  callbacks advanced. Instrument every synchronous `esp_now_send()` result
  (accepted/error counts plus last error), because the existing counters see
  callbacks only and ordinary send sites discard enqueue failures. LED Studio
  must distinguish planned targets from successfully submitted frames and show
  a radio fault instead of an active-looking stream. Add a bounded peer/radio
  re-init or watchdog policy for stream-active TX-flat/RX-growing evidence,
  preserve a diagnostic before recovery, and hardware-reproduce with an
  all-fleet soak. Do not infer CA arbitration from this signature
  (Ben/Codex).
- [ ] **P0: make the localhost fleet dashboard fail visibly stale on serial
  loss.** During the same 2026-08-29 investigation, COM7 disappeared while the
  dashboard process and HTTP server stayed alive. `/api/state` and the browser
  continued serving the last 01:55 master/peer snapshot with no disconnect or
  master-age warning, making later read-only checks look live. Expose serial
  connected/disconnected state and master age in both API and UI, stop presenting
  cached peers as current, and either reconnect with explicit bridge identity
  verification or require an operator restart. Add a regression test for an
  unplugged/re-enumerated port while HTTP remains up (Ben/Codex).
- [~] **Hardware-validate the stable/filterable T-Deck Fleet view.** Source,
  the complete native Bridge suite, and the local embedded build pass. The new
  default is the complete callsign-stable registry plus unexpected live peers;
  off-air fixtures retain grey rows, selection and scroll context survive the
  two-second refresh, and View offers roster/seen/live scope, class and raw-
  VBAT-band and charger-phase filters, plus stable ID/name and dynamic
  voltage/age/signal sorts.
  The confirmed Blink action snapshots only fresh visible rows and paces exact
  30-second green identifies. On exact T-Deck `8EB508`, check all dropdowns,
  touch and trackball navigation, a long-list scroll through several refreshes,
  detail/back context, the 192-row heap/PSRAM watermark, and an explicitly
  named 2-3-fixture filtered canary cohort. Confirm the modal count, hidden and
  off-air exclusions, and no list shuffle in the default sort. Also confirm that
  default `DAY` is readable in direct morning sun at full backlight, the Fleet
  `DAY`/`NITE` quick toggle and Settings switch agree, night restores the saved
  level of 59, and live/header/selected/battery/off-air cells remain legible in
  both modes. The verified day-mode binary is 1,579,040 bytes, SHA-256
  `473510ba76ec5ee9ce47e76575556ac0a7783c78445d913548473e0b3d4b819a`;
  this exact image is flashed on `8EB508`. Esptool write verification, a full
  application-region readback with the same SHA-256, and post-reset channel-11
  mesh/peripheral/memory checks passed. The physical UI and named-canary checks
  above remain. **2026-08-27 source follow-up:** Fleet now keeps VBAT and signed
  battery current on the compact row, moves RSSI/PDR and advisory SOC to detail,
  renders never-seen age as `inf`, and distinguishes a reported IDLE from unknown
  full-heartbeat state. Detail spells out profile, lifecycle, tier, program, and
  network-mode names. View adds charge phase, program, and exact-reference/non-
  reference firmware rollout filters. Charge filters cover `CHARGING_CC`,
  `CHARGING_CV`, `TOP-OFF`, `DONE/OFF`, `FAULT`, unknown, and off air. The
  complete native suite passes. The combined
  local binary now flashed on exact `8EB508` is 1,581,168 bytes, SHA-256
  `c87b2805feb8bd95c0d6c9ae3022baaa40079483bca652de6c33f738c0e69e7e`;
  the linker reports 50 percent flash and 50 percent global RAM. Upload and an
  independent whole-application `verify-flash` digest comparison passed;
  post-reset identity, channel 11, mesh RX/TX, peripheral probes, and memory
  checks passed. Add physical checks for no row/header wrapping,
  signed-current legibility, IDLE versus `?`, detail-line/button clearance,
  scrolling through all eight view rows, each charge-phase canary, and mixed-
  revision match/non-match cohorts. **2026-08-28 daylight UX finding:** the
  fleet mixes lifecycle labels
  such as `boot` with selected-program labels such as `CA`, which can read as a
  daytime-lighting fault even though live `ledrail=false` and zero rendered
  pixels prove the fixtures dark. Visually distinguish lifecycle from an armed
  night program (for example `state: boot` and `armed: CA`) and keep rail/render
  state authoritative (Ben/Codex).
- [x] **Repair the T-Deck development-cache metadata boundary and prove warm
  incremental builds. DONE 2026-08-27:** cache schema 2 treats
  `build/dev-cache` as Arduino-owned and stores recipe plus interruption state
  in sibling `build/dev-cache.state`. Clean and recovery cover both paths while
  preserving the atomic single-writer lock and fail-closed interrupted-build
  behavior. A compile-free regression deletes every entry, including dotfiles,
  from the simulated Arduino build path and proves the next invocation retains
  its recipe, reports `DEV_CACHE_HIT`, and reuses the library object. The real
  ESP32-S3 seed took 3,051 s; two no-source-change builds took 143 s and 145 s
  (about 21x faster), left all `.o`/`.a` timestamps untouched, and reproduced
  the same 1,579,040-byte SHA-256
  `d4eb675e4c0423310325d9c35d8613c985d75edaea29833cfc71cb9c3b67f3db`.
  The complete native Bridge suite passes (Ben/Codex).
- [ ] **Make independent cold T-Deck builds byte-reproducible, or document the
  exact volatile input.** Three same-source, same-size 1,579,040-byte cold
  applications have produced SHA-256
  `2cabfda91dd2f28e0fbb4bfc9092834201b046197421087ac5100ad7156683b9`,
  `473510ba76ec5ee9ce47e76575556ac0a7783c78445d913548473e0b3d4b819a`,
  and `d4eb675e4c0423310325d9c35d8613c985d75edaea29833cfc71cb9c3b67f3db`;
  the new warm-cache rebuild correctly reproduced the last hash exactly.
  Identify whether ESP-IDF/Arduino embeds compile time, ordering, or another
  host input. Do not confuse this with immutable shared-artifact identity: the
  exact flashed/read-back day-mode image remains the second hash (Ben/Codex).
- [ ] **Close the two unsafe USB recovery exceptions and Dratini graduation.**
  The 2026-08-27 supervised recovery put 23/25 observed USB-powered fixtures on
  `fx-260826-51d1fe1-p`; Thor `F40344` intentionally retained the protected
  net-bench image. Clank `F2BF60` remains on old firmware at 0.86 V, below ADR
  0042's 2.20 V fleet recovery floor: isolate and replace/bench-diagnose the
  cell, do not lower the floor. A 2026-08-27 read-only T-Deck profile audit also
  found Clank as the sole observed `prof=0` commission fixture; correct it to
  field only during that powered exact-target repair, not as an ordinary fleet
  write. Tidus `F40424` already has current firmware but reports about 0.01 V/
  recovery refused and its same audit profile was unknown: inspect its battery
  connector/cell.
  Dratini `F4035C` rose from 2.342 V to about 2.46 V in active recovery; keep it
  on USB until a fresh sample proves recovery state 4 above the 2.55 V/60 s
  graduation gate. See
  `docs/tests/USB_POWERED_FIXTURE_RECOVERY_2026-08-27.md` (Ben).
- [ ] **Prevent long T-Deck `nb-peer` lines from truncating late fields.** The
  10 s fleet snapshot cadence now fits 115200 baud, but the fixed 1024-byte
  per-peer buffer can still truncate profile/recovery/sleep-audit tails on a
  fully instrumented heartbeat. Increase the bounded line or split it under an
  explicit parse contract, add a max-tail regression, and verify the dashboard
  can audit profile without entering maintenance WiFi (Ben/Codex).
- [ ] **Preserve discovered endpoints across an all-or-none OTA discovery
  timeout.** On 2026-08-27, an eight-target campaign discovered five exact
  maintenance endpoints and then correctly stopped before upload when three
  required peers timed out. `discover_batch()` raised before returning its
  local `found` map, leaving `main()`'s finalizer unable to request `/resume`
  from the five already found endpoints. Refactor discovery to return partial
  state with its error (or raise a structured exception carrying it), retain
  the acknowledged FREEZE behavior, add a regression for required-target
  timeout after partial discovery, and prove every known endpoint receives
  final cleanup (Ben/Codex).
  **2026-08-27 full-rollout case:** an allow-partial 49-target job found 18
  endpoints, then one (`F2BD00`) disappeared before the fresh maintenance-power
  preflight. The whole selected cohort correctly received no upload, but the
  other 17 had to be rediscovered in a later job. Under allow-partial semantics,
  demote a vanished found endpoint back to deferred, retain the other exact
  identity-ready endpoints, and continue only after a fresh acknowledged FREEZE.
- [~] **USB-data rescue Bidoof `9F26D8`. USB/A-B WORK COMPLETE 2026-08-27.**
  COM156 exact identity, application-only USB write, preserved NVS, explicit
  persisted field profile, working `Party In The Woods` endpoint, app1
  pending-verify -> valid transition, and stable battery-backed production boot
  all passed on immutable `fx-260826-51d1fe1-p` / SHA-256
  `57306019dbf93a1d0cf950f25b9f557d9a0a68663621a7ce4579aba01dea1261`.
  Final state was field/DAY_ACTIVE, channel 11, ESP-NOW 114/0 sends, healthy
  power/charge and MSA311/TMF8820. Remaining: with the T-Deck physically
  connected, issue one exact `U9F26D8` maintenance command and verify the same
  identity endpoint, then `/resume`; this only excludes a secondary receive
  fault and is no longer needed to repair the missing-WiFi root cause (Ben).
- [ ] **Make application-only immutable fixture USB upload first-class.** The
  retained `fx-260826-51d1fe1-p` directory has the application binary, manifest,
  hash, identity header, recipe, and build options, but not the bootloader and
  partition binaries expected by `arduino-cli upload --build-path`. That generic
  command failed before writing; the ESP32 application-only recipe at the
  telemetry-proven app address succeeded and preserved NVS. Add an identity-
  gated host path that validates target MAC, manifest/hash, current app address,
  and write verification without requiring missing companion files; update the
  USB rescue runbook and add a no-write failure regression (Ben/Codex).
- [x] **Finish the 120 s sleep / 3 s listen production cadence rollout. DONE
  2026-08-27.** Clean
  production artifact `fx-260826-51d1fe1-p` is built from commit `64264b2`,
  1,206,784 bytes, SHA-256
  `57306019dbf93a1d0cf950f25b9f557d9a0a68663621a7ce4579aba01dea1261`.
  Full fixture tests and manifest/build-option checks pass. Stage-1 targets are
  `9F2638`, `9F26BC`, and `F4019C`; stage 1 passed OTA and the end-to-end
  120 s timer-sleep observation. Widening completed 85/98 production fixtures,
  each with fresh exact revision and 25 s pending-verify survival. Thirteen
  prior-revision fixtures were not discovered and not flashed:
  `9F266C,9F26B0,9F2714,F2B7DC,F2BCF4,F2BDD4,F2BF7C,F3FD28,F40174,F401DC,F402A8,F40314,F4042C`.
  Most report PROTECT, whose cadence is 900 s sleep / 8 s grace. Finish in a
  strong-sun window with one complete PROTECT gather plus margin; keep protected
  `F40344`, downlink exception `9F26D8`, and non-production revisions outside
  the target set. See the 2026-08-26 fleet OTA post-mortem (Ben/Codex).
  **2026-08-27 update:** USB recovery completed and pending-verify-proved seven
  of those thirteen (`F2BCF4,F2BDD4,F2BF7C,F3FD28,F401DC,F402A8,F40314`) plus
  thirteen additional old/intermediate fixtures. The final six original
  holdbacks (`9F266C,9F26B0,9F2714,F2B7DC,F40174,F4042C`) were uploaded and
  pending-verify-proved after rotating USB power; Cynder and Meowth required the
  separate 930 s PROTECT pass. Ponyta was then corrected exactly from persisted
  commission to field. Protected Thor and the separate Bidoof downlink exception
  remain intentionally outside that rollout scope. **ADR 0064 reopening:** the
  3 s grace predated the 6 s charge-enable guard and could put a timer-woken
  fixture back to sleep with charging disabled and cached-zero IBAT. Do not
  treat the installed cadence as accepted solar behavior. The replacement
  source enforces a trustworthy approximately 12 s power window with a 15 s
  fail-open; complete the named-canary and immutable fleet promotion above.
  **2026-08-27 replacement rollout:** `fx-260827-1254f04-p` is now reported by
  all 110 intended targets and every one reports FIELD profile. The strict host
  ledger pending-verify-proved 107; retain the item in progress until fresh wakes
  close `F2BCF4`, `F2BEE4`, and `F2B7DC` and the remaining ADR 0064 fault-path
  checks are exercised.
- [~] **Hardware-validate the first-class multi-target OTA state machine.**
  Source implementation is complete under ADR 0062: the T-Deck has a native-
  tested 160-target, 10 ms round-robin job roster plus explicit begin/add/freeze/
  status; the dashboard carries fresh structured campaign evidence; and the host
  now enforces PLAN -> PREFLIGHT -> GATHER -> DISCOVER -> FREEZE -> UPLOAD ->
  VERIFY -> CLEANUP. Timing derives from ordinary versus PROTECT cadence, no
  gather traffic is allowed after acknowledged FREEZE, HTTP failures reconcile
  against endpoint/mesh truth, reachable endpoints receive `/resume`, and one
  exclusive-created ledger records every target transition. See
  `docs/howto/FLEET_OTA_10_MINUTE_RUNBOOK.md`. Exact T-Deck `8EB508` now passes a
  live 130-ID synthetic roster test at `cycle=1300`: 348/348 successful sends,
  zero failures, stable peer census, and no dispatch after freeze. Legacy
  `UF00001` also remained an exact-target `U<ID>` command. **Hardware update
  2026-08-27:** staged real batches updated 20 USB-powered fixtures with exact
  pending-verify proof, including a 2.324 V low-VBAT canary and two-device
  expansion. Failed-closed canary attempts exposed/fixed serial saturation,
  status-request flooding, and a ledger field collision. Remaining: promote a
  clean immutable T-Deck artifact (the validated image is `dev-local`), run the
  explicit injected-interruption case, and time one full fleet pass. The host
  now audits every verified target's runtime profile and optional
  `--fix-commission-profile` performs only exact-target persisted FIELD writes
  with fresh expected-revision confirmation; hardware-validate that path with
  the ADR 0064 canary (Ben/Codex).
  **Full-fleet timing 2026-08-27:** Hawkeye canary passed in 53.844 s. The first
  103-target ordinary job took 589.5 s, essentially the ten-minute target, but
  discovered only 54 and verified 53. All 109 post-canary uploads eventually
  ACKed across six waves; upload windows totaled 310.75 s and individual ACKs
  were 10.43-29.22 s (median 14.41 s), beating the predicted 7-9-minute upload
  component. End-to-end rollout was 45 minutes 9 seconds because sparse WiFi
  association forced repeated gathers, one found endpoint vanished before fresh
  preflight and aborted a cohort, and three sleeping targets exhausted strict
  verification deadlines. Scheduler/FREEZE/cleanup and job ledgers held. Still
  promote an immutable T-Deck artifact and run the explicit injected-interrupt
  regression; fix discovery and verification timing before calling the full
  roughly ten-minute goal hardware-validated.
- [ ] **Expose positive awake/gather evidence.** Add compiled day-sleep,
  wake-listen, PROTECT-sleep, and PROTECT-grace values plus last-accepted-control
  age to fixture/bridge telemetry. Preserve separate evidence ages for short
  heartbeat, full-heartbeat fields, and firmware revision so `fresh` cannot be
  mistaken for `held awake` or make a cached revision appear current
  (Ben/Codex).
- [x] **Make fixture USB sleep parsing fail closed. DONE 2026-08-26:** sleep
  now requires the bounded, newline-terminated `!S<short-mac>:<seconds>` form;
  the target must match, duration must be explicit/canonical in 1..65535, and
  partial, wrong-target, nonprintable, repeated-sentinel, and overlong input is
  non-actionable. Bare `S`, `S1`, and the historical implicit six-hour default
  are removed. The commissioning TMF reset caller now sends the targeted form.
  The native suite passes a 37-check parser regression including 250,000 bytes
  of deterministic junk, and exact Akuma `9E668C` hardware ignored legacy/ROM-
  style `S` input with no new sleep audit, then accepted only
  `!S9E668C:10`, woke by timer with a retained 10-second serial cause, and
  returned to DAY_ACTIVE. The field dev binary is 1,205,856 bytes, SHA-256
  `54A3118B10BB9A9FD58815429AC4470599B71EE621DF9B73AE717A001A354AB8`.
  ModemManager exclusion remains useful defense in depth (Ben/Codex).
- [x] **Make same-revision OTA verification fail closed. DONE 2026-08-26:**
  `field_cycle_ota.py` now snapshots pre-job uptime/sequence, treats
  `dev-local` and an unchanged expected revision as mutable identities, and
  requires a post-job reset transition, a fresh expected-revision heartbeat,
  and 25 seconds of pending-verify survival. Five host tests cover unique,
  cached, reset, missing-baseline, stale, and wrong-revision evidence. A second
  Akuma same-name OTA then failed closed when the dashboard only reprinted its
  pre-reboot record; direct USB independently proved the OTA valid. Keep ADR
  0040 unique revisions for shared artifacts (Ben/Codex).
- [~] **Measure Akuma's 120 s sleep / 3 s listen canary cadence before fleet
  promotion.** Production defaults remain 300 s/15 s. Build controls now make
  both values explicit and range-checked, the recipe fingerprint includes
  them, and USB telemetry reports the compiled values. Exact Akuma `9E668C`
  runs the 1,205,920-byte `dev-local` canary, SHA-256
  `7fca2ae63b3c840c31400d269f382cf0222a66e2e5bc0d839a9b8e7297d3283c`;
  direct USB proves software reset, valid `app0`, pending verify cleared,
  `day_sleep_s=120`, and `wake_listen_ms=3000`. With USB removed and the panel
  made opaque, three clean sustained addressed-maintenance trials caught true
  timer wakes in 86.4, 100.9, and 94.3 seconds (3/3). Each endpoint reported
  `reset_reason=deepsleep`, retained `last_sleep_reason=day-charge` / 120 s,
  and maintenance uptime 3.746-4.380 s; command receipt necessarily occurred
  inside the 3 s comms window before WiFi startup. Final `/resume` returned
  Akuma to natural cadence. No INA instrumentation is available at Burning Man,
  so use the explicit theory gate instead of leaving an impossible field test:
  model fixed wake/setup energy as `b` steady-awake-equivalent seconds. Comparing
  complete 120/3 and 300/15 cycles breaks even at `b=5 s`; 120/3 saves energy
  below that and costs energy above it. Akuma emitted a post-deep-sleep heartbeat
  at about 1.1 s uptime, and even a 2-3x boot-current multiplier remains below
  the 5 s boundary. Treat 120/3 as likely lower radio-awake energy as well as
  faster maintenance access; remaining gate is a staged fleet rollout and live
  census/catch observation, not unavailable current instrumentation (Ben/Codex).
- [ ] **Resolve the same-revision Akuma bridge/direct evidence disagreement.**
  During OTA, direct USB proved a new software-reset boot while the T-Deck
  dashboard still presented pre-reset uptime/sequence as recent enough to
  inspect. Later interleaved maintenance, deep-sleep, and software-boot records
  were difficult to order. `nb-peer` already includes the T-Deck's calculated
  radio age, so do not assume the missing fix is merely another age field.
  Reproduce on an isolated canary with timestamped raw T-Deck serial, direct
  USB, and HTTP telemetry; determine whether emission ordering, serial backlog,
  or census restart accounting is responsible. Until then, the OTA verifier
  must continue to fail closed and require direct or unique-revision evidence
  when reset identity is ambiguous (Ben/Codex).
- [ ] **Make laptop/T-Deck identify semantics visibly consistent.** The Fleet
  UI calls `meshIdentify(..., green, blink, 128)` and lights the production
  LEDs, but serial quick command `i<ID>:<secs>` uses legacy color 0 and only the
  enclosed PowerFeather status LED. The field manual currently describes the
  serial example as green. Add an explicit safe production-light syntax or
  align the default, cover it natively, and document status-only versus fixture
  output so a closed enclosure can actually be identified (Ben/Codex).
- [~] **Hardware-validate CoreS3 wireless two-app Bridge OS (ADR 0054).** The
  ordinary image now boots to a touch launcher with read-only Listener and
  Audio apps; USB remains optional, Module Audio is a hardware build variant,
  and exiting Audio stops its direct-frame publisher. The Module build now has
  a runtime Ambient/Aux Input selector with a zero-frame handoff and delayed-
  module retry (ADR 0057). Native tests pass 42 checks and the exact CoreS3
  `4D5DB0` (`80:45:6B:4D:5D:B0`) now runs the inspected
  `cores3-os-0.1.2-dev` Module Audio artifact: 1,168,352 bytes, SHA-256
  `FDDAC35CA9778D1698763F77FAABA88A5FBB56A8167C1D24EE6E0701F1742C65`.
  USB flash/hash verification, current boot identity, channel-11 passive mesh
  receive, Aux readiness, USB `nb-*` queries, paused/no-frame startup, and zero
  queue drops passed. The common Input action completed Aux -> Ambient -> Aux
  on hardware while paused with zero direct frames/read failures. The first
  standalone test exposed two blockers now fixed by ADR 0058: Audio Start
  automatically releases an explicit CA/Contagion/Dark lease in RAM, and the
  target selector recognizes current ADR 0040 `fx-*` firmware identities. The
  exact app-region readback matched the artifact SHA. A live Ambient run selected
  Builtin Dual Mic, calibrated, published four fleet chunks per tick with zero
  failures, and an independent T-Deck observed fresh fixtures enter program 3
  Direct instead of CA. Remaining:
  physically verify all three touch targets, battery-only operation,
  more-than-24-peer Listener paging, named-fixture health/detail parity with the
  host dashboard, fresh built-in-only/Cambium compile smoke checks, all four
  RODE looks, active-stream Input handoff, pause/start, app-exit zero frame,
  mixed HEX/RGBW stale fallback, and unplugged Listener/publishing runtime. Use
  explicit canaries; do not start Audio while T-Deck LED Studio/Patterns or
  another publisher owns the look. Ben confirmed the standalone `AMBIENT MIC`
  speech response works really well across the awake cohort. Pause/leave Audio
  and observe the roughly three-second fallback; active source handoff and a full
  300-second sleeper-cadence run remain open (Ben/Codex).
- [~] **Hardware-validate CoreS3 spectral Audio (ADR 0061).** Source and native
  tone tests cover the 512-sample FFT, bass/mid/high separation, centroid order,
  stereo-to-mono Aux handling, and BANDS RGB/BANDS SPLIT color planning. Exact
  CoreS3 `4D5DB0` now passes firmware cadence: Ambient held 24.802 Hz analysis,
  24.799 Hz display, and 9.999 Hz fleet TX for 65 seconds with no read, send, or
  RX queue failures; Aux held 24.020/24.006/10.000 Hz for 70 seconds but had one
  send failure. Remaining: verify the scrolling plot has no false high-frequency
  rail, exercise touch/UI through a 30-minute zero-failure soak, and use an
  explicitly owned awake cohort for bass-, mid-, and treble-dominant material in
  BANDS RGB, BANDS SPLIT, and TIMBRE HUE. Finish with app-exit/autonomous-fallback
  observations and confirm again that no fixture NVS or OTA changed (Ben/Codex).
- [~] **Execute the low-latency audio-reactivity development plan.** Sound-to-
  photon latency and cross-fixture skew are now first-class artistic gates; the
  staged plan is
  `docs/projects/LOW_LATENCY_AUDIO_REACTIVITY_DEV_PLAN.md`. Milestone A source is
  implemented on CoreS3: independent phase-locked 25 Hz analysis, 10 Hz publish,
  and 25 Hz display deadlines remove the permanent 120 ms / 8.3 Hz quantization;
  achieved-rate, interval, skip, lateness, and maximum blocking telemetry expose
  real cadence; calibration now spans two seconds of contiguous successful
  captures; and input older than 200 ms stops publishing plus sends one black
  frame instead of replaying stale brightness. The native CoreS3 suite passes
  167 checks. Exact CoreS3 `4D5DB0` is running the fresh exclusive Module Audio/
  channel-11 `r6` build: 1,189,072 bytes, SHA-256
  `4AB7DB1D7F09526CD82A6E6FE7B22C5455F5DAA951C3956AED8ABB10A6F2E6C2`.
  Both Ambient and Aux pass the 60-second analysis/display/publish rate gates;
  the zero-failure 30-minute soak and physical Aux photodiode/scope plus Ambient
  video median/p95/max and cohort-skew measurements remain open. Milestone B
  adds 8 ms transient blocks
  beside the rolling 512-sample FFT and measures the safe legacy direct-frame
  rate. Only measured failure of the current fixture ceiling advances to the
  proposed type-31 compact feature packet, local 50 Hz audio render, USB
  HEX/RGBW canaries, and a separately authorized gated OTA. This work does not
  authorize any fixture flash or OTA (Ben/Codex).
- [~] **Hardware-validate DG1022Z -> PUCA HEARTBEAT mode.** The standalone
  hardware/radio baseline passes on the exact PUCA with `0.4.1-dev`:
  HEARTBEAT + line input + LOCKED boot, powered paw/knob inputs, codec/stereo
  capture, 70+ eligible fixture census, and 8,318 successful send callbacks
  over 207 s with all reported error/clipping counters zero. The current 103
  native checks pass; installed `0.4.1-dev` binary is 964,752 bytes with SHA-256
  `e8ec74680564f96f10c2f6e87b37eb807b9d9ba3b355ccf41c72f8301c4984b6`.
  ADR 0063 `0.5.0-dev` was credentialed and installed. The 2026-08-27 bench
  pass proved no-hold SAFE-IDLE with zero direct frames, `A4EB10` Bridge OS
  identity, exact-target shared-WiFi maintenance, retained-binary OTA, dark
  software-reset rejoin, and 25 s pending-verify survival. The 2026-08-28
  `0.5.2-dev` bench pass exercised DJ/HEARTBEAT/EMBER/HUE from the onboard MEMS
  path across about 75-92 fresh fixtures with zero reported transport/I2S/
  I2C errors, and replaced frame-count calibration with a hardware-proven two-
  second clock; Ben visibly confirmed audio-reactive fixture behavior. The
  Initial laptop testing remained at the line noise floor because the TS plugs
  were mistakenly in J8/J9 AUDIO OUT. Exact JSAUX
  `B07D8M5DML` plus two Bolvek `B09K3DHL82` adapters are the correct TRS-stereo
  -> dual-RCA -> dual-TS-mono topology. After moving them to J5/J6 AUDIO IN, the
  same 10 percent laptop waveform raised RMS from 6-12 to 37-41 with level about
  0.13-0.15 and zero clip/error counters, proving cable, faceplate line routing,
  codec/I2S, renderer, and fleet transport. A later 60 percent laptop paired-
  pulse run reached `wave=0.222` and peak 2,063 with zero errors/clips across
  about 84-93 fresh fixtures; Ben visibly accepted the deep-red HEARTBEAT look
  while sweeping the top knob through 0.26x-4.00x. That pass exposed the
  carrier's reversed raw-ADC polarity. Exact-target OTA-installed `0.5.3-dev`
  now normalizes both pots so clockwise increases top sensitivity and bottom
  brightness/hue; 121 native checks, fresh embedded build, and expected-revision
  rejoin pass. A full power cycle and physical full-clockwise test then read
  exactly `gain=4.00`, `ceil=1.00`, and HUE endpoint 360. Still test real RODE
  gain/clipping.
  The paw fault is closed in `0.5.5-dev`: the vendor example's GPIO15 digital
  read stayed low, while raw ESP32 capacitance proved released 867-870 and held
  through 216. Hysteretic, invalid-low-fail-safe capacitance handling passed 129
  native checks, exact-target OTA/rejoin, and a real held-paw Pod20 power cycle
  with `bootarmed=1`, `active=1`, DJ + line, and zero errors. Still prove timed
  post-arm short-touch mode cycling and long-hold lock, `/resume`, maintenance timeout,
  fleet-wide-maintenance rejection without disturbing the live fleet, no PUCA
  softAP, and forced-self-test rollback.
  On the no-human bench, prove `peak`/`wave`/deep-red output from the performer's
  exact arbitrary waveform with zero clip blocks. Compare the analog waveform
  to one fixture by photodiode/scope and record whether the 100 ms peak window
  and current 10 Hz fixture latch preserve the intended single/double pulse.
  Do not T-split or otherwise electrically join PUCA to the body-connected
  ceremony chain until its owner documents the complete circuit and a qualified
  reviewer approves a separately isolated monitor boundary with all field power
  and USB connections present. The rear Sync output is timing-only, not a copy
  of the arbitrary waveform; direct connection to the AC-coupled audio input
  may detect both square-wave edges. **2026-08-31 partial hardware result:** the
  no-human DG1022Z path visibly drives HEARTBEAT, but Ben reports very dim output
  even at 4 Vpp with both PUCA carrier controls fully clockwise. Before changing
  the 4 Vpp boundary, compare a High-Z/0 V/4 Vpp 1 kHz sine and record service-
  USB `peak`, `wave`, `gain`, `ceil`, and `clipblocks`; if the sine is also dim,
  retune the faceplate/codec-to-HEARTBEAT scaling rather than adding unmeasured
  source voltage (Ben/Codex).
- [ ] **Physically confirm the inferred full MACs for the three restored fleet
  identities.** The retained 2026-08-18 OTA/RSSI evidence proves short IDs
  `F2BDFC`, `F402A4`, and `F40348`; their `68:EE:8F` OUIs were reconstructed
  from the surrounding PowerFeather batch so the canonical registry and
  generated Health roster can remain internally consistent. Confirm each full
  MAC from a live identity surface or device label before treating that prefix
  as hardware evidence. Short-ID mesh targeting and the bridge-side Magmar,
  Magneto, and Marill callsigns do not depend on this check (Ben/Codex).
- [ ] **Capture real Bridge OS/CoreS3/PUCA manual photographs.** The new
  `docs/howto/BRIDGE_OS_FIELD_MANUAL.md` includes diffable source-derived role
  and launcher visuals. Add clean field photos of the launcher, Health, Fleet
  detail, LED Studio, Sleep confirmation, Schedule, both RF pages, CoreS3
  normal/audio screens, and labeled PUCA ribbon/front-panel audio connections
  as those states are deliberately staged. Do not send a control merely to make
  a documentation photo; use the named-canary acceptance passes already queued
  below (Ben/Codex).
- [ ] **Support spaced WiFi credentials in T-Deck serial provisioning.** The
  current `set wifi <ssid> <psk>` tokenizer requires both values to be one token
  and cannot safely enter the exact production maintenance SSID
  `Party In The Woods`. Add quoted/escaped fields or another bounded secret
  provisioning path, native-test it, and keep `show` from exposing more of the
  API key than operators need. Until then, use only an approved one-token
  bridge SSID; do not pretend quoting works (Ben/Codex).
- [~] **Hardware-validate fixture callsigns on the T-Deck.** The canonical table,
  17 host policy/dashboard tests, the complete native Bridge suite, and the
  final Magic-Wand-aware embedded build pass. The reconciled 141-fixture image
  is 1,550,224 bytes with SHA-256
  `3026593615bd58304c2a6b8893bf4f92cd8f9f92211f9222a5a28517fedf6e32`.
  The current combined image now flashed on exact `8EB508` carries all 144
  identities, including `Magmar [F2BDFC]`, `Magneto [F402A4]`, and
  `Marill [F40348]`.
  It is USB-flashed to exact T-Deck `8EB508`; upload verification, hardware
  probes, channel 11 rejoin, zero-failure mesh transmission, and fresh receive
  from all seven newly registered IDs passed. Check
  Fleet rows/details, Health selection/details, and Claude lookup/identify on one
  explicitly named canary. Confirm every action surface shows both callsign and
  short MAC, compact grids remain readable, unknown peers fall back to MAC, and
  the wire target is unchanged. Do not send a fixture command without naming and
  accounting for the exact canary first (Ben/Codex).
- [~] **Hardware-validate Bridge OS Patterns v1 on named canaries.** The pure
  deterministic model passes 190 checks and the combined embedded image builds.
  The combined image is USB-flashed on exact T-Deck `8EB508`: 1,542,448 bytes,
  SHA-256 `705119167e51ae8dff399a6c46cfd442b1610d14d0acb5d8a470c63461242b46`.
  On one awake HEX plus one point-source fixture, exercise Wash, Chase, Wave,
  and Twinkle; all five palettes; speed/intensity edges; class and stable cohort
  filters; explicit Stop; three-second stale fallback; and owner replacement in
  both directions with LED Studio. This is live direct-frame artistic control,
  so name and account for the canaries before starting a pattern (Ben/Codex).
- [ ] **Hardware-validate Bridge OS commission defaults on named canaries.**
  Source and both native/embedded builds pass for the exact-target Default app
  and fixture type-30 receiver; the current combined image is flashed on exact
  T-Deck `8EB508`. On one downlight, perimeter, and RGB uplight,
  exercise ready beacon, light-only wildfire CA, and strict rails-off dark;
  active-lease override and release/expiry; until-reboot reset; one persisted
  CA reboot followed by a persisted restore to listener; field-profile
  non-interference; and a small `ALL: targeted fresh` cohort with no non-target
  mutation. Declare the T-Deck as the sole NVS writer and name every short MAC
  before the persistent pass (ADR 0052; Ben/Codex).
- [ ] **Hardware-recheck LED Studio semantic white on mixed hardware.** On one
  named RGB uplight and RGBW downlight, confirm white produces full `R=G=B` /
  `W=0` on the RGB-class target and dedicated `W` on the downlight, including
  dim, blink, all-class planning, Stop, and three-second fallback. Add a named
  RGB chandelier canary when deployed (Ben/Codex).
- [~] **Hardware-validate the read-only T-Deck RF Diagnostics app.** Check the
  summary and frame-tail pages, touch/trackball navigation, live/seen/stale and
  roster-unobserved counts, foreign-live labelling, strongest/weakest ordering,
  unavailable/partial observation labels, RX/TX counters, and WiFi/AP/channel
  guard state. The app must send no mesh command and alter no fixture state
  during validation. It is flashed in the combined `8EB508` image identified
  above (Ben/Codex).
- [~] **Hardware-validate the T-Deck Health app.** Source, native tests, and the
  merged image now flashed to T-Deck `8EB508` cover the 134-entry production registry,
  stable no-scroll tile ordering,
  fresh/off-air merge, unexpected live IDs, and exact raw-VBAT bands: green
  >3.20 V, yellow >3.10 V, red <=3.10 V. On T-Deck `8EB508`, verify all tiles
  fit at once, red/yellow/green/grey/blue rendering, touch and trackball detail
  entry, a known off-air fixture, a known low canary, and heap/PSRAM watermarks
  after repeated open/detail/back cycles. This app is read-only; do not send a
  fleet command during validation. Health remains present in the combined
  1,542,448-byte image identified above. Ben reports the first physical
  Health/Schedule smoke check looks good on 2026-08-24; retain the explicit
  color/off-air and memory matrix before closing this item (Ben/Codex).
- [~] **Field-validate the T-Deck LED Studio / Sleep app on explicit canaries.**
  T-Deck `8EB508` on `COM152` now runs `tdeck-dev-local` and passed exact flash
  verification, clean boot, peripherals, memory, correct machine identity, and
  live fleet receive. Ben exercised LED Studio, Sleep / Dark, Knocker, and CA
  Studio on the night of 2026-08-23/24 and reports that all behaved as designed.
  This is a broad functional field pass, not yet the full canary matrix. Retained
  `field2` source fixes `field1`'s stale telemetry-only version label. Name one
  HEX plus one point-source fixture, then verify RGB, class filtering, 1 Hz
  blink, stop fallback, 10-minute dark expiry, and a short rails-off timer
  sleep/rejoin. Before any overnight fleet sleep, compare live/seen counts and
  account for radio-silent fixtures separately (Ben).
- [~] **Hardware-validate durable bridge-action and fixture-sleep provenance
  (ADR 0059).** Source now keeps four checksummed T-Deck actions in NVS before
  RF; fixtures keep the immediate timer-sleep cause in RTC memory, persist rare
  operator-sleep receipts plus first PROTECT entry, and refuse an operator sleep
  whose audit cannot persist. The 192-byte heartbeat tail, T-Deck emitter, host
  dashboard/logger, USB JSON, native suites, parser tests, and both embedded
  development builds pass. Fixture-side hardware now has a partial pass on
  exact Akuma: addressed serial sleep woke by timer with retained
  `last_sleep_reason=serial` and the exact duration, and the later cadence
  canary produced three more true timer wakes retaining
  `last_sleep_reason=day-charge`, `last_sleep_s=120`, battery voltage, profile,
  lifecycle state, and tier. The older durable operator receipt remained
  intact alongside the immediate RTC record. The 99-fixture Color Virus fleet artifact predates
  ADR 0059, and the provenance-capable T-Deck development image was compiled
  but not flashed. On an isolated radio cohort, validate Dark,
  Release, Schedule, and a short Sleep; exact source/sequence correlation;
  T-Deck reboot survival; fixture timer-wake and later power-cycle survival;
  automatic day/PROTECT RTC evidence; one-write-per-PROTECT behavior; and both
  fail-closed storage paths. Do not perform the Sleep pass against an
  unaccounted live fleet (Ben/Codex).
- [~] **Hardware-validate the conditional solar-probe wake (ADR 0060).** Source
  now preserves the 300 s/15 s field cadence until a FULL-tier fixture measures
  at least 150 mA good input, then holds only that wake for a continuous
  60-second proof before entering `DAY_ACTIVE`. Battery voltage alone no longer
  counts as surplus; active hysteresis is 100 mA for 300 seconds, while strikes
  still require 150 mA and every existing gate. The full native suite and a
  field-profile ESP32 development compile pass. Exact Akuma `9E668C` proved the
  positive hardware path: about 4.64 V external input held the wake through the
  60-second confirmation into `DAY_ACTIVE` and remained continuously reachable.
  The Akuma cadence canary also proved the below-100 mA exit side: an upside-down
  panel on reflective playa still delivered about 538 mA, while opaque backing
  reduced it through 42 mA to 0; after hysteresis it returned to DAY_CHARGE and
  repeatedly timer-slept. Still prove the production 15-second weak-input path,
  transient cancellation, the 100-149 mA
  awake-but-no-strike band, below-100 mA fallback, commission no-sleep, and
  unchanged PROTECT timing. Measure cloudy threshold behavior before creating
  an immutable fleet artifact (Ben/Codex).
- [~] **Hardware-validate the revised Knocker fleet modes.** Field use exposed that
  the old `knock all` selected at most 32 fresh fixtures in heartbeat order and
  paced targeted sends every 300 ms. Current source plans the complete
  192-entry census in deterministic short-ID order, dispatches every 80 ms, and
  labels that action as a targeted roll. It now also offers immediate fleet
  multicast and a shared +1.0 s multicast deadline through the existing
  `NbEvent.fire_in_ms` field. Fixtures deduplicate the event, timestamp radio
  receipt, arm only one pending strike, and drop it if more than 250 ms late.
  ADR 0065 now makes deliberate Knocker traffic a best-effort mechanism attempt:
  it bypasses lifecycle/solar/tier qualification while retaining arm, rest,
  maintenance, pulse, load-marker, deadline, and failsafe gates. Native
  coverage and both embedded development builds pass. Before flashing the new
  T-Deck UI, deploy the matching fixture image only to an isolated, explicitly
  armed cohort.
  Confirm one strike per event despite six RF copies, old-firmware ignore,
  immediate multicast spread, +1.0 s deadline skew, hard-gate refusal, and no
  late fire after a blocked loop/maintenance interval. Do not exercise either
  multicast mode around an unaccounted strike-permitted fleet. **Compatibility
  observation 2026-08-25:** targeted roll still strikes the deployed pre-event
  fixture image while both new multicast choices are silent, exactly matching
  the documented old-firmware ignore path; this is not evidence that the new
  receiver failed. The isolated matching-image canary remains required
  (Ben + Codex). **2026-08-27 field diagnosis:** a reported 92-live roll was
  audibly sparse. A later read-only snapshot had 83 peers under the five-second
  fresh threshold but only four with affirmative FIELD + DAY_ACTIVE + FULL +
  >=150 mA input evidence; 18 known rows were DAY_CHARGE and 60 fresh serial
  rows lacked usable full-state tails. Ben rejected using those advisory fields
  as an operator-knock filter: an empty capacitor simply produces weak/no
  motion. Current source therefore continues to roll every fresh ID and removes
  the receiver energy refusal for targeted/multicast operator traffic. It still
  takes about 7.36 s for 92 targets, so compare targeted roll with broadcast-now
  and sync-+1.0 s on the matching-image cohort. Hardware-prove deliberate
  DAY_CHARGE/night/non-FULL attempts plus every retained hard gate before fleet
  promotion (Ben + Codex).
- [x] **Seed and validate the locked T-Deck development cache -- DONE
  2026-08-24.** The fixture cache's lock, recipe fingerprint, interruption
  marker, quarantine recovery, `tdeck-dev-local` identity, and fresh-artifact
  boundary are ported. Compile-free wrapper checks, native tests, interrupted
  recovery, cold seed, identical-SHA warm reuse, exact USB flash, and clean
  boot/mesh verification passed on `8EB508`. The heavy-load cold seed took
  about 55 minutes and the first warm no-op about 76 seconds; later timing was
  variable. The old interrupted `tdeck-ledsleep-20260824-field2` directory was
  not reused (Ben + Codex).

- [ ] **Recover the exact `fx-260819-7afe0a6-b` bench artifact from a deployed
  prototype if needed.** A mistaken ignored-build cleanup removed the last found
  filesystem copy. Do not rebuild or reuse the revision. Read exactly the
  1,170,736 app bytes from `9E5AF0` or `9E5AB8` only when one is explicitly on
  USB, then accept the recovery only if SHA-256 equals
  `95e8d74727089c9bc309ae66109c2f26c1cb7cb7888d84c8fe90158f8bc9fcbc`
  (Ben + Codex).
- [ ] **Finish optional fixture build job-count/hardware follow-ups.** During one
  stable awake session, repeat controlled cold `--jobs 1/4/0` trials; the Aug
  22-24 suspended/aborted trials are invalid. If useful, flash `dev-local` to one
  explicitly named sacrificial USB fixture and verify fresh telemetry. Cache
  reuse itself is already host-adopted and does not depend on this tuning (Ben +
  Codex).
- [~] **Hardware-validate the Magic Wand Conductor (ADR 0079).** The October 6
  final-high-hold shock fix has native regression coverage; earlier embedded
  builds predate it, so build a new identified artifact before the canary. The installed
  `.1` image remains the known-good fallback. Dedicated source now checks exact
  MAC `F40344` / `68:EE:8F:F4:03:44`, requires a still-lift-high-hold gesture
  corroborated by MSA311 and BMP581, reuses the Atom's bounded Wake/gather and
  neighbor graph, shows per-Hex spiral progress, gates chime versus color at
  civil dusk, and cycles all-740-pixel R/G/B/dim-RGB local feedback. Native
  gesture/visual tests, the complete fixture-core suite, and the dedicated
  channel-11 PowerFeather build pass. The existing LED switch cannot be read
  through PowerFeather current because the Pololu branch bypasses its gauge.
  Remaining: capture realistic handling traces and tune false-positive/miss
  thresholds; verify the twenty spiral orientations and fill power; USB-canary
  one named canopy through trusted/missing time, chime, four colors, cleanup,
  and power-loss recovery. Before replacing `.1`, retain a dedicated immutable
  artifact, use the installed LFP for ride-through, and complete fresh-revision
  pending-verify acceptance. Any OTA must remain sole-target with ADR 0050's
  explicit special-target acknowledgement. Keep fleet-control use under Ben's
  or Steve's supervision until portable-controller authentication, labeling,
  and revocation gates close (Ben + Steve).
- [x] **Capture the Nevada City rig RSSI matrix before pack-out -- DONE
  2026-08-17.** Bridge `4D5DB0` and 84 qualified fixtures received the immutable
  transport/RSSI image. The 140-second `L` survey preserved 25,154 observations
  from 48 reporters hearing 96 transmitters, with 4,558 unique directed pairs,
  in `ops/locate/data/field/20260818-0300-nevada-city-rig-rssi.jsonl`
  (Ben/Codex).
- [x] **Arm a multi-day transport sleep without creating a lid-open wake task --
  DONE 2026-08-17.** All 84 exact-revision fixtures accepted `Q99` at about
  20:11 PDT and disappeared from fresh telemetry. Timer wake is expected about
  23:11 PDT Friday; RESET wake was field-confirmed without flashing. Ten
  then-reachable old fixtures received only the `S65535` 18.2-hour fallback.
  After unload, bridge `b` clears the retained LED-dark latch (Ben/Codex + field
  team).
- [ ] **Recover a planar/grid embedding from the Nevada City RSSI matrix.** Start
  with the raw 48-reporter/96-transmitter directed capture, symmetrize with
  explicit missing-edge handling, compare rank-only and calibrated-RSSI distance
  models, and score the result against only the known 6x12, 2x12, and 1x8 rig
  shapes. The captured rows are one-sample neighbor-table EWMAs, not independent
  window medians, so uncertainty and censoring must remain explicit (Ben/Codex).
- [ ] **Close the awake test cohort before final pack-out.** Elliot may use
  `9E5954`, `9F0E30`, `9F0E5C`, `9F26E4`, `F40174`, and `9F2720` while Ben is in
  Oakland. All six had qualified USB input when left. On Ben's Thursday/Friday
  return, verify power, then transport-sleep this awake subset for the remaining
  transit interval. Do not disturb the 84-device long-sleep cohort whose Friday
  night timer already aligns with unload (Ben + Elliot).
- [ ] **Reconcile `9F2720` battery capacity.** USB commissioning proved healthy
  canopy/downlight sensors and current firmware, but the persisted/registry
  capacity is still 6,000 mAh. Physically identify the installed cell before
  changing it to the 15,000 mAh large-enclosure setting (Ben).

- [x] **Promote the 2026-08-17 small-fixes fixture candidate -- DONE
  2026-08-17.** Built immutable `fx-260818-05ed4b3-b` once from clean commit
  `e09f46f`; binary SHA-256 is
  `2986a0294827ef6be970d2ffe50066c885f3107f139f8601d5054d797467e1db`.
  Battery-backed canary `F40174`, the 56-target main wave, and the three-target
  safe tail all returned fresh exact-revision heartbeats and survived the
  20-second pending-verify gate: 60/60 attempted and verified. All 60 later
  reported LED rail off and zero lit pixels under the dark lease. No low-voltage,
  recovery, downlink-anomalous, or slot-anomalous fixture was flashed; bridge
  `4D5DB0` was untouched (Ben/Codex).
- [x] **Complete small-rig perimeter QC and battery replacement -- DONE
  2026-08-26.** Ben confirmed that all 24 perimeter fixtures were QC'd: every
  installed cell below 3.10 V was removed and replaced with a factory-fresh cell
  individually verified above 3.20 V. None of the installed perimeters should
  now be batteryless. Treat older registry and TODO batteryless annotations as
  stale until the physical map is reconciled (Ben + field team).
- [ ] **Diagnose the post-QC perimeter energy collapse.** On the evening of
  2026-08-26 only 2 of 24 perimeters responded visibly to a healthy LED Studio
  stream, versus roughly 8-12 dark canopy and 2 dark installed trunk fixtures.
  The two live perimeters were already near the LEDs-off/protect thresholds,
  and several silent known perimeters had prior PROTECT evidence. Treat
  persisted commission profile plus old charge recovery as the leading
  firmware-mediated hypothesis: replaced perimeter `F403DC` fell from its
  QC-qualified >3.20 V cell to 2.755 V while retaining commission profile, and
  exact USB perimeter `F4035C` is commission on `fx-260816-prtrel1-b` at
  2.324 V with good USB but charging disabled. Commission's measured dark-awake
  126-144 mA floor is 3.0-3.5 Ah/day before the listener pixel and ToF, while
  the old image refuses a real cell below 2.5 V. Sample several more exact dark
  perimeter slots for firmware revision, persisted profile, battery voltage,
  supply, charging state/current, and recovery state before applying a cohort
  fix. A default-field OTA does not overwrite persisted profile. Any rescue
  must use declared exact targets, the current guarded recovery artifact,
  positive charge-current/voltage-rise evidence, and deliberate persisted field
  promotion. In the next strong-sun window, keep artistic LED streams stopped;
  collect fresh supply voltage/current and battery current for named perimeter
  slots; then inspect
  P126 orientation, shading/dust, polarity, connectors, and the charger input
  path. Separate insufficient 2 W / 6 Ah energy budget from a shared harvest or
  charge-path fault before another nighttime load test. Include a controlled
  named-perimeter VL53L5CX A/B with identical radio and LED state: read back
  ranging mode and integration time, average battery current while ranging,
  then stop ranging or cut VSQT and repeat. Firmware currently relies on the
  driver's default autonomous mode rather than verifying it; ST's 3.3 V figures
  differ sharply between autonomous 4x4 / 5 Hz / 5 ms (about 19 mW) and
  continuous mode (about 313 mW). **2026-08-28 canopy cross-check:** exact
  outer-ring downlight Ponyta `F2B7DC` was dark in durable PROTECT. Its retained
  entry audit records 3.236 V and persisted commission profile; later correction
  to field did not clear the latch. Good USB produced about +192 to +260 mA with
  no BQ fault, completed the 60-second guarded release, and clean-rebooted into
  LEDS_OFF with healthy MSA311/TMF8820/BMP581. This supports the same
  commission-energy/protection chain outside the perimeter cohort but does not
  close the P126 harvest question. Ben confirmed every canopy/downlight without
  exception has a 15 Ah cell, so correct Ponyta's live persisted 6,000 mAh
  capacity to 15,000 mAh through the declared exact-target configuration path
  before relying on its gauge SOC/capacity telemetry (Ben + field team).
- [ ] **Turn the physical census into a slot-to-MAC dark-matter map.** Current
  visual inventory is 74 canopy, 8 installed trunk, and 24 perimeter; all 24
  perimeters should now contain QC'd cells. Roughly 20 additional trunk lights
  are boxed and batteryless. Give every rig slot a durable label, use addressed
  identify to record its short MAC, and explicitly record empty, batteryless,
  bootloader, and silent slots. Reconcile the expected 106 powered
  fixtures against dashboard identities instead of inferring missing units from
  aggregate counts (Ben + Elliot/field team).

- [~] **Choose the daytime recovery posture after the dark-awake baseline.**
  `B3600` proved that removing the LED load swings the updated awake fleet from
  aggregate discharge to aggregate charge, but battery-only fixtures still draw
  roughly 126-144 mA because ESP-NOW RX stays awake. Decide whether diagnostic
  reachability justifies that floor or whether to use the existing field-profile
  300 s sleep / 15 s listen duty cycle for solar recovery. ADR 0049 keeps
  300/15 as the production default and fixes the RX hold so peer heartbeat,
  choreography, and time traffic cannot defeat it; only accepted operator
  controls hold a fixture awake for ten minutes. A selectable 60 s sleep / 8 s
  listen build-week posture remains open, as do external-INA averages including
  boot overhead for both cadences. Do not call `F1` an isolated 0.2 Hz test: it
  also changes lifecycle and sleep behavior (Ben/Codex).
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

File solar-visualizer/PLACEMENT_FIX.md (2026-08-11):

# Canopy placement fix for the phase-2 solar study

From Ben + Claude (lighting workstream), 2026-07-17. For Elliot / blender-architect.

## What we found

The 78-light canopy set in `solar_phase2_data.json` inherits three artifacts
from the raw lantern export (`fixtures.json` 0.3.1, "PROCEDURAL first-pass"):

1. **6 trunk strays** -- CL-I11, CL-I12, CL-I14, CL-I16, CL-I17, CL-I18 sit
   within 12 cm of the trunk axis at z 0.05-0.94 m (the vertical stack of
   panels on the ground inside the tree). These are export glitches, not
   lantern positions.
2. **6 stacked duplicates** -- CL-O04/O05, CL-I04/I05, CL-I08/I09,
   CL-O12/O13/O14, CL-I17/I18, CL-I19/I20 are pairs (one triple) at literally
   identical coordinates: 78 lights but only 72 distinct positions.
3. **6 ring holes** -- the rings should be 24/24/24 but come out 20/22/24
   distinct (4 inner + 2 middle slots missing; visible as gaps).

We hit the identical artifacts in the auto-localization study on `main`
(`docs/tests/AUTOLOCATE_RSSI_SIM_FEASIBILITY_2026-07-12.md`) and patched them
there: the 6 strays move into the 6 ring holes (slot positions inferred from
each ring's angular gaps), duplicates stay flagged.

## The fix input

`canopy_positions_corrected.json` (this directory): the corrected canopy as
**72 distinct attach positions** (24/24/24, radii ~2.60 / 4.12 / 4.97 m), in
your convention -- meters, tree-centered, Z-up, at your calibrated 0.0985
m/unit scale. Six entries are marked `moved_from_trunk_stray` (these need
fresh raytracing -- their old sun-access data described the trunk floor);
six are marked `duplicate_of` (drop or ignore -- their data double-counts
their twin).

Everything else (the 16 ground/trunk lights, the power chain, the viewer) is
untouched and great. Those TB-01..12 + RT-* spots subsequently became the basis
for the current about-16 trunk-light class in ADR 0032.

## Ask

Re-run the `src/` raytracer with the corrected canopy placement (only the 12
affected positions strictly need new rays: 6 moved + 6 hole-fills are the
same thing here; the other 60 are unchanged) and regenerate
`solar_phase2_data.json`. Happy to adapt naming/format if the Ruby side wants
it different -- ping Ben on WhatsApp.

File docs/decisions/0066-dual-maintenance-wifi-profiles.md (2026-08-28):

# 0066 -- Two maintenance WiFi profiles for site portability

**Date:** 2026-08-27

**Status:** Accepted and fleet-promoted; selection logic compile-tested, second
site hardware association pending

**Owner:** Ben

**Extends:** ADR 0010, ADR 0036, ADR 0040

## Context

The physical fleet is splitting earlier than planned. Perimeter fixtures are
moving to the art site while the rest of the fleet and one Starlink remain at
camp. The two locations have independently administered 2.4 GHz networks and
the camp owner declined renaming their existing SSID. Requiring one virtual
SSID would either strand one cohort from shared-WiFi OTA or require disruptive
credential changes immediately before installation.

Fixtures use infrastructure WiFi only in deliberate OTA maintenance mode.
Ordinary COMMS remains ESP-NOW-only, so remembering a second maintenance
network does not add an always-associated client or change the mesh channel.

## Decision

1. A production fixture artifact may carry two bounded maintenance credential
   profiles. The first profile remains required; the second is optional, and a
   compile-time error rejects a half-defined SSID/password pair.
2. On maintenance entry, the fixture scans once. Visible known profiles are
   tried in descending RSSI order. If no known profile appears in the scan,
   profiles are tried in declaration order as a fallback for hidden or
   transient scan results.
3. Both profiles share one 30-second association budget. Failure of one profile
   does not reset that budget or create an unbounded awake loop.
4. Logs identify only `profile 1` or `profile 2`; they do not print SSIDs or
   passwords. Real credentials remain in gitignored `wifi_secrets.h`. Recipes
   and immutable manifests record a non-secret configuration label, never
   credential values.
5. Ordinary fixture COMMS does not scan for or join either network. The
   credential plan applies only after the existing exact maintenance command
   deliberately leaves ESP-NOW.
6. ADR 0036 still governs any device using WiFi and ESP-NOW simultaneously.
   Fixture maintenance has already left the mesh, so either maintenance AP may
   use its local channel. A bridge or future uplink that stays on ESP-NOW must
   still use the channel-11 guard.
7. A single shared SSID is no longer required for fixture OTA portability.
   Operators may retain distinct camp and art-site network names and passwords.

## Consequences

- One immutable fleet image can accept OTA at either location without renaming
  an existing camp network.
- If both known APs overlap, the strongest visible one is preferred. This is a
  deterministic heuristic, not seamless roaming; fixtures are stationary and
  maintenance sessions are short.
- A credential change still requires a new immutable artifact or the separate
  bounded provisioning path. No secret is stored in the registry, job ledger,
  or git history.
- A successful rollout over the first profile proves the image and OTA path,
  but does not prove the second AP's password, security mode, DHCP, RF coverage,
  or internet path. That requires an explicit hardware association at the art
  site.

## Validation evidence -- 2026-08-27

The pure credential planner passed ten native checks. A production ESP32-S3
build passed with both local credential pairs defined. Immutable artifact
`fx-260828-658b7d2-p` is 1,208,640 bytes with SHA-256
`95de59286831bcbb9d8f610f84b09e3ac761be558f106b10b9aee8dfb01bd8cc`.
Swablu `F2BE70` passed exact-target OTA, fresh exact-revision mesh rejoin, and
the pending-verify gate. The wider rollout left 98 intended fixtures fully
verified on the same image. Uploads used the already-established maintenance
network; second-site hardware association remains open.

## References

- `firmware/fixture/src/core/wifi_credential_plan.h`
- `firmware/fixture/src/esp32/maintenance.cpp`
- `firmware/fixture/wifi_secrets.h.example`
- `firmware/fixture/tests/test_wifi_credential_plan.cpp`
- `firmware/fixture/README.md`
- ADR 0036
- `docs/howto/CAMP_NETWORK_SETUP.md`

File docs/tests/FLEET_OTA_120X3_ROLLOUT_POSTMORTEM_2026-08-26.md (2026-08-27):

# Fleet OTA 120/3 Rollout Post-mortem -- 2026-08-26

## Outcome

The immutable production fixture artifact `fx-260826-51d1fe1-p` was rolled
out to 85 of the 98 fixtures that were running the prior production artifact
`fx-260826-024e508-p`.

- Source commit: `64264b2c60cbff9a9423642cb6cfee93e4272636`
- Binary size: 1,206,784 bytes
- Binary SHA-256:
  `57306019dbf93a1d0cf950f25b9f557d9a0a68663621a7ce4579aba01dea1261`
- New field cadence: 120 s DAY_CHARGE sleep / 3000 ms timer-wake listen
- Bridge: T-Deck `8EB508`, channel 11, COM152 through the host dashboard
- Final production count: 85 new revision, 13 prior revision
- Special, prototype, recovery, dev-local, and Magic Wand revisions were not
  selected by this rollout.

All 85 promoted fixtures produced a fresh exact-revision mesh heartbeat and
survived the 25 s pending-image verification gate. The 13 remaining production
fixtures were not discovered in maintenance and therefore were not flashed.
They were left on their known-good prior image.

The final deferred IDs were:

```
9F266C  Meowth
9F26B0  Rikku
9F2714  Chunli
F2B7DC  Ponyta
F2BCF4  Gambit
F2BDD4  Gengar
F2BF7C  Rotom
F3FD28  Skitty
F40174  Pacman
F401DC  Zubat
F402A8  (no callsign in dashboard)
F40314  Dixie
F4042C  Cynder
```

Their last recorded VBAT values were 3.101-3.539 V. Most full heartbeats
reported power tier PROTECT. Short heartbeats can leave the dashboard's tier
field blank, so a blank late snapshot is not evidence that a durable PROTECT
latch cleared.

## Artifact and result ledger

The rollout used the same immutable binary for every attempt. Host result
files are:

| Result file | Attempt | Result |
| --- | --- | --- |
| `20260827-004059-fleet-ota-results.jsonl` | Three-fixture stage 1 | 3/3 upload ACK and verified |
| `20260827-010528-fleet-ota-results.jsonl` | First widening batch | 39/40 HTTP ACK; all 40 later proved exact new revision |
| `20260827-011715-fleet-ota-results.jsonl` | Smaller batch | 6/6 ACK; 5 immediately verified |
| `20260827-012126-fleet-ota-results.jsonl` | Isolated `9E5B5C` reconciliation | 1/1 ACK and verified; duplicate upload |
| `20260827-012856-fleet-ota-results.jsonl` | Smaller batch | 3/4 ACK; `9E5AE4` stayed on the old image |
| `20260827-013732-fleet-ota-results.jsonl` | Gathered batch | 5/5 ACK and verified |
| `20260827-014138-fleet-ota-results.jsonl` | Paced batch | 6/6 ACK and verified after `/resume` cleanup |
| `20260827-015127-fleet-ota-results.jsonl` | Paced batch | 15/15 ACK and verified |
| `20260827-020200-fleet-ota-results.jsonl` | Deterministic stragglers | 6/6 ACK and verified |
| `20260827-021127-fleet-ota-results.jsonl` | PROTECT cohort intersection | 1/1 ACK and verified |

The result files record HTTP upload outcomes. Final promotion counts came from
fresh mesh evidence, not by adding HTTP ACKs. `9E5954` is the important
counterexample: its upload request timed out, but it rebooted into the exact
new image and passed the pending-verify gate. Conversely, an upload ACK alone
was never treated as final success.

## Stage-1 evidence

The initial targets were `9F2638` (Lucas), `9F26BC` (Pinsir), and `F4019C`
(Treecko). All three passed power preflight, exact-target maintenance discovery,
upload, exact-revision rejoin, and pending verification.

After the 10-minute software-boot grace, all three stopped heartbeating at
about 600 s uptime. They returned after the expected roughly 120 s timer sleep
with `reset_reason=deepsleep`, low uptime, and the exact new revision. This
proved the new day cadence end to end before widening.

## What went well

1. Artifact identity stayed exact. Every upload named the immutable binary,
   expected revision, source commit, size, and SHA-256.
2. Explicit target lists prevented prototypes, the Magic Wand, Akuma, and
   one-off recovery builds from accidentally taking the fleet image.
3. Partial discovery failed safely. Missing fixtures were reported as deferred
   and were never invented from IP scans.
4. A/B OTA and the 25 s validation rule kept reboot outcomes recoverable.
5. Maintenance HTTP telemetry provided an independent truth source when mesh
   reporting was delayed or absent.
6. The fixture `/resume` endpoint cleanly recovered new-image fixtures that
   were accidentally pulled back into maintenance after reboot.
7. Local power gates remained authoritative. No low-power fixture was forced
   to light or strike as part of OTA.

## What made the rollout laborious

### 1. The T-Deck has one maintenance campaign slot

`meshEnterMaintenance()` stores one `NbTargetCmd`. Every new `U<ID>` replaces
the prior campaign. `fleet_dashboard_ota.py` sends many targets rapidly and
then resends the missing list in the same order. This means the final target
gets the sustained 35 s campaign while earlier targets may get only an
opportunistic packet between serial/UI ticks.

The host tool behaved as though every named target had an independent campaign,
but the bridge implemented only one. The first 80-target widening pass found
40/80 after 420 s. Smaller rapid batches still commonly found only 40-60
percent of their requested fixtures.

### 2. There are two materially different sleep cadences

The prior ordinary field cadence was 300 s sleep / 15 s listen. PROTECT uses
900 s sleep and only an 8 s wake grace. A discovery deadline longer than 300 s
does not solve target scheduling, and a five- or six-minute campaign cannot
cover one complete PROTECT cadence at all.

For `N` targets with one bridge campaign slot, deterministic pacing must obey:

```
N * target_dwell < minimum wake window
campaign duration >= maximum sleep interval + wake margin
```

The seven-target straggler pass used 2 s per target, producing a roughly 14 s
cycle that fit inside the old 15 s ordinary listen window. It found 6/7 across
one ordinary cadence. The same shape was not sufficient for the 8 s PROTECT
window, and its five-minute duration was far below the 900 s PROTECT sleep.

### 3. Fresh does not mean gathered

A dashboard age under 10 s proves only that a heartbeat was recently heard.
The fixture may be at the end of its short wake grace and about to sleep. It
does not prove that a control command was accepted or that the 10-minute
operator hold is active.

The repeated `B600` dark lease raised the observed live count from about 25 to
74 and was useful, but the host had no per-fixture proof of which peers accepted
the lease. A fresh heartbeat and a confirmed awake hold must be distinct states
in future tooling.

### 4. Mesh revision display can lag the maintenance endpoint

After upload, the dashboard sometimes showed an old revision for tens of
seconds before a newer full heartbeat arrived. The apparent rollback count in
the first widening batch fell from six to three to two to one and then zero.
Maintenance HTTP telemetry already reported the exact new image during part of
that disagreement.

The verifier was correct to wait for fresh exact mesh evidence, but operator UI
must show revision evidence age and source. A current short heartbeat must not
make an older cached full-heartbeat revision look current.

### 5. Gather traffic leaked into verification once

A host pacing helper continued issuing `U<ID>` while a six-fixture upload was
rebooting. Three fixtures successfully booted the new image and were then
re-caught by the still-running helper, returning to maintenance and disappearing
from mesh verification. Their HTTP endpoints proved the new revision; explicit
`GET /resume` calls restored comms and all three passed verification.

This was recoverable, but it is exactly the race a production OTA state machine
must make impossible.

### 6. HTTP ACK and actual result are separate evidence

`9E5954` timed out at the uploader but was already running the new image. A
blind retry would have added risk without adding information. The correct
response was to reconcile maintenance telemetry, reset/uptime, exact revision,
and pending verification first.

## Recommended OTA state machine

Future fleet OTA should be one explicit job with these non-overlapping phases:

```
PLAN -> PREFLIGHT -> GATHER -> DISCOVER -> FREEZE -> UPLOAD -> VERIFY -> CLEANUP
```

### PLAN

- Name an immutable artifact revision and SHA-256.
- Resolve an explicit target roster from the registry.
- Exclude protected one-off roles unless separately acknowledged.
- Record the operator, bridge ID, channel, job ID, and start timestamp.

### PREFLIGHT

- Snapshot each target's battery, input, power tier, revision, reset reason,
  uptime, and evidence age.
- Classify expected cadence: ordinary, PROTECT, commission, or unknown.
- Refuse a campaign whose deadline does not span the slowest selected cadence.
- Split low/protected targets into a strong-sun pass rather than mixing them
  into an ordinary batch.

### GATHER

- Submit the complete target roster to the bridge once.
- The bridge, not the laptop, owns target scheduling and repeats exact-target
  maintenance packets for every unresolved ID.
- Retain multiple active targets in a bounded table instead of one slot.
- Expose per-target campaign state and total remaining count.
- Derive dwell/cycle from the shortest target wake window.

### DISCOVER

- Accept only maintenance endpoints whose self-reported fixture ID matches the
  requested ID.
- Record IP, maintenance revision, battery, and discovery timestamp.
- Keep undiscovered targets explicitly deferred.

### FREEZE

- Stop the bridge gather campaign and receive an explicit stopped ACK.
- Wait one command tail before any upload.
- From this point until verification completes, no `U` traffic may be emitted.

### UPLOAD

- Upload the one immutable binary to the frozen endpoint set in parallel.
- Record HTTP result independently from final promotion state.
- On timeout, query endpoint and mesh evidence before retrying.

### VERIFY

- Require a heartbeat newer than the job start.
- Require exact expected revision and a reset transition/job epoch.
- Require survival beyond the 20 s fixture pending-image window (host gate 25 s).
- If a target is found in maintenance on the new image, call `/resume` and
  continue verification instead of uploading again.

### CLEANUP

- Resume any leftover maintenance endpoints.
- Release temporary leases.
- Emit a final roster with `verified`, `deferred`, and `failed` states and
  evidence for each.
- Never summarize a momentary live count as the number of healthy fixtures.

## Concrete implementation work

1. Replace the T-Deck's single `gMaintCampaign` with a bounded multi-target
   campaign table or queue. A host command should add a roster without erasing
   earlier targets.
2. Add a campaign ID and explicit start/stop/status protocol to the T-Deck
   serial bridge. The host must be able to prove FREEZE before upload.
3. Teach `fleet_dashboard_ota.py` to select a gather duration and scheduler
   from ordinary versus PROTECT cadence, and to refuse an insufficient window.
4. Add endpoint reconciliation: after upload timeout or missing mesh rejoin,
   probe the known IP for exact revision and mode before retrying.
5. Add automatic `/resume` cleanup for exact-new fixtures left in maintenance.
6. Preserve separate evidence ages for short heartbeat, full heartbeat fields,
   and firmware revision in the dashboard and verifier.
7. Telemetry should expose compiled `day_sleep_s`, `wake_listen_ms`,
   `protect_sleep_s`, protect wake grace, and age of the last accepted operator
   control. This distinguishes recently heard from positively gathered.
8. Write one append-only job ledger containing every target transition. The
   scattered JSONL upload files remain useful raw evidence, but should not be
   the only way to reconstruct one logical rollout.
9. Make the T-Deck UI report `verified / deferred / protected` instead of only
   a volatile `live / seen` count during maintenance operations.

Source follow-up on 2026-08-26 implemented items 1-8 under ADR 0062, including
the bounded bridge roster, job-scoped status/freeze contract, cadence-derived
host state machine, endpoint reconciliation, `/resume` cleanup, separate
firmware evidence age, and unified job ledger. Embedded compilation passes;
exact T-Deck and fleet hardware validation remain open. The richer on-device
T-Deck OTA result UI in item 9 remains deferred; the laptop ledger is currently
the authoritative verified/deferred/failed surface.

## Follow-up for the 13 deferred fixtures

Do not run the remaining pass late in the day. Use a strong-sun window and
first confirm whether each durable PROTECT latch releases under the compound
voltage/current rule. If any stay protected, run a dedicated roster campaign
for at least one complete 900 s sleep interval plus margin, with a scheduling
cycle shorter than 8 s. Then freeze all maintenance traffic, upload the exact
same immutable artifact, verify each through the pending-image gate, and record
the final 98/98 production result.

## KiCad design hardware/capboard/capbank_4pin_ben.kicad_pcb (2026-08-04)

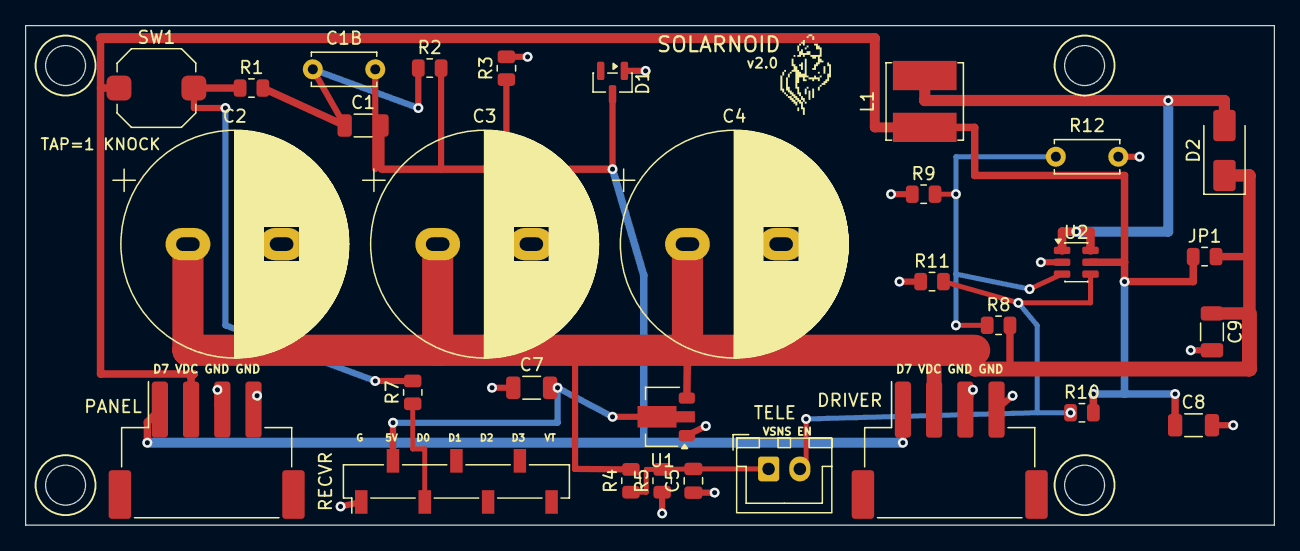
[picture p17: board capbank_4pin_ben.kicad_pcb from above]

Board: 2 copper layers, 100.0 x 40.0 mm, 31 parts (0 on the bottom side), 12 nets.

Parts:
C1, C7: 10uF X7R 16V; C_1206_3216Metric
C1B: DNP; C_Disc_D5.0mm_W2.5mm_P5.00mm
C2, C3, C4: 22000u 16V; CP_Radial_D18.0mm_P7.50mm
C5: 1n; C_0805_2012Metric
C8: 22uF 16V; C_1206_3216Metric
C9: 10uF 25V; C_1206_3216Metric
D1: BZX84C3V3; SOT-23
D2: SS34; D_SMA
DRIVER: XH 4p SMT (pin4=GND); JST_XH_S4B-XH-SM4-TB_1x04-1MP_P2.50mm_Horizontal
JP1: BYPASS DNP; R_0805_2012Metric
L1: 22uH 2.4A; L_Bourns_SRN6045TA
PANEL: XH 4p SMT (pin4=GND); JST_XH_S4B-XH-SM4-TB_1x04-1MP_P2.50mm_Horizontal
R1: 470R; R_0805_2012Metric
R2: 330k; R_0805_2012Metric
R3: 10k; R_0805_2012Metric
R4, R10, R11: 47k; R_0805_2012Metric
R5, R9: 6.8k; R_0805_2012Metric
R7: 1k; R_0805_2012Metric
R8: 130k; R_0805_2012Metric
R12: DNP TRIM; C_Disc_D5.0mm_W2.5mm_P5.00mm
RECVR: RX480E DOCK; PinSocket_1x07_P2.54mm_Vertical_SMD_Pin1Left
SW1: SW_Push_1TS009xxxx-xxxx-xxxx_6x6x5mm
TELE: VSNS/EN; JST_XH_B2B-XH-A_1x02_P2.50mm_Vertical
U1: HT7550-1; SOT-89-3
U2: MT3608; SOT-23-6

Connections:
BTNP: R7.1, RECVR.3
D7: C1.2, C1B.2, D1.3, DRIVER.1, PANEL.1, R2.2, R3.1
EN: R10.1, R11.2, TELE.2, U2.4
FB: R8.1, R9.2, R12.1, U2.3
GND: C2.2, C3.2, C4.2, C5.1, C7.1, C8.2, C9.2, D1.1, DRIVER.3, DRIVER.4, PANEL.3, PANEL.4, R3.2, R5.1, R9.1, R11.1, R12.2, RECVR.1, U1.1, U2.2
NETA: R1.1, R7.2, SW1.2
NETB: C1.1, C1B.1, R1.2, R2.1
P5V: C7.2, RECVR.2, U1.2
SW: D2.2, L1.2, U2.1, U2.6
VBOOST: C2.1, C3.1, C4.1, C9.1, D2.1, DRIVER.2, JP1.2, R4.2, R8.2, U1.3
VDCIN: C8.1, JP1.1, L1.1, PANEL.2, R10.2, SW1.1, U2.5
VSNS: C5.2, R4.1, R5.2, TELE.1

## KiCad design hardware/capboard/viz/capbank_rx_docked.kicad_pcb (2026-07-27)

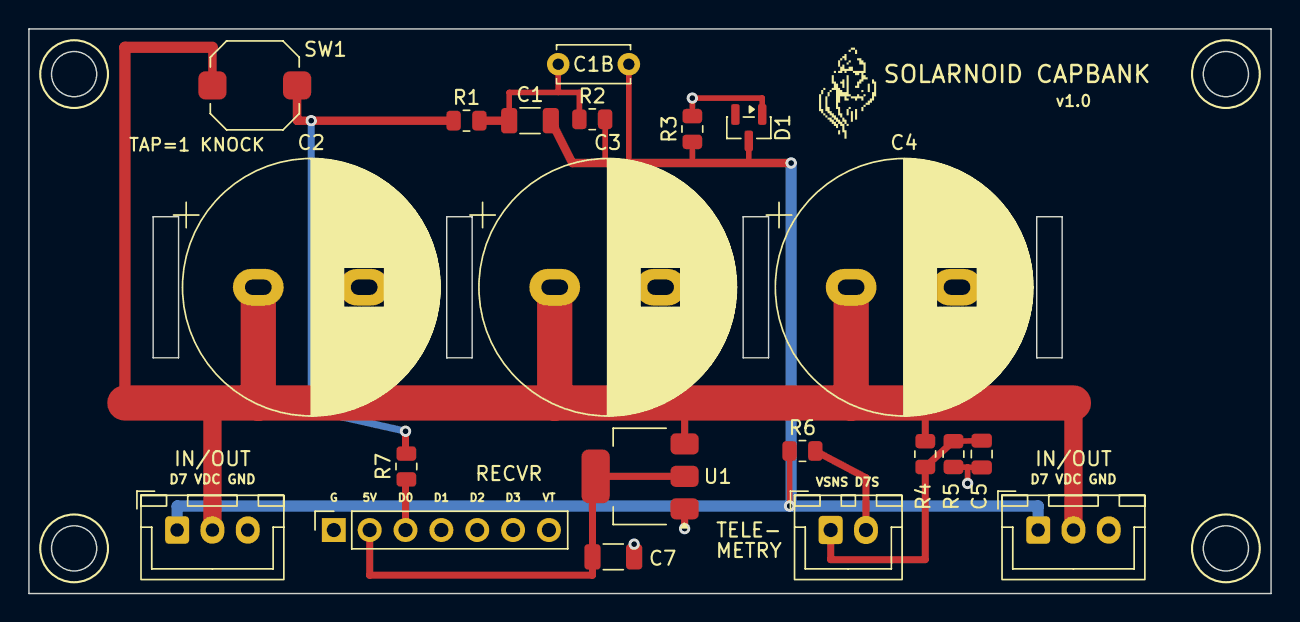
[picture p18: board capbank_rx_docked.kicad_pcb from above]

Board: 2 copper layers, 88.0 x 40.0 mm, 21 parts (0 on the bottom side), 9 nets.

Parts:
C1, C7: 10uF X7R 16V; C_1206_3216Metric
C1B: DNP; C_Disc_D5.0mm_W2.5mm_P5.00mm
C2, C3, C4: 22000u 16V; CP_Radial_D18.0mm_P7.50mm
C5: 100n; C_0805_2012Metric
D1: BZX84C3V3; SOT-23
IN/OUT: JST_XH_B3B-XH-A_1x03_P2.50mm_Vertical
IN/OUT#2: JST_XH_B3B-XH-A_1x03_P2.50mm_Vertical
METRY: SENSE; JST_XH_B2B-XH-A_1x02_P2.50mm_Vertical
R1: 470R; R_0805_2012Metric
R2: 330k; R_0805_2012Metric
R3: 10k; R_0805_2012Metric
R4: 100k; R_0805_2012Metric
R5: 33k; R_0805_2012Metric
R6, R7: 1k; R_0805_2012Metric
RECVR: RX480E DOCK; PinSocket_1x07_P2.54mm_Vertical
SW1: SW_Push_1TS009xxxx-xxxx-xxxx_6x6x5mm
U1: AMS1117-5.0; SOT-223-3_TabPin2

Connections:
BTNP: R7.1, RECVR.3
D7: C1.2, C1B.2, D1.3, IN/OUT.1, IN/OUT#2.1, R2.2, R3.1, R6.1
D7S: METRY.2, R6.2
GND: C2.2, C3.2, C4.2, C5.1, C7.2, D1.1, IN/OUT.3, IN/OUT#2.3, R3.2, R5.1, RECVR.1, U1.1
NETA: R1.1, R7.2, SW1.2
NETB: C1.1, C1B.1, R1.2, R2.1
P5V: C7.1, RECVR.2, U1.2
VDC: C2.1, C3.1, C4.1, IN/OUT.2, IN/OUT#2.2, R4.2, SW1.1, U1.3
VSNS: C5.2, METRY.1, R4.1, R5.2

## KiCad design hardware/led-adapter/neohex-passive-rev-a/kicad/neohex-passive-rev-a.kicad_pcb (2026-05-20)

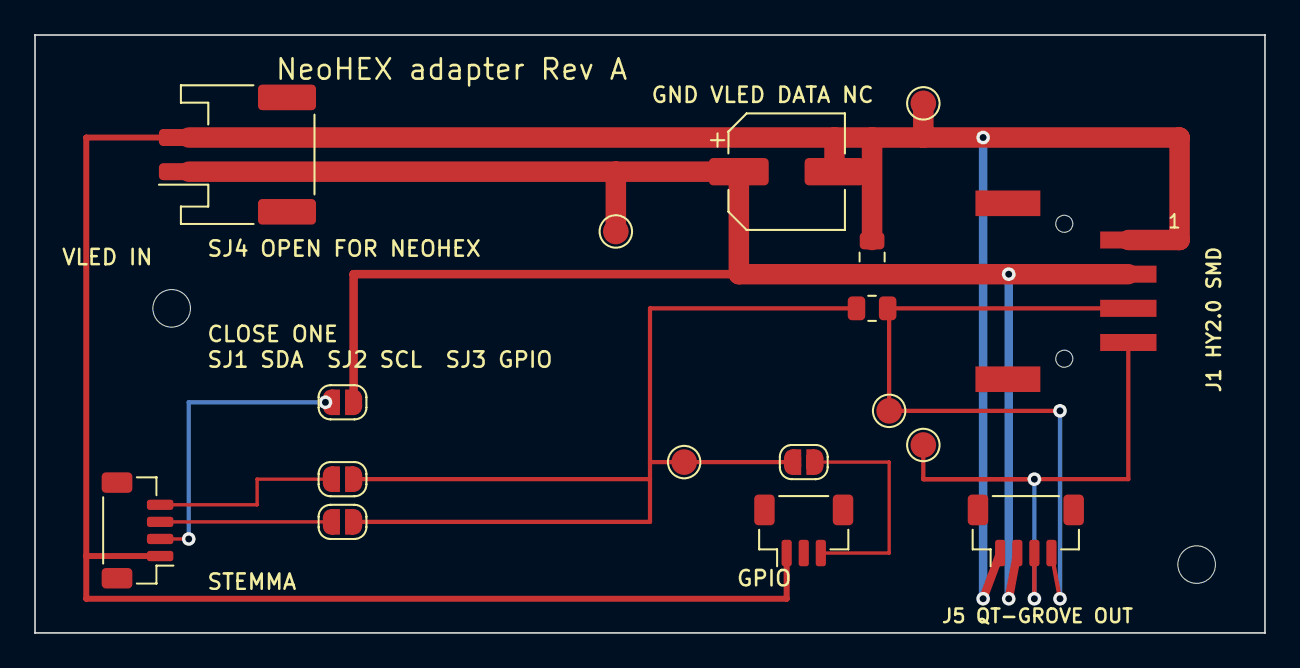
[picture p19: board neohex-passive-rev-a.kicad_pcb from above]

Board: 2 copper layers, 72.0 x 35.0 mm, 19 parts (0 on the bottom side), 9 nets.

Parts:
C1: 0.1uF; C_0805_2012Metric
C2: 100-470uF_DNP; CP_Elec_6.3x5.4
H1, H2: M2; MountingHole_2.2mm_M2
J1: HY2.0_4P_SMD_OUT; M5Stack_HY2.0-4P_SMD_A118
J2: VLED_IN; JST_PH_S2B-PH-SM4-TB_1x02-1MP_P2.00mm_Horizontal
J3: STEMMA_DATA; JST_SH_BM04B-SRSS-TB_1x04-1MP_P1.00mm_Vertical
J4: GPIO_DATA; JST_SH_BM03B-SRSS-TB_1x03-1MP_P1.00mm_Vertical
J5: QT_GROVE_OUT; JST_SH_BM04B-SRSS-TB_1x04-1MP_P1.00mm_Vertical
R1: 330R; R_0805_2012Metric
SJ1, SJ2, SJ3, SJ4: OPEN; SolderJumper-2_P1.3mm_Open_RoundedPad1.0x1.5mm
TP1: VLED; TestPoint_Pad_D1.5mm
TP2: GND; TestPoint_Pad_D1.5mm
TP3: DATA_RAW; TestPoint_Pad_D1.5mm
TP4: DATA_OUT; TestPoint_Pad_D1.5mm
TP5: NC; TestPoint_Pad_D1.5mm

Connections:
DATA_OUT: J1.3, J5.4, R1.2, TP4.1
DATA_RAW: R1.1, SJ1.2, SJ2.2, SJ3.2, TP3.1
GND: C1.2, C2.2, J1.1, J2.2, J3.1, J4.1, J5.1, TP2.1
GPIO_DIN: J4.3, SJ3.1
NC_WHITE: J1.4, J5.3, TP5.1
STEMMA_SCL: J3.4, SJ2.1
STEMMA_SDA: J3.3, SJ1.1
STEMMA_VPLUS: J3.2, SJ4.1
VLED: C1.1, C2.1, J1.2, J2.1, J5.2, SJ4.2, TP1.1

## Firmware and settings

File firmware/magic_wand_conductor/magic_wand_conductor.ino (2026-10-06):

// Resonance Magic Wand Conductor: deliberate lift gesture -> bounded fleet wave.
//
// This is a dedicated image for Steve's F40344 PowerFeather and 20-board
// NeoHex wand. It shares the Atom Conductor's session/graph policy and the
// fleet's one packet contract, UTC selector, and BRC solar schedule.

#include <Arduino.h>
#include <Adafruit_BMP5xx.h>
#include <Adafruit_MSA301.h>
#include <PowerFeather.h>
#include <WiFi.h>
#include <Wire.h>
#include <esp_mac.h>
#include <esp_now.h>
#include <esp_system.h>
#include <esp_wifi.h>
#include <freertos/FreeRTOS.h>
#include <freertos/queue.h>
#include <math.h>
#include <stddef.h>

#include "esp32-hal-rmt.h"
#include "../powerfeather_solar_guard.h"
#include "../fixture/src/core/filters.h"
#include "../fixture/src/core/fixture_context.h"
#include "../fixture/src/core/hex_geometry.h"
#include "../fixture/src/core/packet.h"
#include "../fixture/src/core/show_schedule.h"
#include "../fixture/src/core/time_consensus.h"
#include "../atom_conductor/src/core/action_gate.h"
#include "../atom_conductor/src/core/atom_session.h"
#include "../atom_conductor/src/core/fleet_graph.h"
#include "src/core/wand_gesture.h"
#include "src/core/wand_visual.h"

// Arduino copies sources under src/ to an isolated build tree. Include shared
// implementations at sketch level so this target uses exact canonical code
// rather than maintaining a second packet/session/schedule implementation.
#include "../fixture/src/core/filters.cpp"
#include "../fixture/src/core/hex_geometry.cpp"
#include "../fixture/src/core/show_schedule.cpp"
#include "../fixture/src/core/time_consensus.cpp"
#include "../atom_conductor/src/core/action_gate.cpp"
#include "../atom_conductor/src/core/atom_session.cpp"
#include "../atom_conductor/src/core/fleet_graph.cpp"

using namespace PowerFeather;

#define MAGIC_WAND_CONDUCTOR_VERSION "wand-cond-260903.1"

#ifndef NB_CHANNEL
#define NB_CHANNEL 11
#endif
#ifndef RES_WAND_PULSE_MS
#define RES_WAND_PULSE_MS 40
#endif
#ifndef RES_WAND_TREE_COLOR_VALUE
#define RES_WAND_TREE_COLOR_VALUE 64
#endif
#ifndef RES_WAND_TREE_RGB_VALUE
#define RES_WAND_TREE_RGB_VALUE 21
#endif

#if RES_WAND_PULSE_MS < 5 || RES_WAND_PULSE_MS > 300
#error "RES_WAND_PULSE_MS must be 5..300"
#endif
#if RES_WAND_TREE_COLOR_VALUE < 1 || RES_WAND_TREE_COLOR_VALUE > 255
#error "RES_WAND_TREE_COLOR_VALUE must be 1..255"
#endif
#if RES_WAND_TREE_RGB_VALUE < 1 || RES_WAND_TREE_RGB_VALUE > 85
#error "RES_WAND_TREE_RGB_VALUE must be 1..85"
#endif

static constexpr uint8_t EXPECTED_MAC[6] =
    {0x68, 0xEE, 0x8F, 0xF4, 0x03, 0x44};
static constexpr uint8_t BROADCAST_MAC[6] =
    {0xFF, 0xFF, 0xFF, 0xFF, 0xFF, 0xFF};
static constexpr uint8_t ALL_TARGETS[3] = {0, 0, 0};

static constexpr uint8_t DATA_PIN = 10;
static constexpr uint8_t STATUS_LED_PIN = 46;
static constexpr uint8_t BOARD_COUNT = 20;
static constexpr uint8_t PIXELS_PER_BOARD = 37;
static constexpr uint16_t PIXEL_COUNT = BOARD_COUNT * PIXELS_PER_BOARD;
static constexpr size_t BITS_PER_PIXEL = 24;
static constexpr size_t SYMBOL_COUNT = PIXEL_COUNT * BITS_PER_PIXEL;

static constexpr uint16_t BATTERY_CAPACITY_MAH = 15000;
static constexpr float CHARGE_LIMIT_MA = 500.0f;
static constexpr float SUPPLY_MAINTAIN_V = 4.6f;
static constexpr float BATTERY_PRESENT_MIN_V = 2.0f;
static constexpr float GAUGE_CURRENT_DIVISOR = 1.08f;

static constexpr uint32_t TARGET_FRESH_MS = 12000;
static constexpr uint16_t LOCATE_DURATION_S = 120;
static constexpr uint8_t LOCATE_PERIOD_DS = 200;
static constexpr uint16_t WAVE_LAYER_GAP_MS = 140;
static constexpr uint8_t COMMAND_SEND_COUNT = 6;
static constexpr uint16_t COMMAND_SEND_GAP_MS = 8;
static constexpr uint8_t FRAME_SEND_COUNT = 3;
static constexpr uint16_t FRAME_SEND_GAP_MS = 12;
static constexpr uint8_t RELIABLE_SEND_COUNT = 4;
static constexpr uint16_t RELIABLE_SEND_GAP_MS = 5;
static constexpr uint32_t HEARTBEAT_MS = 5000;
static constexpr size_t RX_QUEUE_DEPTH = 32;
static constexpr size_t RX_DATA_MAX = 250;

struct WandPixel {
  uint8_t red;
  uint8_t green;
  uint8_t blue;
};

struct RxFrame {
  uint16_t len;
  int8_t rssi;
  uint32_t receivedMs;
  uint8_t data[RX_DATA_MAX];
};

static WandPixel pixels[PIXEL_COUNT] = {};
static rmt_data_t symbols[SYMBOL_COUNT] = {};
static bool rmtReady = false;
static uint32_t framesShown = 0;
static uint8_t idleRow = 0;
static uint32_t nextDisplayMs = 0;
static uint32_t displayOverrideUntilMs = 0;
static WandRgb displayOverrideColor = {0, 0, 0};
static bool displayOverrideAll = false;

static bool identityOk = false;
static bool powerFeatherReady = false;
static bool chargingEnabled = false;
static uint32_t nextPowerMs = 0;
static float batteryV = NAN;
static float batteryMa = NAN;
static float supplyV = NAN;
static float supplyMa = NAN;
static bool supplyGood = false;

static Adafruit_MSA311 msa311;
static Adafruit_BMP5xx bmp581;
static bool msaPresent = false;
static bool bmpPresent = false;
static uint32_t nextMsaMs = 0;
static uint32_t nextBmpMs = 0;
static uint32_t lastMsaOkMs = 0;
static uint32_t lastBmpOkMs = 0;
static float filteredPressureHpa = NAN;
static AccelFilter accelFilter;
static WandGesture gesture;
static WandGestureState lastLoggedGesture = WAND_GESTURE_SEEK_STEADY;

static AtomSession session;
static AtomFleet fleet;
static AtomWaveTarget waveTargets[ATOM_FLEET_MAX_PEERS];
static TimeConsensus timeConsensus;
static WandColorMode nightColor = WAND_COLOR_RED;

static QueueHandle_t rxQueue = nullptr;
static uint8_t myId[3] = {};
static uint32_t txSeq = 0;
static bool radioReady = false;
static uint32_t nextHeartbeatMs = 0;
static volatile uint32_t sendOk = 0;
static volatile uint32_t sendFail = 0;
static volatile uint32_t rxDropped = 0;

static void clearPixels() {
  for (WandPixel &pixel : pixels) pixel = {0, 0, 0};
}

static void encodeByte(uint8_t value, size_t &symbolIndex) {
  for (uint8_t mask = 0x80; mask != 0; mask >>= 1) {
    rmt_data_t &symbol = symbols[symbolIndex++];
    symbol.level0 = 1;
    symbol.level1 = 0;
    if (value & mask) {
      symbol.duration0 = 8;
      symbol.duration1 = 4;
    } else {
      symbol.duration0 = 4;
      symbol.duration1 = 8;
    }
  }
}

static bool showPixels() {
  if (!rmtReady) return false;
  size_t symbolIndex = 0;
  for (const WandPixel &pixel : pixels) {
    // M5Stack NeoHex uses WS2812 GRB byte order.
    encodeByte(pixel.green, symbolIndex);
    encodeByte(pixel.red, symbolIndex);
    encodeByte(pixel.blue, symbolIndex);
  }
  bool ok = rmtWrite(DATA_PIN, symbols, SYMBOL_COUNT, RMT_WAIT_FOR_EVER);
  delayMicroseconds(80);
  if (ok) ++framesShown;
  return ok;
}

static void fillPixels(WandRgb color) {
  for (WandPixel &pixel : pixels)
    pixel = {color.red, color.green, color.blue};
}

static void renderIdle() {
  constexpr WandPixel rowColors[4] = {
      {4, 2, 0}, {3, 3, 0}, {0, 6, 0}, {0, 0, 6}};
  constexpr WandPixel red = {6, 0, 0};
  for (uint8_t board = 0; board < BOARD_COUNT; ++board) {
    WandPixel color = board / 5 == idleRow ? red : rowColors[board / 5];
    uint16_t first = board * PIXELS_PER_BOARD;
    for (uint8_t p = 0; p < PIXELS_PER_BOARD; ++p)
      pixels[first + p] = color;
  }
  idleRow = (idleRow + 1) % 4;
  showPixels();
}

static void renderGather(uint32_t nowMs) {
  const HexGeometry &geo = hexGeometry();
  uint32_t elapsedMs = nowMs - session.startedMs;
  uint8_t loaded = wandGatherLoadedPixels(elapsedMs, ATOM_GATHER_MS);
  clearPixels();
  for (uint8_t board = 0; board < BOARD_COUNT; ++board) {
    uint16_t first = board * PIXELS_PER_BOARD;
    for (uint8_t pos = 0; pos < loaded; ++pos) {
      uint8_t local = geo.spiralOrder[pos];
      pixels[first + local] = {0, 1, 3};
    }

    // A bright head circles the frontier ring while the dim center-out spiral
    // records six-minute progress. Every physical Hex therefore visibly loads.
    uint8_t frontier = loaded < PIXELS_PER_BOARD ? loaded : PIXELS_PER_BOARD - 1;
    uint8_t ring = geo.ringOf[geo.spiralOrder[frontier]];
    uint8_t ringSize = geo.ringSize[ring];
    uint8_t head = (uint8_t)((nowMs / 120 + board) % ringSize);
    uint8_t local = geo.ringMembers[ring][head];
    pixels[first + local] = {0, 6, 8};
  }
  showPixels();
}

static void renderChimeReady() {
  const HexGeometry &geo = hexGeometry();
  clearPixels();
  for (uint8_t board = 0; board < BOARD_COUNT; ++board) {
    uint16_t first = board * PIXELS_PER_BOARD;
    for (uint8_t p = 0; p < PIXELS_PER_BOARD; ++p)
      if (geo.ringOf[p] <= 1) pixels[first + p] = {4, 2, 0};
  }
  showPixels();
}

static void renderUnknown() {
  const HexGeometry &geo = hexGeometry();
  clearPixels();
  for (uint8_t board = 0; board < BOARD_COUNT; ++board)
    pixels[board * PIXELS_PER_BOARD + geo.spiralOrder[0]] = {4, 0, 4};
  showPixels();
}

static void renderGestureCue(WandGestureState state) {
  const HexGeometry &geo = hexGeometry();
  clearPixels();
  uint8_t rings = state == WAND_GESTURE_ARMED
                      ? 0
                      : (state == WAND_GESTURE_LIFTING ? 1 : 2);
  for (uint8_t board = 0; board < BOARD_COUNT; ++board) {
    uint16_t first = board * PIXELS_PER_BOARD;
    for (uint8_t p = 0; p < PIXELS_PER_BOARD; ++p)
      if (geo.ringOf[p] <= rings) pixels[first + p] = {0, 4, 6};
  }
  showPixels();
}

static void setDisplayOverride(WandRgb color, uint32_t durationMs,
                               bool allPixels) {
  displayOverrideColor = color;
  displayOverrideUntilMs = millis() + durationMs;
  displayOverrideAll = allPixels;
  nextDisplayMs = 0;
}

static void renderOverride() {
  if (displayOverrideAll) {
    fillPixels(displayOverrideColor);
  } else {
    const HexGeometry &geo = hexGeometry();
    clearPixels();
    for (uint8_t board = 0; board < BOARD_COUNT; ++board)
      for (uint8_t p = 0; p < PIXELS_PER_BOARD; ++p)
        if (geo.ringOf[p] <= 1)
          pixels[board * PIXELS_PER_BOARD + p] =
              {displayOverrideColor.red, displayOverrideColor.green,
               displayOverrideColor.blue};
  }
  showPixels();
}

static void initPowerFeather() {
  Result result = Result::Failure;
  for (int attempt = 0; attempt < 4 && result != Result::Ok; ++attempt) {
    result = Board.init(BATTERY_CAPACITY_MAH,
                        Mainboard::BatteryType::Generic_LFP);
    if (result != Result::Ok) delay(250);
  }
  if (result != Result::Ok) {
    Serial.printf("power init FAILED (%d); charger remains unconfigured\n",
                  (int)result);
    return;
  }

  powerFeatherReady = true;
  Result maintainResult = Board.setSupplyMaintainVoltage(SUPPLY_MAINTAIN_V);
  Result currentResult = Board.setBatteryChargingMaxCurrent(CHARGE_LIMIT_MA);
  Result batteryResult = Board.getBatteryVoltage(batteryV);
  chargingEnabled = batteryResult == Result::Ok &&
                    batteryV >= BATTERY_PRESENT_MIN_V;
  Result chargeResult = Board.enableBatteryCharging(chargingEnabled);
  bool guardOk = pfSolarGuardInit("magic_wand_conductor",
                                  SUPPLY_MAINTAIN_V, chargingEnabled);
  Serial.printf("power LFP=%umAh maintain=%d current=%d batt=%s%.3fV "
                "charger=%s(%d) guard=%s\n",
                (unsigned)BATTERY_CAPACITY_MAH, (int)maintainResult,
                (int)currentResult,
                batteryResult == Result::Ok ? "" : "ERR/", (double)batteryV,
                chargingEnabled ? "on" : "off", (int)chargeResult,
                guardOk ? "ok" : "ERR");
}

static void powerTick() {
  if (!powerFeatherReady || (int32_t)(millis() - nextPowerMs) < 0) return;
  nextPowerMs = millis() + 2000;
  float value = NAN;
  if (Board.getBatteryVoltage(value) == Result::Ok) batteryV = value;
  if (Board.getBatteryCurrent(value) == Result::Ok)
    batteryMa = value / GAUGE_CURRENT_DIVISOR;
  if (Board.getSupplyVoltage(value) == Result::Ok) supplyV = value;
  if (Board.getSupplyCurrent(value) == Result::Ok) supplyMa = value;
  bool good = false;
  if (Board.checkSupplyGood(good) == Result::Ok) supplyGood = good;
  if (isfinite(supplyV) && isfinite(supplyMa))
    pfSolarGuardTick("magic_wand_conductor", supplyV, supplyMa, supplyGood,
                     SUPPLY_MAINTAIN_V, chargingEnabled);
}

static void initSensors() {
  if (!powerFeatherReady) return;
  Board.enableVSQT(true);
  delay(150);
  Wire1.setClock(100000);
  msaPresent = msa311.begin(MSA311_I2CADDR_DEFAULT, &Wire1);
  if (msaPresent) {
    msa311.setRange(MSA301_RANGE_4_G);
    msa311.setDataRate(MSA301_DATARATE_125_HZ);
    msa311.setBandwidth(MSA301_BANDWIDTH_62_5_HZ);
    msa311.setPowerMode(MSA301_NORMALMODE);
  }
  Wire1.setClock(100000);
  bmpPresent = bmp581.begin(BMP5XX_ALTERNATIVE_ADDRESS, &Wire1);
  if (bmpPresent) {
    bmp581.setTemperatureOversampling(BMP5XX_OVERSAMPLING_2X);
    bmp581.setPressureOversampling(BMP5XX_OVERSAMPLING_16X);
    bmp581.setIIRFilterCoeff(BMP5XX_IIR_FILTER_COEFF_3);
    bmp581.setOutputDataRate(BMP5XX_ODR_10_HZ);
    bmp581.setPowerMode(BMP5XX_POWERMODE_NORMAL);
    bmp581.enablePressure(true);
  }
  Wire1.setClock(100000);
  Serial.printf("sensors @100kHz MSA311=%s BMP581=%s\n",
                msaPresent ? "FOUND" : "MISSING",
                bmpPresent ? "FOUND" : "MISSING");
}

static bool sensorTick() {
  uint32_t now = millis();
  bool newMsaSample = false;
  if (msaPresent && (int32_t)(now - nextMsaMs) >= 0) {
    nextMsaMs = now + 40;
    Wire1.setClock(100000);
    msa311.read();
    float ax = msa311.x_g;
    float ay = msa311.y_g;
    float az = msa311.z_g;
    float magnitude = sqrtf(ax * ax + ay * ay + az * az);
    if (isfinite(magnitude) && magnitude > 0.05f) {
      accelFilterSample(accelFilter, ax, ay, az);
      lastMsaOkMs = now;
      newMsaSample = true;
    }
  }

  if (bmpPresent && (int32_t)(now - nextBmpMs) >= 0) {
    nextBmpMs = now + 100;
    Wire1.setClock(100000);
    if (bmp581.performReading() && isfinite(bmp581.pressure) &&
        bmp581.pressure >= 300.0f && bmp581.pressure <= 1200.0f) {
      if (!isfinite(filteredPressureHpa))
        filteredPressureHpa = bmp581.pressure;
      else
        filteredPressureHpa +=
            0.25f * (bmp581.pressure - filteredPressureHpa);
      lastBmpOkMs = now;
    }
    Wire1.setClock(100000);
  }
  return newMsaSample;
}

static void fillHeader(NbHeader *header, uint8_t type) {
  header->ver = NB_PROTO_VER;
  header->type = type;
  memcpy(header->src_id, myId, sizeof(myId));
  header->seq = txSeq++;
  header->uptime_ms = millis();
}

static void onEspNowSend(const esp_now_send_info_t *,
                         esp_now_send_status_t status) {
  if (status == ESP_NOW_SEND_SUCCESS)
    ++sendOk;
  else
    ++sendFail;
}

static void onEspNowRecv(const esp_now_recv_info_t *info, const uint8_t *data,
                         int len) {
  if (!rxQueue || !data || len < (int)sizeof(NbHeader) ||
      len > (int)RX_DATA_MAX)
    return;
  const NbHeader *header = (const NbHeader *)data;
  if (header->ver != NB_PROTO_VER ||
      (header->type != NB_HEARTBEAT &&
       header->type != NB_NEIGHBOR_REPORT &&
       header->type != NB_TIME_QUALITY))
    return;
  RxFrame frame = {};
  frame.len = (uint16_t)len;
  frame.rssi = info && info->rx_ctrl ? info->rx_ctrl->rssi : -127;
  frame.receivedMs = millis();
  memcpy(frame.data, data, len);
  if (xQueueSend(rxQueue, &frame, 0) != pdTRUE) ++rxDropped;
}

static bool setupEspNow() {
  rxQueue = xQueueCreate(RX_QUEUE_DEPTH, sizeof(RxFrame));
  if (!rxQueue) return false;
  WiFi.mode(WIFI_STA);
  WiFi.setSleep(false);
  WiFi.disconnect(false, false);
  if (esp_wifi_set_channel(NB_CHANNEL, WIFI_SECOND_CHAN_NONE) != ESP_OK)
    return false;
  if (esp_now_init() != ESP_OK) return false;
  esp_now_register_recv_cb(onEspNowRecv);
  esp_now_register_send_cb(onEspNowSend);

  esp_now_peer_info_t peer = {};
  memcpy(peer.peer_addr, BROADCAST_MAC, sizeof(BROADCAST_MAC));
  peer.channel = NB_CHANNEL;
  peer.ifidx = WIFI_IF_STA;
  peer.encrypt = false;
  esp_err_t result = esp_now_add_peer(&peer);
  return result == ESP_OK || result == ESP_ERR_ESPNOW_EXIST;
}

static void sendRepeated(const void *packet, size_t len, uint8_t count,
                         uint16_t gapMs) {
  if (!identityOk || !radioReady) return;
  for (uint8_t i = 0; i < count; ++i) {
    if (esp_now_send(BROADCAST_MAC, (const uint8_t *)packet, len) != ESP_OK)
      ++sendFail;
    if (i + 1 < count) delay(gapMs);
  }
}

static void sendLifecycle(uint8_t mode, uint8_t count) {
  NbForceLifecycle packet = {};
  fillHeader(&packet.h, NB_FORCE_LIFECYCLE);
  memcpy(packet.target_id, ALL_TARGETS, sizeof(packet.target_id));
  packet.mode = mode;
  sendRepeated(&packet, sizeof(packet), count, RELIABLE_SEND_GAP_MS);
  Serial.printf("lifecycle %s seq=%lu copies=%u\n",
                mode == 0 ? "wake" : (mode == 2 ? "auto" : "night"),
                (unsigned long)packet.h.seq, (unsigned)count);
}

static void sendLocate(uint16_t durationS) {
  NbLocateControl packet = {};
  fillHeader(&packet.h, NB_LOCATE_CONTROL);
  memcpy(packet.target_id, ALL_TARGETS, sizeof(packet.target_id));
  packet.duration_s = durationS;
  packet.period_ds = durationS ? LOCATE_PERIOD_DS : 0;
  sendRepeated(&packet, sizeof(packet), RELIABLE_SEND_COUNT,
               RELIABLE_SEND_GAP_MS);
}

static void processRxQueue() {
  if (!rxQueue) return;
  RxFrame frame;
  while (xQueueReceive(rxQueue, &frame, 0) == pdTRUE) {
    const NbHeader *header = (const NbHeader *)frame.data;
    if (header->type == NB_TIME_QUALITY) {
      if (frame.len >= sizeof(NbTimeQuality))
        timeConsensusObserve(timeConsensus,
                             *(const NbTimeQuality *)frame.data,
                             header->src_id, frame.receivedMs);
      continue;
    }
    if (header->type == NB_HEARTBEAT) {
      if (frame.len < offsetof(NbHeartbeat, mode) + sizeof(uint8_t)) continue;
      const NbHeartbeat *heartbeat = (const NbHeartbeat *)frame.data;
      bool hasClass = NB_HAS_HB_FIELD(frame.len, fixture_class);
      uint8_t fixtureClass = hasClass ? heartbeat->fixture_class : 0;
      atomFleetObserveHeartbeat(fleet, header->src_id, frame.rssi,
                                frame.receivedMs, hasClass, fixtureClass);
      continue;
    }
    if (header->type == NB_NEIGHBOR_REPORT) {
      size_t prefix = offsetof(NbNeighborReport, entries);
      if (frame.len < prefix) continue;
      const NbNeighborReport *report =
          (const NbNeighborReport *)frame.data;
      uint8_t available =
          (uint8_t)((frame.len - prefix) / sizeof(NbNeighborEntry));
      uint8_t count = report->count < available ? report->count : available;
      if (count > NB_NEIGHBOR_REPORT_MAX) count = NB_NEIGHBOR_REPORT_MAX;
      for (uint8_t i = 0; i < count; ++i)
        atomFleetObserveEdge(fleet, header->src_id, report->entries[i].id,
                             report->entries[i].med_dbm);
    }
  }
}

static void sendHeartbeat() {
  NbHeartbeat heartbeat = {};
  fillHeader(&heartbeat.h, NB_HEARTBEAT);
  heartbeat.batt_mv = isfinite(batteryV) ? (int16_t)(batteryV * 1000.0f) : 0;
  heartbeat.batt_ma = isfinite(batteryMa) ? (int16_t)batteryMa : 0;
  heartbeat.soc_pct = 255;
  if (powerFeatherReady) {
    uint8_t soc = 0;
    if (Board.getBatteryCharge(soc) == Result::Ok) heartbeat.soc_pct = soc;
  }
  heartbeat.reset_reason = (uint8_t)esp_reset_reason();
  heartbeat.mode = (uint8_t)session.phase;
  heartbeat.supply_mv = isfinite(supplyV) ? (int16_t)(supplyV * 1000.0f) : 0;
  heartbeat.supply_ma = isfinite(supplyMa) ? (int16_t)supplyMa : 0;
  heartbeat.supply_good = supplyGood ? 1 : 0;
  heartbeat.lux_x10 = 0xFFFFFFFFUL;
  heartbeat.ptemp_cx10 = INT16_MIN;
  heartbeat.prh_pct = 255;
  heartbeat.btemp_cx10 = INT16_MIN;
  heartbeat.ina_pv_mv = heartbeat.ina_pa_ma = INT16_MIN;
  heartbeat.ina_bv_mv = heartbeat.ina_ba_ma = INT16_MIN;
  heartbeat.cfg_cap_mah = BATTERY_CAPACITY_MAH;
  heartbeat.cfg_charge_ma = (uint16_t)CHARGE_LIMIT_MA;
  heartbeat.bq_vindpm_mv = heartbeat.bq_ichg_ma = 0xFFFF;
  heartbeat.bq_vreg_mv = 0xFFFF;
  heartbeat.bq_reg16 = heartbeat.bq_reg18 = 0xFF;
  heartbeat.bq_stat0 = heartbeat.bq_stat1 = 0xFF;
  heartbeat.bq_fault0 = heartbeat.bq_flag0 = 0xFF;
  heartbeat.bq_flag1 = heartbeat.bq_fault_flag0 = 0xFF;
  heartbeat.bq_part = 0xFF;
  strncpy(heartbeat.fw_rev, MAGIC_WAND_CONDUCTOR_VERSION,
          sizeof(heartbeat.fw_rev) - 1);
  // Stop before fixture_class: the external LED rail/switch has no feedback
  // into the PowerFeather, so this image refuses to publish invented LED truth.
  sendRepeated(&heartbeat, offsetof(NbHeartbeat, fixture_class), 1, 0);
}

static void sendStrike(const uint8_t target[3]) {
  NbTargetU16 packet = {};
  fillHeader(&packet.h, NB_TARGET_SOLENOID);
  memcpy(packet.target_id, target, sizeof(packet.target_id));
  packet.value = RES_WAND_PULSE_MS;
  sendRepeated(&packet, sizeof(packet), COMMAND_SEND_COUNT,
               COMMAND_SEND_GAP_MS);
}
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
void loop() {
  if (!identityOk) {
    identityFaultTick();
    delay(2);
    return;
  }

  processRxQueue();
  powerTick();
  if (sensorTick()) gestureTick();
  if (session.phase != ATOM_SESSION_IDLE)
    handleSessionActions(atomSessionTick(session, millis()));
  uint32_t now = millis();
  if (radioReady && (int32_t)(now - nextHeartbeatMs) >= 0) {
    nextHeartbeatMs = now + HEARTBEAT_MS;
    sendHeartbeat();
  }
  displayTick();
  delay(2);
}

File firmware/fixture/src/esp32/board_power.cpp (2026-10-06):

#include "board_power.h"

#include <Arduino.h>
#include <Wire.h>
#include "driver/rtc_io.h"
#include "esp_sleep.h"

#include <PowerFeather.h>
// Resolved via build.sh's -I<repo>/firmware (the sketch tree is copied into
// the build dir, so a relative ../../../ escape cannot reach the shared header).
#include "powerfeather_solar_guard.h"

#include "../core/bq25628e_precharge.h"
#include "../core/deep_recovery.h"
#include "boot_park.h"
#include "identity.h"
#include "loads.h"
#include "nvs_store.h"
#include "solenoid.h"
#include "sleep_audit_io.h"
#include "espnow_link.h"
#include "maintenance.h"
#include "net_peer.h"
#include "ota_verify.h"

using namespace PowerFeather;

#if !defined(POWERFEATHER_BOARD_V2) && !defined(CONFIG_ESP32S3_POWERFEATHER_V2)
#error "Build with -DPOWERFEATHER_BOARD_V2=1 so the SDK uses the V2 MAX17260 fuel gauge (see build.sh)."
#endif

// Chemistry stays build-time (a wrong runtime chemistry against a connected
// cell is a charger-termination hazard); production default is LFP.
#ifndef RES_PF_BATTERY_TYPE
#define RES_PF_BATTERY_TYPE Mainboard::BatteryType::Generic_LFP
#endif

static const char *kTag = "fixture";
static const uint32_t kTransportWakeMagic = 0x54525054UL; // "TRPT"
RTC_DATA_ATTR static uint32_t gTransportWakeMagic = 0;

static bool gPfReady = false;
static bool gTransportWakeDark = false;
static bool gChargingEnabled = false;
static float gMaintainV = 4.6f;
static float gCbV = 0.0f, gCbMa = 0.0f, gCbMaRaw = 0.0f;
static int gCbSoc = -1;
static bool gCbVValid = false, gCbMaValid = false, gCbSocValid = false;
static float gCsV = 0.0f, gCsMa = 0.0f;
static bool gCsGood = false;
static bool gPrechargeWriteOk = false;
static bool gDeepRecoveryChargeActive = false;
static bool gLowVbatRecoveryChargeActive = false;
static uint8_t gLowVbatRecoveryState = LOW_VBAT_RECOVERY_NONE;
static uint16_t gLowVbatRecoveryDetectMv = 0xFFFF;
static BqSnapshot gBq;

// ADR 0051 battery-corroboration state: a plausible voltage alone is not
// proof of a cell (a floating BAT node held up by the powered charger can
// read 2.5-3.05 V). Evidence sources, any one sufficient: recent >=30 mA
// charge/discharge current, a passed SLUAB31A presence test, a recovery-lane
// BQ detection, or battery-only operation.
static uint32_t gCurrentEvidenceMs = 0;    // 0 = never observed
static uint32_t gPresenceRealUntilMs = 0;  // BQ test said REAL, fresh window
static uint32_t gPresenceEmptyUntilMs = 0; // BQ test said EMPTY, veto window
static bool gRecoveryEverDetected = false;
static bool gPresenceCheckWanted = false;
static uint32_t gLastPresenceCheckMs = 0;
#define RES_BATT_CURRENT_EVIDENCE_MA 30.0f
#define RES_BATT_EVIDENCE_FRESH_MS 60000UL
#define RES_BATT_PRESENCE_REAL_MS 600000UL
#define RES_BATT_PRESENCE_EMPTY_MS 60000UL

bool pfIsReady() { return gPfReady; }
bool chargingEnabled() { return gChargingEnabled; }
static bool presenceEmptyFresh() {
  if (!gPresenceEmptyUntilMs) return false;
  if ((int32_t)(gPresenceEmptyUntilMs - millis()) > 0) return true;
  gPresenceEmptyUntilMs = 0; // expired: zero it so it can never go stale-fresh
  return false;
}

bool batteryPresent() {
  // A fresh EMPTY verdict vetoes the plausible-voltage window; real current
  // (a cell installed mid-session) clears it early and it expires on its own,
  // so an installed cell is never locked out.
  if (presenceEmptyFresh()) return false;
  return (gCbV > 2.5f && gCbV < 4.4f) || gLowVbatRecoveryChargeActive;
}
bool lowVbatRecoveryActive() { return gLowVbatRecoveryChargeActive; }
void batteryRequestPresenceCheck() { gPresenceCheckWanted = true; }
bool batteryCorroborated() {
  uint32_t now = millis();
  if (gCurrentEvidenceMs && now - gCurrentEvidenceMs < RES_BATT_EVIDENCE_FRESH_MS)
    return true;
  if (gPresenceRealUntilMs) {
    if ((int32_t)(gPresenceRealUntilMs - now) > 0) return true;
    gPresenceRealUntilMs = 0; // expired: zero it (stale-fresh after ~25 d wrap)
  }
  if (gRecoveryEverDetected) return true;
  // Audit fix: there is deliberately NO battery-only voltage clause. True
  // battery-only operation always shows >=80 mA discharge and corroborates
  // via current evidence within a second; a voltage-only clause certified a
  // floating node whenever the supply-good flag flickered at dusk/dawn.
  return false;
}
float maintainVolts() { return gMaintainV; }
float batteryVolts() { return gCbV; }
float batteryMa() { return gCbMa; }
float batteryMaRaw() { return gCbMaRaw; }
int batterySocPct() { return gCbSoc; }
bool batteryCurrentValid() { return gCbMaValid; }
bool powerWakeSampleWindowComplete() {
  // Prefer sleeping immediately after the corrected full heartbeat. Fail open
  // after 15 s so an absent/faulted gauge cannot strand a field fixture awake.
  return gCbMaValid || millis() >= RES_POWER_WAKE_FAILOPEN_MS;
}
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

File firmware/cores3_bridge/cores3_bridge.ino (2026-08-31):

// Resonance CoreS3 desk bridge.
//
// Dedicated ESP-NOW <-> USB bridge for the production fixture fleet. This is
// intentionally separate from net_bench: the CoreS3 has no PowerFeather power
// stack, and M5Unified must initialize its AXP2101 before the display/power path
// is treated as ready.

#include <Arduino.h>
#include <WiFi.h>
#include <esp_mac.h>
#include <esp_now.h>
#include <esp_system.h>
#include <esp_task_wdt.h>
#include <esp_wifi.h>
#include <stdarg.h>
#include <string.h>

#ifndef CORES3_CAMBIUM_MODE
#define CORES3_CAMBIUM_MODE 0
#endif

#ifndef CORES3_AUDIO_REACTIVE_MODE
#if CORES3_CAMBIUM_MODE
#define CORES3_AUDIO_REACTIVE_MODE 0
#else
// The ordinary CoreS3 image is now a two-app, untethered Bridge OS. Audio is
// compiled in beside Listener instead of requiring a separate reflash.
#define CORES3_AUDIO_REACTIVE_MODE 1
#endif
#endif

#ifndef CORES3_AUDIO_MODULE
#define CORES3_AUDIO_MODULE 0
#endif

#if CORES3_CAMBIUM_MODE && CORES3_AUDIO_REACTIVE_MODE
#error "Cambium binary modem and audio-reactive modes are separate builds"
#endif

#if CORES3_AUDIO_MODULE && !CORES3_AUDIO_REACTIVE_MODE
#error "CORES3_AUDIO_MODULE requires CORES3_AUDIO_REACTIVE_MODE"
#endif

#if CORES3_AUDIO_MODULE
// Module Audio already includes M5Unified. Do not include the same M5GFX graph
// first through a differently spelled Windows path: GCC can then miss
// `#pragma once` identity and report hundreds of duplicate graphics types.
#include <M5Module_Audio.h>
#else
#include <M5Unified.h>
#endif

#include "../fixture/src/core/fixture_context.h"
#include "../fixture/src/core/packet.h"
#include "app_model.h"
#include "audio_reactive.h"
#include "cobs.h"

#define CORES3_BRIDGE_VERSION "cores3-os-0.2.1-dev"

#define CORES3_CAMBIUM_FW "cores3-cb-0.1"

#ifndef NB_CHANNEL
#define NB_CHANNEL 11
#endif

#ifndef NB_MAX_TRACKED
#define NB_MAX_TRACKED 192
#endif

#ifndef NB_BRIDGE_HZ
#define NB_BRIDGE_HZ 1
#endif

#ifndef NB_WDT_S
#define NB_WDT_S 8
#endif

#define NB_MAINTAIN_MIN_V10 46
#define NB_MAINTAIN_MAX_V10 168
#define NB_CAPACITY_MIN_MAH 100
#define NB_CAPACITY_MAX_MAH 30000
#define NB_CHARGE_MIN_MA 40
#define NB_CHARGE_MAX_MA 2000
#define NB_SOLENOID_MIN_MS 5
#define NB_SOLENOID_MAX_MS 300
#define NB_SOLENOID_DEFAULT_MS 40
#define NB_REMOTE_SLEEP_S 21600
#define NB_TARGET_SLEEP_DEFAULT_S 3600
#define NB_DRAWDOWN_DEFAULT_MAH 3500
#define NB_DARK_LEASE_DEFAULT_S 3600
#define NB_PROGRAM_COMMISSION_DARK 4
#define NB_TRANSPORT_MAX_HOURS 168
#define NB_LOCATE_MAX_S 900
#define NB_LOCATE_PERIOD_DS 200

static const uint8_t BCAST[6] = {0xFF, 0xFF, 0xFF, 0xFF, 0xFF, 0xFF};

uint8_t myMac[6] = {};
uint8_t myId[3] = {};
volatile uint32_t sendOk = 0;
volatile uint32_t sendFail = 0;
uint32_t txSeq = 0;
uint8_t gRateHz = 10;
bool radioReady = false;
M5Canvas displayCanvas(&M5.Display);
bool displayCanvasReady = false;
#if CORES3_AUDIO_REACTIVE_MODE
M5Canvas audioPlotCanvas(&M5.Display);
bool audioPlotCanvasReady = false;
#endif
void drawDisplay();
#if !CORES3_CAMBIUM_MODE
CoreS3App currentApp = CORES3_APP_HOME;
size_t listenerPage = 0;
int listenerDetailPeer = -1;
void openCoreS3App(CoreS3App app);
#endif

struct RxItem {
  uint8_t mac[6];
  int8_t rssi;
  uint8_t len;
  uint8_t data[250];
};

static_assert(sizeof(NbHeartbeat) <= sizeof(RxItem::data),
              "heartbeat outgrew the CoreS3 bridge receive buffer");

QueueHandle_t rxQueue = nullptr;
volatile uint32_t rxQueueDrops = 0;
struct PeerStat;

#if CORES3_CAMBIUM_MODE
// Cambium serial contract: COBS([frame type][payload][CRC16 LE]) + 0x00.
// This mode deliberately emits no bare serial text; all diagnostics travel in
// LOG frames so a dashboard message cannot corrupt the binary stream.
static const uint8_t FTYPE_RADIO_TX = 0x01;
static const uint8_t FTYPE_RADIO_RX = 0x02;
static const uint8_t FTYPE_CTRL = 0x03;
static const uint8_t FTYPE_STATUS = 0x04;
static const uint8_t FTYPE_LOG = 0x05;
static const uint8_t CTRL_STATUS_REQ = 0x01;
static const uint8_t CTRL_SET_CHANNEL = 0x02;
static const uint8_t CTRL_REBOOT = 0x03;
static const size_t ESPNOW_MAX = 250;
static const size_t RX_PAYLOAD_MAX = 6 + 1 + ESPNOW_MAX;
static const size_t BODY_MAX = 1 + RX_PAYLOAD_MAX + 2;

static volatile uint32_t cambiumRxPkts = 0;
static uint16_t cambiumCrcErr = 0;
static uint8_t cambiumChannel = NB_CHANNEL;

struct __attribute__((packed)) CambiumBridgeStatus {
  uint8_t proto;
  uint8_t mac[6];
  uint8_t channel;
  uint32_t uptime_ms;
  uint32_t tx_ok;
  uint32_t tx_fail;
  uint32_t rx_pkts;
  uint32_t rx_drop;
  uint16_t crc_err;
  char fw[16];
};
static_assert(sizeof(CambiumBridgeStatus) == 46,
              "Cambium STATUS layout drifted from framing.py");

static void sendCambiumFrame(uint8_t ftype, const uint8_t *payload, size_t len) {
  uint8_t body[BODY_MAX];
  uint8_t encoded[COBS_ENCODE_MAX(BODY_MAX)];
  if (len > BODY_MAX - 3) return;
  body[0] = ftype;
  memcpy(body + 1, payload, len);
  uint16_t crc = crc16_ccitt(body, len + 1);
  body[len + 1] = (uint8_t)(crc & 0xFF);
  body[len + 2] = (uint8_t)(crc >> 8);
  size_t encodedLen = cobs_encode(body, len + 3, encoded);
  Serial.write(encoded, encodedLen);
  Serial.write((uint8_t)0x00);
}

static void cambiumLogf(const char *fmt, ...) {
  char buffer[200];
  va_list args;
  va_start(args, fmt);
  int len = vsnprintf(buffer, sizeof(buffer), fmt, args);
  va_end(args);
  if (len < 0) return;
  if (len > (int)sizeof(buffer) - 1) len = sizeof(buffer) - 1;
  sendCambiumFrame(FTYPE_LOG, (const uint8_t *)buffer, (size_t)len);
}
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

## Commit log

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2026-06-02 Add PowerFeather V2 power-bench firmware + WiFi telemetry logger
    Arduino harness to measure power envelope across battery / LED / solar axes
    on the PowerFeather V2, to inform the ~100-unit procurement decision.
    - firmware/power_bench/: forked from smoke_test; adds PowerFeather-SDK 2.1.0
    telemetry (battery + supply V/I, SOC/health/cycles via MAX17260) and a JSON
    /telemetry endpoint. LED options (IS31 / NeoHEX / single RGBW) and battery
    chemistry/capacity/charge are build flags. build.sh always sets
    POWERFEATHER_BOARD_V2 (required for the V2 gauge; #error guard enforces it).
    - ops/bench/power_logger.py: polls /telemetry over WiFi into site-partitioned
    JSONL (ca/tn) for conflict-free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
    [power_bench.ino]
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2026-06-02 Add wireless (OTA) flashing to power-bench build.sh
    build.sh --ota <ip> compiles and POSTs the binary to the firmware's web
    /update endpoint over WiFi, so deployed/outdoor harnesses can be updated
    without bringing them back to USB. --port (USB) stays as the recovery path.
    Verified end-to-end on board 9E5AB8 (reboots into the new firmware, rejoins
    WiFi, telemetry resumes).
    [power_bench.ino]
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2026-06-03 power_bench: add load/stress test tooling for brownout characterization
    New build.sh flags for investigating battery power-integrity on the PowerFeather V2:
    - --loadgen: WiFi load generator (no HTTP server) emitting a UDP heartbeat with
    phase + uptime + battery voltage for remote outage/reset detection. Auto-sweeps
    {light/heavy WiFi} x {LED off / full grid}; phase persisted in NVS so a phase
    that reboots the board is skipped, not retried.
    - --batt-stress / --batt-stress-full: radio OFF, LED-panel heartbeat (center or
    full grid) for radio-off baselines.
    - --wifi-lowpower (modem sleep + 8.5 dBm TX), --charge-ma, --ota (wireless flash).
    Tooling only; no conclusions about brownout cause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
    [power_bench.ino]
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2026-06-04 Brownout investigation: isolate cause (IS31-on-bus + WiFi), write up findings
    Controlled runs on a solid soldered LFP connection isolated the on-battery VSYS
    power-on reset: it needs BOTH WiFi active AND the IS31 LED module physically on the
    STEMMA/I2C bus (load-stacking) -- neither alone resets it; heavy WiFi with the module
    unplugged is stable. reset_reason=poweron at healthy bv rules out depletion/connector/
    chemistry; modem sleep didn't fix it. Firmware VSQT power-shed (enableVSQT(false))
    did NOT fix it (still ~21 resets/7min) -- only physically unplugging the module stops
    it; candidate mechanism is I2C back-powering (unproven). Production guidance firming:
    VSYS bulk cap (mechanism-indep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
    [power_bench.ino]
2026-06-05 Bench: LED axis resolved + brownout root-caused + recoverable auto-sleep guard
    PowerFeather V2 lighting bench work (2026-06-04). Full narrative in nine dated
    LOG.md entries; punch list cleaned in TODO.md.
    Findings:
    - Battery brownout root-caused: the IS31FL3741 chip on the V2's SHARED charger/
    gauge I2C bus + WiFi collapses VSYS on battery. IS31-specific (NeoDriver on the
    same bus is stable). Fix: keep LEDs OFF that bus -> drive WS2812/SK6812 direct
    from a free GPIO. IS31 13x9 ruled out for the battery build.
    - LED efficiency map (Apogee PAR vs battery_ma): SK6812 "HEX" ~1.6x more PAR/mA
    than WS2812C NeoHEX; direct-GPIO ~10% better than via NeoDriver (no passthrough
    drop); 4W RGBW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
    [power_bench.ino]
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2026-06-07 firmware: merge studios into led_studio (HEX + RGBW + RGB); Split-as-toggle
    - Merge hex_studio + rgbw_studio into led_studio with a UI mode toggle that
    hot-swaps three LED options on the same A0/GPIO10 pin at runtime
    (updateType/updateLength): HEX 37px grid, RGBW point, and a new RGB point
    (high-power RGB, no white die). Remove the two superseded single sketches.
    - Split-RGB is now a toggle modifier instead of its own animation, so the
    separated R/G/B triad follows the selected path (Static/Spiral/Orbit/Breathe),
    tuned by spread/rotate. Step+ walks the parked triad in Static.
    Validated on hardware (PowerFeather ACM1, GPIO10) across all three modes and the
    split paths. firmware/REA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
    [led_studio.ino]
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2026-06-07 net_bench: first ESP-NOW firmware + 5-node feasibility harness
    De-risks basing ~100 fixtures on PowerFeather V2 (networking/radio/stability).
    Firmware (firmware/net_bench/, forked from power_bench):
    - Broadcast-only ESP-NOW (unencrypted FF:FF -- the 100-node-scalable pattern;
    encrypted peers cap at ~17). master role broadcasts SHOW_FRAME + WiFi-STA-
    bridges per-peer stats to the host over UDP:54321; peer role is pure ESP-NOW
    on battery, broadcasting HEARTBEAT (seq, battery, downlink-PDR). Per-source
    seq-gap PDR.
    - Maintenance-mode switch (ESP-NOW metadata -> peers join AP -> standard WiFi
    OTA) per ADR 0010 -- no firmware bytes over ESP-NOW.
    - Watchdog (esp_task_wdt, net-new) + --w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
    [net_bench.ino]
2026-06-08 net_bench: battery-level onboard LED + OTA verifier fix; first-light results
    - Onboard user LED (GPIO46) now indicates battery SOC on every board so the
    wireless fleet is readable at a glance: >50% solid, 25-50% 1Hz, 10-24% 2Hz,
    <10% 4Hz, no reading = off. Bumped fw to net-bench-2026-06-07.2.
    - net_bench_ota.py: fix false-FAIL on comms-mode peers. They reboot OFF WiFi into
    ESP-NOW, so /telemetry polling can't see them -- the OTA "Update complete.
    Rebooting." ack + software reset IS the success signal. Added --reboot comms;
    confirm peer rejoin via the master bridge (rr=software).
    First-light (ch 11, Li-ion): master + 3 peers, PDR ~99.5% at 10Hz, 0 send-fail.
    OTA-deployed the LED fi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
    [net_bench.ino]
2026-06-08 net_bench: fix /resume to do a real comms transition (re-init ESP-NOW)
    The /resume HTTP endpoint only flipped gMode=COMMS without re-initializing ESP-NOW
    (which enterMaintenance had deinit'd), leaving a peer "in comms" but radio-dead and
    not rejoining the mesh. Now /resume sets a pending flag that loop() handles by
    calling enterComms() (proper WiFi/ESP-NOW transition). v07.3. Deploys on next OTA;
    meanwhile serial 'c' (master) and the maintenance timeout already resume correctly.
    [net_bench.ino]
2026-06-08 net_bench: add on-demand identify/locate (blink ..- to find a board)
    Master can tell a target board (or all) to blink a distinct "..-" pattern on the
    onboard LED for 8s, overriding the battery display -- the data-center chassis-ID
    approach for finding a specific fixture without plugging in. New ESP-NOW NB_IDENTIFY
    command + master serial 'i' (cycle peers, prints the pinged ID) / 'I' (all). v07.4
    (also carries the /resume re-init fix). Deployed to all 5 boards; identify command
    path validated (master sees 4 peers, fires identify).
    [net_bench.ino]
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2026-06-08 net_bench: battery-LED voltage cross-check (no false "critical"); v07.5
    The MAX17260 SOC can read wildly wrong after a DesignCap change / before a learn
    cycle (a full 4.19V cell reported 1% -> false 4Hz "critical" blink). The LED now
    floors the displayed level by a loaded-Li-ion voltage estimate, so a healthy cell
    never shows critical (gauge vs voltage -> healthier wins). Deployed v07.5 to all 5;
    9E5AF0 now shows SOLID despite the gauge still reading 1% (bv 4.19V vetoes).
    Also: TODO to make cap runtime/NVS (avoid per-board OTA bins) and to validate gauge
    SOC over a real cycle (field sleep+solar-charge likely anchors it; bench pinging
    was the pathological case). LFP would need its own voltag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
    [net_bench.ino]
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2026-06-08 power_bench: validate battery-only OTA (field-reset requirement) + budget note
    Battle-tested battery-only OTA per the hard "never touch a deployed lantern"
    requirement: 3 consecutive OTAs to the LFP board on battery-only (no USB), at ~3.2V
    (buck-boost crossover, hardest regime), over WiFi -> 3/3 recovered no-button via
    software reset, new image confirmed running (version bumped to ...ota1). With the ~14
    battery-only peer OTAs earlier, ~17/17 zero failures. The flaky reset is USB-flash
    (JTAG-RTS) only, not OTA. Caveats logged: marginal-link OTA + A/B rollback untested
    (refinements; a failed OTA is safe). TODO to re-derive the nightly budget bottom-up
    from measured LED draw (the ~120mAh/night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
    [power_bench.ino]
2026-06-08 power_bench: validate A/B rollback (bad image auto-reverts) + gated test fixture
    Tested A/B rollback with a bad image (battery-only LFP): a build whose self-test
    hook returns unhealthy (extern "C" verifyOta()=false, gated by -DRES_OTA_FAIL_SELFTEST)
    boots PENDING_VERIFY -> core calls verifyOta()->false -> mark_app_invalid_rollback_
    and_reboot -> bootloader reverts to the last-good image automatically, no touch
    (came back on ota1; bad image never reached setup). PASS.
    Gotcha: the verifyOta() weak hook is C-linkage -- a C++ override silently doesn't
    take and the bad image sticks; needs extern "C". (First attempt hit this.)
    Limitation: this catches self-test FAILURE only; an image that passes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
    [power_bench.ino]
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2026-06-08 net_bench: sleep-cycle + fleet wake-for-maintenance + runtime VINDPM (sizing session)
    Firmware net-bench-2026-06-08.9 (all validated on hardware via OTA):
    - --sleep-cycle: deep-sleep duty cycle (wake -> telemetry HB -> brief maint-listen ->
    deep-sleep). rr=deepsleep, ~32s cycle. Lean wake (skip the USB-CDC settle delay on
    deep-sleep wakes).
    - 'U' sustained ENTER_MAINT (~35s): no-touch OTA-recovery of a SLEEPING board -- the
    normal 'u' burst misses a board awake only ~400ms/30s. The fleet wake-for-maintenance
    primitive; validated (a deep-sleeping peer caught it and joined WiFi for OTA).
    - 'm' / SET_MAINTAIN: runtime VINDPM/charger-maintain over ESP-NOW, no reflash -- the
    panel MPP-s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
    [net_bench.ino]
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2026-06-10 fix: SEN0291 shunt 0.1->0.01 ohm (INA read 10x low); power_bench /set + batt guard; INA<->gauge sweep
    - ina_monitor: INA_RSHUNT_OHMS 0.1->0.01 (DFRobot SEN0291 = 10 mohm); prior INA data x10.
    Resolves the 36 mA wattmeter vs 400 mA gauge discrepancy -- same current, 10x apart.
    - power_bench: add /set (arbitrary RGBW+gamma+brightness) + battery-floor guard.
    - ops/bench: afk_sweep.py (LED power + INA<->fuel-gauge cross-check), afk_analyze.py,
    reconcile_ina_pf.py; plot_led_ina_sweep.py gains shunt-scale; x10-corrected old plots.
    - data: 2026-06-10 AFK sweep (814 pts) + plots; LOG write-up (capacity left UNVERIFIED).
    [ina_monitor.ino, power_bench.ino]
2026-06-10 feat(power_bench): recoverable timer-wake deep-sleep battery guard + charge recovery
    - batteryGuard now enters a recoverable deep sleep on a sustained sub-floor battery
    (sheds both 3V3 rails, timer-wake RES_PROTECT_WAKE_S=900s) instead of just cutting
    WiFi+idling -- truly stops the drain, never strands the cell.
    - protectResleepIfNeeded(): on a timer-wake still on battery+low, re-sleep immediately
    (no WiFi spin-up); on USB, run + charge. Follows POWERFEATHER_NOTES sleep rules.
    - sustained window 8s->12s to avoid LED-load sag false-trips.
    - intended build re-enables charging (--charge-ma 500) so USB recovery recharges the cell.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
    [power_bench.ino]
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2026-06-11 feat(mpp): fully-wireless MPP-sweep harness + buck-boost show-load finding
    The next bench test (gates battery/panel sizing + the MPPT decision): a clean
    full-sun VINDPM sweep with drift anchors, now with zero outdoor tether.
    - net_bench fw 2026-06-10.1: master 'm<v10>' explicit SET_MAINTAIN setpoint;
    peer auto-probes TSL2591 (lux) + SHT31 (panel-back temp) on STEMMA and
    appends lux/ch0/ch1/ptc/prh/btc to the heartbeat (append-only tail 2,
    NB_PROTO_VER unchanged). Battery NTC is opt-in (--batt-ntc): enabling the
    charger TS pin with no thermistor can suspend charging (JEITA on a floating
    pin) -- gotcha in POWERFEATHER_NOTES.
    - ops/bench/mpp_sweep.py: guided sweep (anchor re-visits,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
    [net_bench.ino]
2026-06-11 feat(bench): loose-ends night -- RGB-3W parity, STEMMA cable verdict, HEX ground truth + guarded instability ramp
    - RGB-3W tops out at 256.5 mA full r=g=b vs the 4W RGBW's 257.3 mA at the
    same sagged rail: the rating difference is entirely the W channel.
    - Metro STEMMA QT port healthy; STEMMA(GND,VCC,SDA,SCL) vs Gravity PH2.0
    (VCC,GND,SCL,SDA) are pairwise-inverted, so a straight cable lands all 4
    pins wrong (explains the 06-09 dead short). ina_monitor gained 's' scan +
    'r' re-probe serial commands.
    - power_bench /set gained n= (light first n pixels; fw 2026-06-11.1) and
    ops/bench/hex_ramp.py ramps count/value with abort guards. HEX single px
    41.8 mA full white (INA); the all-on-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
    [ina_monitor.ino, power_bench.ino]
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2026-06-11 feat(mpp): first fully-wireless MPP sweep -- hot-panel optimum 4.6-4.7V = 3.2x default harvest
    - Peer self-instrumentation (Ben's idea): SEN0291 INAs on the peer's own
    STEMMA bus (0x40 panel lead, 0x45 battery lead; 0x44 = SHT31), heartbeat
    tail 3 (fw 2026-06-11.2), parsed through net_bench_log + mpp_sweep. The
    Metro stays for sleep/reset tests. Boot-time Wire1 scan for wiring checks.
    - Hot session results: 5.5V -> 0.59W vs 4.6V -> 1.73W (BQ) / 1.91W (panel
    INA ground truth); BQ under-reports harvest ~10% (input-stage loss). Knee
    immediately below 4.6; late-session demand-limiting identified as a sweep
    confound. ir-ch1 normalization fallback for full-sun TSL2591 saturation;
    anc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
    [net_bench.ino]
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2026-06-12 fix(led_studio): init the PowerFeather SDK so the charger gets the LFP profile
    led_studio never configured the BQ25628E, so with USB + cell attached the
    charger ran its 4.2V Li-ion default -- an overcharge hazard for LFP (3.65V
    ceiling). Board.init(2000, Generic_LFP) + 500mA charge + SDK rail enable,
    with the manual GPIO4 rail-enable kept as fallback if init fails (with a
    do-not-attach-cell warning). build.sh passes -DPOWERFEATHER_BOARD_V2=1.
    Verified on both gobo-night boards (9E5AF0 @ .33, 9F26F8 @ .35).
    [led_studio.ino]
2026-06-12 feat(led_studio): live battery stats in the UI + standard OTA endpoint
    /state gains pf/bv/ma/soc/sv/sgood (live SDK reads); the UI shows a Battery
    line on the existing 600ms poll -- SOC/voltage/charge-vs-discharge context
    for judging slider-vs-sag brightness during gobo sessions. /update (power_
    bench-pattern OTA) added so studio boards never need a tether again.
    Verified on both boards (.33/.35), cells charging at +512/+413mA under the
    LFP profile.
    [led_studio.ino]
2026-06-12 fix(led_studio): cache battery stats (round-robin reads) -- live SDK reads in /state stalled animations
    Each 600ms UI poll did 5 blocking power-I2C reads (charger ADC one-shots =
    tens of ms) inside handleState, visibly stuttering animations. Now loop()
    refreshes one field per ~800ms round-robin into a cache; /state serves the
    cache instantly. Full stats refresh cadence 4s -- plenty for sag watching.
    Also: stale firmware/led_studio/build/ removed + firmware/*/build/
    gitignored (a Jun 9 leftover binary got OTA'd by mistake before being
    caught -- flash via build.sh --port or fresh --output-dir only).
    [led_studio.ino]
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2026-07-02 ina_monitor: add KB2040 (RP2040) target for the 4.2V boost bench
    Metro moved to noisemaker duty; KB2040 takes over INA monitoring.
    Sketch unchanged (default Wire pins = QT port on both); header now
    documents both targets + the UF2 flash path. Verified live: 2x SEN0291
    at 0x41/0x45 streaming on ttyACM2.
    [ina_monitor.ino]
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2026-07-03 bench: presence bench -- 5 ToF/thermal/radar sensors, mux architecture, 3D views, reboot hunt
    New firmware/presence_bench/ (PowerFeather V2, wireless dashboard at
    presencebench.local): MLX90640 + VL53L5CX (vendored 2-target driver, two ST
    infinite-loop bugs patched) + TMF8821 + XM125 + VL53L1X behind a TCA9548A mux
    (software address relocation abandoned -- reproducible zombie, see VENDORED.md
    and LOG cont. 2). Browser-side baseline/delta/occlusion detection, depth-cloud
    and billboard 3D views with orbit/zoom/wobble, /api/log ring, boot counter +
    reset reason + pre-death voltage breadcrumbs. Host logger
    ops/bench/presence_logger.py, reboot-watch data in data/presence/.
    Battery-only reboot in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
    [presence_bench.ino]
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2026-07-03 bench: reboot hunt -- hardware exonerated, firmware bisect (NVS acquitted, sensor task suspected)
    Loadgen anchor test survived heavy TX on the same board+cell; presence_bench
    convicted by contrast. Bisect flags: --no-breadcrumb / --no-task /
    --task-no-sdk. .26 (task without SDK calls) running overnight.
    [presence_bench.ino]
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2026-07-03 log: reboot hunt CONVICTION -- SDK battery round-robin from core-0 task; charge acquitted
    [presence_bench.ino]
2026-07-03 fix: reboot epidemic ROOT CAUSE -- 400 kHz on the shared power-management bus; 100 kHz now default
    Controlled A/B on the worst board: identical firmware, only the Wire1 clock
    changed -- 400 kHz died in seconds on battery, 100 kHz runs the full 5-sensor
    bench indefinitely (7.3 h + 900 s soaks). Mechanism: corrupted BQ25628E
    transactions under WiFi TX open the battery path (BATFET/HIZ class) ->
    instant poweron; USB immune. POWERFEATHER_NOTES hardened with the rules;
    README bus section rewritten; corrections logged (core-0 attribution was
    inference; XM error-rate evidence retracted -- persists at 100 kHz).
    [presence_bench.ino]
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2026-07-04 bench: .31 -- TMF kilo-iterations range knob; baseline capture dedups by frame + empty-scene semantics
    Bright-ambient fixes from the living-room demo: capture counts distinct
    sensor frames (0.6 Hz sensors vs 3 Hz polls) and reports per-sensor
    coverage; an empty per-sensor capture is now a valid 'empty scene'
    baseline (any later valid return = presence) instead of a permanent
    NO BASE tile.
    [presence_bench.ino]
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2026-07-12 firmware: land solenoid_demo + led_sol_bench (feed A/B, gndprobe, VEML/MSA probes); led_studio RGBW order fix
    - solenoid_demo: 3 V solenoid strike bench (noisemaker candidate B), from the
    2026-07-10 sessions (815 strikes, 0 failsafes).
    - led_sol_bench: RGBW + solenoid on one board; runtime feed A/B (3V3+A0 vs
    VBAT+D13), wire-order switch + /raw slot test, /gndprobe floating-ground
    detector, /lux (VEML7700), /probe_strike (supply sampling + MSA311 impact
    peak). GPIO13/EN0 excluded from the pin allowlist.
    - led_studio: production 4 W RGBW decodes RGBW, not GRBW (slot-tested
    2026-07-11) -- every prior studio session had R/G swapped. MODE_RGB module
    still unverified.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
    [led_sol_bench.ino, led_studio.ino]
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2026-07-26 hardware/capboard: v0.6 polish -- shell-mark silkscreen badges (front+back, bitmap tracer in generator), corrected RX module mount orientation notes, RX470-vs-480E rationale
    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
    [generate_capboard.py]
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2026-07-26 hardware/capboard: JLC-format SMT-only CPL (13 parts; raw pos export broke JLC's parser on duplicate IN/OUT refs + THT rows)
    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
    [capbank_cpl_smt.csv]
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2026-07-27 hardware/capboard: fix silently-ignored tall-cap 3D model swap (was 20mm, now true 35.5mm); add cad/ STEP+DXF+VRML exports for Steve's plate modeling
    fp.Models() hands back copies, so mutating m_Filename in place never applied --
    rebuild the model list instead. Affects 3D/CAD only; gerbers, drill, CPL, BOM
    unchanged and the JLC order is unaffected.
    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
    [capbank-Edge_Cuts.dxf, capbank-v1.0-board-only.step, capbank-v1.0.step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]
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2026-07-27 solar: re-run reference raytrace with corrected 72-position canopy (PLACEMENT_FIX)
    - Applied canopy_setup_phase2_corrected.rb to the study model: 12 artifact
    ids removed (6 trunk strays, 6 stacked duplicates), 6 ring-hole fills
    placed (CL-I29..I32, CL-M27..M28). Model saved.
    - Calibration probe first: 6 unchanged panels re-rayed vs shipped lit —
    ±2 lit-pt mean bias with SOLAR_REF hidden + all other layers visible
    (answers the layer-visibility question: that IS the reference state).
    - Fresh 7x5-fan rays + 128-ray SVF for the 6 fills against the shipped
    84-slot sun table; w derived as svf-interpolated w_ideal x
    (1-shade)(1-orient) — identity validated on shipped panels (sd 0.2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
    [Resonance_Solar_Study.skp]
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2026-07-30 firmware/fixture: production fleet firmware, milestone 1 (parity + behavior skeleton)
    One image for all four fixture classes, extracted from the proven bench
    donors into the layered core/ (native-tested, ~200 checks) + esp32/ shape.
    Protocol v1 kept and extended append-only (types 18-24; hb-short truncation);
    ADR 0023 ladder gains the LEDS_OFF tier + compound PROTECT release; deferred
    OTA rollback verify (extern "C" hooks + t+20s self-test); class-by-probe with
    NVS override; GH excitable-media CA + bridge-show programs behind an expiring
    lease; supply-based lifecycle with bounded night and energy-gated wakefulness
    (dev profile never day-sleeps -- bringup posture, default in this image);
    coop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
    [board_power.cpp]
2026-07-30 fleet: fixture-2026-07-30.1 first hardware contact -- 26/26 commissioned
    USB commission of the full 26-board bench with the production fixture
    image (artifact fleet-ca-fixture-20260730-r1, sha256 70A9F0B5...30EE,
    dev profile, channel 11). All boards passed esptool preflight,
    exact-artifact upload, serial verify (LFP 6000 mAh / 500 mA / 4.6 V,
    bare-board safety), and shared-WiFi /telemetry + /resume -- the fleet's
    first successful WonkyHouse OTA-endpoint verification (ota_verified now
    true; the 07-27 pass could not reach WonkyHouse). Includes first intake
    of fresh PowerFeather 9F2694 (D8:85:AC OUI batch) standing in for
    F2BFA0, which stays on led-studio-2026-07-29.3 for the enclosure test.
    Re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
    [registry.csv]
2026-07-30 led_studio: hex dancing-gobo demo on fresh 9E5AE8 perimeter enclosure
    led-studio-2026-07-30.1 (no sensor-triad -> boots MODE_HEX, GPIO10,
    LFP 6000/500/4.6) flashed over USB to fresh-batch PowerFeather 9E5AE8
    in the TN small perimeter enclosure. Joined WonkyHouse at 10.0.0.60
    (mDNS ledstudio.local), battery present and charging under the 500 mA
    cap, solar guard applied. Demo left running: Orbit on the outer 18-px
    ring, warm amber -- lit-pixel samples verified against the replicated
    hex geometry. VL53L5CX idle under this image (studio has no L5CX
    support); registry row stays status=enumerated so a future fleet
    fixture commission with --pending-only still picks the board up.
    Native fixture test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
    [registry.csv]
2026-07-30 led_studio: --l5cx presence build -- ROYGBIV wash <-> center-white gobo
    led-studio-2026-07-30.2 adds a STUDIO_L5CX variant for the perimeter
    demo enclosure: vendored VL53L5CX ULD (copied from fixture's trimmed
    copy: NB_TARGET_PER_ZONE=2 -- indexed zone*2+target correctly --
    slimmed outputs, anti-hang timeout fixes) polled 4x4 @ 6 Hz from
    loop() in sway_demo's proven idiom. begin() runs only in setup()
    before the web server exists; in-session recovery is the quick
    stop/config/start re-apply, honoring the 2026-07-29 UI-starvation
    lesson (presence_bench's core-0 task quarantine not ported). New HEX
    anim 5 "Presence" boots by default at bri=255/gamma-off: all 37 px
    cycle ROYGBIV until a valid ta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
    [registry.csv]
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
